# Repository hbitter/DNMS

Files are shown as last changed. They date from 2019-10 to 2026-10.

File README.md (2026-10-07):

## [English text below](#dnms-digital-noise-measurement-sensor-english)

## DNMS (Digital Noise Measurement Sensor)

Ein Sensor-Modul zur Schallpegelmessung. Es wird neben dem LAeq-Wert über einem Zeitintervall auch der min. und max. LA-Wert in diesem Zeitintervall festgehalten. Das zentrale Element des DNMS ist ein digitales MEMS-Mikrofon (InvenSense ICS-43434). Ein Mikrocontroller-Board (Teensy3.6 / Teensy4.0) übernimmt die digitalen Daten vom Mikrofon über die I²S Schnittstelle als  24-Bit, 44,1 kHz PCM Daten (ab Firmware Version 2 - zuvor nur 16-Bit).  Die Audiodaten werden über einen digitalen A-Filter bewertet, dann wird der Effektivwert bestimmt und daraus der Schalldruckpegel entsprechend der Mikrofonsensitivität berechnet. Die einzelnen Schalldruckpegelwerte werden zu einem fortlaufenden LAeq-Wert weitergerechnet. Ebenso werden der max. und min. Schalldruckpegel (LAmax, LAmin) aus dem Intervall abgespeichert.

Die Werte werden dann über eine I²C-Schnittstelle an einen abfragenden Mikrocontroller zur Weiterverarbeitung übertragen. Das Abfrage-Intervall kann 1 Sekunde betragen oder auch bis zu 3600 Sekunden.

Eine Version mit der Möglichkeit das Frequenzspektrum zu betrachten ist seit einiger Zeit verfügbar. Terzwerte von 20Hz - 20000Hz können ausgegeben werden. Terzwerte werden z.Zt. nicht von Sensor.Community unterstützt, deshalb gibt es spezielle Versionen der NodeMCU Firmware um Terzwerte auf der lokalen Webseite der NodeMCU auszugeben und an weitere APIs wie z.B. zu einer InfluxDB zu senden.

Mit der Firmware Version 5 für Teensy4.0 werden nun auch Z-Werte (LZeq, LZmin, LZmax sowie Z-Terzwerte) unterstützt.

### Bei der Firma Watterott electronic GmbH kann nun das Mikrofon IM72D128 von Infineon fertig in einem Kunststoffrohr eingegossen im Shop bestellt werden (https://shop.watterott.com/Mikrofon-IM72D128V01-im-127mm-Rundrohr). Das IM72D128 Mikrofon auf einer Platine und mit Anschlusskabel aber nicht  im Kunststoffrohr eingegossen ist ebenfalls verfügbar (https://shop.watterott.com/Mikrofon-IM72D128V01-Platine-mit-Anschlussleitung).
 
## Neuigkeiten

### Oktober 2026

- Neue Teensy4.0 Firmware DNMS_V6.0.x für IM72D128 und ICS-43434 Mikrofone.   
 	+ Komplettes Refactoring der Firmware mit Optimierung der Verwendung von Double (nur noch wenn absolut notwendig), dadurch erfordert die Berechnung der Leq Werte deutlich weniger Ressourcen.
 	+  Fehlerbeseitigung einer Race-Condition zwischen 1. und 2. Messintervall.
 	+  Die Parameterwerte zur Frequenzgangkorrektur sind nicht mehr in der Firmware fest abgespeichert. Es werden für jeden Mikrofontyp 31 Korrekturwerte vom Kommunikationsprozessor an die Teensy Firmware beim Start übertragen, daraus berechnet die Teensy Firmware die Korrekturwerte für den gewählten Mikrofontyp für die FFT Bins.
 	+  Änderung der Filterparameter für die I²C Kommunikation zwischen Teensy und Kommunikationsprozessor, dadurch stabilere I²C Übertragung. Beim Kompilieren der Firmware ist es deshalb notwendig die angepasste teensy4_i2c-master Library zu benutzen (zu finden unter Firmware/Teensy/Teensy4.0/).

 	<mark>Achtung: Um diese Firmware zu nutzen, ist die Firmware Version airrohr-DNMS-6.0.0 (oder höher) beim NodeMCU Kommunikationsprozessor oder beim Raspberry Pi  die Version dnms-0.9.27 bzw. dnms-0.9.28 (oder höher) notwendig. Nur diese Versionen haben die Parameter zur Frequenzgangkorrektur abgespeichert und übertragen diese Werte beim Start.<mark>
 	
- Neue NodeMCU Firmware AIRROHR-DNMS-6.0, AIRROHR-DNMS-6.0-en, AIRROHR-DNMS-6.0-fr
	+ Unterstützung der Teensy4.0 Firmware DNMS_V6.0.x mit der wesentlichen Änderung, dass die Frequenzgangkorrekturwerte beim Start von der NodeMCU an die Teensy4.0 Firmware übertragen werden. Ist eine ältere Firmware auf dem Tennsy4.0 Board installiert, so wird dies ebenfalls unterstützt d.h. es ist abwärtskompatibel.
	+ Neue Farbe und neues Logo für den lokalen Webserver:
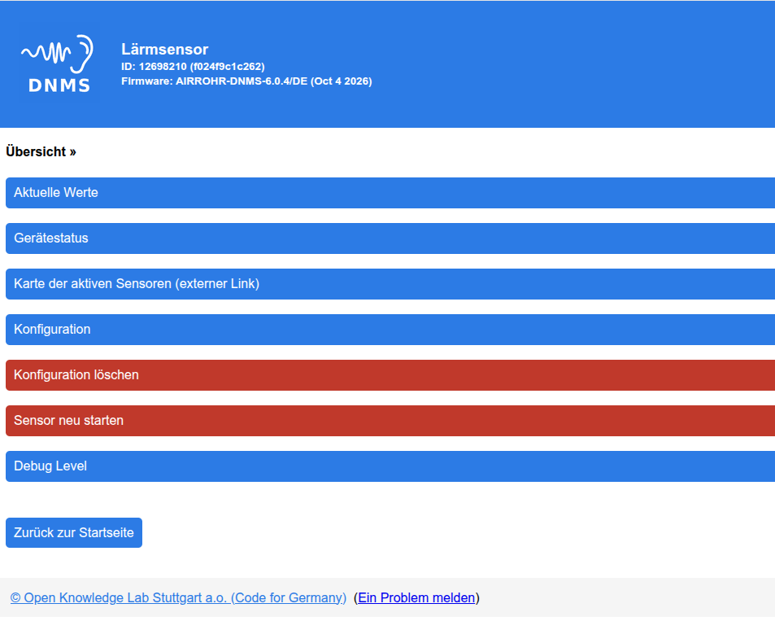
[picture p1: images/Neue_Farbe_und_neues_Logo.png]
	 
	+ Verbessertes Handling der Datenübertragung zu Sensor.Community und zu MQTT-Brokern um Datenverlust bei der Übertragung weiter zu reduzieren.
	
	+  Möglichkeit die NodeMCU Firmware direkt über den Webbrowser auf einen ESP8266  zu flashen. Dies ist möglich mit allen Webbrowsern, die das Web Serial API unterstützen (Chrome, Edge, Brave, Opera aber nicht Firefox ). Um die Funktion zu benutzen,  den entsprechenden Link aufrufen abhängig von der gewünschten Sprachversion:	
		+ Webflasher Deutsche Firmware: https://hbitter.github.io/DNMS/flash-de.html
		+ Webflasher Englische Firmware: https://hbitter.github.io/DNMS/flash-en.html
		+ Webflasher Französische Firmware: https://hbitter.github.io/DNMS/flash-fr.html

- Raspberry Pi Firmware Versionen dnms-0.9.27 und dnms-0.9.28
	+ Die Version dnms-0.9.28 enthält  im Unterschied zur Version dnms-0.9.27 einen lokalen Webserver, der Sztatus Informationen anzeigt und über den die Konfiguration des Sensors angesehen und geändert werden kann. Weiterhin bietet die Version dnms-0.9.28 ein HTTP API (POST) für die Daten des 1. Messintervalls.
	+ Unterstützung der Teensy4.0 Firmware DNMS_V6.0.x mit der wesentlichen Änderung, dass die Frequenzgangkorrekturwerte beim Start vom Raspberry Pi  an die Teensy4.0 Firmware übertragen werden. Ist eine ältere Firmware auf dem Tennsy4.0 Board installiert, so wird dies ebenfalls unterstützt d.h. es ist abwärtskompatibel.
	+ Lokaler Webserver der Version dnms-0.9.28 mit Farbe und Logo entsprechend der NodeMCU Version.
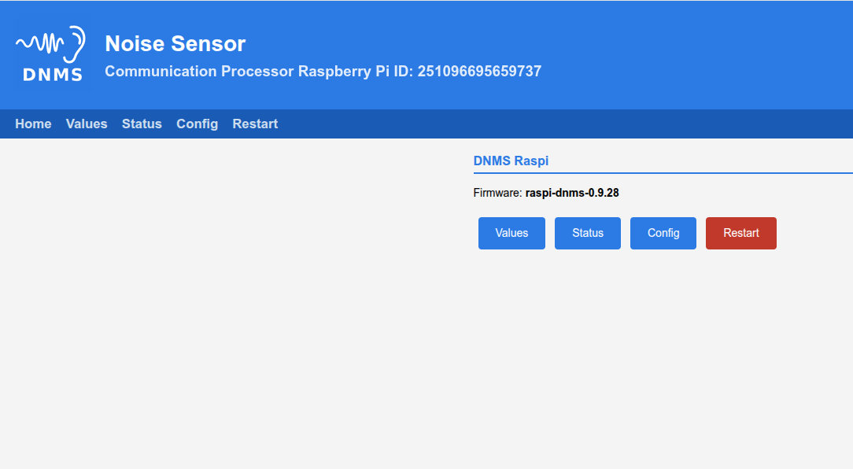
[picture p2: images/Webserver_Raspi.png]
	 

### Mai 2026

- Neues Teensy 4.0 Board DNMS-T4.0-V1.8S mit Layout für SMD Bestückung , so dass nicht nur die Herstellung der Platine beauftragt werden kann sondern direkt die Bestückung bei Firmen wie Aisler, EuroCircuits, JLCPCB oder PCBWay und weiteren. Das Einlöten des Teensy Boards sollte aus Kosten- und Logistikgründen allerdings weiterhin selbst erfolgen. Zwei Bauteilelisten sind als Beispiel für die Bestellung fertig bestückter Boards beigefügt. Dies ist jedoch immer den aktuell lieferbaren Bauelementen anzupassen. Das Layout basiert auf der EasyEDA Vorlage von Ralf Bötticher (vielen Dank!). Weiterhin gibt es zwei Änderungen im Layout:
	+ Verzicht der Brücke J1,  die Brücke war zur Stromversorgung für das standalone Flashen des Boards. Eine Auftrennung der Verbindung VIN - VUSB auf dem Teensy 4.0 Board ist nicht mehr notwendig.
	+ Einfügung einer Sicherung F1 in die 5V Versorgungsleitung der extended I²C Verbindung d.h. zwischen Kommunikationsprozessor und Teensy 4.0 Board.

 - Neue Raspberry Pi Firmware dnms-0.9.25 mit folgenden Verbesserungen:
	+ Möglichkeit C-Werte abzufragen und weiterzugeben, dazu ist die Teensy 4.0 Version DNMS_V5.9.x Voraussetzung. Abhängig von der Menge der übertragenen Daten zwischen Teensy und Raspberry Pi  wird empfohlen die I²C Übertragungsrate von 100 kHz auf 200 kHz zu erhöhen (`dtparam=i2c_arm=on,i2c_arm_baudrate=20000` in der Datei `/boot/firmware/config.txt`).
	+ In der Konfigurationsdatei dnms.conf können nun wieder die Bool Werte mit true und false angegeben werden.

- Neue Teensy 4.0 Firmware DNMS_V5.9.x  für IM72D128 und ICS-43434 Mikrofone mit dem Unterschied zur Version DNMS_V5.8.x, dass zusätzlich C-Werte berechnet und abgerufen werden können. Wenn keine C-Werte benötigt werden, ist die Version  DNMS_V5.8.x weiterhin aktuell. Eine Version mit Abfrage der C-Werte ist die Raspberry Pi Version dnms-0.9.25. Eine Abfrage der C-Werte für die NodeMCU Firmware ist z.Zt. nicht geplant.

- Neue NodeMCU Firmware AIRROHR-DNMS-5.17, AIRROHR-DNMS-5.17-en, AIRROHR-DNMS-5.17-fr
	+ Neue Konfigurationsmöglichkeit für verschiedene Mikrofone und Frequenzgangkorrekturen der Mikrofone. Eine Teensy4.0 Version ab DNMS_V5.8.x ist Voraussetzung um dies zu nutzen.
	+ Konfiguration eines digitalen Eingangs an der der NodeMCU. Der Zustand wird mit der Bezeichnung  DIN01 zur InfluxDB übertragen.
	+ Kleine Korrekturen im Source Code, so dass in der Arduino IDE Version 2.3.8 die Übersetzung ohne Warnungen erfolgt.

- Neue Teensy 4.0 Firmware DNMS_V5.8.x  für IM72D128 und ICS-43434 Mikrofone mit:
	+ zusätzlicher Auswahl der Frequenzgangkorrektur für das DLR Gehäuse mit IM72D128 Mikrofon, sowie Auswahl ohne Frequenzgangkorrektur für IM72D128 und ICS-43434 Mikrofon.
	+ Kleine Korrekturen im Source Code, so dass in der Arduino IDE Version 2.3.8 die Übersetzung ohne Warnungen erfolgt. Dies betrifft auch die Library dnms_audio_lib-master.zip, deshalb beim Übersetzen die veränderte Library einbinden.
	+ Korrekturen an der I²C Übertragung, Änderung der Werte für die Glitch Filter von SDA und SCL im Slave Modus. Diese Korrekturen befinden sich in der Library  teensy4_i2c-master.zip, deshalb beim Übersetzen die veränderte Library einbinden.

### Mai 2025

- Neues Testprogramm für Teensy4.0 Board und angeschlossenem Mikrofon ICS-43434:  DNMS_Vt.8.4 und für Mikrofon IM72D128: DNMS_Vt.8.6, mit verbesserter Frequenzgangkorrektur

- Neue Teensy 4.0 Firmware DNMS_V5.5.x  für IM72D128 und ICS-43434 Mikrofone mit:
	+ Verbesserte Korrektur des Frequenzgangs für IM72D128 Mikrofon und ICS-43434 Mikrofon. Dies verbessert auch die Terzwerte des Spektrums.

 - Neue Raspberry Pi Firmware dnms-0.9.23 ersetzt dnms-0.9.21 aufgrund von Fehlern:
	 + Bei der Umwandlung der MAC-Adresse in die ID
	 + Entfernung Testausgabe der Daten auf Konsole bei Sensor.Community Übertragung
	 + Beseitigung Pufferüberlauf für InfluxDB/MQTT Übertragung, wenn keine Übertragung konfiguriert war

### Oktober 2024

- Neue NodeMCU Firmware AIRROHR-DNMS-5.16 mit:
	+ Neue Konfigurationsmöglichkeit die WLAN Verbindung ohne Passwort auszuwählen aufgrund einer Änderung in der Wifi Lib. Dies ist notwendig  z.B. für Freifunk WLAN Verbindungen.
	+ Verbesserte Fehlerbehandlung bei der Datenübertragung und entsprechende Fehlerausgaben.
	+ Fehlerbeseitigung bei der Übertragung des Zeitstempels zur InfluxDB und zu einem MQTT Broker, wenn der DNMS Sensor nicht konfiguriert ist.

### September 2024

 - Raspberry Pi dnms-0.9.21 ersetzt Version dnms-0.9.20 aufgrund von Fehlern.
 	+ Fehler in der dnms.conf beim Eintrag 'mqtt_transmit'.
 	+ Fehlerhaft gesetzte Prioritäten für die Threads in der dnms.conf ('prio_1st_timer', ... usw).
 	+ Neben der InfluxDB HTTP Übertragung kann nun parallel eine Übertragung der Werte zu einem MQTT Broker erfolgen.
 		
 - Raspberry Pi dnms-0.9.20 Version mit folgenden neuen Funktionen:
	+ Data Logging der Messwerte auf der SD-Karte des Raspberry Pi
	+ Externer Start und Stop der Messwertübertragung, Ausgabe und Speicherung mittels einer named pipe
	+ Änderung der Eingabe von Bool-Werten in der Konfigurationsdatei dnms.conf: Für false eine '0' und für true eine '1' eingeben.

 - Möglichkeit die NodeMCU Firmware direkt über den Webbrowser auf einen ESP8266  zu flashen. Dies ist möglich mit allen Webbrowsern, die das Web Serial API unterstützen (Chrome, Edge, Brave, Opera aber nicht Firefox ). Um die Funktion zu benutzen,  den entsprechenden Link aufrufen abhängig von der gewünschten Sprachversion:
	+ Deutsche Firmware: https://hbitter.github.io/DNMS/flash-de.html
	+ Englische Firmware: https://hbitter.github.io/DNMS/flash-en.html
	+ Französische Firmware: https://hbitter.github.io/DNMS/flash-fr.html

### Juli 2024

- Neue Firmware für Teensy4.0 DNMS_V5.4.x - für ICS-43434 und IM72D128 Mikrofon
	+ Ersetzt DNMS_V5.3.x da in der Version DNMS_V5.3.x Fehler in der Berechnung der Terzwerte waren. DNMS_V5.3.x bitte ersetzen mit DNMS_V5.4.x 
	
- Neue NodeMCU Firmware AIRROHR-DNMS-5.12 mit:
	+ NTP Server können nun in der Konfiguration gesetzt werden unter "Weitere Einstellungen"
	+ Konfigurationsänderung für die Übertragung zum MQTT Broker, eigenes Feld für die Konfiguration der MQTT Messung. Dies wird im InfluxDB Line Protocol als Measurement weitergegeben

 - Raspberry Pi dnms-0.9.18 Fehlerkorrektur und neue Funktion:
	 - Korrektur eines Fehlers: Wenn nur die Ausgabe auf dem Terminal konfiguriert war, wurden die Werte nicht richtig auf dem Terminal ausgegeben.
 	- Neue Möglichkeit der Weitergabe von Messwerten mittels einer named pipe (oder auch fifo) zu anderen Anwendungen auf dem Raspberry Pi.

### Juni 2024

 - Raspberry Pi dnms-0.9.16 Korrektur der Versionsnummer:
	 - Die Versionsnummer wurde falsch (0.9.15 statt 0.9.16) angezeigt
 - Neue NodeMCU Firmware AIRROHR-DNMS-5.8 mit:
	 - MQTT Übertragung (z.Zt. kein TLS)
	 - Unterstützung der neuen Teensy4.0 Firmware DNMS_V5.3.x (Mikrofone ICS-43434 und IM72D128 in einer Teensy4 Firmware)
	 - Möglichkeit nach Restart mit den Messungen zur vollen Minute oder zur vollen Stunde zu beginnen<br>
	 
	 Weitere Details dazu im README.md unter Firmware/NodeMCU.

 - Erweiterte Raspberry Pi Anwendung dnms-0.9.16 mit:
	 - MQTT Übertragung zu einem MQTT-Broker (z.Zt. kein TLS)
	 - Unterstützung der neuen Teensy4.0 Firmware DNMS_V5.3.x (Mikrofone ICS-43434 und IM72D128 in einer Teensy4 Firmware)
	 - Einführung eines DNMS Korrekturwertes für die Lärmwerte (nicht für Frequenzspektren) entsprechend der NodeMCU Firmware  <br>
	 
	 Weitere Details dazu im README.md unter Firmware/Raspberry Pi.
	 
 - Neue Teensy4.0 Firmware DNMS_V5.3.x mit:
	 - Zusammenführung der bisher getrennten Versionen für die beiden Mikrofone ICS-43434 und IM72D128 in einer Teensy4.0 Firmware. Die Auswahl des Mikrofons erfolgt über die Konfiguration in der NodeMCU bzw. im Raspberry Pi und wird mittels Umschaltbefehl an die Teensy4.0 Firmware übertragen. Wird kein Umschaltbefehl übertragen ist als standardmäßig das ICS-43434 ausgewählt d.h. auch ältere NodeMCU Firmware unterstützt die Version DNMS_V5.3.x mit ICS-43434 Mikrofon. <br>

	 Weitere Details dazu im README.md unter Firmware/Teensy4.0/V5.	 

### April 2024
 - Neue NodeMCU Firmware NRZ-2020-134-DNMS-5.6 mit:
	 - Fehlerbeseitigung für DNMS Korrekturwert (Issue #54)
	 - LED Statusanzeige
	 - geänderte Speicheraufteilung<br>
	 
	 Weitere Details dazu im README.md unter Firmware/NodeMCU.

### Februar 2024
   - Verbesserte Teensy4.0 Firmware für die Mikrofone ICS-43434 und IM72D128 mit verbessertem internen Zeitverhalten (Upgrade empfohlen): 
     - DNMS_V5.2.4 - für ICS43434 mit Teensy4.0
     - DNMS_V5.2.6 - für IM72D128 mit Teensy4.0
 	
  - Standalone Testprogramme für Teensy4.0 und die Mikrofone ICS-43434 und IM72D128 mit verbessertem internen Zeitverhalten	und geänderter Ein- und Ausgabe beim Start, es können Messintervall ab 125ms eingestellt werden, die Ausgabe von Terzwerten ist ab 500ms möglich:
 	- DNMS_Vt.7.4 - für ICS43434 mit Teensy4.0
 	- DNMS_Vt.7.6 - für IM72D128 mit Teensy4.0
  
  - dnms-0.9.12 erste Version der Raspberry Pi Anwendung um den DNMS Sensor auszulesen und Daten an Sensor.Community und/oder zu einer InfluxDB zu senden als Alternative zu einer NodeMCU (Airrohr-Board). Die Raspberry Pi Anwenung unterstützt zur Übertragung an eine InfluxDB zwei zeitlich unterschiedliche Messintervalle mit unterschiedlich konfigurierbaren Messwerten. Die Messwerte des 2. Messintervalls werden erst ab der Überschreitung eines Schwellwertes (LAeq) übertragen.  
  - KiCad Layouts an KiCad Version 7 angepasst für die folgenden PCBs (im Layout selbst keine Änderung):
	  + DNMS-T4.0-V1.7
	  + DNMS-RPI-HAT-V1.0
	  + IM72D128-PCB-V1.0
	  + IM72D128-Tube-PCB-V1.0

### September 2023
  - Neue NodeMCU Firmware NRZ-2020-134-DNMS-5.4 auch in englischer und französischer Version mit:
    - Verbesserungen bei der Fehlerausgabe von Übertragungen zu Sensor.Community und zu einer InfluxDB
    - Vergrößerung des Übertagungspuffers, so dass neben sämtlichen DNMS Werten auch die Werte weiterer Sensoren zu einer InfluxDB übertragen werden können.
    - Link zur Meldung von Problemen geändert auf https://github.com/hbitter/DNMS/issues 

### August 2023
 - Standalone Testprogramme für Teensy4.0 und die Mikrofone ICS-43434 und IM72D128:
 	- DNMS_Vt.5.4 - für ICS43434 mit Teensy4.0
 	- DNMS_Vt.5.6 - für IM72D128 mit Teensy4.0
 
 	Diese Testprogramme basieren auf der Teensy4.0 Firmware Version 5. Neben einem einfachen Test, ob Mikrofon und Teensy4.0 funktionieren, können die Messwerte mittels einem geeigneten  Terminalprogramm auch aufgezeichnet und weiter ausgewertet werden. Das Messintervall kann eingegeben werden.
 	
 - Airrohr-ESP32-PCB-V1.1 PCB gelöscht - obsolet, da keine Firmware Unterstützung.	
 
### Juli 2023
 - Unterstützung des Mikrofons IM72D128 von Infineon. Das IM72D128 bietet zwei wesentliche Vorteile:
   - IP57 Schutz gegen Staub und Feuchtigkeit im Mikrofon integriert (trotzdem ist ein zusätzlicher Wind-/Wetterschutz sinnvoll).
   - hoher Signal to noise ratio (SNR) von 72 dB(A), dadurch wird ein unterer Messbereich von ca. 23 dB(A) erreicht.

  - PCBs für das IM72D128 Mikrofon. Ein rundes Mikrofon Board und ein längliches Board mit einer Schaltung zur Umsetzung der PDM Schnittstelle des Mikrofons auf die I²S Schnittstelle, dadurch ist die Anschlusskompatibilität zum bisherigen ICS-43434 Mikrofon gegeben.

 - Teensy4.0 Firmware V5, die zusätzlich die Berechnung und Ausgabe von Z-Werten unterstützt (LZeq, LZmin, LZmax sowie die LZeq Werte der Terzen von 20Hz - 20.000Hz). Für das bisherige Mikrofon ICS-43434 und das neue Mikrofon IM72D128 gibt es zwei unterschiedliche Versionen:
    - DNMS_V5.0.4 für das bisherige Mikrofon ICS-43434
    - DNMS_V5.0.6 für das neu unterstützte Mikrofon IM72D128
 
 - Neue NodeMCU Firmware Versionen NRZ-2020-134-DNMS-5.2 und NRZ-2020-134-DNMS-5.2-en zur Unterstützung der Z-Werte. Diese Versionen sind auch kompatibel mit allen Teensy Firmware Versionen (V2, V3, V4 und V5) und ersetzen damit die älteren NodeMCU Versionen.
 
   Weitere Details im README.md unter NodeMCU<br><br>

### März 2023

 - Neue NodeMCU Firmware Versionen NRZ-2020-134-DNMS-4.4 und NRZ-2020-134-DNMS-4.4-en (ersetzt auch die Versionen NRZ-2020-134-DNMS-3.3 und NRZ-2020-134-DNMS-3.3-en):
 
   - Instabiles Verhalten des lokalen NodeMCU Webservers beseitigt
   - SDS011 mit dieser Version wieder nutzbar
   - Erweiterte Statusausgaben bei einigen Sensoren (DNMS, SEN5X, SCD30, SCD40)
   - Unterstützung weiterer Sensoren (SEN5X, SCD30, SCD40)

   Weitere Details im README.md unter NodeMCU<br><br>

### Januar 2023
- Fehlerkorrektur Teensy3.6 Firmware, die neuen Versionen DNMS_V2.5.0 und DNMS_V2.5.1 beseitigen eine Fehler bei der Initialisierung.
- Korrektur der NodeMCU Firmware, die neuen Versionen NRZ-2020-134-DNMS-3.3, NRZ-2020-134-DNMS-3.3-en, NRZ-2020-134-DNMS-4.3 und NRZ-2020-134-DNMS-4.3-en korrigieren die I²C Takt Frequenz, jetzt näher bei 100kHz.<br><br>

- Es gibt nun drei aktuelle Versionen der Teensy Firmware, die sich im Funktionsumfang unterscheiden:
	- V2 - Funktionsumfang wie bisher d.h. LAeq, LAmin und LAmax werden berechnet und ausgegeben.
	- V3 (nur für Teensy4.0) - zusätzlich zum Funktionsumfang von V2 werden zur Auswertung des Frequenzspektrums die Terzwerte (A-bewertet) von 20Hz - 20000Hz ausgegeben. Die Terzwerte werden nicht zu Sensor.Community übertragen sondern nur auf die lokale Webseite der NodeMCU und zu weiteren APIs übertragen (z.B. zu einer InfluxDB). Zur Nutzung dieser Teensy Version V3 muss die korrespondierende Firmware Version für die NodeMCU (z.Zt. NRZ-2020-134-DNMS-3.2 bzw. die englische Version NRZ-2020-134-DNMS-3.2/EN) benutzt werden. 
	- V4 (nur für Teensy4.0) - zusätzlich zum Funktionsumfang von V3 wird ein zweites Messintervall unterstützt um z.B. in einem kürzeren Messintervall als das 150 Sekunden Intervall von Sensor.Community Werte zu einer eigenen InfluxDB zu senden. Die Übertragung der Messwerte des 2. Messintervalls kann auch erst ab Überschreitung eines konfigurierbaren Schwellwertes gestartet werden. Zur Nutzung dieser Teensy Version V4 muss die korrespondierende Firmware Version für die NodeMCU (z.Zt. NRZ-2020-134-DNMS-4.2 bzw. die englische Version NRZ-2020-134-DNMS-4.2/EN) benutzt werden.

- Änderung der Zeitbewertung in allen aktuellen Teensy Firmware Versionen von "Impuls" auf "Fast" entsprechend 125ms.  Dies führt zu etwas niedrigeren LAmax und LAeq Werten und zu etwas höheren LAmin Werten aber entspricht besser der gebräuchlichen "Fast" Zeitbewertung.

- Die Teensy Firmware Versionen V2, V3 und V4 sind abwärtskompatibel d.h. ein Teensy4.0 mit einer Firmware V4 kann zusammen mit einer NodeMCU, die nur den Funktionsumfang V2 unterstützt, betrieben werden, es ist dann nur der geringere Funktionsumfang verfügbar. Umgekehrt kann an einer NodeMCU z.B. mit der aktuellen Firmware NRZ-2020-134-DNMS-4.2 auch ein Teensy mit der Firmware Version V2 betrieben werden, es ist dann ebenfalls nur der geringere Funktionsumfang verfügbar.

- Falls Probleme mit der aktuellen Teensy Firmware beim Datentransfer mit der standard NodeMCU Firmware von Sensor.Community auftreten z.B. DNMS wird nicht erkannt, bitte die NodeMCU Firmware NRZ-2020-134-DNMS-3.2 oder NRZ-2020-134-DNMS-4.2 von hier benutzen.

- geänderte PCBs:
	- ICS-43434-PCB-V1.4 - Durchmesser des akustischen Ports von 0,6mm auf 0,7mm geändert
	- DNMS-T4.0-V1.7 - zusätzliche Steckverbinder für die Verbindung zum Mikrofon

- Software um einen Raspberry Pi als Kommunikationsprozessor für DNMS mit Übertragung der Werte zu Sensor.Community und zu einer InfluxDB zu nutzen:
	- dnms-0.9.5 erste Version für Raspi Pi Zero W, Raspi Pi Zero 2 W und andere

----------------------------------------------------------------------------------------------------------------
## DNMS (Digital Noise Measurement Sensor) English

A sensor modul for SPL measurement. Over a period of time the LAeq value is calculated, beside that the minimal and the maximal LA value is covered over the time period. The central element of DNMS is a digital MEMS-Microphone (InvenSense ICS-43434). The digital data is fed from the microphone via a I²S connection as 24-bit, 44,1 kHz PCM data (from firmware version 2 on - before it was only 16-Bit) to a microcontroller board (Teensy3.6 / Teensy4.0). The data is filtered by an A-filter, then the RMS value is calculated. Further the sound pressure level (SPL) is calculated based on microphone sensivity. The SPL values are integrated over time to give the LAeq. Also the maximum level in the measurement period LAmax and the minimum level LAmin will be kept.

All measurements will be transfered to a further microcontroller via I²C bus. The intervall time to pick up measurements can reach from 1 second up to 3600 seconds.

A version with support of frequency spectrum is available for some time. 1/3 octave values from 20Hz - 20000Hz are calculated. 1/3 octave values are not supported by Sensor.Community so far. Therefore a special version of the NodeMCU firmware is available, showing the 1/3 octave values on the local webpage of the NodeMCU as well as transmitting the 1/3 octave values to an InfluxDB.

Firmware version 5 for Teensy4.0 now supports Z-values (LZeq, LZmin, LZmax as well as 1/3 octave Z-values).

### The IM72D128 microphone from Infineon can now be ordered ready-molded in a plastic tube from Watterott electronic GmbH in the shop (https://shop.watterott.com/Mikrofon-IM72D128V01-im-127mm-Rundrohr). The IM72D128 microphone on a circuit board and with a connection cable but not cast in the plastic tube is also available (https://shop.watterott.com/Mikrofon-IM72D128V01-Platine-mit-Anschlussleitung).
 
## News

### October 2026

- New Teensy4.0 firmware DNMS_V6.0.x for IM72D128 and ICS-43434 microphones.   
 	+ Complete refactoring of the firmware, optimising the use of `double` (now only used when absolutely necessary), meaning that the calculation of Leq values requires significantly fewer resources.
 	+  Resolving a race condition between the first and second measurement intervals.
 	+  The parameter values for frequency response correction are no longer hard-coded in the firmware. For each microphone type, 31 correction values are transferred from the communication processor to the Teensy firmware at start-up; the Teensy firmware then uses these to calculate the correction values for the selected microphone type for the FFT bins.
 	+  Changes to the filter parameters for I²C communication between the Teensy and the communication processor, resulting in more stable I²C transmission. When compiling the firmware, it is therefore necessary to use the modified teensy4_i2c-master library (located in Firmware/Teensy/Teensy4.0/).	

 	<mark>Please note: To use this firmware, the NodeMCU communication processor must be running firmware version airrohr-DNMS-6.0.0 (or later), whilst the Raspberry Pi must be running version dnms-0.9.27 or dnms-0.9.28 (or later). Only these versions have the frequency response correction parameters stored and transmit these values on start-up.<mark>

- New NodeMCU firmware AIRROHR-DNMS-6.0, AIRROHR-DNMS-6.0-en, AIRROHR-DNMS-6.0-fr
	+ Support for the Teensy 4.0 firmware DNMS_V6.0.x, with the key change being that the frequency response correction values are transferred from the NodeMCU to the Teensy 4.0 firmware at start-up. If an older version of the firmware is installed on the Teensy 4.0 board, this is also supported; in other words, it is backwards compatible.
	+ A new colour scheme and a new logo for the local web server:
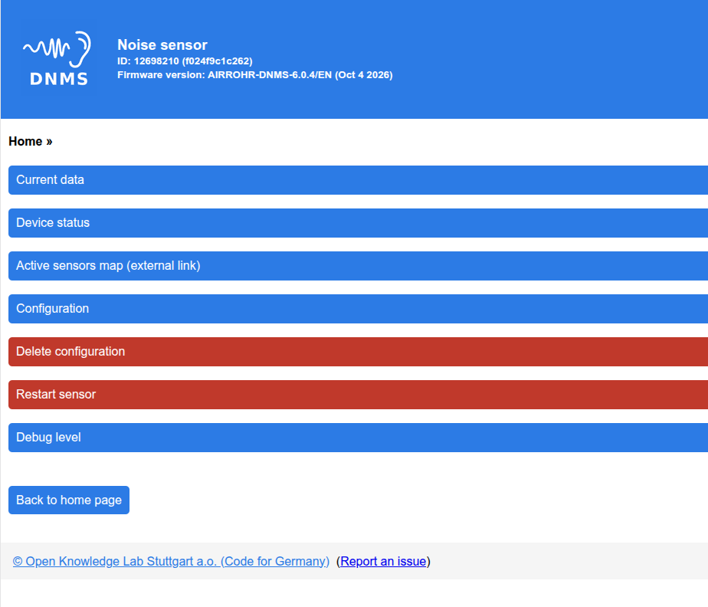
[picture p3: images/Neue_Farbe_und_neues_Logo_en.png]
	 
	+ Improved handling of data transmission to Sensor.Community and to MQTT brokers to further reduce data loss during transmission.
	+ Ability  to flash NodeMCU firmware to an ESP8266 directly from a web browser. This is possible with all web browsers that support the Web Serial API (Chrome, Edge, Brave, Opera but not Firefox). To use this feature, click on the appropriate link for your language version:
		+ German firmware: https://hbitter.github.io/DNMS/flash-de.html
		+ English firmware: https://hbitter.github.io/DNMS/flash-en.html
		+ French firmware: https://hbitter.github.io/DNMS/flash-fr.html

- Raspberry Pi Firmware versions dnms-0.9.27 and dnms-0.9.28
	+ Unlike version dnms-0.9.27, version dnms-0.9.28 includes a local web server which displays status information and allows the sensor’s configuration to be viewed and modified. Furthermore, version dnms-0.9.28 provides an HTTP API (POST) for the data from the first measurement interval.
	+ Support for the Teensy 4.0 firmware DNMS_V6.0.x, with the key change being that the frequency response correction values are transferred from the Raspberry Pi to the Teensy 4.0 firmware at start-up. If an older version of the firmware is installed on the Teensy 4.0 board, this is also supported; in other words, it is backwards compatible.
	+ Local web server, version dnms-0.9.28, with a colour scheme and logo matching the NodeMCU version.
	 

### May 2026

- New Teensy 4.0 board DNMS-T4.0-V1.8S has a layout for SMD assembly. This means that you can commission the manufacture and assembly of the board from companies such as Aisler, EuroCircuits, JLCPCB and PCBWay. However, for cost and logistical reasons, it is recommended that you solder the Teensy board yourself. Two bills of materials (BOMs) are attached as examples for ordering fully assembled boards. These must always be adapted to the currently available components, though. The layout is based on the EasyEDA template by Ralf Bötticher (many thanks!). There are also two changes to the layout:
	+ The J1 jumper has been removed; this jumper was used to supply power for flashing the board in standalone mode. It is no longer necessary to cut the VIN – VUSB connection on the Teensy 4.0 board.
	+ Integration of a fuse F1 in the 5V power supply line of the extended I²C connection, i.e. between the communication processor and the Teensy 4.0 board.

 - New Raspberry Pi firmware dnms-0.9.25 with the following improvements:
	+ Ability to query and transmit C-values; this requires Teensy 4.0 version DNMS_V5.9.x. Depending on the amount of data transferred between the Teensy and the Raspberry Pi, it is recommended to increase the I²C clock from 100 kHz to 200 kHz (set `dtparam=i2c_arm=on,i2c_arm_baudrate=20000` in the file `/boot/firmware/config.txt`).
	+ In the configuration file dnms.conf, the Boolean values can now once again be specified as true and false.

- New Teensy 4.0 firmware DNMS_V5.9.x  for IM72D128 and ICS-43434 microphones; the difference from version DNMS_V5.8.x is that C-values can now also be calculated and retrieved. If C-values are not required, version  DNMS_V5.8.x remains the current version. One version that retrieves C-values is the Raspberry Pi version dnms-0.9.25. There are currently no plans to retrieve C-values for the NodeMCU firmware.

- New NodeMCU firmware AIRROHR-DNMS-5.17, AIRROHR-DNMS-5.17-en, AIRROHR-DNMS-5.17-fr
	+ New configuration options for different microphones and microphone frequency response corrections. A Teensy 4.0 version from DNMS_V5.8.x onwards is required to use this feature.
	+ Configuring a digital input on the NodeMCU. The status is transmitted to InfluxDB under the label DIN01.
	+ Minor corrections to the source code so that the code compiles without warnings in Arduino IDE version 2.3.8.

- New Teensy 4.0 firmware DNMS_V5.8.x for IM72D128 and ICS-43434 microphones, featuring::
	+ Additional selection of frequency response correction for the DLR housing with IM72D128 microphone, as well as a selection without frequency response correction for IM72D128 and ICS-43434 microphones
	+ Minor corrections have been made to the source code so that the code compiles without warnings in Arduino IDE version 2.3.8. This also applies to the dnms_audio_lib-master.zip library, so please include the updated library when compiling.
	+ Corrections to the I²C transmission; changes to the values for the SDA and SCL glitch filters in slave mode. These corrections are contained in the library teensy4_i2c-master.zip, so be sure to include the updated library when compiling.

### May 2025

- New test program for Teensy 4.0 board and connected ICS-43434 microphone: DNMS_Vt.8.4 and
test program for IM72D128 microphone: DNMS_Vt.8.6, both with improved microphone frequency correction

- New Teensy 4.0 firmware DNMS_V5.5.x for IM72D128 and ICS-43434 microphones with:
	+ Improved frequency correction for IM72D128 microphone and ICS-43434 microphone. It also improves the 1/2 octave values of the spectrum

 - New Raspberry Pi firmware dnms-0.9.23 replaces version dnms-0.9.21 due to bugs:
	 + MAC address to ID conversion was incorrect in some circumstances
	 + Removal of test output on console for transmission to Sensor.Community
	 + Fix for buffer overflow on InfluxDB/MQTT transfers when one transfer is configured

### October 2024

- New NodeMCU firmware AIRROHR-DNMS-5.16 with:
	+ New configuration option to select the WLAN connection without a password due to a change in the Wifi Lib. This is necessary, for example, for Freifunk WLAN connections.
	+ Improved error handling during data transfer and corresponding error output.
	+ Bug fix when transferring the timestamp to InfluxDB and an MQTT broker when the DNMS sensor is not configured.

### September 2024

 - Raspberry Pi dnms-0.9.21 replaces version dnms-0.9.20 due to bugs.
 	+ Error in dnms.conf with entry 'mqtt_transmit'.
 	+ Incorrectly set priorities for the threads in dnms.conf ('prio_1st_timer', ... etc).
 	+ In addition to the InfluxDB HTTP transfer, the values can now be transferred to an MQTT broker in parallel.

 - Raspberry Pi dnms-0.9.20 release with the following new features:
	+ Data logging of measurements to Raspberry Pi SD card
	+ External start and stop of transmission of measurements, output and storage using a named pipe
	+ Changed entry of bool values in the dnms.conf configuration file: Enter '0' for false and '1' for true.

- Ability to flash NodeMCU firmware to an ESP8266 directly from a web browser. This is possible with all web browsers that support the Web Serial API (Chrome, Edge, Brave, Opera but not Firefox). To use this feature, click on the appropriate link for your language version:
	+ German firmware: https://hbitter.github.io/DNMS/flash-de.html
	+ English firmware: https://hbitter.github.io/DNMS/flash-en.html
	+ French firmware: https://hbitter.github.io/DNMS/flash-fr.html

### July 2024

- New NodeMCU firmware AIRROHR-DNMS-5.12 with:
	+ NTP servers can now be set in the configuration under "More settings".
	+ Configuration change for MQTT Broker transmission, separate field for configuring the MQTT measurement. This will be reported as measurement in the InfluxDB line protocol.

- New firmware for Teensy4.0 DNMS_V5.4.x - for ICS-43434 and IM72D128 microphone
	+ Replaces DNMS_V5.3.x because of an error in the calculation of the 1/3 octave values in DNMS_V5.3.x. Please replace DNMS_V5.3.x with DNMS_V5.4.x.
	
- Raspberry Pi dnms-0.9.18  bug fix and new feature:
	 - Bug fix: If only output to terminal was configured, the values were not output correctly to the terminal.
  	- New way to pass measurements to other applications on the Raspberry Pi using a named pipe (or fifo).

### June 2024

 - Raspberry Pi dnms-0.9.16 Fix for version number output:
	 - Version number was displayed as 0.9.15 instead of 0.9.16
 - New NodeMCU firmware AIRROHR-DNMS-5.8 with:
	 - MQTT transmission (currently no TLS)
	 - Support of new Teensy4.0 firmware DNMS_V5.3.x (microphones ICS-43434 and IM72D128 supported in one single Teensy4.0 firmware)
	 - Possibility to start at full minute or full hour after restart<br>
	 
	 See README.md under Firmware/NodeMCU for details.

 - Enhanced Raspberry Pi application dnms-0.9.16 with:
	 - MQTT transmission (currently no TLS)
	 - Support of new Teensy4.0 firmware DNMS_V5.3.x (microphones ICS-43434 and IM72D128 supported in one single Teensy4.0 firmware)
	 - Implementation of DNMS correction for noise values (not for 1/3 octave values) according to the NodeMCU firmware  <br>
	 
	See README.md under Firmware/Raspberry Pi for details.
	 
 - New Teensy4.0 firmware DNMS_V5.3.x with:
	 - Merging the previously separate versions for the two microphones ICS-43434 and IM72D128 in one Teensy4.0 firmware. The microphone is selected via the configuration in the NodeMCU or Raspberry Pi and is transferred to the Teensy4.0 firmware using a switching command. If no switching command is transmitted, the ICS-43434 is selected as default, i.e. older NodeMCU firmware also supports version DNMS_V5.3.x with ICS-43434 microphone. <br>

	 See README.md under Firmware/Teensy4.0/V5 for details.

### April 2024
 - New NodeMCU firmware NRZ-2020-134-DNMS-5.6 with:
	 - DNMS correction value bug fix (issue #54)
	 - LED status display
	 - modified memory organisation<br>
	 
	See README.md under Firmware/NodeMCU for details.

### February 2024
- Improved Teensy 4.0 firmware for ICS-43434 and IM72D128 microphones with improved internal timing (upgrade recommended):
     - DNMS_V5.2.4 - for ICS43434 with Teensy4.0
     - DNMS_V5.2.6 - for IM72D128 with Teensy4.0
 	
- Standalone testprograms for Teensy4.0 and microphones ICS-43434 and IM72D128 with improved internal timing and changed input and output at startup, measuring interval can be set from 125ms upwards, output of 1/3 octave values is possible from 500ms upwards:
 	- DNMS_Vt.7.4 - for ICS43434 with Teensy4.0
 	- DNMS_Vt.7.6 - for IM72D128 with Teensy4.0
  
- dnms-0.9.12 First version of the Raspberry Pi application to read out the DNMS sensor and send data to Sensor.Community and/or an InfluxDB as an alternative to a NodeMCU (Airrohr board). The Raspberry Pi application supports two different measurement intervals with different configurable measurement values for sending to an InfluxDB. The values of the 2nd measurement interval are only transmitted when a limit value (LAeq) is exceeded.
- KiCad layouts adapted to KiCad version 7 for the following PCBs (no change to the layout itself):

  + DNMS-T4.0-V1.7
  + DNMS-RPI-HAT-V1.0
  + IM72D128-PCB-V1.0
  + IM72D128-Tube-PCB-V1.0

### September 2023
- New NodeMCU firmware NRZ-2020-134-DNMS-5.4, also available as English and French version:
    - Improved output of transmission errors for communication with Sensor.Community and an InfluxDB.
    - Larger buffer for transmissions, so in addition to transmitting all DNMS readings, you can also transmit readings from other sensors.
    - Changed issue reporting link to https://github.com/hbitter/DNMS/issues

### August 2023
 - Standalone test programs for Teensy4.0 and microphones ICS-43434 and IM72D128:
 	- DNMS_Vt.5.4 - for ICS43434 and Teensy4.0
 	- DNMS_Vt.5.6 - for IM72D128 and Teensy4.0
 
	These test programs are based on Teensy4.0 firmware version 5. In addition to a simple test to see if the microphone and Teensy4.0 are working, a suitable terminal program can be used to store the measured values for future use. It is possible to input the measurement interval.
 	
 - Airrohr-ESP32-PCB-V1.1 PCB deleted - obsolete, because no firmware support.	

### July 2023
- Support of IM72D128 microphone from Infineon. IM72D128 microphone does have two significant advantages:
   - IP57 water and dust resistant on component level (however a good windshield is recommended).

   - Signal to noise ratio of 72 dB(A) SNR, this lowers the measurement range down to about 23 dB(A)

   - PCBs for IM72D128 microphone. A round PCB for the microphone itself and a longish PCB for the additional circuitry to convert the PDM interface of the IM72D128 to I²S. Therfore it is compatible to the I²S interface of the ICS-43434 used up to now.

 - Teensy4.0 firmware V5, which does now in addition calculation and output of Z-values (LZeq, LZmin, LZmax as well as LZeq values of 1/3 octaves from 20Hz - 20.000Hz). For the ICS-43434 microphone and the newly supported IMD128 microphone there are two different firmware versions:
    - DNMS_V5.0.4 for the ICS-43434 microphone
    - DNMS_V5.0.6 for the IM72D128 microphone
 
 - New NodeMCU firmware versions NRZ-2020-134-DNMS-5.2 and NRZ-2020-134-DNMS-5.2-en supporting Z-values. These versions are compatible with all Teensy firmware versions (V2, V3, V4 and V5) and replaces the older NodeMCU firmware versions.
 
   README.md under NodeMCU gives more details<br><br>

### March 2023

 - New NodeMCU firmware versions NRZ-2020-134-DNMS-4.4 and NRZ-2020-134-DNMS-4.4-en (replaces as well versions NRZ-2020-134-DNMS-3.3 and NRZ-2020-134-DNMS-3.3-en):
 
   - Instabilities of local NodeMCU webserver settled
   - SDS011 can be used again with this versions
   - Extended status output of some sensors (DNMS, SEN5X, SCD30, SCD40)
   - Support of further sensors (SEN5X, SCD30, SCD40)

 	README.md under NodeMCU gives more details
   <br><br>

### January 2023

- Correction of a bug in Teensy3.6 firmware, the new versions DNMS_V2.5.0 and DNMS_V2.5.1 correcting a wrong initialization at startup.
- Correction of NodeMCU firmware, the new versions NRZ-2020-134-DNMS-3.3, NRZ-2020-134-DNMS-3.3-en, NRZ-2020-134-DNMS-4.3 and NRZ-2020-134-DNMS-4.3-en correcting the I²C clock frequency, it is now closer to 100kHz.<br><br>

- There are now three different versions of the Teensy firmware, which differ in functionality:
	- V2 - with the functionality as up to now e.g. calculation of LAeq, LAmin and LAmax
	- V3 (only for Teensy4.0) - in addition to V2 supports frequency spectrum and calculates 1/3 octave values from 20Hz - 20000Hz. 1/3 octave values are not transmitted to Sensor.Community. They are available on the local webpage of the NodeMCU and can be transmitted to an InfluxDB. To use these features of Teensy V3 version a corresponding firmware version for the NodeMCU has to be used (at the moment that is NRZ-2020-134-DNMS-3.2 or the english version NRZ-2020-134-DNMS-3.2/EN).
	- V4 (only for Teensy4.0) - in addition to V3 functionality a 2nd measurement interval is realized. The 2nd measurement interval is independent from the 1st measurement interval and can be anything from one second on. The values from the 2nd measurement interval are not transmitted to Sensor.Community but to other APIs as e.g. an InfluxDB. A threshold can be configured. Exceeding the threshold will start transmission of values from the 2nd measurement for a configurable amount of time to an InfluxDB. To use these features of Teensy V4 version a corresponding firmware version for the NodeMCU has to be used (at the moment that is NRZ-2020-134-DNMS-4.2 or the english version NRZ-2020-134-DNMS-4.2/EN).

- Change of time weighting in all current Teensy firmware versions from  I (Impuls) to F (Fast - 125ms). This will result in a bit lower LAmax and LAeq values and a bit higher LAmin values. It compares better to the standard F (Fast) time weighting.

- Teensy firmware versions V2, V3 and V4 are downward compatible i.e. Tennsy4.0 with firmware V4 can operate together with a NodeMCU running a firmware supporting only functionality V2, only functionality from V2 is available then. The other way round is possible as well. NodeMCU with e.g. firmware NRZ-2020-134-DNMS-4.2 can operate together with a Teensy running firmware V2. Only functionality from V2 this supported then.

- If there are communication problems between Teensy and standard NodeMCU firmware from Sensor.Community, please use the current NodeMCU firmware (e.g. NRZ-2020-134-DNMS-3.2 or NRZ-2020-134-DNMS-4.2) from this site.

- changed PCBs:
	- ICS-43434-PCB-V1.4 - diameter of acoustic port changed from 0,6mm to 0,7mm
	
	- DNMS-T4.0-V1.7 - additional connectors for microphone connection
	
- Software for using a Raspberry Pi as communication processor to transmit DNMS data to Sensor.Community and/or to an InfluxDB:
	- 1st version dnms-0.9.5 for Raspi Pi Zero W, Raspi Pi Zero 2 W and others

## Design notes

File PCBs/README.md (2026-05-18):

## [English text below](#pcbs-english)

## PCBs

## Funktion der verschiedenen PCBs

### IM72D128 Mikrofon PCBs
Das IM72D128 Mikrofon benötigt zwei PCBs: Ein rundes Mikrofon Board, auf dem neben dem IM72D128 noch ein Widerstand und ein Kondensator montiert sind. Ein zweites längliches Board, dass in ein 1/2" Rohr zusammen mit dem Mikrofon eingebaut (eingegossen) wird, ist für die Umsetzung der PDM Schnittstelle des Mikrofons auf die I²S Schnittstelle des DNMS Teensy4.0 Boards notwendig. Dadurch wird die Anschlusskompatibilität zum ICS-43434 bewahrt.
PCB Versions Historie:
- IM72D128-PCB-V1.0 - erste veröffentlichte Version rundes Mikrofon Board
- IM72D128-Tube-PCB-V1.0 - erste veröffentlichte Version längliches Interface Board

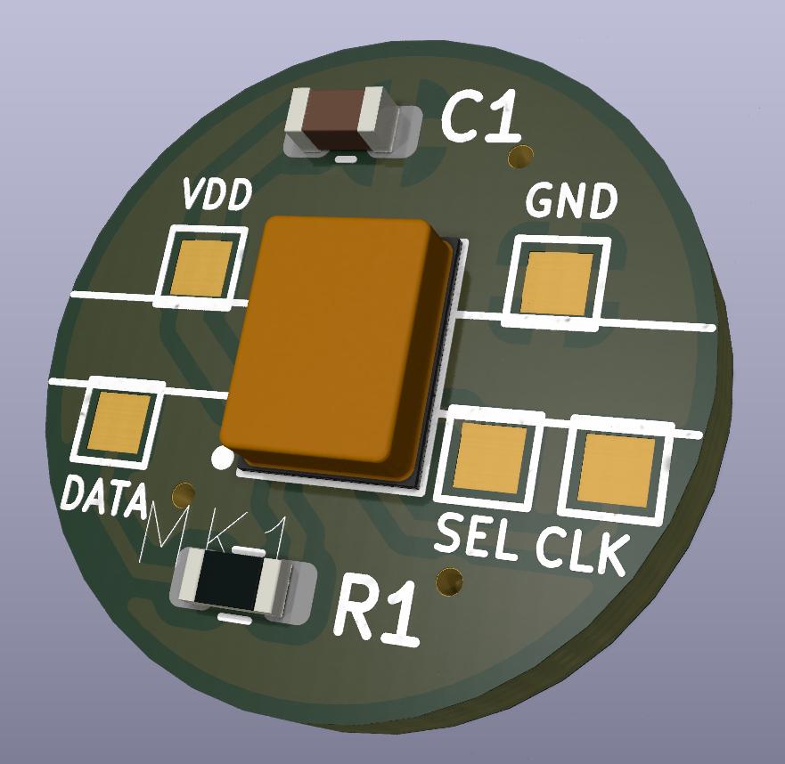
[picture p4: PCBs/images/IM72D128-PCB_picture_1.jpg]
<br>
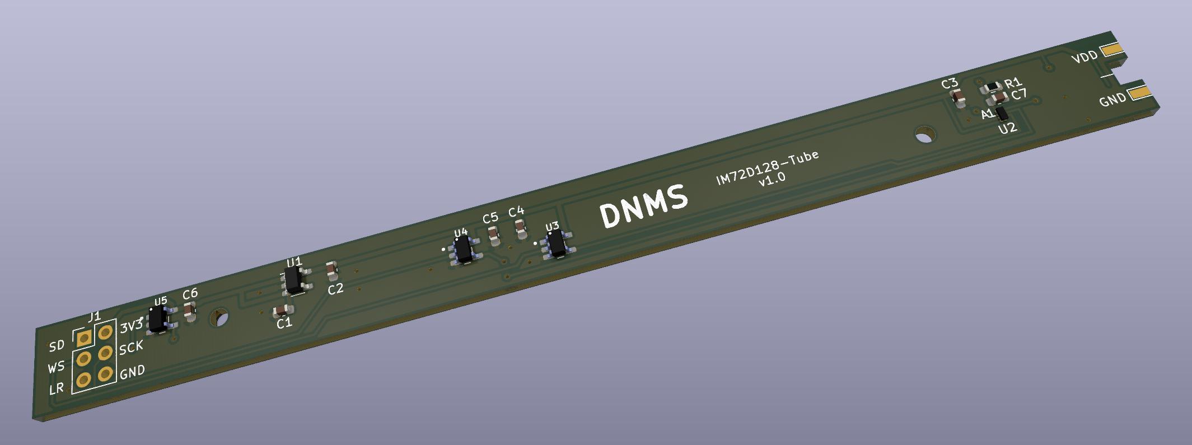
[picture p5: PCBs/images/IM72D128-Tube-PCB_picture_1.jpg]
<br>

### ICS-43434 Mikrofon PCB
Ein rundes Mikrofon Board, das in ein 1/2" Plastikrohr (oder in 13mm Edelstahlrohr mit 12mm Innendurchmesser) eingebaut werden kann. Auf dem Board ist eine JST SH Buchse, auf die ein Kabel mit JST SH Stecker aufgesteckt werden kann. Entsprechende Kabel sind z.B. bei [Aliexpress hier erhältlich](https://de.aliexpress.com/item/33013143346.html?spm=a2g0s.9042311.0.0.b4924c4dbhEWkt).

PCB Versions Historie:
- ICS-43434-PCB-V1.3 - erste veröffentlichte Version
- ICS-43434-PCB-V1.4 - Durchmesser für die akustische Öffnung geändert con 0,6mm auf 0,7mm

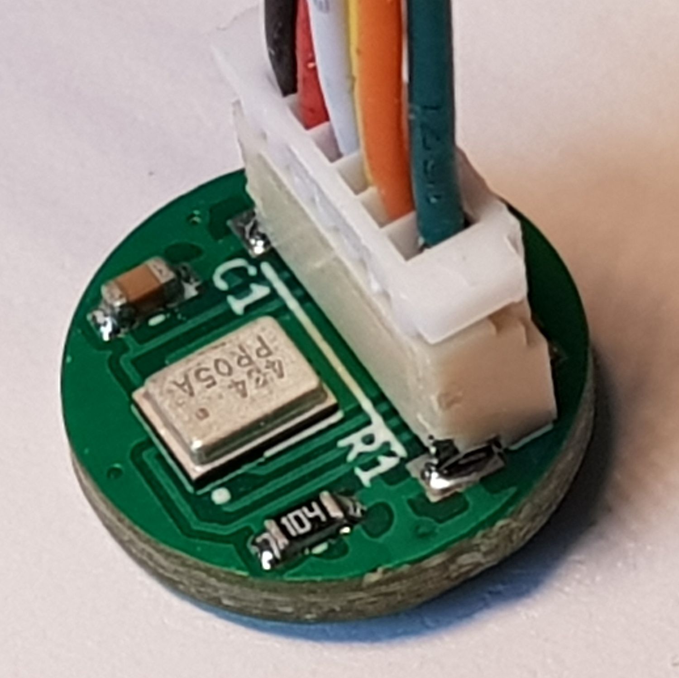
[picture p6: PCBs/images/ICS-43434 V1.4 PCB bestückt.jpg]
<br>

### Airrohr PCB
Basis Board für eine NodeMCU V2 od. V3 mit Anschlüssen für die folgenden Sensoren:
- Feinstaubsensor SDS011 über Steckverbinder
- Feinstaubsensor SPS30 (Sensirion) über Steckverbinder
- DHT22 Temperatur- Feuchtigkeitssensor über Stiftleiste
- I²C Anschlüsse mit 3,3V und 5V Versorgungsspannungs für DNMS und andere Sensoren (z.B. BMP/E280 Temperatur- Feuchtigkeitssensor) über Stiftleiste
- I²C-Bus-Verlängerung mit 5V Versorgungsspannung für entfernten DNMS Sensor (bei Verbindungen > 250mm) über RJ12 Buchse bzw. Stiftleiste

PCB Versions Historie:
- Airrohr-V1.1 - erste Version
- Airrohr-V1.2 - I²C-Bus Verlängerung mit zusätzlicher RJ-12 (Modular Jack) 6P/6C Buchse
- Airrohr-V1.4 - RJ12 Buchse nun für zwei unterschiedliche "Footprints" und in der Ausrichtung geändert 
			   - einige Bauelemente nach innen verschoben, damit der Einbau in ein Gehäuse (Rohr) einfacher ist 
			   - P82B715 (I²C-bus Extender IC) kann im DIP8 Gehäuse oder im SO8 Gehäuse bestückt werden
- Airrohr-V1.5 - Masseflächen an Ober- und Unterseite
- Airrohr-V1.6 - Layoutänderung der Stromversorgung an den Bauteilen R1, R2, R3 und J4

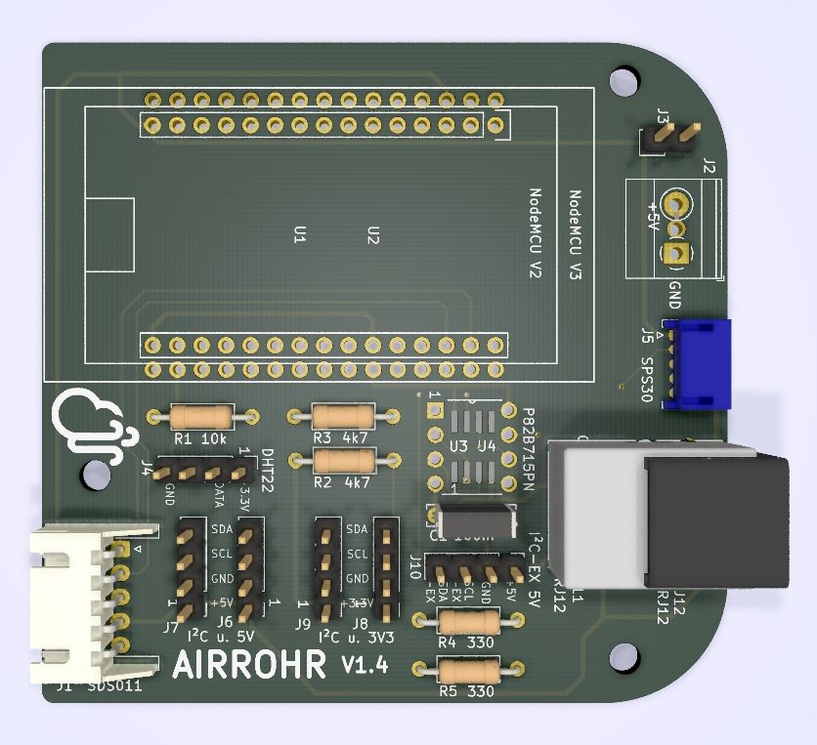
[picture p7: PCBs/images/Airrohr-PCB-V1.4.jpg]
<br>

### DNMS-RPI-HAT
Aufsatzboard für den Raspberry Pi um einen DNMS Sensor und andere I²C Sensoren mit dem Raspberry Pi zu verbinden. Das Board hat die gleich Größe wie ein RPI Zero W. Die folgenden Anschlüsse sind vorhanden:
- I²C-Bus Verlängerung mit 5V Versorgungsspannung für einen DNMS Sensor und Kabellängen > 250mm mittels RJ12 (Modular Jack) 6P/6C Buchse
- Feinstaubsensor SPS30 (Sensirion) mittels JST ZH Buchse
- 2 x I²C Anschlüsse über Stiftleiste mit 3,3V Versorgungsspannung für weitere Sensoren

PCB Versions Historie:
- DNMS-RPI-HAT-V1.0 - erste Version

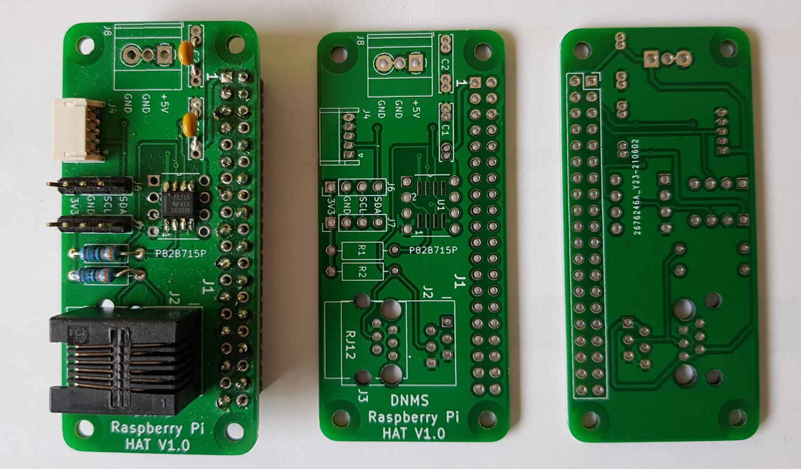
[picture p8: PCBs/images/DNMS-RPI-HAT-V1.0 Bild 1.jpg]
<br>

### DNMS-T3.6+NodeMCU
Kombiniertes Board für DNMS mit Teensy3.6 und NodeMCU V2 od. V3, neben der DNMS Funktion sind noch Anschlüsse für die die folgenden Sensoren vorhanden:
- Feinstaubsensor SPS30 (Sensirion) über Steckverbiner
- I²C Anschluss mit 3,3V Versorgungsspannung für z.B. BMP/E280 Temperatur- Feuchtigkeitssensor od. SHT3X Sensor über Stiftleiste

PCB Versions Historie:
- DNMS-T3.6+NodeMCU V1.0 - erste Version

### DNMS-T3.6
Basis Board für Teensy3.6 zum Anschluss ICS-43434 Mikrofon, die Lärmwerte werden über I²C an einen Kommunikationsprozessor (z.B. Airrohr-V1.4 mit NodeMCU) übertragen, für Entfernungen zum Kommunikationsprozessor > 250mm ist eine optionale I²C-Bus-Verlängerung vorhanden. Ein standard Telefonkabel mit RJ12 Verbindern (6P/6C) dient dann zur Verbindung des DNMS mit dem Airrohr Board.

PCB Versions Historie:
- DNMS-T3.6-V1.1 - erste Version
- DNMS-T3.6-V1.2 - I²C-Bus-Verlängerung mit zusätzlicher RJ-12 (Modular Jack) 6P/6C Buchse (passend zum Airrohr-V1.2)
- DNMS-T3.6-V1.3 - P82B715 (I²C-bus Extender IC) kann im DIP8 Gehäuse oder im SO8 Gehäuse bestückt werden
- DNMS-T3.6-V1.4 - RJ12 Buchse nun für zwei unterschiedliche "Footprints"

### DNMS-T4.0+NodeMCU
Kombiniertes Board für DNMS mit Teensy4.0 und NodeMCU V2 od. V3, neben der DNMS Funktion sind noch Anschlüsse für die die folgenden Sensoren vorhanden:
- Feinstaubsensor SPS30 (Sensirion) über Steckverbiner
- I²C Anschluss mit 3,3V Versorgungsspannung für z.B. BMP/E280 Temperatur- Feuchtigkeitssensor od. SHT3X Sensor über Stiftleiste

PCB Versions Historie:
- DNMS-T4.0+NodeMCU V1.2 - erste veröffentlichte Version
- DNMS-T4.0+NodeMCU V1.4 - einige Bauelemente wurden nach innen verschoben, damit der Einbau ins Gehäuse einfacher wird
- DNMS-T4.0+NodeMCU V1.5 - Masseflächen auf der Ober- und Unterseite um die Abschirmung zwischen Teensy4.0 und WLAN der NodeMCU zu erhöhen

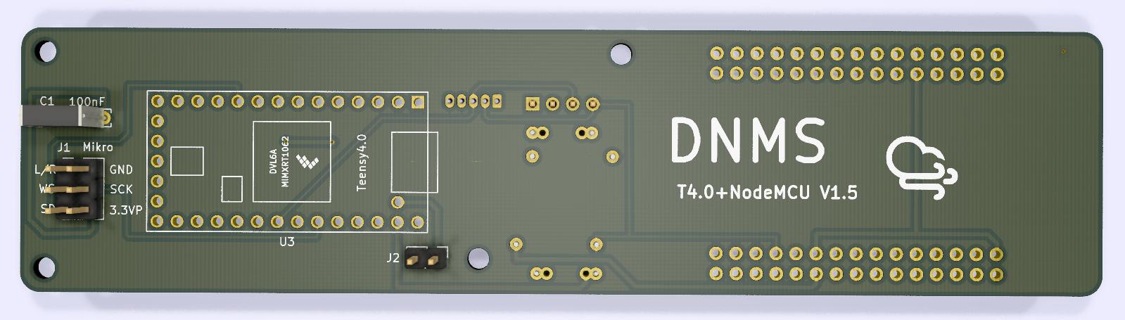
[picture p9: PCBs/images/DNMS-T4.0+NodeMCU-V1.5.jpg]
<br>

### DNMS-T4.0
Basis Board für Teensy4.0 zum Anschluss ICS-43434 Mikrofon, die Lärmwerte werden über I²C an einen Kommunikationsprozessor (z.B. Airrohr-V1.4 mit NodeMCU) übertragen, für Entfernungen zum Kommunikationsprozessor > 250mm ist eine optionale I²C-Bus-Verlängerung vorhanden. Ein standard Telefonkabel mit RJ12 Verbindern (6P/6C) dient dann zur Verbindung des DNMS mit dem Airrohr Board.

PCB Versions Historie:
- DNMS-T4.0-V1.2 - erste Version
- DNMS-T4.0-V1.4 - P82B715 (I²C-bus Extender IC) kann im DIP8 Gehäuse oder im SO8 Gehäuse bestückt werden
				 - RJ12 Buchse für I²C-Bus-Verlängerung mit zwei unterschiedlichen "Footprints"
- DNMS-T4.0-V1.5 - Masseflächen an Ober- und Unterseite
- DNMS-T4.0-V1.7 - Zusätzliche JST SR/SZ Buchsen für die Verbindung zum Mikrofon, wahlweise für 1:1 Kabel (Bezeichnung straight auf der Unterseite) oder "verdrehte" Kabel (Bezeichnung reverse auf der Unterseite). Achtung: Das Löten dieser JST Buchsen ist nicht ganz einfach.

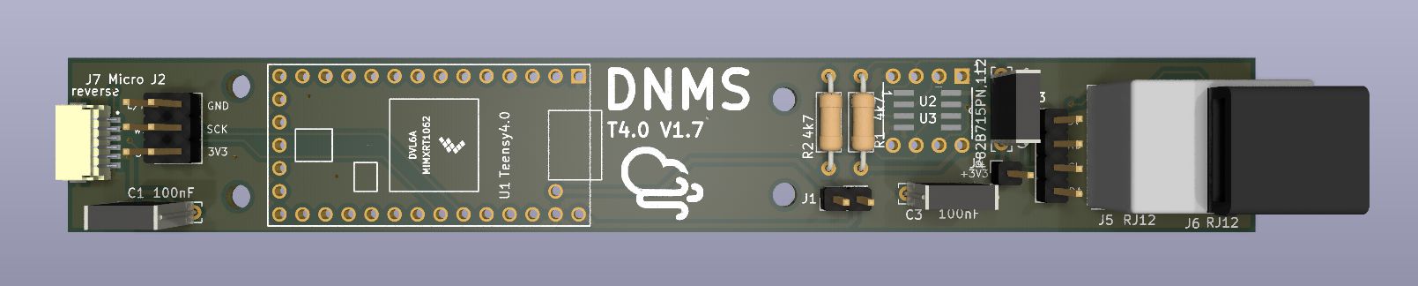
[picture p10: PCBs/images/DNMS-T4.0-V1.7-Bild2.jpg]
<br>

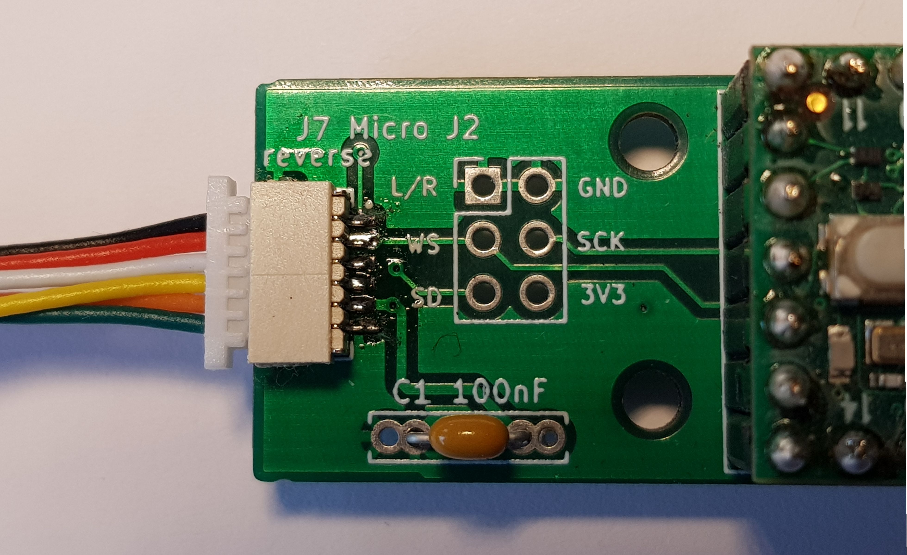
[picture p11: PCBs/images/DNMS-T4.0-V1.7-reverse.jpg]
<br>

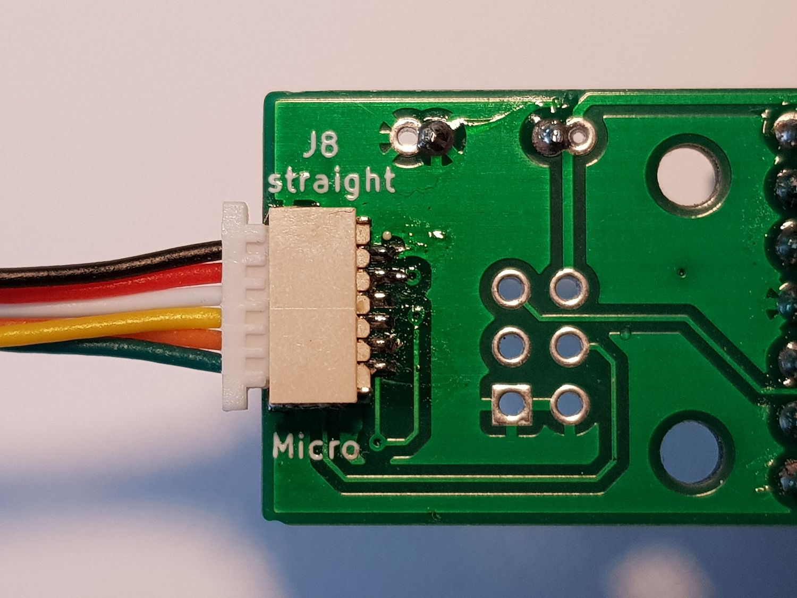
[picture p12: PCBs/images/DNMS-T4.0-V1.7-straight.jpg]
<br>

- DNMS-T4.0-V1.8S mit Layout für SMD Bestückung , so dass nicht nur die Herstellung der Platine beauftragt werden kann sondern direkt die Bestückung bei Firmen wie Aisler, EuroCircuits, JLCPCB oder PCBWay und weiteren. Das Einlöten des Teensy Boards sollte aus Kosten- und Logistikgründen allerdings weiterhin selbst erfolgen. Zwei Bauteilelisten sind als Beispiel für die Bestellung fertig bestückter Boards beigefügt. Dies ist jedoch immer den aktuell lieferbaren Bauelementen anzupassen. Das Layout basiert auf der EasyEDA Vorlage von Ralf Bötticher (vielen Dank!). Weiterhin gibt es zwei Änderungen im Layout:
	+ Verzicht der Brücke J1,  die Brücke war zur Stromversorgung für das standalone Flashen des Boards. Eine Auftrennung der Verbindung VIN - VUSB auf dem Teensy 4.0 Board ist nicht mehr notwendig.
	+ Einfügung einer Sicherung F1 in die 5V Versorgungsleitung der extended I²C Verbindung d.h. zwischen Kommunikationsprozessor und Teensy 4.0 Board.
	
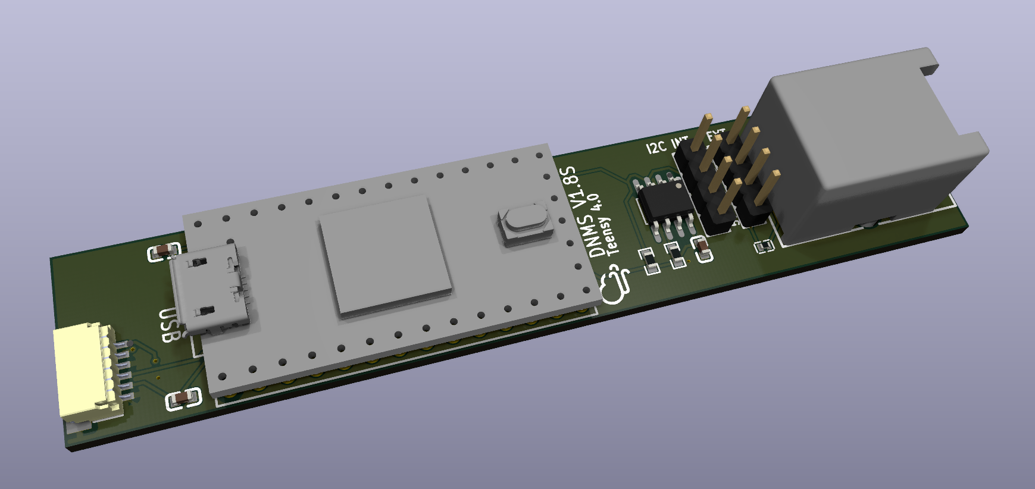
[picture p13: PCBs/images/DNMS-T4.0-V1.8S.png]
<br>

----------------------------------------------------------------------------------------------------------------
## PCBs English

## What are the different PCBs for

### IM72D128 microphone PCBs
Using the IM72D128 microphone is done by a set of two PCBs. A small round PCB holding the microphone itself and in addition one resistor and one capacitor. A second longish PCB is used holding the necessary circuitry for converting the microphones PDM interface to the Teensy4.0 I²S interface. Thus  compatibility with the former ICS-43434 microphone is preserved. Both boards can be mounted in 1/2" tube and sealed with a compound.

PCB revision history:
- IM72D128-PCB-V1.0 - first version round microphone board on GitHub
- IM72D128-Tube-PCB-V1.0 - first version longish interface board on GitHub

<br>
<br>

### ICS-43434 microphone PCB
A round microphone PCB, that fits into a 1/2" plastic tube (or into a 13mm stainless steel tube with 12mm inner diameter). A JST SH connector is on the board and a cable with JST SH connectors ca be used. Such cables are available e.g. at [Aliexpress](https://de.aliexpress.com/item/33013143346.html?spm=a2g0s.9042311.0.0.b4924c4dbhEWkt).

PCB revision history:
- ICS-43434-PCB-V1.3 - first version in GitHub
- ICS-43434-PCB-V1.4 - diameter of acoustic port changed from 0,6mm to 0,7mm

<br>

### Airrohr PCB
Basis board for NodeMCU V2 or V3 with possible connection of the following sensors:
- PM sensor SDS011 via connector
- PM sensor SPS30 (Sensirion) via connector
- DHT22 temperatur and humidity sensor via pin header
- I²C connection with 3.3V and 5V power for DNMS and other sensors (i.e. BMP/E280 or SHT3x) via pin header
- I²C-bus-extension with 5V power for DNMS sensor with connection lenght > 250mm via RJ12 connector or pin header

PCB revision history:
- Airrohr-V1.1 - first version
- Airrohr-V1.2 - I²C-bus-extension with RJ12 connector (Modular Jack 6P/6C) or pin header
- Airrohr-V1.4 - support for two different footprints for RJ12 connector, placement of RJ12 connector to different side
			   - placement of some components more to the inner side, so that everything fits better in a case (i.e. tube)
			   - P82B715 (I²C-bus Extender IC) layout allows assembly of DIP8 or SO8 package
- Airrohr-V1.5 - ground-planes on top and bottom side
- Airrohr-V1.6 - change of layout for power connection of R1, R2, R3 and J4
			   
<br>

### DNMS-RPI-HAT
Addon board for Raspberry Pi to connect the DNMS sensor to the RPI as well as other I²C sensors. Board has the same size as the RPI Zero W. The following connections are available:
- I²C-bus-extension with 5V power for DNMS sensor with connection lenght > 250mm via RJ12 (Modular Jack) 6P/6C connector
- PM sensor SPS30 (Sensirion) via JST ZH connector
- 2 x I²C connection via pin header with 3.3V power for other sensors (i.e. SCD30 and/or SHT3x) 

PCB revision history:
- DNMS-RPI-HAT-V1.0 - first version

<br>

### DNMS-T3.6+NodeMCU
This is a combination of a NodeMCU and a Teensy3.6, besides the DNMS functionality the following sensors could be connected:
- SPS30 PM sensor via connector
- I²C connection with 3.3V power for sensors like BMP/E280 or SHT3x via pin header

PCB revision history:
- DNMS-T3.6+NodeMCU V1.0 - first version

### DNMS-T3.6
DNMS board for Teensy3.6 to connect a ICS-43434 microphone, the noise measurements are transmitted via the I²C-bus to a communication processor (i.e. Airrohr-V1.4 with NodeMCU), if the distance to the communication processor exceeds 250mm then the I²C-bus-extension with RJ12 connector (Modular Jack 6P/6C) can be used. A standard telephone cable with RJ12 jacks on both sides (6P/6C) with up to 5m length or more provides the connection of the DNMS and the Airrohr board.

PCB revision history:
- DNMS-T3.6-V1.1 - first version
- DNMS-T3.6-V1.2 - I²C-bus-extension with RJ12 connector (Modular Jack 6P/6C) (fits Airrohr-V1.2)
- DNMS-T3.6-V1.3 - P82B715 (I²C-bus Extender IC) layout allows assembly of DIP8 or SO8 package
- DNMS-T3.6-V1.4 - RJ12 connector now for two different footprints

### DNMS-T4.0+NodeMCU
This is a combination of a NodeMCU and a Teensy4.0, besides the DNMS functionality the following sensors could be connected:
- SPS30 PM sensor via connector
- I²C connection with 3.3V power for sensors like BMP/E280 or SHT3x via pin header

PCB revision history:
- DNMS-T4.0+NodeMCU V1.2 - first version
- DNMS-T4.0+NodeMCU V1.4 - some components were moved towards the inner side, so that everything fits better in a case (i.e. tube)
- DNMS-T4.0+NodeMCU V1.5 - ground-planes on both sides to improve shielding between Teensy4.0 and WLAN of NodeMCU

<br>

### DNMS-T4.0
DNMS board for Teensy4.0 to connect a ICS-43434 microphone, the noise measurements are transmitted via the I²C-bus to a communication processor (i.e. Airrohr-V1.4 with NodeMCU), if the distance to the communication processor exceeds 250mm then the I²C-bus-extension with RJ12 connector (Modular Jack 6P/6C) can be used. A standard telephone cable with RJ12 jacks on both sides (6P/6C) with up to 5m length or more provides the connection of the DNMS and the Airrohr board.

PCB revision history:
- DNMS-T4.0-V1.2 - first version
- DNMS-T4.0-V1.4 - P82B715 (I²C-bus Extender IC) layout allows assembly of DIP8 or SO8 package
				 - support for two different footprints for RJ12 connector
- DNMS-T4.0-V1.5 - ground-planes on top and bottom side
- DNMS-T4.0-V1.7 - additional JST SR/SZ connectors possible for connection to microphone, can be 1:1 straight cable (on back side) or reverse cable (on top side). Attention: Soldering of these JST connectors is a bit difficult.

<br>

<br>

<br>

- DNMS-T4.0-V1.8S has a layout for SMD assembly. This means that you can commission the manufacture and assembly of the board from companies such as Aisler, EuroCircuits, JLCPCB and PCBWay. However, for cost and logistical reasons, it is recommended that you solder the Teensy board yourself. Two bills of materials (BOMs) are attached as examples for ordering fully assembled boards. These must always be adapted to the currently available components, though. The layout is based on the EasyEDA template by Ralf Bötticher (many thanks!). There are also two changes to the layout:
	+ The J1 jumper has been removed; this jumper was used to supply power for flashing the board in standalone mode. It is no longer necessary to cut the VIN – VUSB connection on the Teensy 4.0 board.
	+ Integration of a fuse F1 in the 5V power supply line of the extended I²C connection, i.e. between the communication processor and the Teensy 4.0 board.
	
<br>

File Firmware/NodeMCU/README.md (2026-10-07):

# [English text below](#nodemcu-firmware-for-dnms)

## NodeMCU Firmware für DNMS

### Versions Historie:

- AIRROHR-DNMS-6.0, AIRROHR-DNMS-6.0-en, AIRROHR-DNMS-6.0-fr
	+ Unterstützung der Teensy4.0 Firmware DNMS_V6.0.x mit der wesentlichen Änderung, dass die Frequenzgangkorrekturwerte beim Start von der NodeMCU an die Teensy4.0 Firmware übertragen werden. Ist eine ältere Firmware auf dem Tennsy4.0 Board installiert, so wird dies ebenfalls unterstützt d.h. es ist abwärtskompatibel.
	+ Neue Farbe und neues Logo für den lokalen Webserver:
	 
	+ Verbessertes Handling der Datenübertragung zu Sensor.Community und zu MQTT-Brokern um Datenverlust bei der Übertragung weiter zu reduzieren.

- AIRROHR-DNMS-5.17, AIRROHR-DNMS-5.17-en, AIRROHR-DNMS-5.17-fr
	+ Neue Konfigurationsmöglichkeit für verschiedene Mikrofone und Frequenzgangkorrekturen der Mikrofone. Eine Teensy4.0 Version ab DNMS_V5.8.x ist Voraussetzung um dies zu nutzen.
	+ Konfiguration eines digitalen Eingangs an der der NodeMCU. Der Zustand wird mit der Bezeichnung  DIN01 zur InfluxDB übertragen.
	+ Kleine Korrekturen im Source Code, so dass in der Arduino IDE Version 2.3.8 die Übersetzung ohne Warnungen erfolgt.

- AIRROHR-DNMS-5.16, AIRROHR-DNMS-5.16-en, AIRROHR-DNMS-5.16-fr
	+ Neue Konfigurationsmöglichkeit die WLAN Verbindung ohne Passwort auszuwählen aufgrund einer Änderung in der Wifi Lib. Dies ist notwendig  z.B. für Freifunk WLAN Verbindungen.
	+ Verbesserte Fehlerbehandlung bei der Datenübertragung und entsprechende Fehlerausgaben.
	+ Fehlerbeseitigung bei der Übertragung des Zeitstempels zur InfluxDB und zu einem MQTT Broker, wenn der DNMS Sensor nicht konfiguriert ist.

- AIRROHR-DNMS-5.12, AIRROHR-DNMS-5.12-en, AIRROHR-DNMS-5.12-fr
	+ NTP Server können nun in der Konfiguration gesetzt werden unter "Weitere Einstellungen"
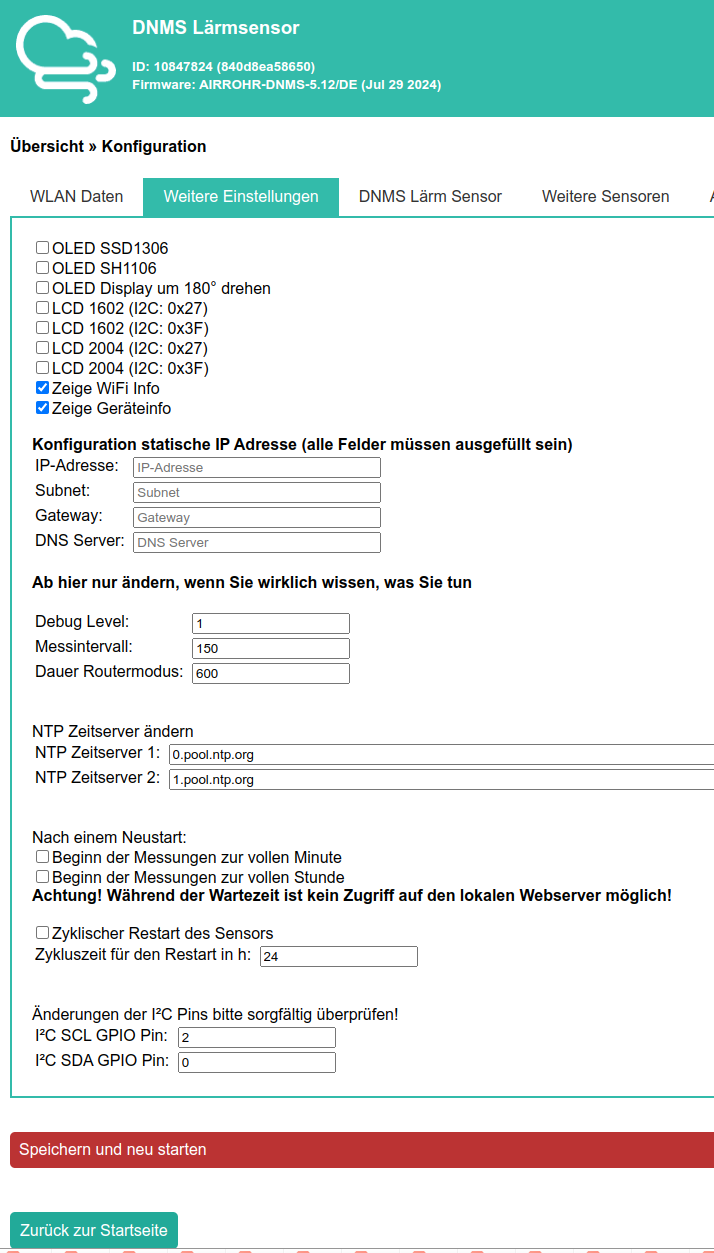
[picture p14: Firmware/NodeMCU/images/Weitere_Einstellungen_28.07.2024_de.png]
	 
	+ Konfigurationsänderung für die Übertragung zum MQTT Broker, eigenes Feld für die Konfiguration der MQTT Messung. Dies wird im InfluxDB Line Protocol als Measurement weitergegeben
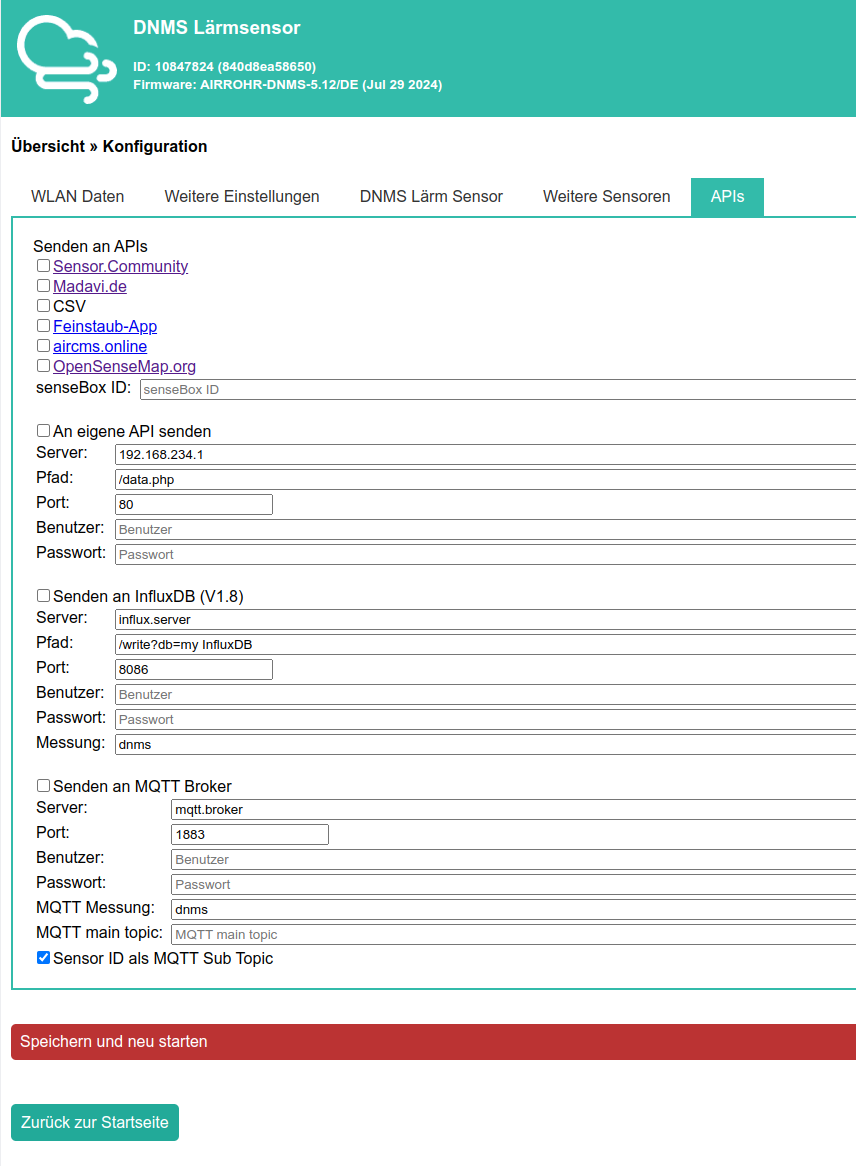
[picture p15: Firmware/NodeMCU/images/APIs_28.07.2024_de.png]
	 

 - AIRROHR-DNMS-5.8, AIRROHR-DNMS-5.8-en und AIRROHR-DNMS-5.8-fr<br>
     - MQTT Übertragung (z.Zt. kein TLS). Dies kann als weitere Möglichkeit unter APIs ausgewählt werden. Die Daten werden im InfluxDB Line Protocol Format übertragen (wie bei der direkten InfluxDB Übertragung).
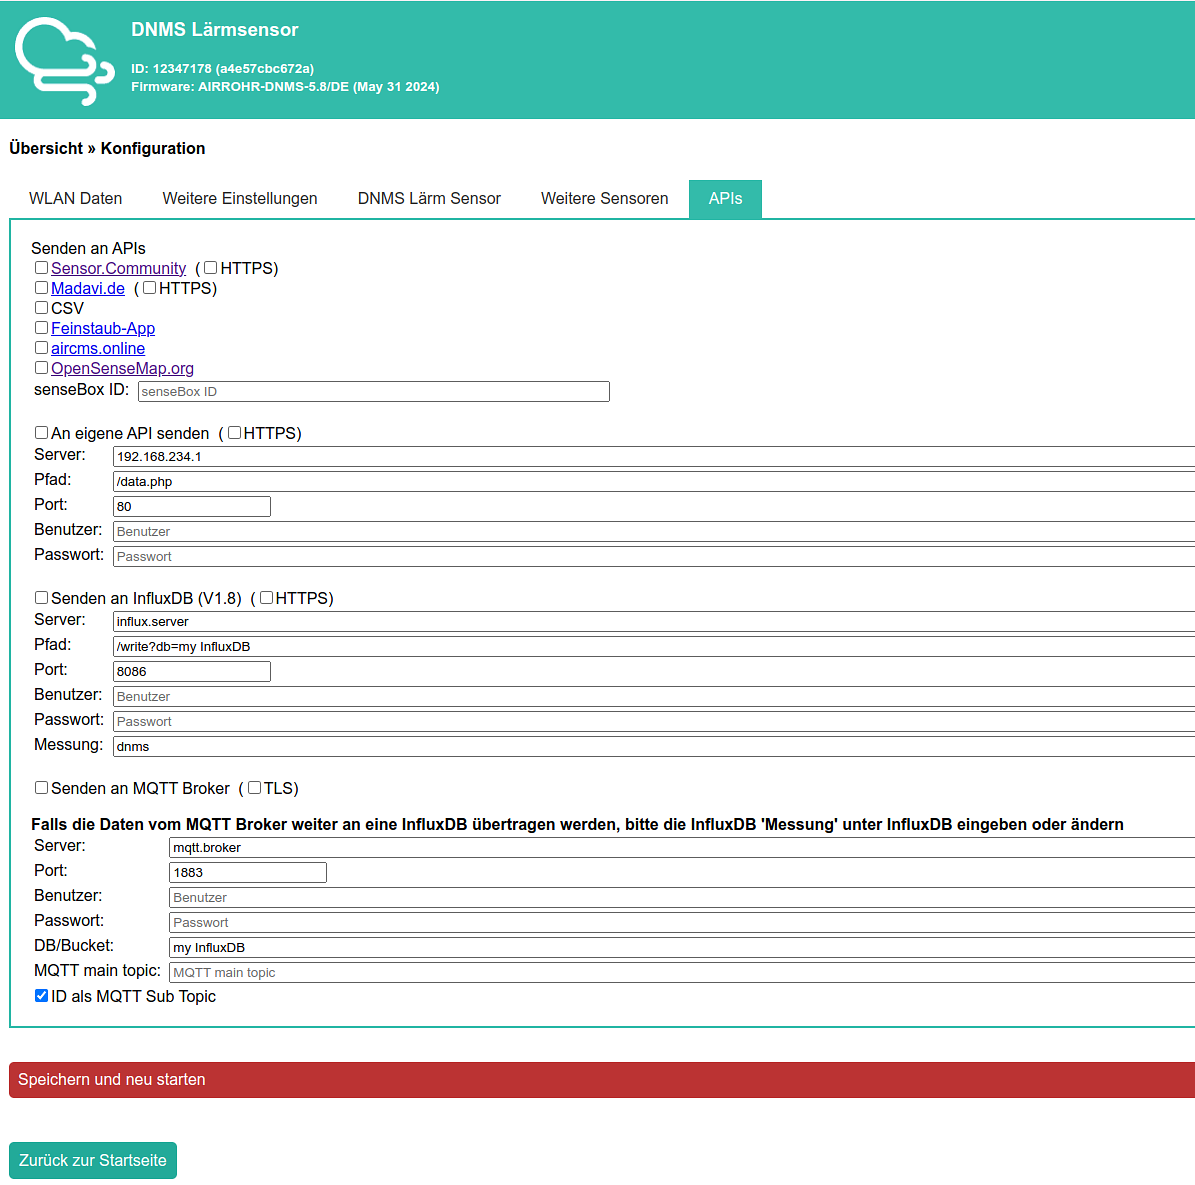
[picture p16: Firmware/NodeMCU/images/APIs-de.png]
  	 	 
   - Änderung der I²C PIns ist verschoben auf die Konfigurationsseite "Weitere Einstellungen"
   - Möglichkeit nach Restart mit den Messungen zur vollen Minute oder zur vollen Stunde zu beginnen. Konfiguration auf der Seite "Weitere Einstellungen"
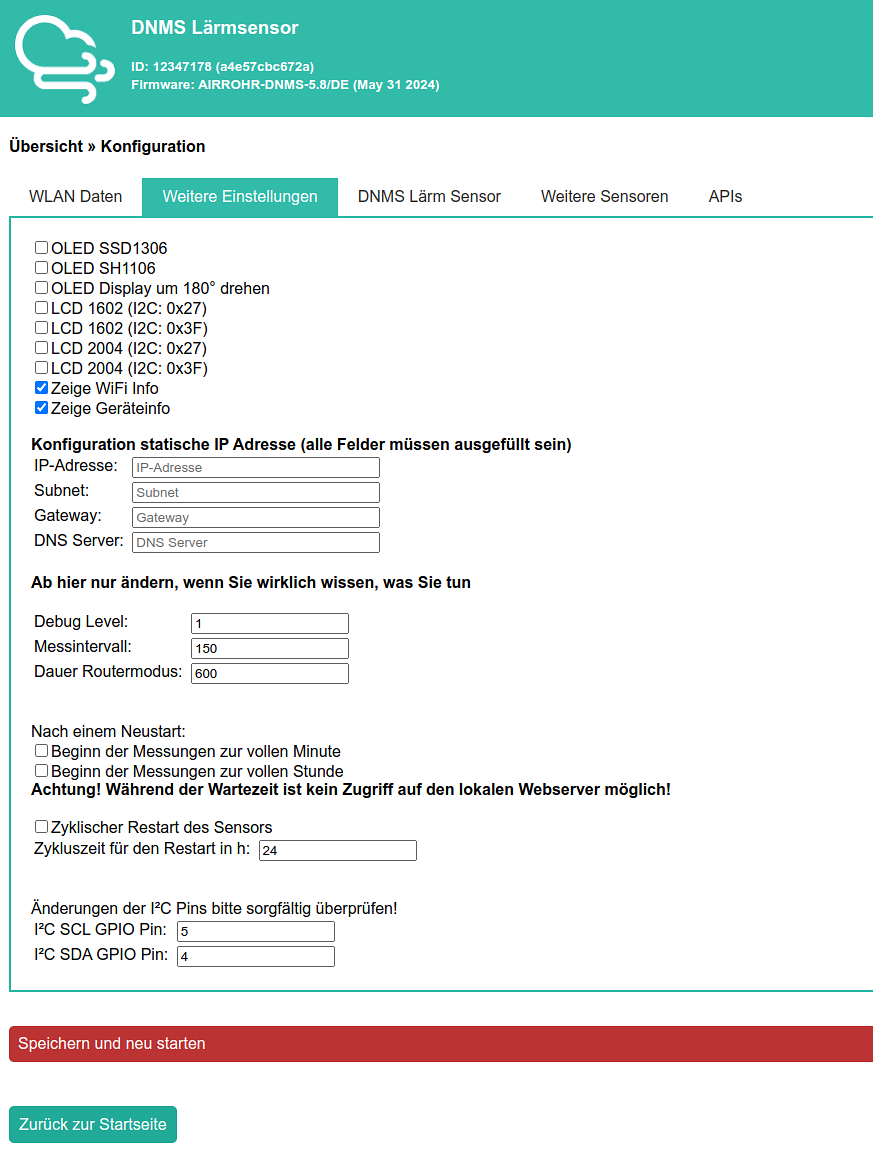
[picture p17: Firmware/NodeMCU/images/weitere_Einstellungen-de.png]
  	 	 
   - Auswahl des am Teensy4.0 angeschlossenen Mikrofons über die Konfigurationsseite "DNMS Lärm Sensor". Damit die Konfiguration durch einen entsprechenden Umschaltbefehl im Teensy4.0 umgesetzt werden kann, ist die Teensy4.0 Version DNMS_V5.3.x Vorraussetzung.
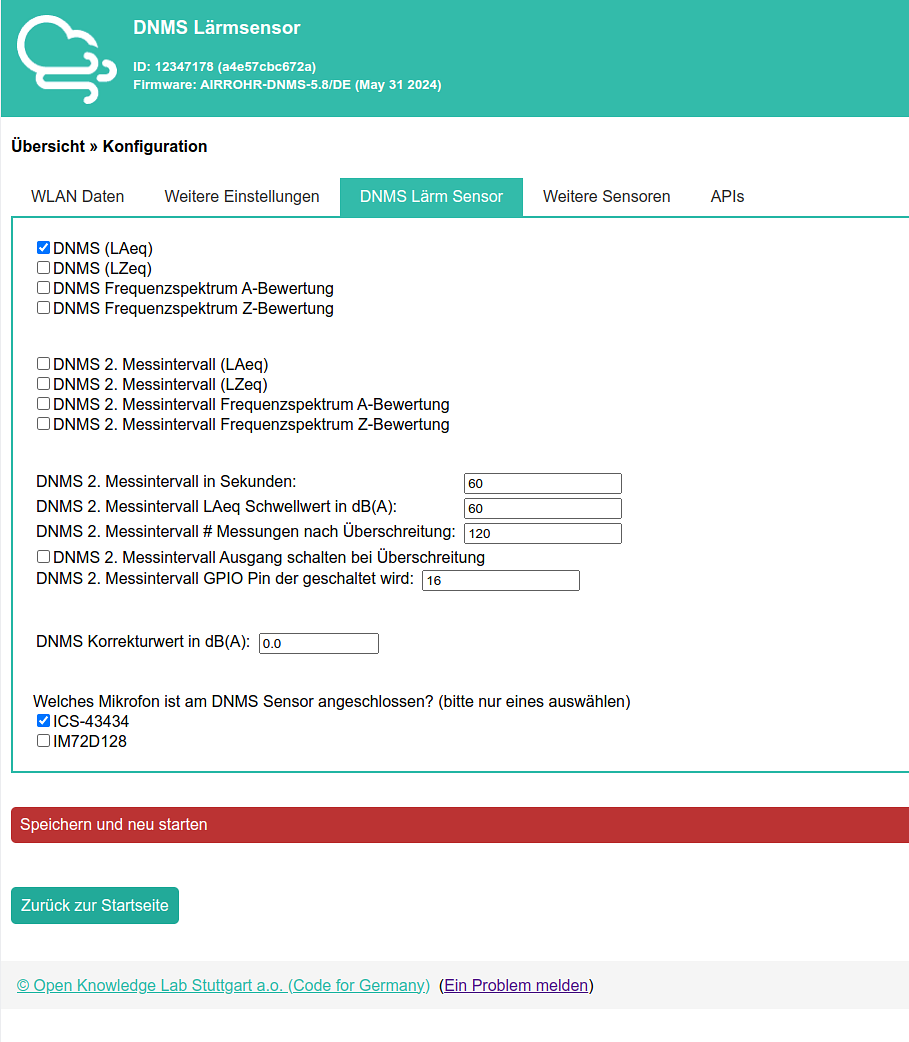
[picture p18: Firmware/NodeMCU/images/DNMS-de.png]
  	 	 
    - Erweiterte Debug Ausgabe am Start mit Ausgabe des Beginns der Messungen.
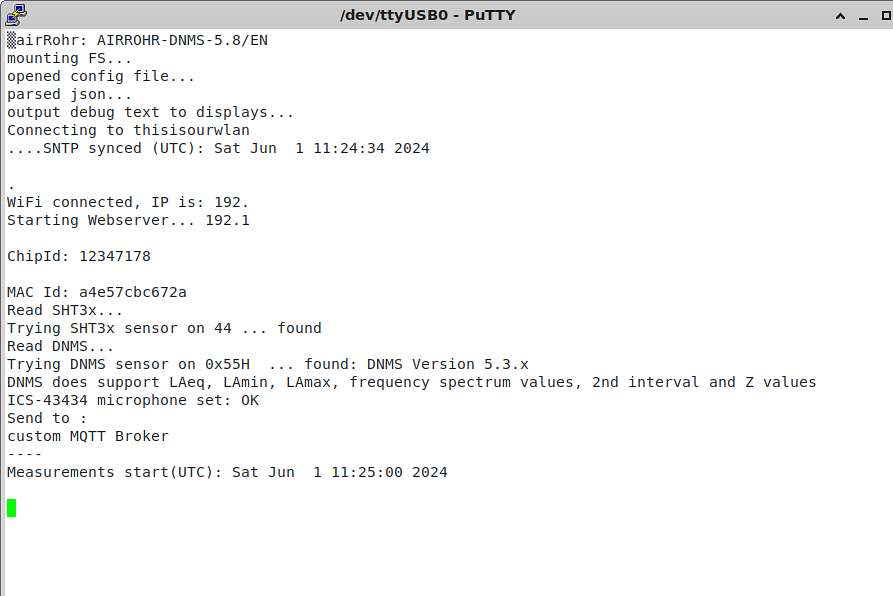
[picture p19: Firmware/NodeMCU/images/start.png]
  	 	 

 - NRZ-2020-134-DNMS-5.4, NRZ-2020-134-DNMS-5.4-en und NRZ-2020-134-DNMS-5.4-fr<br>
   - Neu NRZ-2020-134-DNMS-5.4-fr französische Version
   - Vergrößerter Puffer für die Übertragung zu eigenen APIs (z.B. InfluxDB), dadurch können neben sämtlichen DNMS Werten (1. und 2. Messintervall mit LA und LZ Terzwerten) auch Werte von mehreren weiteren Sensoren wie BME280 und/oder SEN5x übertragen werden.
   - Verbesserte Ausgabe bei Übertragungsfehlern zu Sensor.Community und zu eigenen APIs (z.B. zur InfluxDB) mit UTC Zeitangabe und Klartext.

 - NRZ-2020-134-DNMS-5.6, NRZ-2020-134-DNMS-5.6-en und NRZ-2020-134-DNMS-5.6-fr<br>
   - Fehlerbeseitigung: Der DNMS Korrekturwert wurde falsch umgewandelt, bei einer negativen Eingabe im Bereich von -0.1 - -0.9. Es wurde daraus ein positiver Wert erzeugt. Diese Fehlerbeseitigung gilt auch für den Temperatur Korrekturwert bei Temperatursensoren. Bei den Temperatursensoren wird der Korrekturwert nun addiert d.h. ein negativer Temperatur Korrekturwert verringert den Messwert.
   - Statusanzeige durch eine LED an GPIO16 / D0. Die NodeMCU V2 hat eine interne LED an GPIO16 / D0, andere Versionen nicht. Nach Power Up ist die LED zunächst an. Nachdem sich die NodeMCU mit dem WLAN verbunden hat, blinkt die LED mit der Frequenz von 2 Hz. Das folgende Bild zeigt, wie eine LED an GPIO0 angeschlossen werden kann, wenn keine interne LED vorhanden ist:
 
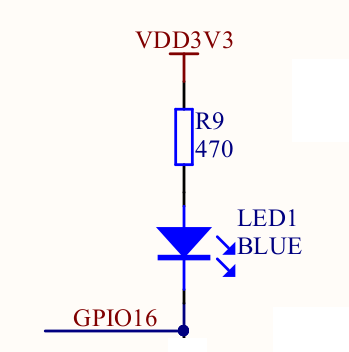
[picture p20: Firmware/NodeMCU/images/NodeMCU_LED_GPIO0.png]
   	 
   - Geänderte Speicheraufteilung. Deswegen ist es notwendig, dass der ESP8266 komplett gelöscht wird (Sketch und FS) beim Flashen dieser Version, andernfalls können Fehler beim Lesen der Konfiguration auftreten.

 - NRZ-2020-134-DNMS-5.4, NRZ-2020-134-DNMS-5.4-en und NRZ-2020-134-DNMS-5.4-fr<br>
   - Neu NRZ-2020-134-DNMS-5.4-fr französische Version
   - Vergrößerter Puffer für die Übertragung zu eigenen APIs (z.B. InfluxDB), dadurch können neben sämtlichen DNMS Werten (1. und 2. Messintervall mit LA und LZ Terzwerten) auch Werte von mehreren weiteren Sensoren wie BME280 und/oder SEN5x übertragen werden.
   - Verbesserte Ausgabe bei Übertragungsfehlern zu Sensor.Community und zu eigenen APIs (z.B. zur InfluxDB) mit UTC Zeitangabe und Klartext.
 
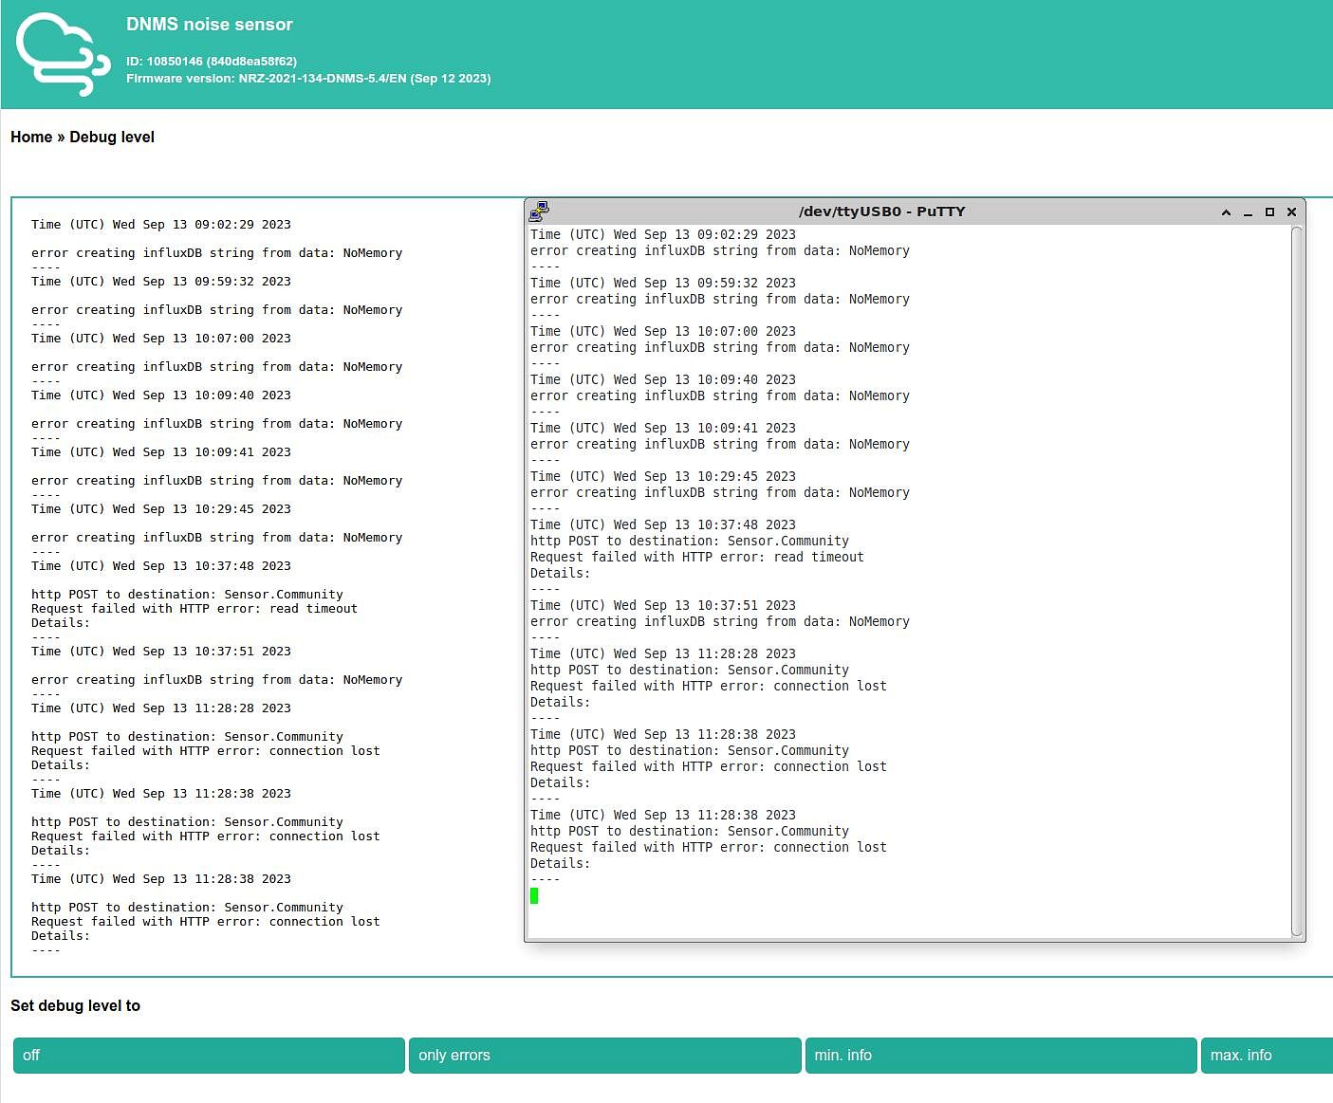
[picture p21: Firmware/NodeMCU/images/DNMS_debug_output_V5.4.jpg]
		
		
   - Geänderter Link um Probleme zu melden, geht zu zu https://github.com/hbitter/DNMS/issues
 
 - NRZ-2020-134-DNMS-5.2 und NRZ-2020-134-DNMS-5.2-en<br>
  NRZ-2020-134-DNMS-5.2-en  ist die englische Sprachversion

   - Debug Level standardmäßig auf Fehler (entspricht 1) gesetzt (zuvor war es standardmäßig auf min. Info entsprechend 3 gesetzt).
   - Debug Ausgabe über serielle USB Schnittstelle der NodeMCU auf 115200 Baud eingestellt (zuvor waren 9600 Baud eingestellt).
   - Erweitere Fehler Ausgabe der Übertragung zu Sensor.Community und zu eigenen APIs (z.B. zur InfluxDB).
         		
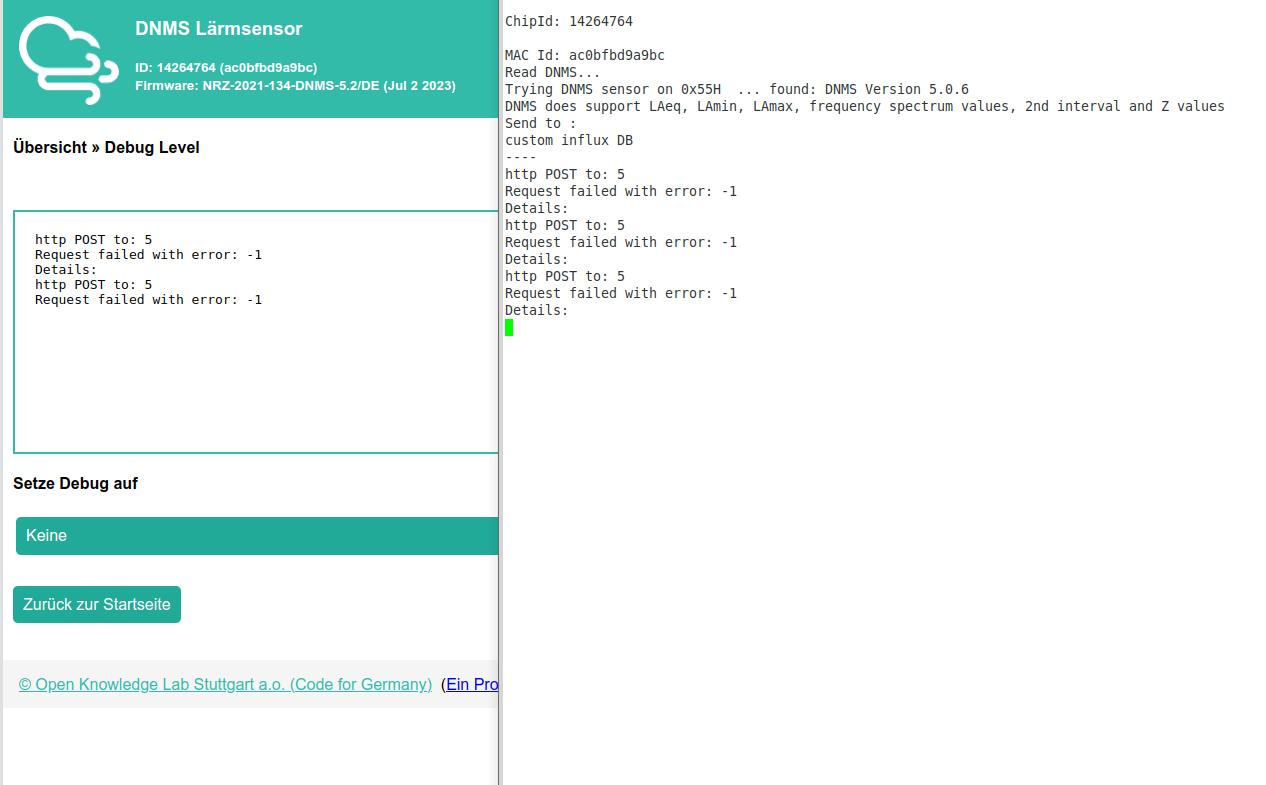
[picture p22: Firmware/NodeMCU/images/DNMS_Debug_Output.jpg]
      

   		Die Fehlerausgabe erfolgt sowohl über die serielle USB Schnittstelle der NodeMCU als auch über den lokalen WebServer der NodeMCU (Button Debug Level). Gibt es viele Übertragungsfehler, so lässt sich die lokale Web Seite Debug Level u.U. nicht aufrufen, da die Übertragung blockiert ist. In diesen Fällen hilft die Debug Ausgabe über den seriellen USB Ausgabg der NodeMCU.<br>
Das Übertragungsziel der NodeMCU wird durch die Ziffer in der Zeile http Post to: entsprechend der folgenden Tabelle angegeben:

		Ziffer | Ziel der Übertragung
---------- | ----------
0 | Sensor.Community
1 | Madavi.de
2 | OpenSenseMap
3 | FSapp
4 | aircms
5 | InfluxDB
6 | Custom
7 | Count

		Die weitere Tabelle gibt die Fehlercodes an:<br>
		
		Fehlercode | Bedeutung
---------- | ----------
-1 | Connection Failed
-2 | Send Header Failed
-3 | Send Payload Failed
-4 | Not Connected
-5 | Connection Lost
-6 | No Stream
-7 | No HTTP Server
-8 | Too Less RAM
-9 | Encoding
-10 | Stream Write
-11 | Read Timeout<br>

   - Berechnung und Ausgabe von Z-Werten - LZeq, LZmin, LZmax und ebenso die Terz LZeq Werte von 20Hz - 20.000Hz für beide Messintervalle. Die Einstellung, welche Werte berechnet und Ausgelesen werden sollen, erfolgt auf der DNMS Konfigurationsseite:
   
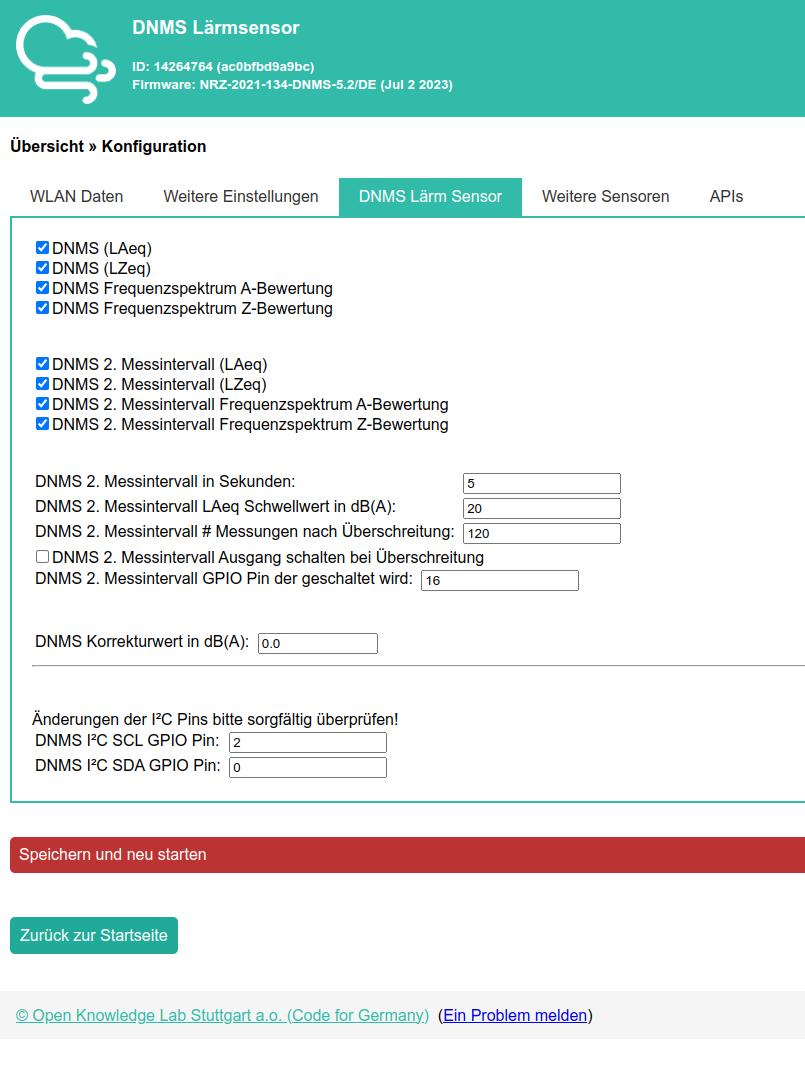
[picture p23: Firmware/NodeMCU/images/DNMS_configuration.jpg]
   		
   		
   		Zu Sensor.Community werden wie bisher nur die Werte LAeq, LAmin und LAmax übertragen. Die anderen Werte können an eine eigene API oder z.B. an eine InfluxDB übertragen werden.
		
 - NRZ-2020-134-DNMS-4.4
   - Stabileres Verhalten des lokalen Webservers auf der NodeMCU durch Übersetzung mit der Version 3.1.1 der ESP8266 Library
   - Ein zyklischer Restart der NodeMCU kann unter Konfiguration -> Weitere Einstellungen angegeben werden mit einer Zeitangabe für den Restart in Stunden. Dies kann bei Problemen mit Routern und Proxys helfen, die nach einer festen Zeit die WLAN Verbindung unterbrechen.  
   
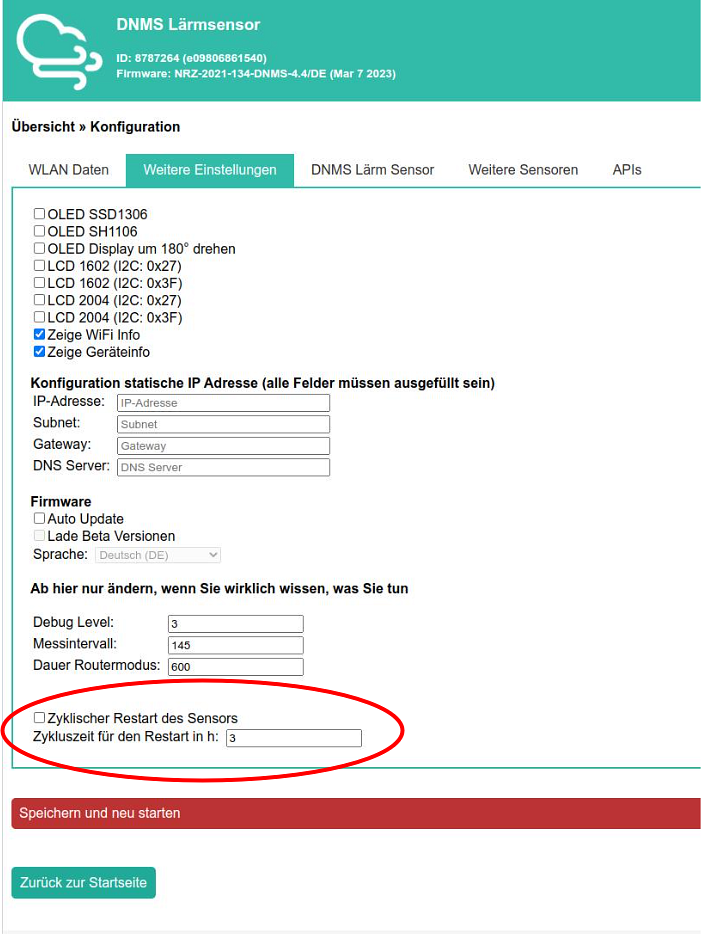
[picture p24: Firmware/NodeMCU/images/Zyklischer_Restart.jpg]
   		
   - Unterstützung weiterer Sensoren:<br>
   -- SEN5X Feinstaub, Temperatur u. Feuchtigkeitssensor sowie je nach Version Index für VOC und NOx<br>
   -- SCD30 CO2 Sensor<br>
   -- SCD40 CO2 Sensor<br>
   
   - Erweitere Status Ausgabe von Sensoren (DNMS, SEN5X, SCD30, SCD40) unter Gerätestatus, insbesondere Ausgabe der DNMS Version:
   
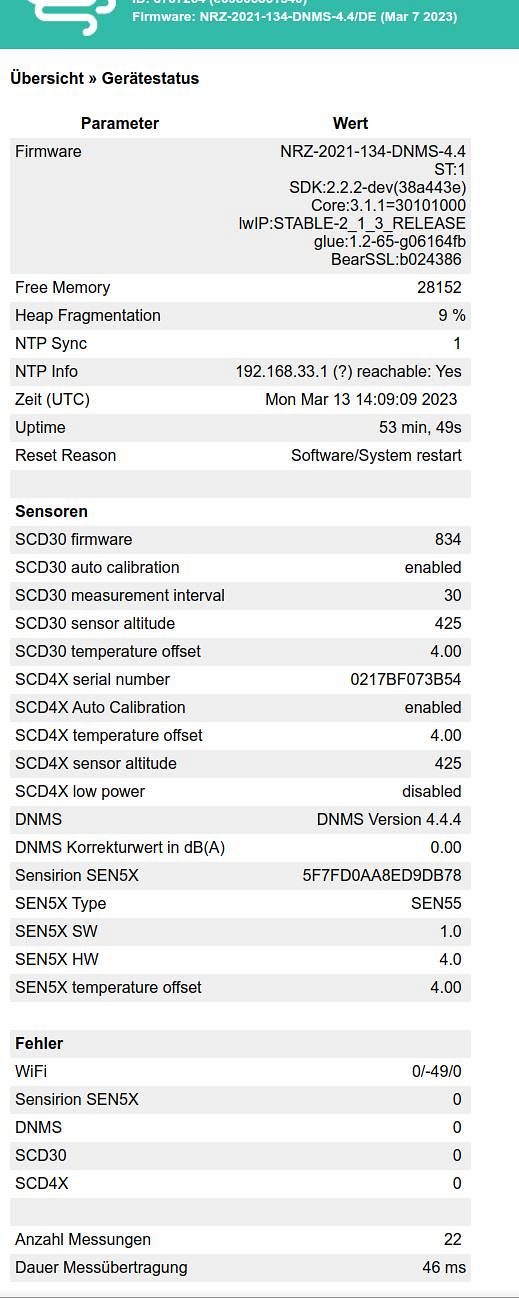
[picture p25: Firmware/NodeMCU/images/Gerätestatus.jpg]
   		

 - NRZ-2020-134-DNMS-4.4-en
 	 - Version mit englischen Texten auf der lokalen Webseite, ansonsten identisch mit NRZ-2020-134-DNMS-4.4
<br><br>
 	 
 - NRZ-2020-134-DNMS-4.2
	 - 2.Messintervall unabhängig vom 1. Messintervall (ab 1 Sekunde)
	 - Wenn die Daten des 1. Messintervalls zu Sensor.Community übertragen werden (Sensor.Community unter APIs ausgewählt), denn wird die Zeit des 1. Messintervall auf 145 Sekunden gesetzt unabhängig davon, welche Zeit dort zuvor eingetragen wurde, damit die Übertragung zu Sensor.Community zustande kommt
	 - Ist unter APIs die Übertragung zu einer InfluxDB ausgewählt, werden sohl die Daten des 1. als auch die Daten des 2. Messintervalls zu der InfluxDB übertragen
	 - Bei der Übertragung zur InfluxDB wird ein in der NodeMCU generierter Zeitstempel mit zur InfluxDB übertragen. Zu Sensor.Community wird wie bei der standard Sensor.Community NodeMCU Firmware kein Zeitstempel übertragen
	 - Konfiguration neuer Reiter 'DNMS Lärm Sensor':
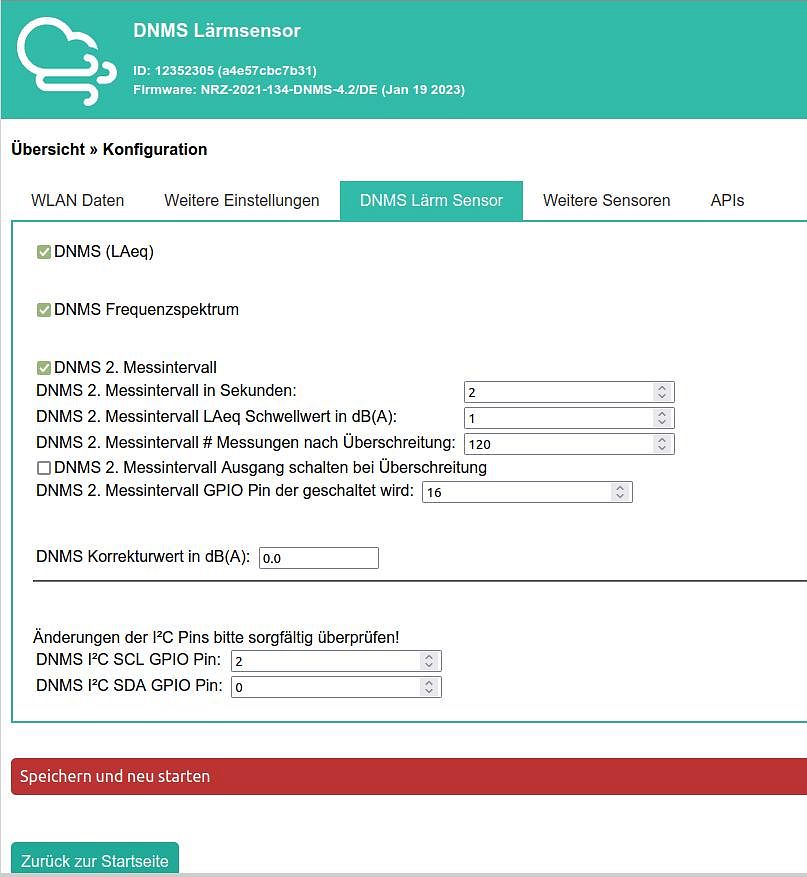
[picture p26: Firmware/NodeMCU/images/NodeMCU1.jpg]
	 
	<br>-- aktiviere/deaktivieren der DNMS Berechnung Frequenzspektrum<br>
	-- aktivieren/deaktivieren des 2. Messintervalls für DNMS<br>
	-- Eingabe der Intervallzeit des 2. Messintervalls (ab 1 Sekunde)<br>
	-- Eingabe eines Schwellwertes in dB(A) für den LAeq des 2. Messintervalls ab dem die Übertragung der Werte des 2. Messintervalls gestartet wird<br>
	-- Eingabe der Anzahl an Messungen des 2. Messintervalls, die nach Überschreitung des Schwellwerts übertragen werden. Wird der Schwellwert während dieser Zeit überschritten, startet die Zählung der Messungen wieder bei 0.<br>
	-- aktivieren/deaktivieren ob ein GPIO Ausgang nach Überschreitung des Schwellwerts geschaltet werden soll.<br>
	-- Eingabe des GPIO Ausgangs, der bei Überschreitung des Schwellwerts geschaltet werden soll. Bitte prüfen, ob der Ausgang nicht anderweitig benutzt wird!<br>
	-- Eingabe eines DNMS Korrekturwertes (wie in den Versionen zuvor)<br>
	-- Eingabe der GPIO Pins für die I²C Verbindung zum DNMS sensor (und evtl. anderen Sensoren). Die standard GPIO Pins von Sensor.Community für die NodeMCU sind: GPIO Pin 2 für SCL und GPIO Pin 0 für SDA. Für ein Wemos Board kann die Belegung beispielsweise  geändert werden auf: GPIO Pin 5 für SCL und GPIO Pin 4 für SDA. Bitte Vorsicht bei der Änderung der I²C Pins.
	 
	 - Die weiteren Sensoren sind nun unter dem Reiter Konfiguration 'Weitere Sensoren' zu finden.
 <br>

 - NRZ-2020-134-DNMS-4.2-en
 	 - Version mit englischen Texten auf der lokalen Webseite, ansonsten identisch mit NRZ-2020-134-DNMS-4.2
<br><br>

 - NRZ-2020-134-DNMS-3.3 - Korrektur der I²C Clock Frequenz
 
 - NRZ-2020-134-DNMS-3.3-en - Korrektur der I²C Clock Frequenz<br><br>

 - NRZ-2020-134-DNMS-3.2
	- Abfrage Terzwerte vom DNMS - Vorausetzung Firmware V3 oder V4 auf dem Teensy
	- Terzwerte werden **nicht** an Sensor.Community übertragen
	- Terzwerte können an andere APIs übertragen werden z.B. InfluxDB
	<br>
	
 - NRZ-2020-134-DNMS-3.2-en
	 - Version mit englischen Texten auf der lokalen Webseite, ansonsten identisch mit NRZ-2020-134-DNMS-3.2
<br><br>

## Firmware auf das NodeMCU Board schreiben (flashen)

Die übersetzten lauffähigen Programme haben immer die Bezeichnung airrohr-firmware.ino.bin. Sie müssen nur noch auf das NodeMCU Board geschrieben (geflasht) werden. 

### ohne Arduino IDE

Es ist nicht notwendig dafür die Arduino IDE zu installieren und/oder zu benutzen. Eine geeignete Anwendung dafür ist der kostenlose ESPHome-Flasher. Über den Link: https://github.com/esphome/esphome-flasher/releases kann die Anwendung für Windows, Mac und Linux (Ubuntu) geladen und dann installiert werden.<br><br>
Nach dem Starten des ESPHome-Flashers zuerst den seriellen Port auswählen (obere Zeile Serial port):

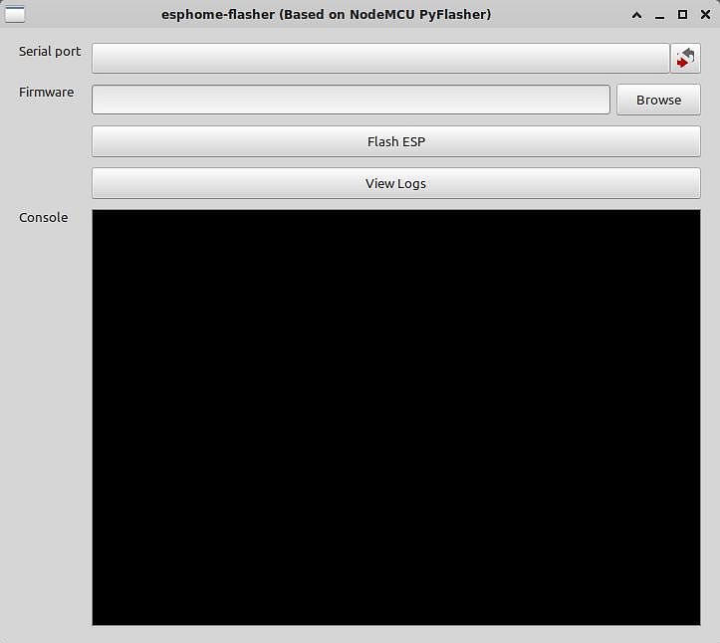
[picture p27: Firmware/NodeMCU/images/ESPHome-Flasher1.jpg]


Dann die Firmware auswählen, die auf die NodeMCU geflasht werden soll (Zeile Firmware):



Mit dem Button "Flash ESP" das Flashen starten. Im Console Fenster erscheinen Ausgaben, die über den Verlauf des Vorgangs informieren.



Achtung: Da der ESPHome-Flasher den gesamten Flash Speicher löscht, gehen auch abgespeicherte Konfigurationsdaten verloren und die NodeMCU muss nach dem Flashen wieder in das lokale WLAN integriert werden. Evtl. wird beim Zugriff auf die NodeMCU, wenn die NodeMCU als AP arbeitet, ein Passwort abgefragt. Das Passwort lautet: "airrohrcfg". Ebenso sind die Konfigurationsdaten der Sensoren und der APIs gelöscht und müssen wieder eingeben werden! 

### mit Arduino IDE

Ist die Arduino IDE installiert, erfolgt das Schreiben der Firmware auf das NodeMCU Board direkt im Anschluss an die Übersetzung der Firmware aus der Arduino IDE heraus (siehe Arduino IDE Beschreibung).

## Anmerkung zum selbst Übersetzen der NodeMCU Firmware

 - Die Übersetzung der Firmware kann unter der Arduino IDE erfolgen. Alle Libs, die auch in der Sensor.Community firmware eingebunden werden, müssen auch hier verfügbar sein. Nur die für die Arduino IDE notwendigen Files sind im Source Ordner enthalten. PlatformIO wird nicht benutzt, deshalb sind keine PlatformIO Files vorhanden. In der Arduino IDE Umgebung ist ein File mit dem Namen platform.local.txt anzulegen mit den beiden folgenden Einträgen:

	compiler.c.extra_flags=-fpermissive<br>
	compiler.cpp.extra_flags=-fpermissive<br>
	
 - Zum Übersetzen der Version 4.4 unbedingt die ESP8266 Library 3.1.1 benutzten.
 - Die Version 5.4 ist mit der Arduino IDE 2.2.1, der ESP8266 Library 3.1.2 sowie mit folgenden Einstellungen übersetzt:

 	

 - Zum Ändern der Sprachversion in der Datei intl.h
 
	
	
	den entsprechenden include File auswählen. Bei weiteren Sprachen neben Englisch, Französisch und Deutsch sind die Sprach-Files noch nicht vollständig angepasst.

------------------------------------------------------------------------

## NodeMCU firmware for DNMS

### Version history:

- AIRROHR-DNMS-6.0, AIRROHR-DNMS-6.0-en, AIRROHR-DNMS-6.0-fr
	+ Support for the Teensy 4.0 firmware DNMS_V6.0.x, with the key change being that the frequency response correction values are transferred from the NodeMCU to the Teensy 4.0 firmware at start-up. If an older version of the firmware is installed on the Teensy 4.0 board, this is also supported; in other words, it is backwards compatible.
	+ A new colour scheme and a new logo for the local web server:
	 
	+ Improved handling of data transmission to Sensor.Community and to MQTT brokers to further reduce data loss during transmission.

- AIRROHR-DNMS-5.17, AIRROHR-DNMS-5.17-en, AIRROHR-DNMS-5.17-fr
	+ New configuration options for different microphones and microphone frequency response corrections. A Teensy 4.0 version from DNMS_V5.8.x onwards is required to use this feature.
	+ Configuring a digital input on the NodeMCU. The status is transmitted to InfluxDB under the label DIN01.
	+ Minor corrections to the source code so that the code compiles without warnings in Arduino IDE version 2.3.8.

- AIRROHR-DNMS-5.16, AIRROHR-DNMS-5.16-en, AIRROHR-DNMS-5.16-fr
	+ New configuration option to select the WLAN connection without a password due to a change in the Wifi Lib. This is necessary, for example, for Freifunk WLAN connections.
	+ Improved error handling during data transfer and corresponding error output.
	+ Bug fix when transferring the timestamp to InfluxDB and an MQTT broker when the DNMS sensor is not configured.

- AIRROHR-DNMS-5.12, AIRROHR-DNMS-5.12-en, AIRROHR-DNMS-5.12-fr
	+ NTP servers can now be set in the configuration under "More settings".
		 
	+ Configuration change for MQTT Broker transmission, separate field for configuring the MQTT measurement. This will be reported as a measurement in the InfluxDB line protocol.
	 
	 
- AIRROHR-DNMS-5.8, AIRROHR-DNMS-5.8-en and AIRROHR-DNMS-5.8-fr<br>
     - MQTT ttransmission (currently no TLS). This further choice can be selected under APIs. Data is transmitted in InfluxDB Line Protocol format (same as direct InfluxDB transmission).
  	 	 

	- Changing the I²C PIns has been moved to the “More settings” configuration page
   - Possibility to start measuring on the full minute or on the hour after a restart. Configuration on the “More settings” page
  	 	 
   - Selection of the microphone connected to the Teensy4.0 via the "DNMS noise sensor" configuration page. The Teensy4.0 version DNMS_V5.3.x is required to use the switch command in Teensy4.0.
  	 	 
    - Extended debug output at start with output of measurement start.
  	 	 

 - NRZ-2020-134-DNMS-5.6, NRZ-2020-134-DNMS-5.6-en and NRZ-2020-134-DNMS-5.6-fr<br>
   - Bug fix: DNMS correction value was wrong for negative input in range -0.1 to -0.9. The resulting correction value was positive instead of negative. This bug fix also applies to the temperature correction value. For all temperature sensors the correction value is now added, i.e. a negative temperature correction value will lower the reading.
   - LED status indication on GPIO0 / D0. NodeMCU V2 has an internal LED on GPIO0 / D0, other versions do not. After power up the LED is on. After the NodeMCU is connected to the WLAN, the LED flashes with a frequency of 2 Hz. The following illustration shows how to connect an LED if there is no internal LED on the board:
 
   	 

   - Changed flash order. It is therefore necessary to erase the entire flash of the ESP8266 (sketch and FS) before flashing the new firmware, otherwise there may be problems reading the configuration.

 - NRZ-2020-134-DNMS-5.4, NRZ-2020-134-DNMS-5.4-en and NRZ-2020-134-DNMS-5.4-fr<br>
   - New NRZ-2020-134-DNMS-5.4-fr french version
   - Enlarged buffer for transfer to own APIs (e.g. InfluxDB), so not only all DNMS values can be transferred, but also values from other sensors such as BME280 and/or SEN5x.
   - Further enhanced output of transmission errors to Sensor.Community and to own APIs (e.g. InfluxDB) now with UTC time info and plaintext.

		
		
	- Changed link to report problems, it's now to  https://github.com/hbitter/DNMS/issues

 - NRZ-2020-134-DNMS-5.2 and NRZ-2020-134-DNMS-5.2-en<br>
  NRZ-2020-134-DNMS-5.2-en  is the version with english text

   - Default Debug Level is now sat to error (equates to 1). Before ist was sat to min. info (equates to 3).
   - Baud rate of Debug Output on serial USB of NodeMCU is now sat to 115200 baud (before it was sat to 9600 baud).
   - Enhanced error output for transfers to Sensor.Community and the other APIs (e.g. InfluxDB).
   
   		
   		
   		Debug Output of errors is done via the serial USB interface of the NodeMCU as well as the Debug level page of the local webserver (Button Debug level). If a lot of transmission errors occurs the access to the Debug level page may be blocked. In such a case the output via the serial USB interface is helpful.

		The destination of the transmission is shown in the line http Post to: as a single figure:

		figure | destination of transmission
---------- | ----------
0 | Sensor.Community
1 | Madavi.de
2 | OpenSenseMap
3 | FSapp
4 | aircms
5 | InfluxDB
6 | Custom
7 | Count

		Die weitere Tabelle gibt die Fehlercodes an:<br>
		
		error code | meaning
---------- | ----------
-1 | Connection Failed
-2 | Send Header Failed
-3 | Send Payload Failed
-4 | Not Connected
-5 | Connection Lost
-6 | No Stream
-7 | No HTTP Server
-8 | Too Less RAM
-9 | Encoding
-10 | Stream Write
-11 | Read Timeout<br>

   - Calculation and output of Z-values - LZeq, LZmin, LZmax as well as LZeq 1/3 octave values from 20Hz - 20.000Hz for both measurement intervals The configuration what values are calculated is done on the DNMS noise sensor configuration page:
   
   		
   		
   		To Sensor.Community only LAeq, LAmin and LAmax values are transmitted as before. All the other values can be transmitted to own APIs e.g. to an InfluxDB.

  - NRZ-2020-134-DNMS-4.4
    - More stability of thge local NodeMCU webserver based on compilation with version 3.1.1 of ESP8266 Library
    - Cyclic restart can now be configured with timing in hours. This can solve problems with routers and proxys, which cut the WLAN connection after a specific time frame. 
    
    	 
    
    - Support of further sensors:<br>
   -- SEN5X PM, temperature, humidity and depending on the version VOC index and NOx index<br>
   -- SCD30 CO2 sensor<br>
   -- SCD40 CO2 sensor<br>
   
    - More status output for some sensors (DNMS, SEN5X, SCD30, SCD40) shown under device status, especially showing DNMS version:
    
    	 

 - NRZ-2020-134-DNMS-4.4-en
 	 - Version with english text on the local webpage, otherwise identical with  NRZ-2020-134-DNMS-4.4<br><br>

 - NRZ-2020-134-DNMS-4.2
	 - 2nd measurement interval independent from 1st interval (from 1 second on)
	 - If transmission of data from the 1st interval to Sensor.Commiúnity is activated, then the measurement time for the 1st interval is set to 145 seconds independently what time was configured before to make the transmission to Sensor.Community possible
	 - Is the transmission to an InfluxDB is activated, then 1st interval data as well as 2nd interval data is transmitted to the InfluxDB
	 - A timestamp is added in the NodeMCU to the data transmitted to an InfluxDB. No timestamp is added to the data to Sensor.Community, no change compared to the standard Sensor.Community NodeMCU firmware
	 - Home  >> Configuration new tab "DNMS noise sensor":
	 
	<br>-- activate/deactive DNMS frequency spectrum<br>
	-- activate/deactivate DNMS 2nd measurement interval<br>
	-- configure the interval time for the 2nd measurement (from 1 second on)<br>
	-- configure a threshold in dB(A) for the LAeq value that transmission of 2nd measurement values is started<br>
	-- configure the number of 2nd interval measurements that are transmitted after the threshold is exceeded. If the threshold is exceeded during that time, the number starts counting again<br>
	-- activate/deactivate switching of an GPIO output port if the threshold is exceeded<br>
	-- configure the GPIO port that is switched - be careful and check that the pprt is not otherwise used<br>
	-- configure a DNMS correction (as in versions before)<br>
	-- configuration of GPIO pins for the I²C connection to the DNMS sensor (and maybe other sonsors). The standard from Sensor.Community for the NodeMCU is: GPIO pin 2 for SCL and GPIO pin 0 for SDA. For a Wemos board you can change it e.g. to GPIO pin 5 for SCL and GPIO pin 4 for SDA. Please be careful changing the I²C pins.
	
	 - Futher sensors are now under the tab "more sensors"

 - NRZ-2020-134-DNMS-4.2-en
 	 - Version with english text on the local webpage, otherwise identical with  NRZ-2020-134-DNMS-4.2<br><br>

 - NRZ-2020-134-DNMS-3.3 - correction of I²C clock frequency
 
 - NRZ-2020-134-DNMS-3.3-en - correction of I²C clock frequency<br><br>
 
 - NRZ-2020-134-DNMS-3.2
	- Reading of 1/3 octave values from DNMS - prerequisite using firmware V3 or V4 on Teensy
	- 1/3 octave values are **not** transmitted to Sensor.Community
	- 1/3 octave values can be transmistted to other APIs e.g. to an InfluxDB
	
 - NRZ-2020-134-DNMS-3.2-en
	 - Version with english text on the local webpage, otherwise identical with  NRZ-2020-134-DNMS-3.2
<br><br>

## How to flash the NodeMCU
The compiled and executable firmware for the NodeMCU is always named airrohr-firmware.ino.bin. The firmware has only to be flashed on the board.

### without Arduino IDE

There is no need to install and use the Arduino IDE to flash the NodeMCU. A standalone application for doing that job is ESPHome-Flasher. You can download the appropriate version for Windows, Mac and Linux (Ubuntu) application via the link: https://github.com/esphome/esphome-flasher/releases,and then install the application.
<br><br>
After start of the application ESPHome-Flasher first select the serial port where the NodeMCU is connected to (top line):



Then select the firmware you want to flash (line Firmware):



Start the flashing process by clicking the button "Flag ESP". in the Console window some output is schown about the progress of the flashing process.



Attention: ESPHome-Flasher erases the complete flash therefore all configuration data is lost as well. The NodeMCU has to be integrated in your local WLAN. Possibly a password will be asked by accessing the NodeMCU. The password is "airrohrcfg". As well all sensor configuration and API configuration is lost and has to be input again!

### with Arduino IDE

Is the Arduino IDE installed then flashing of the NodeMCU takes place as the next step after compiling the firmware as part of the Arduino IDE. Please have a look at the Arduino IDE documentation.

## Note how to compile the NodeMCU firmware yourself

- Compilation can be done using the Arduino IDE. All libs, which are used by the Sensor.Community firmware have to be installed as well. Only the files 
which are relevant for the Arduino IDE are within the source folder. PlatformIO is not used and there are no PlatformIO files in the source folder. For the Arduino IDE a file with the name platform.local.txt has to be generated and placed at the right position with the following content:

	compiler.c.extra_flags=-fpermissive<br>
	compiler.cpp.extra_flags=-fpermissive<br>
		
- To compile version 4.4 yourself using ESP8266 Library 3.1.1 is necessary.
- Version 5.4 is compiled with Arduino IDE 2.2.1, ESP8266 Library 3.1.2 and the following settings:
 	
 	
- Changing the language is done by editing file intl.h
 
	
	
	select the appropriate include file. For languages other than English, French and German, the language files may not be fully customised.

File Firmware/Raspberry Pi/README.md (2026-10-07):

# [English text below](#raspberry-pi-application-for-dnms)

## Raspberry Pi Anwendung für DNMS

Ab Pi Zero W möglich, Pi Zero 2 W und aufwärts empfohlen.

### Versions Historie:

- Raspberry Pi Firmware Versionen dnms-0.9.27 und dnms-0.9.28
	+ Die Version dnms-0.9.28 enthält  im Unterschied zur Version dnms-0.9.27 einen lokalen Webserver, der Sztatus Informationen anzeigt und über den die Konfiguration des Sensors angesehen und geändert werden kann. Weiterhin bietet die Version dnms-0.9.28 ein HTTP API (POST) für die Daten des 1. Messintervalls.
	+ Unterstützung der Teensy4.0 Firmware DNMS_V6.0.x mit der wesentlichen Änderung, dass die Frequenzgangkorrekturwerte beim Start vom Raspberry Pi  an die Teensy4.0 Firmware übertragen werden. Ist eine ältere Firmware auf dem Tennsy4.0 Board installiert, so wird dies ebenfalls unterstützt d.h. es ist abwärtskompatibel.
	+ Lokaler Webserver der Version dnms-0.9.28 mit Farbe und Logo entsprechend der NodeMCU Version.
	 

 - Neue Raspberry Pi Firmware dnms-0.9.25 mit folgenden Verbesserungen:
	+ Möglichkeit C-Werte abzufragen und weiterzugeben, dazu ist die Teensy 4.0 Version DNMS_V5.9.x Voraussetzung. Abhängig von der Menge der übertragenen Daten zwischen Teensy und Raspberry Pi  wird empfohlen die I²C Übertragungsrate von 100 kHz auf 200 kHz zu erhöhen (`dtparam=i2c_arm=on,i2c_arm_baudrate=20000` in der Datei `/boot/firmware/config.txt`).
	+ In der Konfigurationsdatei dnms.conf können nun wieder die Bool Werte mit true und false angegeben werden.

 - dnms-0.9.23 ersetzt dnms-0.9.21 aufgrund von Fehlern:
	 + Bei der Umwandlung der MAC-Adresse in die ID
	 + Entfernung Testausgabe der Daten auf Konsole bei Sensor.Community Übertragung
	 + Beseitigung Pufferüberlauf für InfluxDB/MQTT Übertragung, wenn keine Übertragung konfiguriert war

 - dnms-0.9.21 ersetzt Version dnms-0.9.20 aufgrund von Fehlern.
 	+ Fehler in der dnms.conf beim Eintrag 'mqtt_transmit'.
 	+ Fehlerhaft gesetzte Prioritäten für die Threads in der dnms.conf ('prio_1st_timer', ... usw).
 	+ Neben der InfluxDB HTTP Übertragung kann nun parallel eine Übertragung der Werte zu einem MQTT Broker erfolgen.

- dnms-0.9.20:

  - Start und Stopp der Messwertausgabe durch ein Steuersignal über eine named pipe. Das Beispiel-Programm, pipe_write, in C  ist beigefügt. Ebenso kann die Steuerung über die Konsole erfolgen, dazu z.B. zwei Variable definieren:

	```
	null="0"
	
	eins="1"
	```

    und zum Starten der Messwertausgabe:

	```
	echo $eins > /tmp/start_stop_dnms
	```

    und zum Stoppen:

	```
	echo $null > /tmp/start_stop_dnms
	```

    Der Name der named pipe kann in der Konfigurationsdatei frei gewählt werden, aber der Pfad ist festgelegt und muss im  Ordner /tmp liegen.

  - Data Logging der Messwertdaten auf der SD-Karte. Für jeden Tag wird eine Datei mit dem Dateinamen 'data_dd.mm.yyyy.csv' erzeugt.  Die Messwertdaten werden beim Data Logging, bei der Ausgabe auf dem Terminal und bei der Übertragung zu einer named pipe im ASCII Format jeweils mit einem Komma getrennt ausgegeben wie im folgenden Beispiel.

	

    Die Konfiguration welche Messwerte (1. Messintervall, 2. Messintervall, A-Werte, Z-Werte und die jeweiligen Terzwerte) übertragen werden, erfolgt in der Konfigurationsdatei dnms.conf für die Ausgabe auf dem Terminal, die named pipe Übertragung und das Data Logging gemeinsam.  

  - Änderung der Eingabe von Bool-Werten in der Konfigurationsdatei dnms.conf: Für false eine '0' und für true eine '1' eingeben. 

 - dnms-0.9.18:
	 - Korrektur eines Fehlers: Wenn nur die Ausgabe auf dem Terminal konfiguriert war, wurden die Werte nicht richtig auf dem Terminal ausgegeben.
	 - Neue Möglichkeit der Weitergabe von Messwerten mittels einer named pipe (oder auch fifo) zu anderen Anwendungen auf dem Raspberry Pi. Der Name der named pipe und der Ort können im Konfigurationsfile (dnms.conf) konfiguriert werden. Weiterhin, ob die Messwerte des 1. Messintervalls, des 2. Messintervalls oder beide mittel der named pipe übertragen werden. Ob die Konfiguration einer named pipe funktioniert kann einfach mit dem Befehl: cat "name der named pipe" überprüft werden. Die Ausgabe im Terminal entspricht dann der direkten Ausgabe auf einem terminal, wenn dies konfiguriert ist bzw. der Ausgabe der Messwerte im File dnms.log. Ein C-Beispielprogramm ist im Ordner "read_named_pipe" unterhalb dnms-0.9.18 beigefügt. Ein Beispiel wie von Python eine named pipe gelesen werden kann ist z.B. bei stackoverflow Frage: Python read named PIPE zu finden: https://stackoverflow.com/questions/39089776/python-read-named-pipe

 - dnms-0.9.16:
	 - MQTT Übertragung (z.Zt. kein TLS). Konfiguration im dnms.conf File. Die Daten werden im InfluxDB Line Protocol Format übertragen (wie bei der direkten InfluxDB Übertragung).
	 - Auswahl des am Teensy4.0 angeschlossenen Mikrofons durch einen Eintrag im dnms.conf File. Damit die Konfiguration durch einen entsprechenden Umschaltbefehl im Teensy4.0 umgesetzt werden kann, ist die Teensy4.0 Version DNMS_V5.3.x Vorraussetzung.
	 - Angabe eines Korrekturwertes für die DNMS Einzahlwerte im dnms.conf File.

 - dnms-0.9.12 erste veröffentliche Version der DNMS Kommunikations Anwendung für den Raspberry Pi.

###  Funktionalität:
  -	Übertragung der DNMS Daten zu Sensor.Community.
  -	Übertragung der DNMS Daten zu einer InfluxDB (V1.8) für unabhängige 2 Messintervalle.
  -	Das zweite Messintervall übertragt die Daten an die InfluxDB ab einem konfigurierbaren Schwellenwert (LAeq). Die Anzahl der Übertragungen (Messintervalle), die nach Überschreitung des Schwellenwertes übertragen werden, kann ebenfalls  konfiguriert werden.
  -	Konfiguration der Werte, die zur InfluxDB übertragen werden, wie LAeq, LZeq und/oder die jeweiligen Terzwerte.
  -	Minimales Messintervall von 125ms konfigurierbar. Sollen Terzwerte übertragen werden, ist dies ab einem Messintervall von 500ms aufwärts möglich.
  -	Konfiguration der Eigenschaften und der Übertragung der Messwerte an Sensor.Community und/oder einer InfluxDB mittels Konfigurationsdatei (dnms.conf).
  - Installation der Anwendung als Service d.h. die DNMS Anwendung läuft im Hintergrund und startet nach einem Neustart des Raspberry Pi automatisch.

### Voraussetzungen:
- Aktuelles Raspberry Pi OS installiert (Bookworm)
- ssh Zugriff auf den Raspberry Pi
- I²C Interface aktiviert (raspi-config) 
- ntp und ntpdate sollten installiert sein und Zeitabgleich durchgeführt sein z.B. mittels der folgenden Befehle:  
  
        sudo apt-get install ntp ntpdate -y
        sudo systemctl stop ntp
        sudo ntpdate de.pool.ntp.org
        sudo systemctl start ntp

### Installation:
 - ssh Verbindung zum Raspberry Pi herstellen.
 - Einen neuen Ordner für die Anwendung unterhalb des aktuellen Benutzers einrichten (z.B. dnms): 
  
        mkdir dnms
 - In den angelegten Ordner wechseln:
  
        cd dnms
 - Die .zip Datei (aktuell dnms-0.9.12.zip) vom PC auf den Raspberry Pi in den neu angelegten Ordner übertragen. Dafür eignet sich z.B. das kostenlose Programm FileZilla sehr gut (Win, Linux, Mac).
 - Überprüfen, ob die .zip Datei (aktuell dnms-0.9.12.zip) nun auf dem Raspberry Pi vorhanden ist mit ls:

	 

 - Entpacken der .zip Datei

		unzip dnms.zip

	mit folgendem Ergebnis:
	
	

- Die Datei dnms_install.sh ausführbar machen:

       chmod +x dnms_install.sh
- Das Installations-Script starten:
       
       sudo ./dnms_install.sh
	Das Installations-Script kann einige Minuten benötigen, bis es komplett durchgelaufen ist, da auch ein kompletter update/upgrade Zyklus durchlaufen wird.
	
	

  Das Installations-Script sollte folgendermaßen enden:
  
	

 - Überprüfung des Status von dnms.service:

       sudo systemctl status dnms.service

	

- Stoppen von dnms.service um zuerst die Konfiguration zu bearbeiten:

		sudo systemctl stop dnms.service

- Editieren der Datei dnms.conf, die die Konfiguration enthält z.B. mit nano:

		nano dnms.conf

	

- Sind alle Einstellungen angepasst in der Datei dnms.conf insbesondere Adresse, Passwort, Datenbankname usw. für den Zugang zu einer InfluxDB, kann dnms.service wieder gestartet werden:

		sudo systemctl restart dnms.service

- Achtung: Nach jeder Änderung der Konfiguration in der Datei dnms.conf, muss dnms.service wieder mit dem obigen Befehl gestartet werden.
- Konnte die Konfiguration erfolgreich gestartet werden, so wird ein Logfile mit dem Namen dnms.log im Installationsordner angelegt, Ausgabe z.B. mit:

	  cat dnms.log

	

- Die Messwerte können auch in die Datei dnms.log geschrieben werden. Dies muss konfiguriert werden (Output to Terminal - Umleitung der Terminalausgabe in die Datei). Es ist aber keine komplette Datenlogger Funktionalität realisiert. Diese rudimentäre Funktionalität dient zur Einrichtung und zum Test der Konfiguration und zur Aufzeichnung von Fehlern. Es lassen sich auch die Übertragungszeiten zur InfluxDB loggen. 

	

------------------------------------------------------------------------

## Raspberry Pi application for DNMS

Possible from Pi Zero W, Pi Zero 2 W and above recommended.

### Version history:

- Raspberry Pi Firmware versions dnms-0.9.27 and dnms-0.9.28
	+ Unlike version dnms-0.9.27, version dnms-0.9.28 includes a local web server which displays status information and allows the sensor’s configuration to be viewed and modified. Furthermore, version dnms-0.9.28 provides an HTTP API (POST) for the data from the first measurement interval.
	+ Support for the Teensy 4.0 firmware DNMS_V6.0.x, with the key change being that the frequency response correction values are transferred from the Raspberry Pi to the Teensy 4.0 firmware at start-up. If an older version of the firmware is installed on the Teensy 4.0 board, this is also supported; in other words, it is backwards compatible.
	+ Local web server, version dnms-0.9.28, with a colour scheme and logo matching the NodeMCU version.
	 

 - New Raspberry Pi firmware dnms-0.9.25 with the following improvements:
	+ Ability to query and transmit C-values; this requires Teensy 4.0 version DNMS_V5.9.x. Depending on the amount of data transferred between the Teensy and the Raspberry Pi, it is recommended to increase the I²C clock from 100 kHz to 200 kHz (set `dtparam=i2c_arm=on,i2c_arm_baudrate=20000` in the file `/boot/firmware/config.txt`).
	+ In the configuration file dnms.conf, the Boolean values can now once again be specified as true and false.

 - dnms-0.9.23 replaces version dnms-0.9.21 due to bugs:
	 + MAC address to ID conversion was incorrect in some circumstances
	 + Removal of test output on console for transmission to Sensor.Community
	 + Fix for buffer overflow on InfluxDB/MQTT transfers when one transfer is configured
 
  - dnms-0.9.21 replaces version dnms-0.9.20 due to bugs.
 	+ Error in dnms.conf with entry 'mqtt_transmit'.
 	+ Incorrectly set priorities for the threads in dnms.conf ('prio_1st_timer', ... etc).
 	+ In addition to the InfluxDB HTTP transfer, the values can now be transferred to an MQTT broker in parallel.

- dnms-0.9.20:

	 - Start and stop the output of measurements by a control signal via a named pipe. An example program in C, pipe_write, is included. The control can also be done from the console, e.g. by defining two variables:

		```
		null="0"
		
		eins="1"
		```

	   and to start the output of the measured values:

		```
		echo $eins > /tmp/start_stop_dnms
		```

	    and to stop the output of the measured values:

		```
		echo $null > /tmp/start_stop_dnms
		```

	   The name of the named pipe can be freely chosen in the configuration file, but the path is fixed and must be in the /tmp folder.

  - Data logging of the measurement data on the SD card. For each day a file with the name 'data_dd.mm.yyyy.csv' is created. The measurement data is output in ASCII format, separated by commas, during data logging, when output to the terminal and when transferred to a named pipe, as in the following example.

	

    The configuration of which measurement values (1st measurement interval, 2nd measurement interval, A-values, Z-values and the respective third octave values) are transmitted is made together in the configuration file 'dnms.conf' for output on the terminal, for named pipe transmission and data logging.

  - Changed the entry for bool values in the dnms.conf configuration file: Enter '0' for false and '1' for true.
	 
- dnms-0.9.18:
	 - Bug fix: If only output to terminal was configured, the values were not output correctly to the terminal.
	 - New way to pass measurements to other applications on the Raspberry Pi using a named pipe (or fifo). The name of the named pipe and the location can be configured in the configuration file (dnms.conf). You can also specify whether the named pipe should send the readings from the 1st interval, the 2nd interval or both. You can easily check if the configuration of a named pipe works with the command: cat "name of the named pipe". The output in the terminal then corresponds to the direct output on a terminal, if this is configured, or to the output of the readings in the file dnms.log. An example C program is included in the folder "read_named_pipe" below dnms-0.9.18. An example of how to read a named pipe from Python can be found in the stackoverflow question: Python read named PIPE: https://stackoverflow.com/questions/39089776/python-read-named-pipe

 - dnms-0.9.16:
	 - MQTT transmission (currently no TLS). Configuration in the dnms.conf file. The data is transmitted in InfluxDB Line Protocol format (as with direct InfluxDB transmission).
	 - Selection of the microphone connected to the Teensy4.0 through an entry in the dnms.conf file. On Teensy4.0 the version DNMS_V5.3.x is required to use the microphone switch command.
	 - Specify a correction value for the DNMS single values (does not apply to 1/3 octave values) in the dnms.conf file.
	
 - dnms-0.9.12 first released version of the DNMS communication application for the Raspberry Pi.

###  Functionality:
  -	Transfer of DNMS data to Sensor.Community.
  -	Transfer of DNMS data to an InfluxDB (V1.8) for 2 independent measurement intervals.
  -	The second measurement interval transmits data to the InfluxDB when a configurable threshold (LAeq) is exceeded. The number of transmissions (measurement intervals) to be sent when the threshold is exceeded can also be configured.
    -Configuration of the values to be transferred to InfluxDB, such as LAeq, LZeq and/or their respective 1/3-octave values.
  -	Minimum measuring interval configurable from 125ms. If 1/3-octave values are to be transmitted, this is possible from a measuring interval of 500ms upwards.
    -Configuration of properties and transmission of readings to Sensor.Community and/or an InfluxDB using a configuration file (dnms.conf).
  - Installation of the application as a service, i.e. the DNMS application runs in the background and starts automatically when the Raspberry Pi is rebooted.

### Prerequisite:
- Current Raspberry Pi OS installed (Bookworm)
- ssh access to the Raspberry Pi
- I²C interface enabled (raspi-config)
- ntp and ntpdate should be installed, which can be done using the following commands:  
  
        sudo apt-get install ntp ntpdate -y
        sudo systemctl stop ntp
        sudo ntpdate de.pool.ntp.org
        sudo systemctl start ntp
	
	Instead of using de.pool.ntp.org, use the appropriate pool for your country.
	
### Installation:
- Make an ssh connection to the Raspberry Pi.
 - Create a new folder for the application under the current user (e.g. dnms):
  
        mkdir dnms
- Switch to the created folder:
  
        cd dnms
- Copy the .zip file (currently dnms-0.9.12.zip) from your PC to the newly created folder on the Raspberry Pi. You can use the free program FileZilla (Win, Linux, Mac) to do this.
 - Use ls to check if the .zip file (currently dnms-0.9.12.zip) is now present on the Raspberry Pi:

	 

- Unzip the .zip file

		unzip dnms.zip

	with the following result:
	
	

- Make the dnms_install.sh file executable:

       chmod +x dnms_install.sh
- Launch the installation script:
       
       sudo ./dnms_install.sh

	The installation script may take a few minutes to complete as it will also perform a full update/upgrade cycle.
	
	

	The installation script should end as follows:  

	

- Check the status of dnms.service:

       sudo systemctl status dnms.service

	

- Stop the dnms.service to edit the configuration first:

		sudo systemctl stop dnms.service

- Edit the dnms.conf file that contains the configuration, e.g. with nano:

		nano dnms.conf

	

- Once all the settings in the dnms.conf file have been adjusted, in particular the address, password, database name, etc. for accessing an InfluxDB, the dnms.service can be restarted:

		sudo systemctl restart dnms.service

- Attention: After each change of the configuration in the dnms.conf file, the dnms.service must be restarted with the above command.
- If the configuration was started successfully, a log file with the name dnms.log is created in the installation folder:

		cat dnms.log

	

- The readings can also be written to the dnms.log file. This must be configured (output to terminal - redirect terminal output to the file). However, no complete data logger functionality is implemented. This rudimentary functionality is used to set up and test the configuration and to record errors. It is also possible to log the transfer times to InfluxDB.



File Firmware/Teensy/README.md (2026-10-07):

# [English text below](#dnms-firmware-for-teensy36-and-teensy40)

## DNMS Firmware für Teensy3.6 und Teensy4.0

## Teensy4.0

### Versions Historie Teensy4.0:

 - DNMS_V1.0.4 und DNMS_V1.0.5 - erste Versionen

 - DNMS_V2.0.4 und DNMS_V2.0.5 - Version 2 der Firmware basierend auf 32-Bit Floating Point Verarbeitung

- aktuelle V2 Versionen:
	- DNMS_V2.2.4 und DNMS_V2.2.5 - Änderung der Zeitgewichtung von I (Impuls) auf F (Fast 125ms)
	
- aktuelle V3 Version:
	- DNMS_V3.4.4 - Ausgabe Frequenzspektrum in Terzen von 20Hz - 20000Hz

- aktuelle V4 Version:
	- DNMS_V4.4.4 - 2. Messintervall mit Schwellenangabe für Lärmereignisse um diese Daten zu einer InfluxDB zu senden

- aktuelle V5 Versionen:
	- DNMS_V5.9.x  für IM72D128 und ICS-43434 Mikrofone mit dem Unterschied zur Version DNMS_V5.8.x, dass zusätzlich C-Werte berechnet und abgerufen werden können. Wenn keine C-Werte benötigt werden, ist die Version  DNMS_V5.8.x weiterhin aktuell. Eine Version mit Abfrage der C-Werte ist die Raspberry Pi Version dnms-0.9.25. Eine Abfrage der C-Werte für die NodeMCU Firmware ist z.Zt. nicht geplant.

	- DNMS_V5.8.x  für IM72D128 und ICS-43434 Mikrofone mit:
		+ zusätzlicher Auswahl der Frequenzgangkorrektur für das DLR Gehäuse mit IM72D128 Mikrofon, sowie Auswahl ohne Frequenzgangkorrektur für IM72D128 und ICS-43434 Mikrofon.
		+ Kleine Korrekturen im Source Code, so dass in der Arduino IDE Version 2.3.8 die Übersetzung ohne Warnungen erfolgt. Dies betrifft auch die Library dnms_audio_lib-master.zip, deshalb beim Übersetzen die veränderte Library einbinden.
		+ Korrekturen an der I²C Übertragung, Änderung der Werte für die Glitch Filter von SDA und SCL im Slave Modus. Diese Korrekturen befinden sich in der Library  teensy4_i2c-master.zip, deshalb beim Übersetzen die veränderte Library einbinden.

- Testprogramm für Teensy4.0 Board und angeschlossenem Mikrofon ICS-43434:  DNMS_Vt.8.4 und für Mikrofon IM72D128: DNMS_Vt.8.6, mit verbesserter Frequenzgangkorrektur.

- DNMS_V6.0.x für IM72D128 und ICS-43434 Mikrofone.   
 	+ Komplettes Refactoring der Firmware mit Optimierung der Verwendung von Double (nur noch wenn absolut notwendig), dadurch erfordert die Berechnung der Leq Werte deutlich weniger Ressourcen.
 	+  Fehlerbeseitigung einer Race-Condition zwischen 1. und 2. Messintervall.
 	+  Die Parameterwerte zur Frequenzgangkorrektur sind nicht mehr in der Firmware fest abgespeichert. Es werden für jeden Mikrofontyp 31 Korrekturwerte vom Kommunikationsprozessor an die Teensy Firmware beim Start übertragen, daraus berechnet die Teensy Firmware die Korrekturwerte für den gewählten Mikrofontyp für die FFT Bins.
 	+  Änderung der Filterparameter für die I²C Kommunikation zwischen Teensy und Kommunikationsprozessor, dadurch stabilere I²C Übertragung. Beim Kompilieren der Firmware ist es deshalb notwendig die angepasste teensy4_i2c-master Library zu benutzen (zu finden unter Firmware/Teensy/Teensy4.0/).

## Teensy3.6

### Versions Historie Teensy3.6:

  - DNMS_V1.0.0 und DNMS_V1.0.1 - erste Versionen

  - DNMS_V1.1.0 und DNMS_V1.1.1 - Änderung I²C Bibliothek, es wird nun die i2c_t3 Bibliothek (https://github.com/nox771/i2c_t3) eingesetzt, die in der Kommunikation stabiler ist

  - DNMS_V2.0.0 und DNMS_V2.0.1 - Version 2 der Firmware basierend auf 32-Bit Floating Point Verarbeitung

- DNMS_V2.4.0 und DNMS_2.4.1 - Änderung der Zeitgewichtung von I (Impuls) auf F (Fast 125ms)

- aktuelle Versionen:
	- DNMS_V2.5.0 und DNMS_2.5.1 - Korrektur eines Fehlers bei der Initialisierung

### Testprogramm für Teensy3.6 Board und angeschlossenem Mikrofon: DNMS_Vt.2.0

## Versionsbezeichnung:
<br>

## Firmware auf das Teensy Board schreiben (flashen)

Die übersetzten lauffähigen Programme besitzen die Endung .hex z.B. DNMS_V4.4.4.ino.hex. Sie müssen nur noch auf das Teensy Board geschrieben (geflasht) werden. 

### ohne Arduino IDE

Es ist dafür nicht notwendig die Arduino IDE zu installieren und/oder zu benutzen. Es gibt dafür vom Entwickler der Teensy Boards die Anwendung "Teensy Loader" für verschiedene Betriebssyteme mit grafischer Oberfläche. Ebenso ist eine Version für die Kommandozeile verfügbar. Der Link zu dieser Anwendung ist: https://www.pjrc.com/teensy/loader.html. Das weitere Vorgehen zum Download der Anwendung und zum Flashen der Teensy Boards ist dort beschrieben.



### mit Arduino IDE

Ist die Arduino IDE installiert, erfolgt das Schreiben der Firmware auf das Teensy Board direkt im Anschluss an die Übersetzung der Firmware aus der Arduino IDE heraus (siehe Arduino IDE Beschreibung).

------------------------------------------------------------------------

## DNMS firmware for Teensy3.6 and Teensy4.0

## Teensy4.0
 
### Version history Teensy4.0:

  - DNMS_V1.0.4 and DNMS_V1.0.5 - initial versions

  - DNMS_V2.0.4 and DNMS_V2.0.5 - firmware version 2 based on 32-Bit floating point processing

- current V2 versions:
	- DNMS_V2.2.4 and DNMS_V2.2.5 - Change of time weighting from I (Impuls) to F (Fast 125ms)
	
- current V3 version:
	- DNMS_V3.4.4 - frequency spectrum 1/3 octaves from 20Hz - 20000Hz

- current V4 version:
	- DNMS_V4.4.4 - 2nd measurement interval with configurable threshold for transmitting the additional data to an InfluxDB

- current V5 versions:
	- DNMS_V5.9.x  for IM72D128 and ICS-43434 microphones; the difference from version DNMS_V5.8.x is that C-values can now also be calculated and retrieved. If C-values are not required, version  DNMS_V5.8.x remains the current version. One version that retrieves C-values is the Raspberry Pi version dnms-0.9.25. There are currently no plans to retrieve C-values for the NodeMCU firmware.

	- DNMS_V5.8.x  for IM72D128 and ICS-43434 microphones with:
		+ additional selection of frequency response correction for the DLR housing with IM72D128 microphone, as well as a selection without frequency response correction for IM72D128 and ICS-43434 microphones
		+ minor corrections have been made to the source code so that the code compiles without warnings in Arduino IDE version 2.3.8. This also applies to the dnms_audio_lib-master.zip library, so please include the updated library when compiling.
		+ corrections to the I²C transmission; changes to the values for the SDA and SCL glitch filters in slave mode. These corrections are contained in the library teensy4_i2c-master.zip, so be sure to include the updated library when compiling.	
	- Test program for Teensy 4.0 board and connected ICS-43434 microphone: DNMS_Vt.8.4 and
test program for IM72D128 microphone: DNMS_Vt.8.6, both with improved microphone frequency correction

- Test programme for the Teensy 4.0 board and connected ICS-43434 microphone: DNMS_Vt.8.4; and for the IM72D128 microphone: DNMS_Vt.8.6, with improved frequency response correction.

- DNMS_V6.0.x for IM72D128 and ICS-43434 microphones.   
 	+ Complete refactoring of the firmware, optimising the use of `double` (now only used when absolutely necessary), meaning that the calculation of Leq values requires significantly fewer resources.
 	+  Resolving a race condition between the first and second measurement intervals.
 	+  The parameter values for frequency response correction are no longer hard-coded in the firmware. For each microphone type, 31 correction values are transferred from the communication processor to the Teensy firmware at start-up; the Teensy firmware then uses these to calculate the correction values for the selected microphone type for the FFT bins.
 	+  Changes to the filter parameters for I²C communication between the Teensy and the communication processor, resulting in more stable I²C transmission. When compiling the firmware, it is therefore necessary to use the modified teensy4_i2c-master library (located in Firmware/Teensy/Teensy4.0/).

## Teensy3.6

### Version history Teensy3.6:

  - DNMS_V1.0.0 and DNMS_V1.0.1 - initial versions

  - DNMS_V1.1.0 and DNMS_V1.1.1 - change of I²C library, now the i2c_t3 lib (https://github.com/nox771/i2c_t3) is used,  which is more stable

  - DNMS_V2.0.0 and DNMS_V2.0.1 - firmware version 2 based on 32-Bit floating point processing 
 
 - DNMS_V2.4.0 and DNMS_V2.4.1 - change of time weighting from I (Impuls) to F (Fast 125ms)

- current versions:
	- DNMS_V2.5.0 and DNMS_V2.5.1 - correction of a bug at startup

## Naming convention of the versions:

<br>

## How to flash Teensy boards with the firmware

The compiled and executable firmware are having the filename extension .hex e.g. DNMS_V4.4.4.ino.hex. The only thing to do is to flash the Teensy board with the choosen firmware.

### without Arduino IDE

To flash the Teensy board it is not necessary to install the Arduino IDE. There is a standalone application from the Teensy developer called "Teensy Loader" doing this job. It is available for different operating systems. A command line version exsits as well. The link to this application is: https://www.pjrc.com/teensy/loader.html. How to download and use the application is described there.



### with Arduino IDE

If you have the Arduino IDE installed, then flashing the Teensy board is done from within the Arduino IDE after compiling the firmware. Have a look at the Arduino IDE documentation.

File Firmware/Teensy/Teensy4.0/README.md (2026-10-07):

# [English text below](#dnms-firmware-for-teensy40)

# DNMS Firmware für Teensy4.0

## Anmerkung zum selbst Übersetzen der DNMS Firmware 

### alle Versionen

Um die Firmware selbst zu übersetzen ist neben der Installation der Arduino IDE (Version 1.8.13 oder höher) und der Teensyduino Erweiterung (Version 1.53 oder höher) (PJRC Link: https://www.pjrc.com/teensy/teensyduino.html) noch folgendes zu beachten:
- Anstelle der Wire.h Bibliothek kommt für die I²C Kommunikation die Bibliothek teensy4_i2c zum Einsatz. Diese kann von GitHub herruntergeladen werden (https://github.com/Richard-Gemmell/teensy4_i2c ). Dann die teensy4_i2c Bibliothek in der Arduino IDE installieren. <mark>Unter Firmware/Teensy/Teensy4.0/ ist die benötigte Bibliothek auch hier als File teensy4_i2c-master.zip vorhanden.</mark> In der hier vorhandenen Version sind die nachfolgend beschriebenen Ergänzungen, um die Glitch-Filter für die I²C Kommunikation zu aktivieren, schon eingefügt.
- I²C Glitch-Filter aktivieren in der teensy4_i2c Lib -- dies ist unbedingt notwendig!  <br>
Bei der hier vorhandenen Version sind diese Änderungen schon eingefügt! <br> <br>
In der teensy4_i2c-master lib unter src->imx_rt1060 im File imx_rt1060_i2c_driver.cpp die Funktion IMX_RT1060_I2CSlave::listen(uint32_t samr, uint32_t address_config) wie folgt zu ersetzen:
	
	```
	void IMX_RT1060_I2CSlave::listen(uint32_t samr, uint32_t address_config) {
	    // Make sure slave mode is disabled before configuring it.
	    stop_listening();
	
	    // Halt and reset Slave Mode if it's running
	    port->SCR = (LPI2C_SCR_RST | LPI2C_SCR_RRF | LPI2C_SCR_RTF);
	    port->SCR = 0;
	
	    initialise_common(config, pad_control_config);
	
	    // Set the Slave Address
	    port->SAMR = samr;
	
	    // Enable clock stretching
	//    port->SCFGR1 = (address_config | LPI2C_SCFGR1_TXDSTALL | LPI2C_SCFGR1_RXSTALL);
	    port->SCFGR1 = address_config;
	//    port->SCFGR2 = (LPI2C_SCFGR2_DATAVD(3) | LPI2C_SCFGR2_FILTSDA(12) | LPI2C_SCFGR2_FILTSCL(12));
	    port->SCFGR2 = (LPI2C_SCFGR2_DATAVD(3) | LPI2C_SCFGR2_FILTSDA(6) | LPI2C_SCFGR2_FILTSCL(6));    
	
	    // Set up interrupts
	    attachInterruptVector(config.irq, isr);
	    port->SIER = (LPI2C_SIER_RSIE | LPI2C_SIER_SDIE | LPI2C_SIER_TDIE | LPI2C_SIER_RDIE);
	    NVIC_ENABLE_IRQ(config.irq);
	
	    // Enable Slave Mode
	    port->SCR = (LPI2C_SCR_SEN | LPI2C_SCR_FILTEN);
	}
	
	```

- In der Teensyduino Audio Bibliothek nun alle Verweise auf die Wire.h Bibliothek durch Verweise auf i2c_driver und i2c_driver_wire ersetzen d.h alle Vorkommnisse von "#include Wire.h" durch "#include <i2c_driver.h>" und "#include <i2c_driver_wire.h>" ersetzen. Der Pfad zur Teensyduino Audio Bibliothek hängt vom Betriebssystem und der Installation ab, bei Windows z.B. unter C:\Program Files (x86)\Arduino\hardware\teensy\avr\libraries\Audio oder Linux z.B unter /home/user/Arduino-SW/arduino-1.8.3/hardware/teensy/avr/libraries/Audio/.
In der Audio Bibliothek sind einige Dateien mit dem Namen "control_xxx.cpp" vorhanden. In all diesen Dateien den Verweis "#include Wire.h" durch "#include <i2c_driver.h>" und "#include <i2c_driver_wire.h>" ersetzen.
- Beim Übersetzen der Versionen DNMS_V1.x.5 und DNMS_V2.x.5 ist es notwendig in der Arduino IDE unter Werkzeuge den USB Type von "Serial" auf "Audio" oder "Serial + MIDI + Audio" oder "Serial +MIDIx16 + Audio" zu setzen.
- 
	<br>

### ab Version 2

- Den unter Firmware vorhanden Zip-File "dnms_audio_lib-master.zip" herunterladen, entpacken und in den Arduino Library Ordner als Lib einfügen.

------------------------------------------------------------------------

# DNMS Firmware for Teensy4.0

## Note how to compile the firmware yourself

### all versions

To compile the firmware by yourself you have to install the Arduino IDE (Version 1.8.13 and above) and the Teensyduino add on (Version 1.53 and above) (PJRC Link: https://www.pjrc.com/teensy/teensyduino.html). Besides that please see below:
- Instead of Wire.h lib the I²C lib teensy4_i2c is used. Download teensy4_i2c lib from GitHub (https://github.com/Richard-Gemmell/teensy4_i2c ) and install it in the Arduino IDE. <mark>Under Firmware/Teensy/Teensy4.0/ you will find the lib as file teensy4_i2c-master.zip.</mark> In this version here the necessary changes described later have been done to activate a glitch filter for I²C communication.
- Activation of I²C glitch filter in teensy4_i2c lib -- this is absolutely necessary! <br>
These changes are done in the version here! <br><br>
You have to change in the teensy4_i2c-master lib under src->imx_rt1060 in the file imx_rt1060_i2c_driver.cpp the function IMX_RT1060_I2CSlave::listen(uint32_t samr, uint32_t address_config) as follows:

	```
	void IMX_RT1060_I2CSlave::listen(uint32_t samr, uint32_t address_config) {
	    // Make sure slave mode is disabled before configuring it.
	    stop_listening();
	
	    // Halt and reset Slave Mode if it's running
	    port->SCR = (LPI2C_SCR_RST | LPI2C_SCR_RRF | LPI2C_SCR_RTF);
	    port->SCR = 0;
	
	    initialise_common(config, pad_control_config);
	
	    // Set the Slave Address
	    port->SAMR = samr;
	
	    // Enable clock stretching
	//    port->SCFGR1 = (address_config | LPI2C_SCFGR1_TXDSTALL | LPI2C_SCFGR1_RXSTALL);
	    port->SCFGR1 = address_config;
	//    port->SCFGR2 = (LPI2C_SCFGR2_DATAVD(3) | LPI2C_SCFGR2_FILTSDA(12) | LPI2C_SCFGR2_FILTSCL(12));
	    port->SCFGR2 = (LPI2C_SCFGR2_DATAVD(3) | LPI2C_SCFGR2_FILTSDA(6) | LPI2C_SCFGR2_FILTSCL(6));    
	
	    // Set up interrupts
	    attachInterruptVector(config.irq, isr);
	    port->SIER = (LPI2C_SIER_RSIE | LPI2C_SIER_SDIE | LPI2C_SIER_TDIE | LPI2C_SIER_RDIE);
	    NVIC_ENABLE_IRQ(config.irq);
	
	    // Enable Slave Mode
	    port->SCR = (LPI2C_SCR_SEN | LPI2C_SCR_FILTEN);
	}
	
	```

- In the Teensyduino Audio lib you have to change all "#include Wire.h" to "#include <i2c_driver.h>" and "#include <i2c_driver_wire.h>". The path to the Teensyduino Audio lib depends on your Operating System and your installation. On Windows e.g. C:\Program Files (x86)\Arduino\hardware\teensy\avr\libraries\Audio oder Linux e.g. /home/user/Arduino-SW/arduino-1.8.3/hardware/teensy/avr/libraries/Audio/. In that directory you will find several files named: control_xxx.cpp. In all those files change "#include Wire.h" to "#include <i2c_driver.h>" and "#include <i2c_driver_wire.h>".
- If you compile versions DNMS_V1.x.5 or DNMS_V2.x.5 you have to change the USB Type in the Arduino IDE under Tools from "Serial" to "Audio" or "Serial + MIDI + Audio" or "Serial +MIDIx16 + Audio".
<br> 

### from version 2 on

- In addition you have to download the zip-file "dnms_audio_lib-master.zip" from Firmware, unzip it and place it your Arduino library folder.

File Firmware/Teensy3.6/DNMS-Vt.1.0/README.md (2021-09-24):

# Testprogramm für Teensy 3.6 und ICS-43434

## Flashen des Teensy 3.6 mit dem Testprogramm

Für die Teensy Boards existiert ein standalone Flash-Programm - der Teensy Loader - sowohl mit grafischer Oberfläche als auch als Version für die Kommandozeile jeweils für Windows, Linux und Mac. Der Download des Teensy Loader ist unter: https://www.pjrc.com/teensy/loader.html möglich. Weiterhin ist dort im Detail der Flash Vorgang unter den verschiedenen Betriebssystemen beschrieben.

## Funktion und Ausgabe des Testprogramms

Nach dem Flashen oder nach Power Up startet das Testprogramm und berechnet aus den Werten des angeschlossenen Mikrofons den LAeq, LAmin und LAmax. Diese drei Werte werden dann alle 10 Sekunden über die USB Schnittstelle an ein Terminalprogramm ausgegeben (Serieller Monitor der Arduino IDE od. PuTTY mit 115200 baud). Die Ausgabe sollte wie auf dem folgenden Bild aussehen:

------------------------------------------------------------------------

# Test program for Teensy 3.6 and ICS-43434

## How to flash the Teensy 3.6 with the test program

For all Teensy boards a flash tool exists - the Teensy Loader. There is a version with a graphical user interface and also a commad line version for Windows, Linux and Mac. You can download the tool from: https://www.pjrc.com/teensy/loader.html. The details how to flash the Teensy board under the various operating systems are given on that page.

## Functions and output of the test program

After flashing or after power up the test program starts caculatiing LAeq, LAmin and LAmax based on the values from the connected microphone. These three values will be written over USB to a terminal program (serial monitor of the Arduino IDE or Putty with a baud rate of 115200). The following picture shows how the output on the terminal should look like:

------------------------------------------------------------------------

<br>

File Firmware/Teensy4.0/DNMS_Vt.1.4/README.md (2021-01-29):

# Testprogramm für Teensy 4.0 und ICS-43434

## Flashen des Teensy 4.0 mit dem Testprogramm

Für die Teensy Boards existiert ein standalone Flash-Programm - der Teensy Loader - sowohl mit grafischer Oberfläche als auch als Version für die Kommandozeile jeweils für Windows, Linux und Mac. Der Download des Teensy Loader ist unter: https://www.pjrc.com/teensy/loader.html möglich. Weiterhin ist dort im Detail der Flash Vorgang unter den verschiedenen Betriebssystemen beschrieben.

## Funktion und Ausgabe des Testprogramms

Nach dem Flashen oder nach Power Up startet das Testprogramm und berechnet aus den Werten des angeschlossenen Mikrofons den LAeq, LAmin und LAmax. Diese drei Werte werden dann alle 10 Sekunden über die USB Schnittstelle an ein Terminalprogramm ausgegeben (Serieller Monitor der Arduino IDE od. PuTTY mit 115200 baud). Die interne rote LED des Teensy Boards blinkt (245ms an, 245 ms aus). Die Ausgabe sollte wie auf dem folgenden Bild aussehen:

------------------------------------------------------------------------

# Test program for Teensy 4.0 and ICS-43434

## How to flash the Teensy 4.0 with the test program

For all Teensy boards a flash tool exists - the Teensy Loader. There is a version with a graphical user interface and also a commad line version for Windows, Linux and Mac. You can download the tool from: https://www.pjrc.com/teensy/loader.html. The details how to flash the Teensy board under the various operating systems are given on that page.

## Functions and output of the test program

After flashing or after power up the test program starts caculatiing LAeq, LAmin and LAmax based on the values from the connected microphone. These three values will be written over USB to a terminal program (serial monitor of the Arduino IDE or Putty with a baud rate of 115200). The internal red LED of the Teensy board is flashing (245ms on, 245ms off). The following picture shows how the output on the terminal should look like:

------------------------------------------------------------------------

<br>

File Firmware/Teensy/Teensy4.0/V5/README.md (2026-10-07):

# [English text below](#dnms-firmware-teensy40-v5-english)

# DNMS Firmware Teensy4.0 V5

## V5 realisiert neben der Funktionalität von V4 zusätzlich die Berechnung und Ausgabe von Z-Werten

### Versions Historie:

Bitte beachten: Wird das IM72D128 Mikrofon eingesetzt, muss auf dem Teensy4.0 Board die Firmware DNMS_V5.2.6 oder DNMS_V5.5.x und höher geflasht sein. Die Firmware DNMS_V5.5.x kann mit dem IM72D128 benutzt werden, wenn auf dem Kommunikationsprozessor (NodeMCU oder Raspiberry Pi) eine Firmware vorhanden ist, die die Umschaltung zwischen den Mikrofonen ICS-43434 und IM72D128 erlaubt. Wird z.B. auf der NodeMCU eine ältere Firmware oder die Standard Firmware von Sensor.Community eingesetzt, so muss auf dem Teensy4.0 Board die DNMS_V5.2.6 Firmware geflasht sein.

- DNMS_V6.0.x für IM72D128 und ICS-43434 Mikrofone.   
 	+ Komplettes Refactoring der Firmware mit Optimierung der Verwendung von Double (nur noch wenn absolut notwendig), dadurch erfordert die Berechnung der Leq Werte deutlich weniger Ressourcen.
 	+  Fehlerbeseitigung einer Race-Condition zwischen 1. und 2. Messintervall.
 	+  Die Parameterwerte zur Frequenzgangkorrektur sind nicht mehr in der Firmware fest abgespeichert. Es werden für jeden Mikrofontyp 31 Korrekturwerte vom Kommunikationsprozessor an die Teensy Firmware beim Start übertragen, daraus berechnet die Teensy Firmware die Korrekturwerte für den gewählten Mikrofontyp für die FFT Bins.
 	+  Änderung der Filterparameter für die I²C Kommunikation zwischen Teensy und Kommunikationsprozessor, dadurch stabilere I²C Übertragung. Beim Kompilieren der Firmware ist es deshalb notwendig die angepasste teensy4_i2c-master Library zu benutzen (zu finden unter Firmware/Teensy/Teensy4.0/).
 
  	<mark>Achtung: Um diese Firmware zu nutzen, ist die Firmware Version airrohr-DNMS-6.0.0 (oder höher) beim NodeMCU Kommunikationsprozessor oder beim Raspberry Pi  die Version dnms-0.9.27 bzw. dnms-0.9.28 (oder höher) notwendig. Nur diese Versionen haben die Parameter zur Frequenzgangkorrektur abgespeichert und übertragen diese Werte beim Start.<mark>

- DNMS_V5.9.x  für IM72D128 und ICS-43434 Mikrofone mit dem Unterschied zur Version DNMS_V5.8.x, dass zusätzlich C-Werte berechnet und abgerufen werden können. Wenn keine C-Werte benötigt werden, ist die Version  DNMS_V5.8.x weiterhin aktuell. Eine Version mit Abfrage der C-Werte ist die Raspberry Pi Version dnms-0.9.25. Eine Abfrage der C-Werte für die NodeMCU Firmware ist z.Zt. nicht geplant.

- DNMS_V5.8.x  für IM72D128 und ICS-43434 Mikrofone mit:
	+ zusätzlicher Auswahl der Frequenzgangkorrektur für das DLR Gehäuse mit IM72D128 Mikrofon, sowie Auswahl ohne Frequenzgangkorrektur für IM72D128 und ICS-43434 Mikrofon.
	+ Kleine Korrekturen im Source Code, so dass in der Arduino IDE Version 2.3.8 die Übersetzung ohne Warnungen erfolgt. Dies betrifft auch die Library dnms_audio_lib-master.zip, deshalb beim Übersetzen die veränderte Library einbinden.
	+ Korrekturen an der I²C Übertragung, Änderung der Werte für die Glitch Filter von SDA und SCL im Slave Modus. Diese Korrekturen befinden sich in der Library  teensy4_i2c-master.zip, deshalb beim Übersetzen die veränderte Library einbinden.

- DNMS_V5.5.x  für IM72D128 und ICS-43434 Mikrofone mit:
	+ Verbesserter Korrektur des Frequenzgangs für IM72D128 Mikrofon und ICS-43434 Mikrofon. Dies verbessert auch die Terzwerte des Spektrums.

- DNMS_V5.4.x - für ICS-43434 und IM72D128 Mikrofon
	+ Ersetzt DNMS_V5.3.x da in der Version DNMS_V5.3.x Fehler in der Berechnung der Terzwerte waren. DNMS_V5.3.x bitte ersetzen mit DNMS_V5.4.x 

- DNMS_V5.3.x - für ICS-43434 und IM72D128 Mikrofon
	 - Zusammenführung der bisher getrennten Versionen für die beiden Mikrofone ICS-43434 und IM72D128 in einer Teensy4.0 Firmware. Die Auswahl des Mikrofons erfolgt über die Konfiguration in der NodeMCU bzw. im Raspberry Pi und wird mittels Umschaltbefehl an die Teensy4.0 Firmware übertragen. Wird kein Umschaltbefehl übertragen ist standardmäßig das ICS-43434 ausgewählt d.h. auch ältere NodeMCU Firmware unterstützt die Version DNMS_V5.3.x mit ICS-43434 Mikrofon.
	 - Abhänging vom ausgewählten Mikrofon erfolgt das Blinken der roten LED auf dem Teensy4.0 Board mit unterschiedlicher Frequenz:	
ICS-43434: im Wechsel 100ms an und 100ms aus	
IM72D128: im Wechsel 500ms an und 500ms aus

- DNMS_V5.2.4 - für das ICS-43434 Mikrofon
- DNMS_V5.2.6 - für das IM72D128 Mikrofon	
	
	Bitte beachten: Werden nicht zusammengehörige Versionen von Mikrofon und Teensy Firmware benutzt, so ergeben sich falsch Lärmwerte!

### Voraussetzungen

- Benutzung der Firmware Versionen NRZ-2020-134-DNMS-5.2 auf der NodeMCU damit die Z-Werte abgefragt werden bzw. konfiguriert werden. Für den Raspberry Pi ist eine entsprechende Version in Vorbereitung. Die Werte des 2. Messintervalls, die Terzwerte und alle Z-Werte werden nicht an Sensor.Community übertragen.
- Benutzung einer InfluxDB oder eigenen Anwendung um die Werte des 2. Messintervalls, die Terzwerte und die Z-Werte abzuspeichern.

------------------------------------------------------------------------

# DNMS Firmware Teensy4.0 V5 English

## V5 realizes besides the functionality of V4 the calculation and output of Z-values 

### Version history:

Please note: If the IM72D128 microphone is used, the firmware DNMS_V5.2.6 or DNMS_V5.5.x and higher must be flashed on the Teensy4.0 board. The firmware DNMS_V5.5.x can be used with the IM72D128 if there is firmware on the communications processor (NodeMCU or Raspiberry Pi) that allows switching between the ICS-43434 and IM72D128 microphones. For example, if older firmware or the standard firmware from Sensor.Community is used on the NodeMCU, the DNMS_V5.2.6 firmware must be flashed on the Teensy4.0 board.

- DNMS_V6.0.x for IM72D128 and ICS-43434 microphones.   
 	+ Complete refactoring of the firmware, optimising the use of `double` (now only used when absolutely necessary), meaning that the calculation of Leq values requires significantly fewer resources.
 	+  Resolving a race condition between the first and second measurement intervals.
 	+  The parameter values for frequency response correction are no longer hard-coded in the firmware. For each microphone type, 31 correction values are transferred from the communication processor to the Teensy firmware at start-up; the Teensy firmware then uses these to calculate the correction values for the selected microphone type for the FFT bins.
 	+  Changes to the filter parameters for I²C communication between the Teensy and the communication processor, resulting in more stable I²C transmission. When compiling the firmware, it is therefore necessary to use the modified teensy4_i2c-master library (located in Firmware/Teensy/Teensy4.0/).
 
 	<mark>Please note: To use this firmware, the NodeMCU communication processor must be running firmware version airrohr-DNMS-6.0.0 (or later), whilst the Raspberry Pi must be running version dnms-0.9.27 or dnms-0.9.28 (or later). Only these versions have the frequency response correction parameters stored and transmit these values on start-up.<mark>

- DNMS_V5.9.x  for IM72D128 and ICS-43434 microphones; the difference from version DNMS_V5.8.x is that C-values can now also be calculated and retrieved. If C-values are not required, version  DNMS_V5.8.x remains the current version. One version that retrieves C-values is the Raspberry Pi version dnms-0.9.25. There are currently no plans to retrieve C-values for the NodeMCU firmware.

- DNMS_V5.8.x  for IM72D128 and ICS-43434 microphones with:
	+ additional selection of frequency response correction for the DLR housing with IM72D128 microphone, as well as a selection without frequency response correction for IM72D128 and ICS-43434 microphones
	+ minor corrections have been made to the source code so that the code compiles without warnings in Arduino IDE version 2.3.8. This also applies to the dnms_audio_lib-master.zip library, so please include the updated library when compiling.
	+ corrections to the I²C transmission; changes to the values for the SDA and SCL glitch filters in slave mode. These corrections are contained in the library teensy4_i2c-master.zip, so be sure to include the updated library when compiling.

- DNMS_V5.5.x  for IM72D128 and ICS-43434 microphones with:
	+ Improved frequency correction for IM72D128 microphone and ICS-43434 microphone. It also improves the 1/2 octave values of the spectrum.

- DNMS_V5.4.x - for ICS-43434 and IM72D128 microphone
	+ Replaces DNMS_V5.3.x because of an error in the calculation of the 1/3 octave values in DNMS_V5.3.x. Please replace DNMS_V5.3.x with DNMS_V5.4.x.

- DNMS_V5.3.x - for ICS-43434 and IM72D128 microphone
	 - Merging the previously separate versions for the two microphones ICS-43434 and IM72D128 into one Teensy4.0 firmware. The microphone is selected via the configuration in the NodeMCU or Raspberry Pi and is transferred to the Teensy4.0 firmware using a switching command. If no switching command is transmitted, the ICS-43434 is selected by default, i.e. older NodeMCU firmware also supports version DNMS_V5.3.x with ICS-43434 microphone.
	 - Depending on the selected microphone, the red LED on the Teensy4.0 board flashes at different frequencies:	
ICS-43434: alternating 100ms on and 100ms off	
IM72D128: alternating 500ms on and 500ms off

- DNMS_V5.2.4 - for ICS-43434 Mikrofon
- DNMS_V5.2.6 - for IM72D128 Mikrofon	

	Note: Using inappropriate versions of microphone and Teensy firmware will result in erroneous noise values!

### Prerequisites

- Usage of firmware versions NRZ-2020-134-DNMS-5.2-en for NodeMCU to get  Z-values read out of Teensy4.0. For Raspberry Pi there is a version with these features under preparationl. Values from the 2nd interval, 1/3 octave values and Z-values are not transmitted to Sensor.Community.
- Usage of an InfluxDB or an own application for storing the 2nd interval values, 1/3 octaves values and Z-values is necessary.

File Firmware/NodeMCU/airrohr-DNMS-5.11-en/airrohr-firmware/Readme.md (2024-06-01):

# airRohr Sensor Firmware for SPS30, SDS011, DHT22, BMP180, BMP/E 280 and many more

## Features:
* many environmental and air quality sensors can be used concurrently
* Integration in Sensor.Community (formerly Luftdaten.Info)
* Configuration via HTTP in local WiFi or with a Sensor-as Access-Point
* Support for OLED- and LCD-Displays (SSD1306, SH1106 and LCD1602, LCD2004)
* Wide selection of API integrations for measurement reporting
* Ability to print measurements as CSV via USB-serial
* Used with ESP8266 (NodeMCU v2/v3 and compatible) and ESP32 (experimental)

## Contributing

Please refer to [Contributing README](./Contributing.md) for details.

## WiFi configuration
For German Version see: [Konfiguration der Sensoren](https://github.com/opendata-stuttgart/meta/wiki/Konfiguration-der-Sensoren)

If a (previously) configured WiFi is not reachable within 20 seconds after power-on,
the firmware flips itself into AP mode and creates a WiFi network in the form `airRohr-\[Sensor-ID\]`.

This WiFi network is by default unencrypted. When a client connects to this, it will get
redirected to the sensors web server `http://192.168.4.1/` which allows initial configuration.

Configurable is
* WiFi Access Point to use
* Options for measurements (Sensors to poll, intervals..)
* APIs to send the measurements

The unencrypted Access Point for initial configuration will turn itself off after about
10 minutes. In order to reactivate please power cycle the board.

## DHT22 Humidity Reporting

The DHT22 sensor is originally an Indoor sensor. For outdoor use it appears to be rather
sensitive to water condensation after 100% rel.Humidity that keep it for very long time
(sometimes forever) at 99.9% value. Also it appears to be sensitive to high UV light,
which tends to cause the sensor to crash until hard power-loss restarted.

Better experiences have been made with a BME280 or SHT3x sensor, so consider those instead.

## Debug via USB-Serial

Connecting/Powering via a computer USB will provide USB serial with the settings 9600 baud 8N1.
By default the sensor will provide human readable debug information of configurable granularity
there.

## Save as CSV

All measurements can also be read as CSV via USB-Serial when using the USB port in the
settings 9600 Baud 8N1. In order to avoid interfering of debug options (see earlier section)
set debug to None in the configuration.

## Wiring

https://raw.githubusercontent.com/opendata-stuttgart/meta/master/files/nodemcu-v3-schaltplan-sds011.jpg

Please refer to the [Pinout of NodeMCU v2 and v3](https://github.com/opendata-stuttgart/meta/wiki/Pinouts-NodeMCU-v2,-v3) for much more detailed information about the individual pin functions.

### SDS011 (serial)
**Note**: Serial connections are always crossed (RX on one side is connected with TX on other side)
* Pin 1 (TX)   -> (RX) Pin D1 (GPIO5)
* Pin 2 (RX)   -> (TX) Pin D2 (GPIO4)
* Pin 3 (GND)  -> GND
* Pin 4 (2.5m) -> unused
* Pin 5 (5V)   -> VU
* Pin 6 (1m)   -> unused

### DHT22
* Pin 1 => 3V3
* Pin 2 => Pin D7 (GPIO13)
* Pin 3 => unused
* Pin 4 => GND

### DS18B20 (OneWire interface)
Please check your version (pinout) at [https://datasheets.maximintegrated.com/en/ds/DS18B20.pdf]
Uses the same PIN D7 as DHT22, so DHT22 OR DS18B20 can be used. 
* GND  -> Pin GND
* DQ   -> Pin D7 (GPIO 13)
* VCC  -> Pin 3V3 or Pin VU

### PMS1003 to PMS6003
Pinout:
   8 7 6 5 4 3 2 1

* Pin 1 (VCC)   -> VU
* Pin 2 (GND)   -> GND
* Pin 3 (SET)   -> unused
* Pin 4 (RX)    -> Pin D2 (GPIO4)
* Pin 5 (TX)    -> Pin D1 (GPIO5)
* Pin 6 (RESET) -> unused
* Pin 7	(NC)	-> unused
* Pin 8 (NC)	-> unused

### PMS7003
Pinout PMS7003:
   9  7  5  3  1
  10  8  6  4  2

* Pin  1/2 (VCC) -> VU
* Pin  3/4 (GND) -> GND
* Pin  5 (RESET) -> unused
* Pin  6 (NC)    -> unused
* Pin  7 (RX)    -> Pin D2 (GPIO4)
* Pin  8 (NC)    -> unused
* Pin  9 (TX)    -> Pin D1 (GPIO5)
* Pin 10 (SET)   -> unused

### Honeywell PM sensor
Pinout:
   8 7 6 5 4 3 2 1
* Pin 1 (3.3V)   -> unused
* Pin 2 (5V)     -> VU
* Pin 3 (NC)     -> unused
* Pin 4 (NC)     -> unused
* Pin 5 TEST)    -> unused
* Pin 6 (TX)     -> Pin D1 (GPIO5)
* Pin 7	(RX)     -> Pin D2 (GPIO4)
* Pin 8 (GND)    -> GND

### BMP180 / BME/P280 / HTU21D / SHT3x (I2C)
* VCC  ->  Pin 3V3
* GND  ->  Pin GND
* SCL  ->  Pin D4 (GPIO2)
* SDA  ->  Pin D3 (GPIO0)

### SPS30 (I2C, 5V)
Pinout:
   1 2 3 4 5
* Pin 1 (5V)     -> Pin VU/VIN
* Pin 2 (SDA)    -> Pin D3 (GPIO0)
* Pin 3 (SCL)    -> Pin D4 (GPIO2)
* Pin 4 (SEL)    -> Pin GND
* Pin 5 (GND)    -> Pin GND

### LCD1602 (I2C, 5V - check your version)
* VCC  ->  Pin VU
* GND  ->  Pin GND
* SCL  ->  Pin D4 (GPIO2)
* SDA  ->  Pin D3 (GPIO0)

### OLED displays with SSD1306 (I2C, 128x64 pixels)
* VCC -> Pin VU
* GND -> Pin GND
* SCL  ->  Pin D4 (GPIO2)
* SDA  ->  Pin D3 (GPIO0)

### GPS NEO 6M (serial) !!! USE AT OWN RISK, in combination with PM sensor the firmware may crash !!! 
VCC and GND can be provided by board (use 3.3v!)

**Note**: Serial connections are always crossed (RX on one side is connected with TX on other side)

* TX von Neo -> Pin D5 (RX) 
* RX von Neo -> Pin D6 (TX) 

## Sensor.Community API "Pins"

For use of multiple sensors with Sensor.Community (formerly Luftdaten.info), you need to specify a
*virtual* API Pin  in the sensor registration form at devices.sensor.community. The firmware uses
the following API pins hardcoded. These match what the Sensor.Community API expect and will be used
by default when selecting the correct sensor model.

* HPM/PMS/SDS011/SPS30 => Pin 1
* BME280 => Pin 11
* BMP180/BMP280 => Pin 3
* DHT22/HTU21D/SHT3x => Pin 7
* GPS(Neo-6M) => Pin 9
* DS18B20 => Pin 13
* DNMS +> Pin 15

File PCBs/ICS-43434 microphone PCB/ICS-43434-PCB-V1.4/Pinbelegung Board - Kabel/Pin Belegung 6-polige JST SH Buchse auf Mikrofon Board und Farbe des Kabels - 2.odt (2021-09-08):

Pin Belegung 6-polige JST SH Buchse auf Mikrofon Board und Farbe des Kabels - 2

PIN | Signal | Farbe
1 | GND | schwarz
2 | +3,3V | rot
3 | SCK | weiß
4 | L/R | gelb
5 | WS | braun
6 | SD | Grün


- Achtung die Beschreibung der Zuordnung Signale zu Farben des Kabels bezieht sich auf die abgebildete Kabelausrichtung.
- Die Vergussmasse darf nicht zu dünnflüssig sein, sonst besteht die Möglichkeit, dass Vergussmasse zwischen Platine und Mikrofon läuft und in die akustische Öffnung des Mikrofons eindringt. Evtl. mit dickflüssigem Sekundenkleber (Gel) eine Raupe um das Mikrofon zur Abdichtung legen.

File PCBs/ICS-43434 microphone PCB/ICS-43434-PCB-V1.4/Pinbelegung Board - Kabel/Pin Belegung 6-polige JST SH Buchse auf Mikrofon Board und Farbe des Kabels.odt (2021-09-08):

Pin Belegung 6-polige JST SH Buchse auf Mikrofon Board und Farbe des Kabels

PIN | Signal | Farbe
1 | GND | schwarz
2 | +3,3V | rot
3 | SCK | gelb
4 | L/R | weiß
5 | WS | braun
6 | SD | Grün


- Die weißliche Ablagerung auf dem Board ist Sekundenkleber zur Abdichtung, dass die Vergussmasse nicht unter das Mikrofon läuft.
- Das Kunststoffrohr hat eine Markierung mit Kugelschreiber an der nicht planen Stirnseite. Das Mikrofonboard sollte gegenüber in die plane Seite eingesetzt werden.

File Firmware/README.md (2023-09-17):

# [English text below](#note-how-to-download-single-file)

## Anmerkung zum Download einzelner Files

Auch um einen einzelnen File (z.B. DNMS_V1.1.0.ino.hex) herrunterzuladen ist es am einfachsten das gesamte Repository als ZIP herunterladen, zu entpacken und den benötigten File zu kopieren.

<br>

Eine weitere Möglichkeit ist den File in GitHub zu öffnen und dann die Funktion Download raw file zu benutzen.

<br>

------------------------------------------------------------------------

## Note how to download single file

Even if you want to download only a single file (e.g. DNMS_V1.1.0.ini.hex), the easiest way is to download the complete repository as a ZIP, unpack it and copy the required file.

<br>

Another way is to open the file in GitHub and use the function Download raw file.

<br>

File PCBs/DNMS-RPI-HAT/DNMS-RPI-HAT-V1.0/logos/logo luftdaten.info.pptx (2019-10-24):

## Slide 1


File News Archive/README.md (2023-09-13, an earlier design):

## [English text below](#english text)
 
## Archivierte Neuigkeiten

### September 2021
- Die Beta Firmware Version 2.1.4 und 2.1.5 versucht das I²C Kommunikation bei den Kombi Boards DNMS-T4.0+NodeMCU-V1.x zu beheben. Bitte probieren, wenn ein solches Problem aufgetreten ist. Eine Rückmeldung, ob es dann funktioniert oder nicht, wäre schön.
- ICS-43434 Mikrofon PCB - ein rundes Mikrofon Board, das in ein 1/2" Plastikrohr (oder in 13mm Edelstahlrohr mit 12mm Innendurchmesser) eingebaut werden kann. Komplettes KiCAD Design im Ordner PCBs um das Board bei einem Platinenfertiger zu bestellen, enthält auch alle Informationen um bestückte Boards zu bestellen.
- Airrohr-ESP32-PCB - Basis Board wie Airrohr PCB aber für ESP32 Module Heltec WiFi LoRa 32 (V2) und das kompatible LILYGO TTGO LORA 32 V1. Diese Module besitzen ein Display und unterstützen LoRaWAN. Bitte mit Sensor.Community klären, ob und wie die standard Firmware von Sensor.Community dies unterstützt ohne die Firmware selbst übersetzen oder ergänzen zu müssen.
- DNMS-RPI-HAT-V1.0 - ein Aufsatzboard für den Raspberry Pi um DNMS und andere I²C Sensoren anzuschliessen. Für den Raspberry Pi gibt es SW Beispiele für den DNMS Sensor um die Lärmwerte auszulesen aber auch für andere Sensoren wie Feinstaubsensor SPS30, CO2 Sensor SCD30 und Temperatur- und Feuchtigkeitsensor SHT3x. Die Größe des Boards entspricht der des Raspberry Pi Zero W.
- Neue Version der DNMS standalone Testsoftware für Teensy3.6 und Teensy4.0 (DNMS_Vt.1.0 und DNMS_Vt.1.4). Die Testsoftware basiert nun ebenfalls auf der 32-Bit Floating Point Library und berechnet den LAeq bis herunter zu Mikrofongrenze von 28 - 29 dBA.

### Mai 2021
- Die Firmware Version 2 ist nun zusammen mit der HFT (Hochschule für Technik, Stuttgart) im Akustik Labor überprüft worden mit gutem Ergebnis. Der detaillierte Bericht darüber ist unter Firmware zu finden.

### März 2021
- Erstes Release der Firmware Version 2 basierend auf 32-Bit Floating Point Verarbeitung für Teensy4.0 und Teensy3.6. Der untere Grenze des LAeq Messbereichs liegt mit dieser Version bei ca. 30 dBA beim Teensy4.0 und ca. 32 dBA beim Teensy3.6. Dies ist eine Verbesserung von 5 - 6 dBA im Vergleich zur Firmware Version 1. Einfach die entsprechende Firmware auf Teensy3.6 oder Teensy4.0 flashen. Die endgültigen Messungen und Auswertungen zu dieser Version erfolgen noch im Laufe des April. Dann werden wir auch die Messwerte veröffentlichen.

### Januar 2021
- Neues Layout DNMS-T4.0+NodeMCU-V1.5 - Masseflächen an Ober- und Unterseite des Boards um die Abschirmung zwischen Teensy4.0 und dem WLAN der NodeMCU zu verbessern

### Dezember 2020
- Als Grundlage für die weitere Entwicklung erfolgt zur Zeit eine Umstellung von 16-Bit Integer Verarbeitung auf 32-Bit Floating Point. Teensy3.6 /4.0 sind dafür leistungsfähig genug, da sie über eine HW Floating Point Einheit verfügen, Teensy 4.0 sogar für 64-Bit Floating Point. Die volle 24-Bit Auflösung des Mikrofons wird dann auch ausgenutzt, was einen unteren Messbereich für den LAeq von ca. 31 dBA ermöglicht. Für Teensy3.6 ist diese Umstellung schon lauffähig. Die Filter für die A-Bewertung und Frequenzgangkorrektur des Mikrofons müssen aufgrund der Umstellung noch angepasst werden. Dies soll im Zeitraum Januar/Februar 2021 erfolgen.
- Auf der neuen Basis wird danach das Thema Frequenzanalyse mittels FFT angegangen, was einige Zeit dauern wird.

### Oktober 2020
- Kleine Korrekturen und Ergänzungen im Manual, Stand nun V2.2
- Neues Manual V2.0 verfügbar mit detaillierten Beschreibungen der V1.4 Boards
- Stücklisten/BOM für die V1.4 Boards (Airrohr-PCB-V1.4, DNMS-T4.0-V1.4, DNMS-T4.0+NodeMCU-V1.4)

### August 2020: Neue PCBs verfügbar
- Airrohr-PCB-V1.4
- DNMS-T3.6-V1.4
- DNMS-T4.0-V1.4
- DNMS-T4.0+NodeMCU-V1.4

### Juni 2020: Teensy4.0 läuft stabil und wird nun empfohlen
- Teensy4.0 ist preiswerter als Teensy3.6
- Teensy4.0 ist leistungsfähiger als Teensy3.6
- Teensy3.6 wird weiter unterstützt

----------------------------------------------------------------------------------------------------------------

## Archived News

### September 2021
- Beta firmware versions 2.1.4 and 2.1.5 tries to fix this I²C communication problem if you are using a combined board DNMS-T4.0+NodeMCU-V1.x. Please try the new beta firmware, if you had such problems. Feedback about the result would be appreciated.
- ICS-43434 microphone board - a round microphone PCB, that fits into a 1/2" plastic tube (or into a 13mm stainless steel tube with 12mm inner diameter). Complete KiCAD design in folder PCBs to order PCBs, it includes all infos to order assembled PCBs.
- Airrohr-ESP32-PCB - basis board as Airrohr PCB but for ESP32 moduls Heltec WiFi LoRa 32 (V2) or the compatible LILYGO TTGO LORA 32 V1. These moduls have a display and as well support LoRaWAN. Please check with Sensor.Community if and what functionality is supported by the standard Sensor.Community firmware out of the box or if you have to compile the firmware yourself and doing your own additions.
- DNMS-RPI-HAT-V1.0 - an addon board for the Raspberry Pi to connect to DNMS and other I²C Sensors. There are basic software examples how to read the DNMS noise values as well for some other sensors (PM SPS30, CO2 SCD30, temperature and humidity SHT3x). Size of the board is exactly as Raspberry Pi Zero W.
- New version of DNMS standalone testsoftware for Teensy3.6 and Teensy4.0 (DNMS_Vt.1.0 und DNMS_Vt.1.4). This version is based on the 32-Bit floating point library and calculates the LAwq down to microphone limitation of 28 - 29 dBA.

### May 2021
- Firmware version 2 was checked togehter with the HFT (Hochschule für Technik - University of Applied Sciences, Stuttgart) in the acoustic laboratories of the Centre for Building Physics (ZFB). You will find a detailed description about the tests under firmware.

### March 2021
- First release of firmware version 2, which is based on 32-Bit floating point processing. It's available for Teensy3.6 and Teensy4.0. The lower LAeq measurement limit for version 2 is araund 30 dBA for Teensy4.0 and around 32 dBA for Teensy3.6. This is an improvement of about 5 - 6 dBA compared to firmware version 1. To upgrade to version 2 you only need to flash the appropriate firmware on Teensy3.6 or Teensy4.0. The definite test and reporting will be done over April an the results will be published then.
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

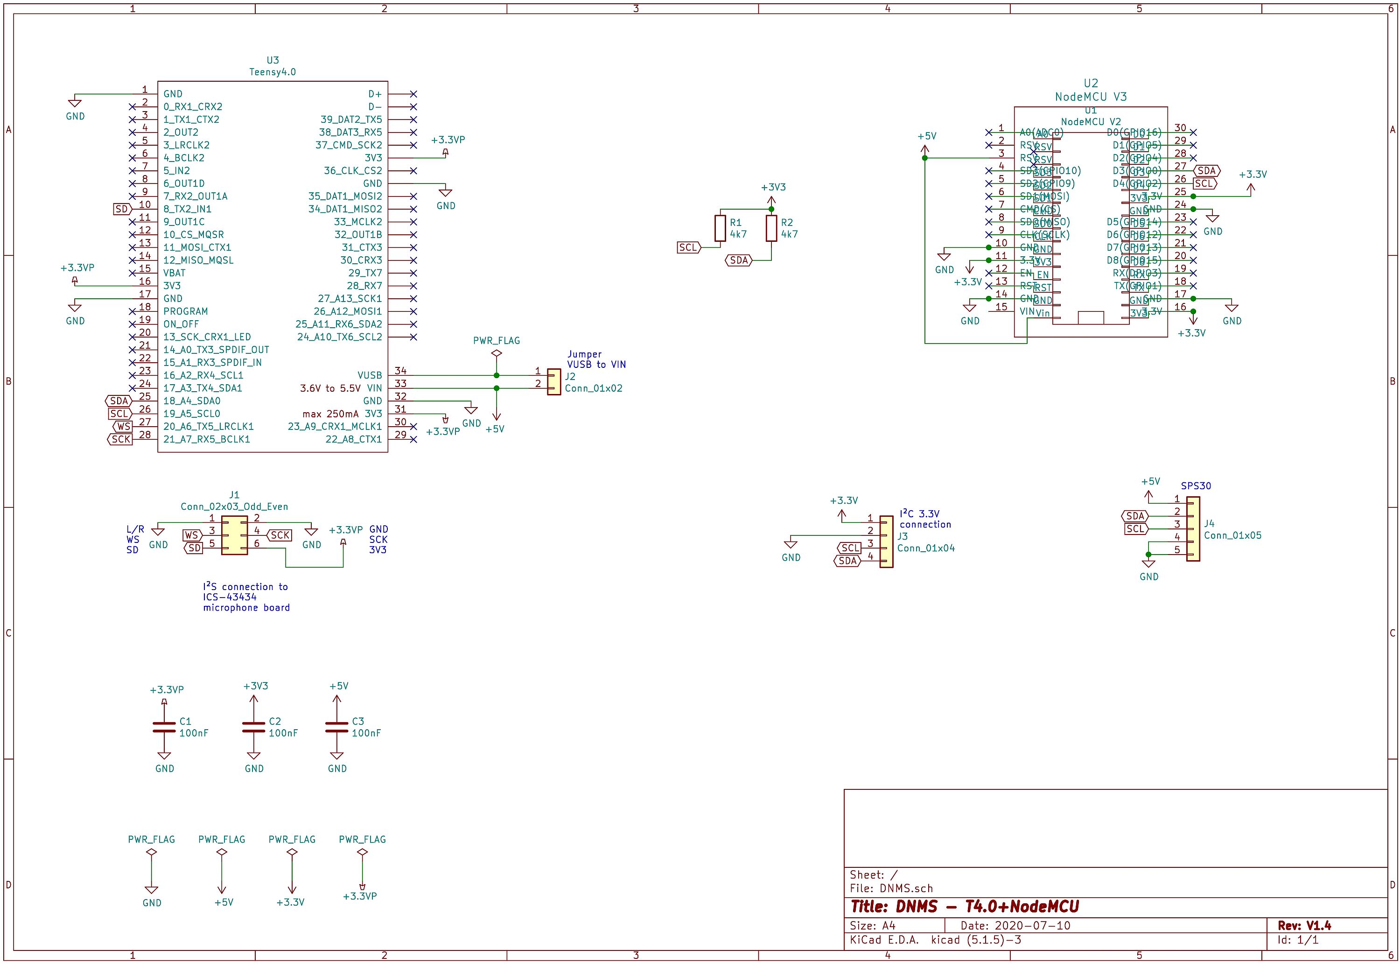
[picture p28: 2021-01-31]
PCBs/DNMS-T4.0+NodeMCU/DNMS-T4.0+NodeMCU-V1.5/schematic DNMS-T4.0+NodeMCU-V1.5.jpg

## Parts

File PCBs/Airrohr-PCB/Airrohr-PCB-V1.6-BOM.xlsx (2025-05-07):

BOM | Airrohr-PCB-V1.6 |  |  | Bastelaktion WS24/25
Item # | Reference | Qty single board | Assembly yes = 1, no = 0 | Qty for planned # of boards | Corrected Qty based on parts in stock | Manufacturer | Manufacturer Part # | Description / Value | Package/Footprint | Type | Distributor | Distributor # | Link to Distributor | Link to alternate Source | Link to alternate Source | Notes | Price (single Qty) Mouser | Price
1 | C1 | 1 | 1 | 0 | 22 | Vishay | K104K15X7RF53H5L | Multilayer Ceramic Capacitors MLCC - Leaded 0.1uF 50volts 10% X7R 5mm LS | 5mm LS | THT | Mouser | 594-K104K15X7RF53H5 | Mouser (https://www.mouser.de/ProductDetail/Vishay-BC-Components/K104K15X7RF53H5) | Reichelt (https://www.reichelt.de/vielschicht-kerko-100-nf-50-v-rm-5-125-c-hita-sf1h104z-l5-p246835.html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) | Voelkner (https://www.voelkner.de/products/1020732/TANCAP-CT4-0805Y104M500A1T-Keramik-Kondensator-THT-100-nF-50V-20-B-x-H-4.2mm-x-25mm.html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) | any other Manufacturer is ok | 0.214 | 4.71 | Reichelt 0,03€/Stk
2 | J1 | 1 | 0 | 0 | 0 | JST | S5B-XH-A | Connector SDS011 PM sensor – through-hole type shrouded header, siede entry | P2,5mm | THT | Reichelt | JST XH5P ST90 | Reichelt (https://www.reichelt.de/jst-stiftleiste-90-1x5-polig-xh-jst-xh5p-st90-p185082.html?trstct=pos_0&nbc=1) | Voelkner (https://www.voelkner.de/products/173715/JST-Stiftleiste-Standard-XH-Polzahl-Gesamt-5-Rastermass-2.50mm-800624.html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) |  | (optional) | 0.280 | 0.00
3 | J2 | 1 | 0 | 0 | 0 | PTR | 50500020134G | External 5V connection – PCB Terminal Block, Screw Terminal, 2-pole | P5,08 | THT | Voelkner | D29644 | Voelkner (https://www.voelkner.de/products/120935/PTR-AKZ500-2DS-5.08-V-Schraubklemmblock-1.50mm-Polzahl-2-Grau.html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) | Mouser (https://www.mouser.de/ProductDetail/Phoenix-Contact/1987096?qs=zUB8f6wPlfXjs6AGCzTQ1w%3D%3D) |  | any other Manufacturer is ok, (optional) | 0.190 | 0.00
4 | J3 | 1 | 0 | 0 | 0 | Amphenol FCI | 10129378-902001BLF | External 5V jumper – PIN Header 1x02 P2.54mm vertical | P2.54mm | THT | Mouser | 649-1012937890201BLF | Mouser (https://www.mouser.de/ProductDetail/Amphenol-FCI/10129378-902001BLF?qs=0lQeLiL1qybv6C1q0T3%2FPw%3D%3D) | Voelkner (https://www.voelkner.de/products/187977/MPE-Garry-Stiftleiste-Standard-Anzahl-Reihen-1-Polzahl-je-Reihe-2-087-1-002-0-S-XS0-1260.html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) |  | any other Manufacturer is ok, (optional) | 0.093 | 0.00
5 | J4, J6, J7, J8, J9, J10 | 6 | 1 | 0 | 0 | A+D10:P10mphenol Commercial Products | G800W304018EU | Pin Header 2.54mm Pitch STR DIP,1x4Pin,FULL G/F,NY6T,6.1mm*2.5mm*3.0mm,Color-Black,BAG | P2,54mm | THT | Mouser | 523-G800W304018EU | Mouser (https://www.mouser.de/ProductDetail/Amphenol-Commercial-Products/G800W304018EU?qs=f9yNj16SXrKi9QS16pMdvA%3D%3D) | Voelkner (https://www.voelkner.de/products/375061/W-P-Products-Stiftleiste-Standard-Anzahl-Reihen-1-Polzahl-je-Reihe-4-943PFS-12-004-00.html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) |  | any other Manufacturer is ok, (optional) | 0.102 | 0.00
6 | J5 | 1 | 1 | 0 | 0 | JST | S5B-ZR(LF)(SN) | Connector SPS30 PM sensor - through-hole type shrouded header, siede entry | P1,5mm | THT | Voelkner | D19571 | Voelkner (https://www.voelkner.de/products/173795/JST-Einbau-Stiftleiste-Praezision-ZH-Polzahl-Gesamt-5-Rastermass-1.50mm-S5B-ZR-LF-SN.html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) | smdv (https://www.smdv.de/products/73498/JST-Einbau-Stiftleiste-Praezision-ZH-Polzahl-Gesamt-5-Rastermass-1.50mm-S5B-ZR-LF-SN.html) |  | (optional) | 0.400 | 0.00
7 | J11 | 1 | 1 | 0 | 22 | Stewart Connector / Bel | SS-90000-003 | MOD JACK RJ12 6P6C CAT 3 HORIZ. 1 PORT |  | THT | Mouser | 530-SS-90000-003 | Mouser (https://www.mouser.de/ProductDetail/Stewart-Connector-Bel/SS-90000-003?qs=QNEnbhJQKvZaQ5Cj8yFkoQ%3D%3D) |  |  | either J11 or J12 as alternate assembly, this is the preferred assembly because of the height, any other Manufacturer with same height is ok, (optional) | 0.493 | 10.85
8 | J12 | 1 | 0 | 0 | 0 | Pulse Electronics | E5566-Q0LK22-L | Modular Jack RJ12/RJ25 6P6C SIDE ENTRY |  | THT | Mouser | 673-E5566-Q0LK22-L | Mouser (https://www.mouser.de/ProductDetail/Pulse-Electronics/E5566-Q0LK22-L) | Reichelt (https://www.reichelt.de/modular-einbaubuchse-6-6-schwarz-mebp-6-6s-p11370.html?&trstct=pos_6&nbc=1) | Voelkner (https://www.voelkner.de/products/706460/MH-Connectors-RJ12-Einbaubuchse-Buchse-Einbau-horizontal-Pole-6P6C-MHRJJ66NFRA-Schwarz-2101-0100-12.html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) | either J11 or J12 as alternate assembly, any other Manufacturer is ok, (optional) | 0.530 | 0.00
9 | R1 | 1 | 0 | 0 | 0 | Vishay | CCF0710K0JKE36 | Metal Film Resistor 1/4watt 10Kohms 5% Rated to 1/2watt | 6,62x2.29mm axial | THT | Mouser | 71-CCF0710K0JKE36 | Mouser (https://www.mouser.de/ProductDetail/Vishay-Dale/CCF0710K0JKE36) | Reichelt (https://www.reichelt.de/widerstand-metallschicht-10-kohm-axial-0-4-w-1--vis-c1002fc100-p237126.html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) | Voelkner (https://www.voelkner.de/search/search.html?query=10K%20WIDERSTAND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) | any other Manufacturer is ok, Kohleschicht oder Metallschicht, 0,25Watt oder 0,5Watt, (optional) | 0.130 | 0.00
10 | R2, R3 | 2 | 1 | 0 | 44 | Vishay | CCF074K70JKE36 | Metal Film Resistor 1/4watt 4.7Kohms 5% Rated to 1/2watt | 6,62x2.29mm axial | THT | Mouser | 71-CCF07-J-4.7K-E3 | Mouser (https://www.mouser.de/ProductDetail/Vishay-Dale/CCF074K70JKE36?qs=DCZmdplX4vf8gjDtCyqZpA%3D%3D) | Reichelt (https://www.reichelt.de/widerstand-metallschicht-4-7-kohm-axial-0-4-w-1--vis-c4701fc100-p237116.html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) | Voelkner (https://www.voelkner.de/search/search.html?query=4%207K%20WIDERSTAND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) | any other Manufacturer is ok, Kohleschicht oder Metallschicht, 0,25Watt oder 0,5Watt, (optional) | 0.130 | 5.72
11 | R4, R5 | 2 | 1 | 0 | 44 | Vishay | CCF07330RJKE36 | Metal Film Resistor 1/4watt 330 Ohms 5% Rated to 1/2watt | 6,62x2.29mm axial | THT | Mouser | 71-CCF07330RJKE36 | Mouser (https://www.mouser.de/ProductDetail/Vishay-Dale/CCF07330RJKE36) | Reichelt (https://www.reichelt.de/widerstand-metallschicht-330-ohm-0207-0-6-w-1--metall-330-p11733.html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) | Voelkner (https://www.voelkner.de/search/search.html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) | any other Manufacturer is ok, Kohleschicht oder Metallschicht, 0,25Watt oder 0,5Watt, (optional) | 0.130 | 5.72
12 | U1 | 1 | 0 | 0 | 0 | diverse | NodeMCU V3 | NodeMCU ESP8266 Entwicklungs Board V3 | 58 x 31mm | THT | KOMPUTER DE | KP06014 | KOMPUTER DE (https://www.komputer.de/zen/index.php?main_page=product_info&products_id=418) | AZ-Delivery (https://www.az-delivery.de/products/copy-of-nodemcu-lua-amica-v2-modul-mit-esp8266-12e) |  | either U1 or U2 as alternate assembly | 3.100 | 0.00 | AZ-Delivery hat nicht genügend
13 | U2 | 1 | 1 | 0 | 22 | diverse | NodeMCU V2 | ESP8266 NodeMCU V2 Delopment Board | 48 x 26mm | THT | AZ-Delivery | NodeMCU Lua Amica Modul V2 ESP8266 ESP-12F | AZ-Delivery (https://www.az-delivery.de/products/nodemcu-lua-amica-v2-modul-mit-esp8266-12e-unverloetet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) | BerryBase (https://www.berrybase.de/raspberry-pi-co/esp8266-esp32/nodemcu-v2-esp8266-development-board-cp2102) |  | either U1 or U2 as alternate assembly | 4.200 | 92.40 | vorzugsweise V2 statt V3, da V2 eine interne LED hat
14 | U3 | 1 | 0 | 0 | 0 | Texas Instruments | P82B715P | Signal Buffer, Verstärker I2C Bus Extender | DIP8 | THT | Mouser | 595-P82B715P | Mouser (https://www.mouser.de/ProductDetail/Texas-Instruments/P82B715P?qs=ToK3%2FczOkx%252BJPKFYGKM%2FoA%3D%3D) |  |  | either U3 or U4 as alternate assembly, any other Manufacturer is ok, (optional) | 2.680 | 0.00
15 | U4 | 1 | 1 | 0 | 0 | Texas Instruments | P82B715DR | Signal Buffer, Verstärker I2C Bus Extender | SOIC8 | SMD | Mouser | 595-P82B715DR | Mouser (https://www.mouser.de/ProductDetail/595-P82B715DR) | Reichelt (https://www.reichelt.de/bus-controller-bidirektional-so-8-p-82b715-td-p70074.html?search=P82B715) |  | either U3 or U4 as alternate assembly, any other Manufacturer is ok, (optional) | 1.730 | 0.00
16 | PCB – Platine | 1 | 1 | 0 | 22 | PCBWay, JLCPCB, Aisler |  | PCB – Platine |  | PCB |  |  | JLCPCB (https://jlcpcb.com/) | PCBWay (https://www.pcbway.com/) |  |  |  | 23.00
 |  |  |  |  |  |  |  |  |  |  |  |  |  |  |  |  | Summe: | 142.39

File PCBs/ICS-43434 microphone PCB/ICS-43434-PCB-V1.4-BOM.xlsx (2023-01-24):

BOM | ICS-43434-PCB-V1.4 |  | PCB Order: |  | Product No.:
Item # | *Designator | *Qty | Manufacturer | *Mfg Part # | Description / Value | *Package/Footprint | Type | Your Instructions / Notes
1 | R1 | 1 | Yageo | RC0603JR-07100KL | RES SMD 100K OHM 5% 1/10W 0603 | 0603 | SMT | any other Manufacturer is ok
2 | MK1 | 1 | TDK InvenSense | ICS-43434 | MEMS Microphone | 6-Terminal LGA_CAV | SMT | Link to Datasheet: https://invensense.tdk.com/products/ics-43434/
3 | C1 | 1 | KEMET | C0603C104M4RAC7411 | CAP CER 0.1UF 16V X7R 0603 | 0603 | SMT | any other Manufacturer is ok
4 | J1 | 1 | JST | BM06B-SRSS-TB(LF)(SN) | JST SH Series 6-pin connector |  | SMT | any other Manufacturer is ok

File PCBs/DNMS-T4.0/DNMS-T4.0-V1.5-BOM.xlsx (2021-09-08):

BOM | DNMS-T4.0-V1.5
Item # | Reference | Qty | Manufacturer | Manufacturer Part # | Description / Value | Package/Footprint | Type | Distributor | Distributor # | Link to Distributor | Link to alternate Source | Link to alternate Source | Notes | Price (single Qty) Mouser | Price
1 | C1, C2, C3 | 3 | Vishay | K104K15X7RF53H5L | Multilayer Ceramic Capacitors MLCC - Leaded 0.1uF 50volts 10% X7R 5mm LS | 5mm LS | THT | Mouser | 594-K104K15X7RF53H5 | Mouser (https://www.mouser.de/ProductDetail/Vishay-BC-Components/K104K15X7RF53H5) | Reichelt (https://www.reichelt.de/vielschicht-kerko-100-nf-50-v-rm-5-125-c-hita-sf1h104z-l5-p246835.html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) | Voelkner (https://www.voelkner.de/products/1020732/TANCAP-CT4-0805Y104M500A1T-Keramik-Kondensator-THT-100-nF-50V-20-B-x-H-4.2mm-x-25mm.html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) | any other Manufacturer is ok | 0.085 | 0.26
2 | J1 | 1 | Amphenol FCI | 10129378-902001BLF | PIN Header 1x02 P2.54mm vertical | P2.54mm | THT | Mouser | 649-1012937890201BLF | Mouser (https://www.mouser.de/ProductDetail/Amphenol-FCI/10129378-902001BLF?qs=0lQeLiL1qybv6C1q0T3%2FPw%3D%3D) | Reichelt (https://www.reichelt.de/rnd-stiftleiste-2-pol-rm-2-54-mm-rnd-205-00623-p208849.html?trstct=pol_0&nbc=1) | Voelkner (https://www.voelkner.de/products/187977/MPE-Garry-Stiftleiste-Standard-Anzahl-Reihen-1-Polzahl-je-Reihe-2-087-1-002-0-S-XS0-1260.html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) | any other Manufacturer is ok | 0.085 | 0.09
3 | J2 | 1 | Würth | 61200621721 | Sockel & Kabelgehäuse WR-BHD 2.54mm Male 6P Angl Gold BoX Hdr | P2.54mm 2x3 | THT | Mouser | 710-61200621721 | Mouser (https://www.mouser.de/ProductDetail/Wurth-Elektronik/61200621721?qs=PhR8RmCirEbh0%2F%252BOR%252BGA%252BA%3D%3D) | Reichelt (https://www.reichelt.de/wannenstecker-6-polig-gewinkelt-wsl-6w-p105978.html?&trstct=pol_1&nbc=1) | Voelkner (https://www.voelkner.de/products/214760/W-P-Products-Stiftleiste-Rastermass-2.54mm-Polzahl-Gesamt-6-Anzahl-Reihen-2.html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) | any other Manufacturer is ok | 0.923 | 0.92
4 | J3 | 1 | Amphenol Commercial Products | G800W304018EU | Pin Header 2.54mm Pitch STR DIP,1x4Pin,FULL G/F,NY6T,6.1mm*2.5mm*3.0mm,Color-Black,BAG | P2,54mm | THT | Mouser | 523-G800W304018EU | Mouser (https://www.mouser.de/ProductDetail/Amphenol-Commercial-Products/G800W304018EU?qs=f9yNj16SXrKi9QS16pMdvA%3D%3D) | Reichelt (https://www.reichelt.de/rnd-stiftleiste-4-pol-rm-2-54-mm-rnd-205-00625-p208851.html?trstct=pol_1&nbc=1) | Voelkner (https://www.voelkner.de/products/375061/W-P-Products-Stiftleiste-Standard-Anzahl-Reihen-1-Polzahl-je-Reihe-4-943PFS-12-004-00.html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) | any other Manufacturer is ok, (optional) | 0.085 | 0.09
5 | J4 | 1 | Samtec | TSW-101-07-T-S | PIN Header 1x01 P2.54mm vertical | P2,54mm | THT | Mouser | 200-TSW10107TS | Mouser (https://www.mouser.de/ProductDetail/Samtec/TSW-101-07-T-S?qs=FESYatJ8odJDlFELO7FH2w%3D%3D) | Reichelt (https://www.reichelt.de/rnd-stiftleiste-1-pol-rm-2-54-mm-rnd-205-00622-p208848.html?trstct=vrt_pdn&nbc=1) |  | any other Manufacturer is ok, (optional) | 0.085 | 0.09
6 | J5 | 1 | Amphenol FCI | 54601-906WPLF | MOD JACK RJ12 6P6C CAT 3 HORIZ. 1 PORT |  | THT | Mouser | 649-54601-906WPLF | Mouser (https://www.mouser.de/ProductDetail/649-54601-906WPLF) |  |  | either J5 or J6 as alternate assembly, this is the preferred assembly because of the height, any other Manufacturer with same height is ok | 0.347 | 0.35
7 | J6 | 1 | Pulse Electronics | E5566-Q0LK22-L | Modular Jack RJ12/RJ25 6P6C SIDE ENTRY |  | THT | Mouser | 673-E5566-Q0LK22-L | Mouser (https://www.mouser.de/ProductDetail/Pulse-Electronics/E5566-Q0LK22-L) | Reichelt (https://www.reichelt.de/modular-einbaubuchse-6-6-schwarz-mebp-6-6s-p11370.html?&trstct=pos_6&nbc=1) | Voelkner (https://www.voelkner.de/products/706460/MH-Connectors-RJ12-Einbaubuchse-Buchse-Einbau-horizontal-Pole-6P6C-MHRJJ66NFRA-Schwarz-2101-0100-12.html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) | either J5 or J6 as alternate assembly, any other Manufacturer is ok | 0.44 | 0.44
8 | R1, R2 | 2 | Vishay | CCF074K70JKE36 | Metal Film Resistor 1/4watt 4.7Kohms 5% Rated to 1/2watt | 6,62mm axial | THT | Mouser | 71-CCF07-J-4.7K-E3 | Mouser (https://www.mouser.de/ProductDetail/Vishay-Dale/CCF074K70JKE36?qs=DCZmdplX4vf8gjDtCyqZpA%3D%3D) | Reichelt (https://www.reichelt.de/widerstand-metallschicht-4-7-kohm-axial-0-4-w-1--vis-c4701fc100-p237116.html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) | Voelkner (https://www.voelkner.de/search/search.html?query=4%207K%20WIDERSTAND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) | any other Manufacturer is ok, Kohleschicht oder Metallschicht, 0,25Watt oder 0,5Watt | 0.152 | 0.30
9 | U1 | 1 | PJRC | TEENSY40 | Teensy 4.0 Development Board | 1.4 by 0.7 inch | THT | Antratek Electronics Deutschland | TEENSY40 | Antratek Electronics Deutschland (https://www.antratek.de/teensy-4-0) | EXP GmbH (https://www.exp-tech.de/plattformen/teensy/9596/teensy-4.0-development-board?c=1168) |  |  | 19.6 | 19.60
10 | U2 | 1 | Texas Instruments | P82B715P | Signal Buffer, Verstärker I2C Bus Extender | DIP8 | THT | Mouser | 595-P82B715P | Mouser (https://www.mouser.de/ProductDetail/Texas-Instruments/P82B715P?qs=ToK3%2FczOkx%252BJPKFYGKM%2FoA%3D%3D) |  |  | either U2 or U3 as alternate assembly, any other Manufacturer is ok |  | 0.00
11 | U3 | 1 | Texas Instruments | P82B715DR | Signal Buffer, Verstärker I2C Bus Extender | SOIC8 | SMD | Mouser | 595-P82B715DR | Mouser (https://www.mouser.de/ProductDetail/595-P82B715DR) | Reichelt |  | either U2 or U3 as alternate assembly, any other Manufacturer is ok | 1.58 | 1.58

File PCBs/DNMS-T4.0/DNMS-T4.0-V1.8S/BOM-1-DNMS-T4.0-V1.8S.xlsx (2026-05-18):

Reference | Qty | Value | DNP | Exclude from BOM | Exclude from Board | Footprint | Datasheet
ET1,HB1,RB1 | 3 | 100nF |  |  |  | Capacitor_SMD:C_0201_0603Metric
F1 | 1 | BSMD0402L-035 |  |  |  | Fuse:Fuse_0402_1005Metric
HFT1 | 1 | P82B715DR |  |  |  | Package_SO:SOIC-8_3.9x4.9mm_P1.27mm
J2,J3 | 2 | HX PZ2.54-1X4P ZZ |  |  |  | Connector_PinHeader_2.54mm:PinHeader_1x04_P2.54mm_Vertical
MIC1 | 1 | SM06B-SRSS-TB(LF)(SN) |  |  |  | ProPrj_DNMS_TEENSY_2025-10-10:CONN-SMD_SM06B-SRSS-TB-LF-SN
R1,R2 | 2 | 4.7k |  |  |  | Resistor_SMD:R_0201_0603Metric
RJ1 | 1 | R-RJ11R06P-A000 |  |  |  | ProPrj_DNMS_TEENSY_2025-10-10:RJ11-TH_R-RJ11R06P-A000
U1 | 1 | teensy4.0 |  |  |  | ProPrj_DNMS_TEENSY_2025-10-10:TEENSY4.0

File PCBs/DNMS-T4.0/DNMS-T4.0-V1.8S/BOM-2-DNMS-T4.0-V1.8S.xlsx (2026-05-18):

Designator | Quantitiy | Value | Footprint | MPN | Description
ET1,HB1,RB1 | 3 | 100nF | 0603 | CC0603ZRY5V9BB104 | Capacitor, 100nF, 0603 SMD, Yageo o.ä.
F1 | 1 | 350mA | 0402 | 0402L035SL6SR | SMD PPTC Fuse 350mA
HFT1 | 1 | IC P82B715 | SOIC 8 | P82B715DR | P82B715 I²C Bus Extender
J2, J3 | 2 | 1x4 RM2.54mm | 1x4 RM2.54mm | TSW-104-15-T-S | Pin Header 1x4 Pins, RM2.54mm
MIC1 | 1 | Connector 6 Positions | 1mm Pitch SMT | SM06B-SRSS-TB(LF)(SN) | JST SR/SZ Series Connector 6 Positions SMT
R1, R2 | 2 | 4.7k | 0603 | AC0603JR-104K7L | Resistor, 4.7k, 0603 SMD, Yageo o.ä.
RJ1 | 1 | RJ11 | RJ11 TH | 43202-6101 | RJ11 6-polige Buchse Molex o.ä.

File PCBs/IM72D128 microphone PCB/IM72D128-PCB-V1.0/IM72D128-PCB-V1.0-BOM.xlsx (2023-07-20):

BOM | IM72D128-PCB |  | PCB Order: | T-M13W181770A | Product No.:
Item # | *Designator | *Qty | Manufacturer | *Mfg Part # | Description / Value | *Package/Footprint | Type | Your Instructions / Notes
1 | R1 | 1 | Yageo | RC0603JR-07100RL | RES SMD 100 OHM 5% 1/10W 0603 | 0603 | SMD | any other Manufacturer is ok
2 | MK1 | 1 | Infineon | IM72D128V01XTMA1 | MEMS Microphone | PG-LLGA-5-3 | SMD | Link to Datasheet: https://www.infineon.com/cms/en/product/sensor/mems-microphones/mems-microphones-for-consumer/im72d128/
3 | C1 | 1 | KEMET | C0603C104M4RAC7411 | CAP CER 0.1UF 16V X7R 0603 | 0603 | SMD | any other Manufacturer is ok

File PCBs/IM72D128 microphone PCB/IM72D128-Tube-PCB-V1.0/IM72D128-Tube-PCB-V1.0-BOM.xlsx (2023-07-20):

BOM | IM72D128-Tube-PCB |  | PCB Order: |  | Product No.:
Item # | *Designator | *Qty | Manufacturer | *Mfg Part # | Description / Value | *Package/Footprint | Type | Your Instructions / Notes
1 | C1, C2 | 2 | Samsung Electro-Mechanics | CL10A105KO8NNNC | 16V 1uF X5R ±10% 0603 Multilayer Ceramic Capacitors MLCC - SMD/SMT ROHS | 0603 | SMD | any other Manufacturer is ok
 | C3, C4, C5, C6 | 4 | Samsung Electro-Mechanics | CL10B104KO8NNNC | 16V 100nF X7R ±10% 0603 Multilayer Ceramic Capacitors MLCC - SMD/SMT ROHS | 0603 | SMD | any other Manufacturer is ok
 | C7 | 1 | Yageo | CC0603JRNPO8BN470 (https://www.lcsc.com/product-detail/Multilayer-Ceramic-Capacitors-MLCC-SMD-SMT_YAGEO-CC0603JRNPO8BN470_C519392.html) | 25V 47pF NP0 ±5% 0603 Multilayer Ceramic Capacitors MLCC - SMD/SMT ROHS | 0603 | SMD | any other Manufacturer is ok
 | R1 | 1 | Yageo | RC0603FR-07100KL | 100mW Thick Film Resistors 75V ±100ppm/℃ ±1% -55℃~+155℃ 100kΩ 0603 Chip Resistor - Surface Mount ROHS | 0603 | SMD | any other Manufacturer is ok
 | U1 | 1 | Texas Instruments (https://www.lcsc.com/brand-detail/100.html) | LP5907MFX-3.3/NOPB (https://www.lcsc.com/product-detail/Linear-Voltage-Regulators-LDO_Texas-Instruments-LP5907MFX-3-3-NOPB_C80670.html) | Fixed 1 250mA Positive 250mV@(250mA) 5.5V 90dB@(100Hz),60dB@(100kHz) 3.3V~3.3V SOT-23-5 Linear Voltage | SOT-23-5 | SMD
 | U2 | 1 | Analog Devices (https://www.lcsc.com/brand-detail/178.html) | ADAU7002ACBZ-R7 (https://www.lcsc.com/product-detail/Audio-Interface-ICs_Analog-Devices-ADAU7002ACBZ-R7_C481886.html) | 1.62V~3.6V WLCSP-8 Audio Interface ICs ROHS | WLCSP-8 | SMD
 | U3, U4, U5 | 3 | Texas Instruments (https://www.lcsc.com/brand-detail/100.html) | SN74LV1T34DBVR (https://www.lcsc.com/product-detail/Buffer-Driver-Transceiver_Texas-Instruments-SN74LV1T34DBVR_C100024.html) | Push Pull 8mA 1.6V~5.5V 8mA -40℃~+125℃ SOT-23-5 Buffer/Driver/Transceiver ROHS | SOT-23-5 | SMD

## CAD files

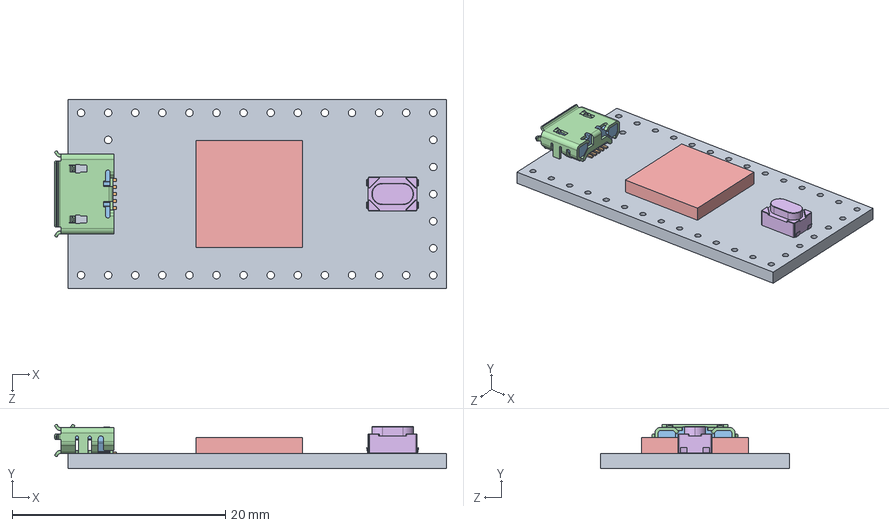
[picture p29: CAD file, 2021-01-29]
PCBs/DNMS-T4.0/DNMS-T4.0-V1.8S/Teensy KiCad/Teensy_4.0_Assembly.STEP
36.8 x 4.12 x 17.7 mm
Teensy_4.0_PCB
Micro USB-B Female 5Pin SMD
NXP iMXRT1062
SKRPACE010 v4

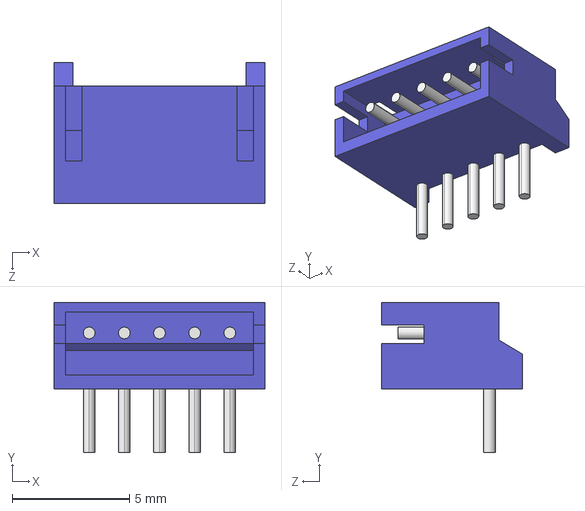
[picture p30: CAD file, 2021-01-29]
PCBs/DNMS-RPI-HAT/DNMS-RPI-HAT-V1.0/Connector_JST_ZH_3d/JST_ZH_S5B-EH_1x05_P1.50mm_Horizontal.STEP
9.00 x 6.40 x 6.00 mm

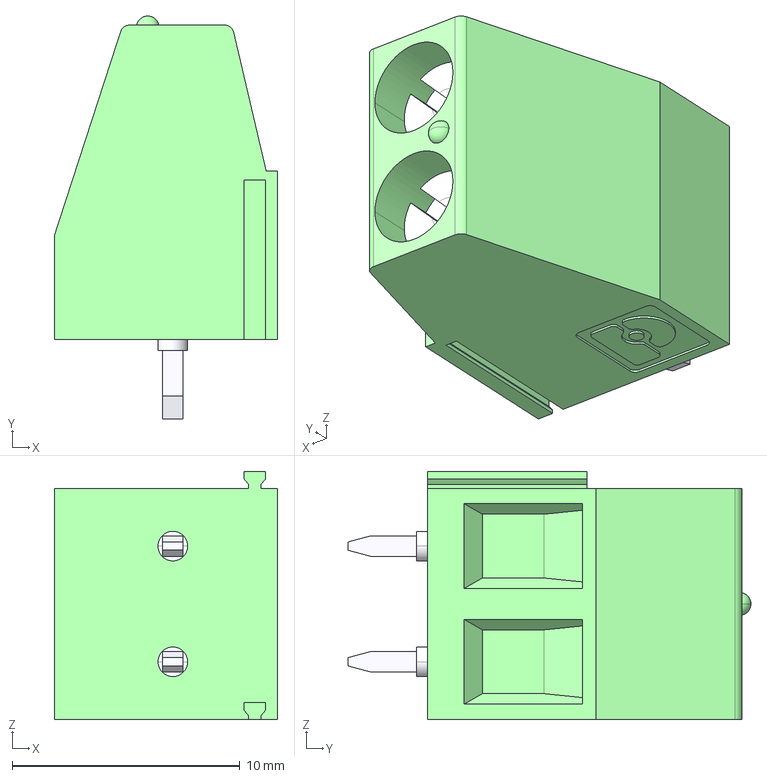
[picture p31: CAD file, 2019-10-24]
PCBs/DNMS-RPI-HAT/DNMS-RPI-HAT-V1.0/Phoenix_MKDS/MKDS-1-5-2-5-08_3D.step
9.80 x 17.7 x 10.9 mm

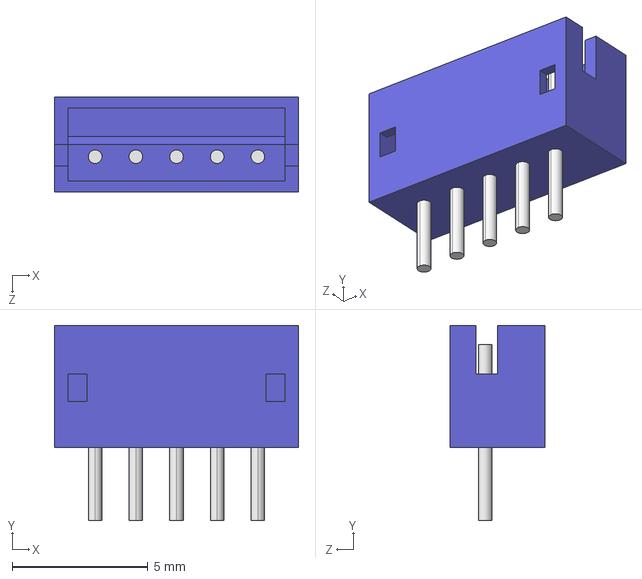
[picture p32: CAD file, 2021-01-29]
PCBs/DNMS-T4.0+NodeMCU/DNMS-T4.0+NodeMCU-V1.5/Connector_JST_ZH_3d/B5B-ZR.STEP
9.00 x 7.20 x 3.50 mm

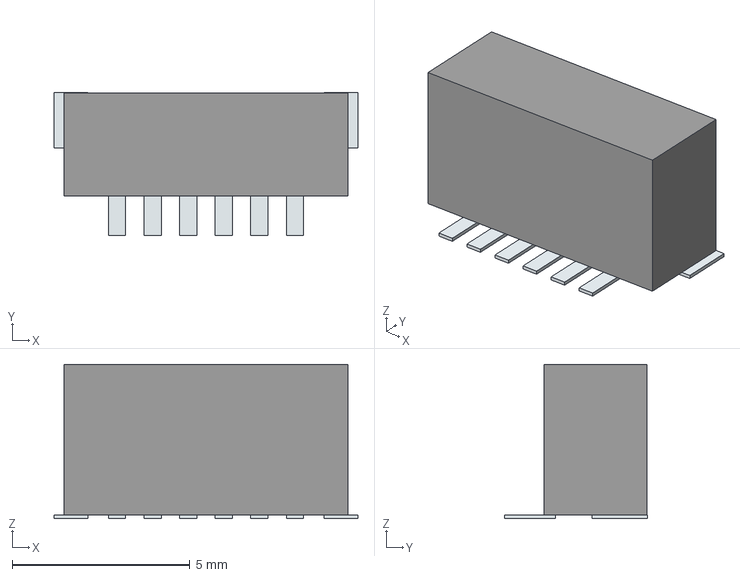
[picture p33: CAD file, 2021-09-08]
PCBs/DNMS-T4.0/DNMS-T4.0-V1.7/BM06B-SRSS-TB_LF__SN/3D/BM06B-SRSS-TB_LF__SN_.stp
8.56 x 4.02 x 4.35 mm
Pins

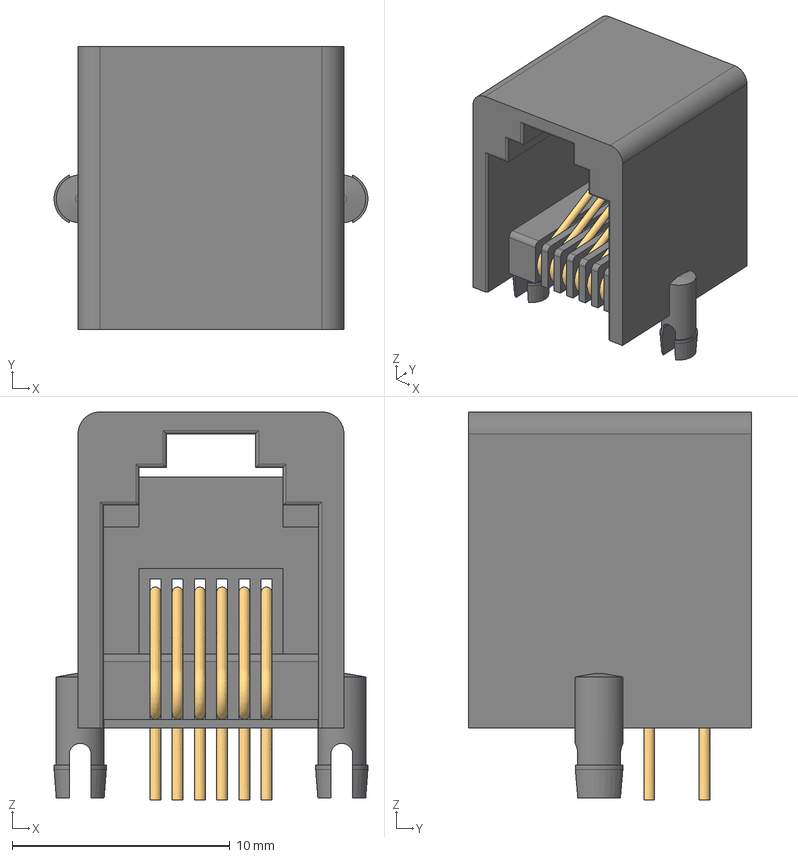
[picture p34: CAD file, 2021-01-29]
PCBs/DNMS-T4.0/DNMS-T4.0-V1.7/RJ-12 6P-6C Pulse/RJ12_Pulse_615006138421 (rev1).step
14.4 x 13.0 x 17.8 mm
615006138421_PIN x 3
615006138421_PIN_LONGUE x 3
6150xx138421

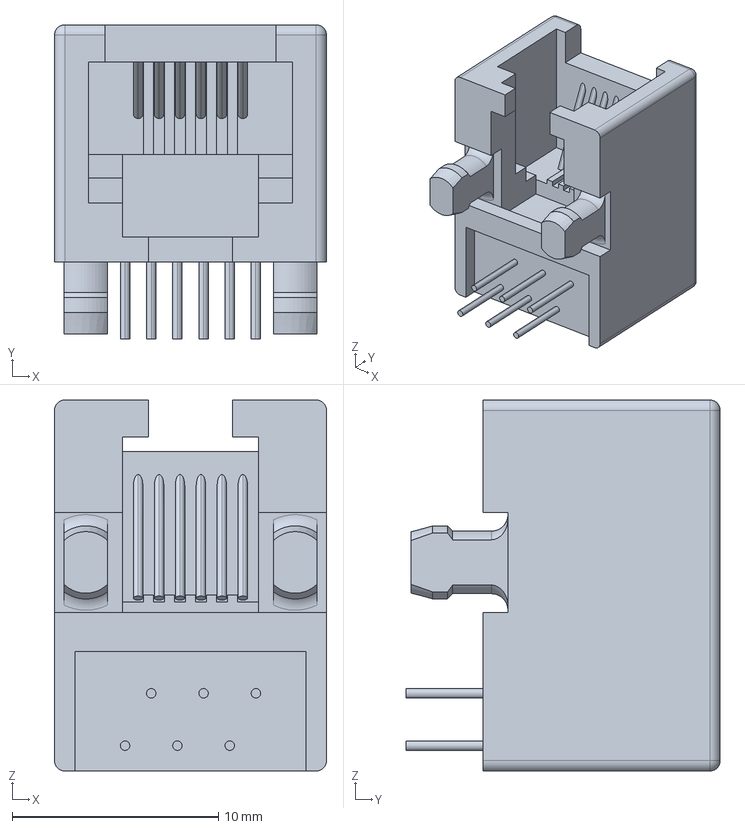
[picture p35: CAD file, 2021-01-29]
PCBs/DNMS-T4.0/DNMS-T4.0-V1.8S/RJ-12 6P-6C Amphenol u.a/RJ12_Amphenol_54601.stp
13.2 x 15.2 x 18.0 mm

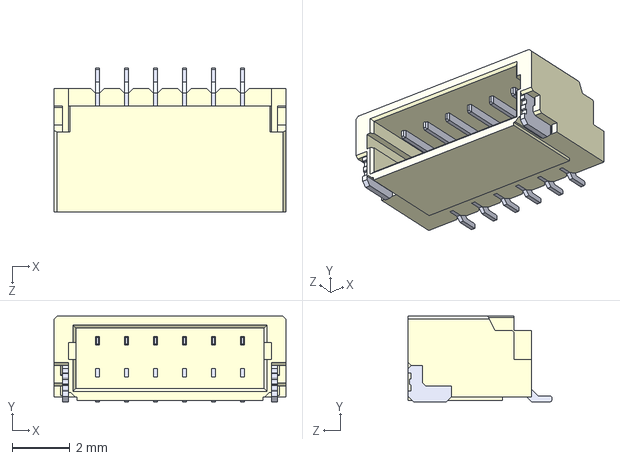
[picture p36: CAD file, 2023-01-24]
PCBs/DNMS-T4.0/DNMS-T4.0-V1.8S/SM06B-SRSS-TB_LF_SN/3D/SM06B-SRSS-TB_LF__SN_.step
8.00 x 2.95 x 4.95 mm

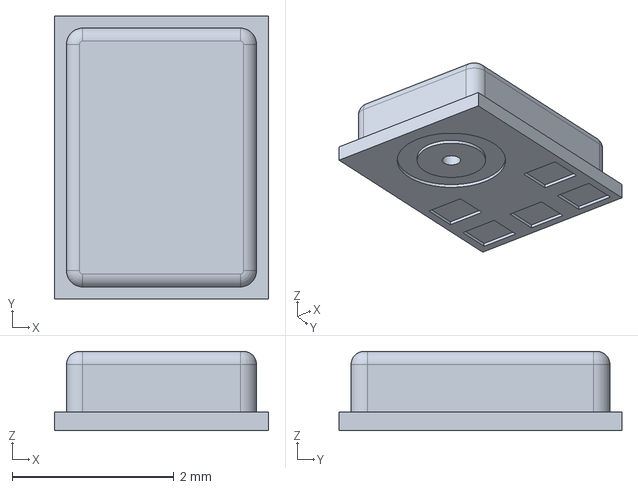
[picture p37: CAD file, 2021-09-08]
PCBs/ICS-43434 microphone PCB/ICS-43434-PCB-V1.4/ICS-43434/ICS-43434.models/InvenSense_-_ICS-43434.step
2.65 x 3.50 x 0.98 mm

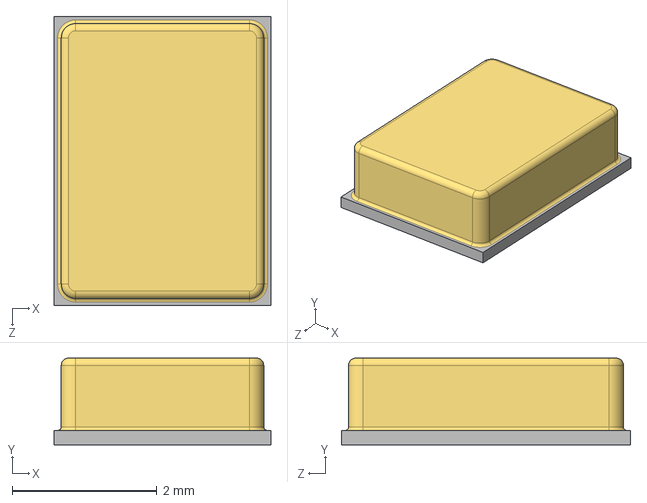
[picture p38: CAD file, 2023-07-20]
PCBs/IM72D128 microphone PCB/IM72D128-PCB-V1.0/IM72D128/IM72D128V01XTMA1.stp
3.00 x 1.20 x 4.00 mm

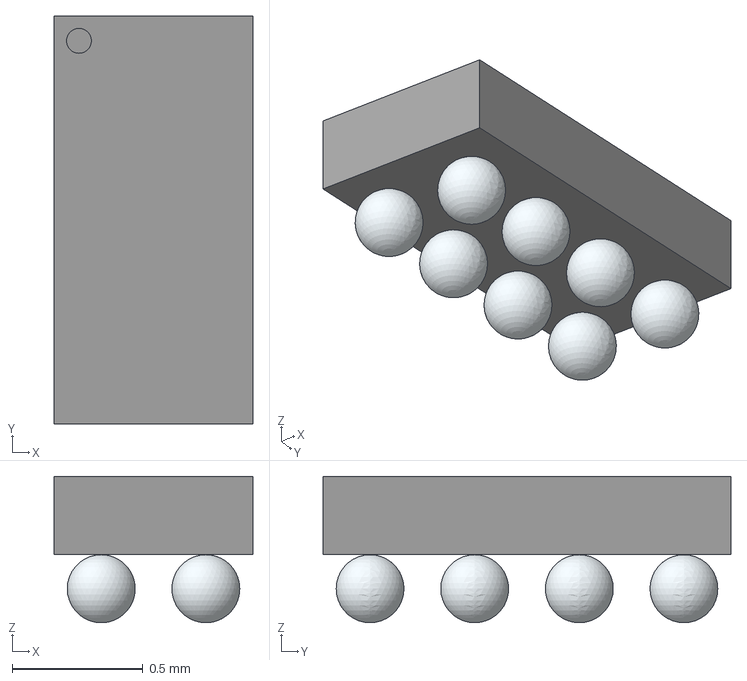
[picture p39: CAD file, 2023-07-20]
PCBs/IM72D128 microphone PCB/IM72D128-Tube-PCB-V1.0/ADAU7002/ADAU7002ACBZ-R7.stp
0.76 x 1.56 x 0.56 mm

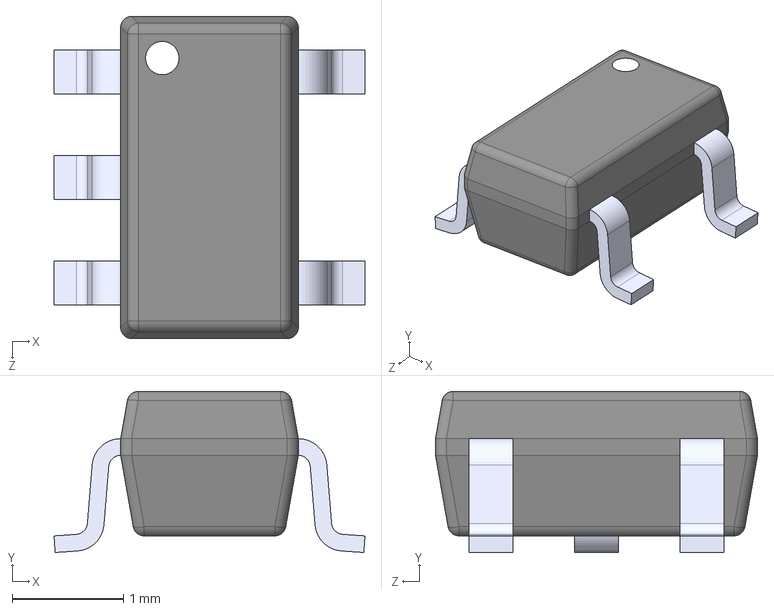
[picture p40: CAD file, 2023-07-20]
PCBs/IM72D128 microphone PCB/IM72D128-Tube-PCB-V1.0/SN74LV1T34DBVR/SN74LV1T34DBVR.step
2.80 x 1.45 x 2.90 mm

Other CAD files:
PCBs/DNMS-RPI-HAT/DNMS-RPI-HAT-V1.0/Phoenix_MKDS/MKDS-1-5-2-5-08_3D.igs
PCBs/DNMS-T4.0/DNMS-T4.0-V1.7/BM06B-SRSS-TB_LF__SN/3D/BM06B-SRSS-TB_LF__SN_.stl
PCBs/ICS-43434 microphone PCB/ICS-43434-PCB-V1.4/BM06B-SRSS-TB_LF__SN/3D/BM06B-SRSS-TB_LF__SN_.stl
PCBs/ICS-43434 microphone PCB/old versions/ICS-43434-PCB-V1.3/BM06B-SRSS-TB_LF__SN/3D/BM06B-SRSS-TB_LF__SN_.stl

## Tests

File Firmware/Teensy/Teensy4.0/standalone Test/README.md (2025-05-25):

# [English text below](#standalone-test-program-for-microphone-and-teensy40)

# DNMS standalone Test Firmware Teensy 4.0

## Testprogramm für den autonomen Test von Mikrofon und Teensy4.0

Mit dieser Firmware kann ein einfacher Test von Mikrofon und Teensy4.0 ohne Anschluss an eine NodeMCU (oder einen anderen Kommunikationsprozessor) direkt mit einem PC/Laptop durchgeführt werden. Da die Firmware auf der gleichen Softwarebasis aufsetzt wie die Firmware Version 5 lassen sich damit auch Messungen mit Ausgabe der LA und LZ Werte an den PC mit einem festen Intervall (von 125ms bis 3600s) durchführen. Abhängig vom Mikrofon existieren zwei Versionen der Firmware:
- ICS-43434 Mikrofon - DNMS_Vt.8.4
- IM72D128 Mikrofon - DNMS_Vt.8.6

### Einsatz der Testprogramme

Die folgenden Schritte sind notwendig:

1. Aufspielen der Firmware DNMS_Vt.8.4 oder DNMS_Vt.8.6 auf dem Teensy4.0 Board

	Die entsprechende Firmware ist auf das Teensy4.0 Board in gleicher Weise aufzuspielen (flashen) wie die normalen Firmware Versionen:
 	- Brücke J1 mit einem Jumper oder einem Dupont-Kabel schließen, damit über das USB-Kabel vom PC her die Stromversorgung übernommen wird.

 	- PC mit dem Teens4.0 USB Anschluss verbinden und mit dem Teensy Loader die Firmware aufspielen (flashen) - siehe dazu den Punkt **Firmware auf das Teensy Board schreiben (flashen)** im README.md unter Firmware/Teensy
 	
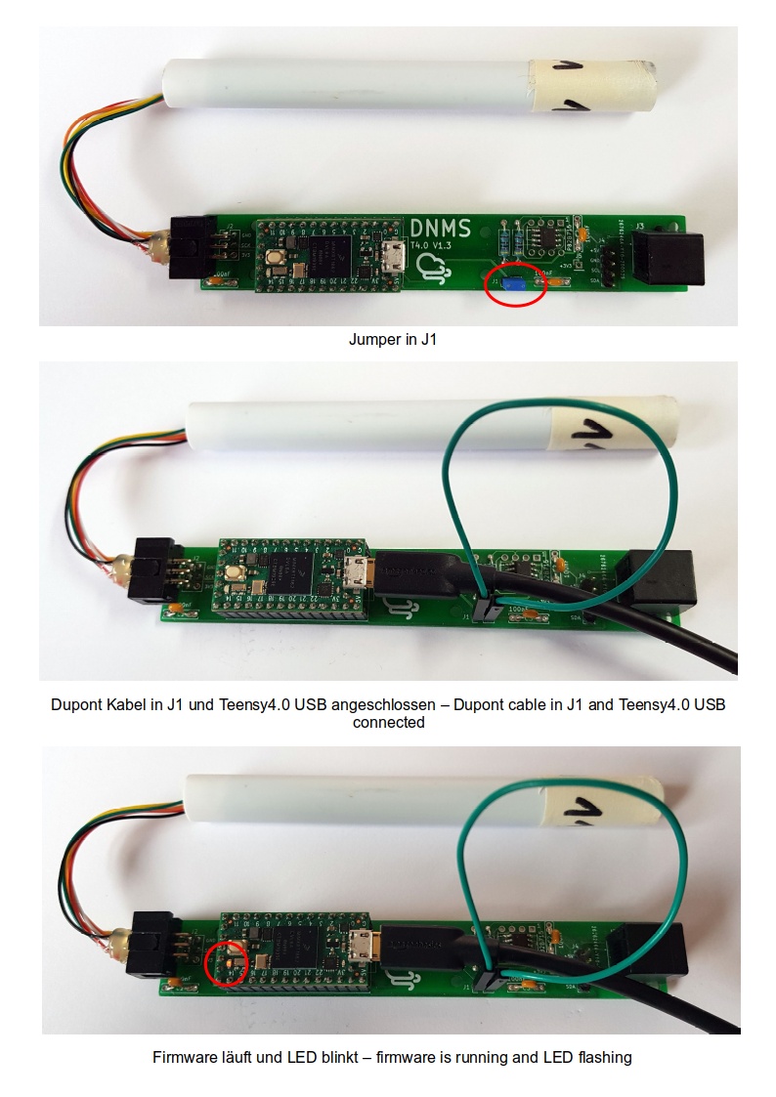
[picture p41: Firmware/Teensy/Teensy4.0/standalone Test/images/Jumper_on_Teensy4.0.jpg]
	<br>

2. Terminalprogramm auf dem PC/Laptop installieren, wenn nicht vorhanden
	
	Um die Test-Ausgaben bzw. die Messwerte vom Teensy4.0 Board zu betrachten ist ein Terminalprogramm auf dem PC/Laptop notwendig wie z.B. Beispiel PuTTY, CoolTerm oder CuteCom (Linux und Mac OS X).
	Die Einstellungen für das Terminalprogramm sind (hier am Beispiel von CoolTerm unter Linux gezeigt): 
	
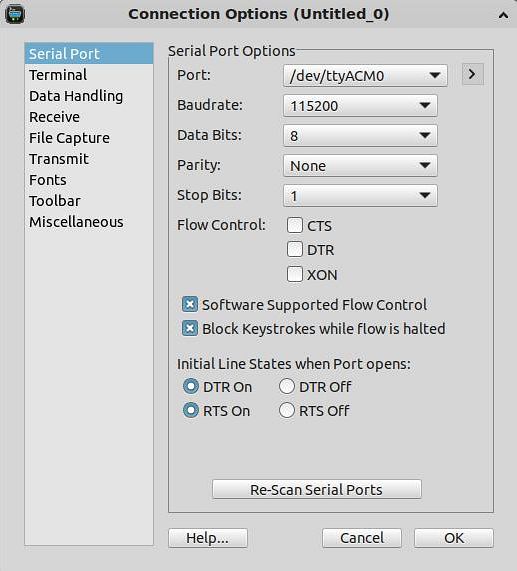
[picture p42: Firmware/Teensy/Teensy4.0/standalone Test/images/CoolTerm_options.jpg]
	<br>	

	Der Portname ist abhängig vom Betriebssystem. Bei Windows ist er über den Gerätemanager zu finden. Unter Linux ist der Name für dasTeensy4.0 Board normalerweise "/dev/tty/ACM0".<br><br> Sollen die Messwerte nicht nur angesehen sondern **auch aufgezeichnet **werden, so ist das bei einigen Terminalprogrammen möglich wie z.B. PuTTY, CoolTerm und CuteCom.

3. Test-Ausgaben bzw. Ausgabe der Messwerte

	Nach dem Start des Testprogramms werden zunächst die folgenden Informationszeilen ausgegeben:
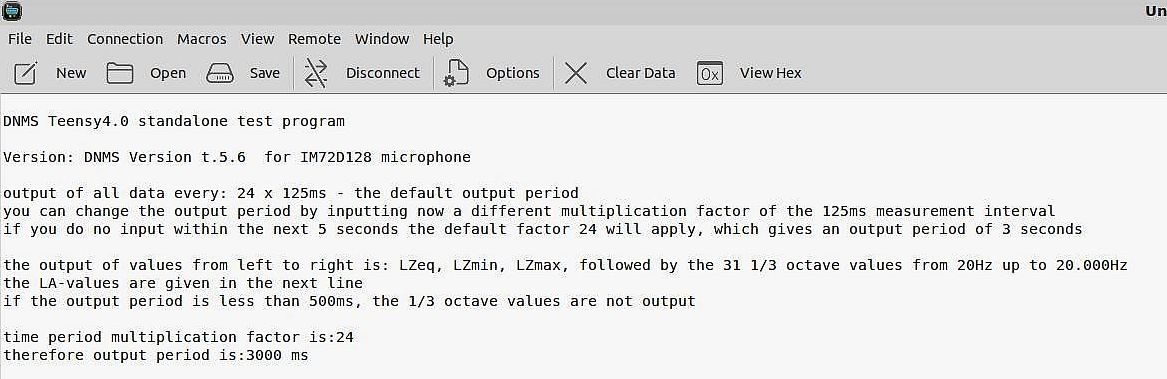
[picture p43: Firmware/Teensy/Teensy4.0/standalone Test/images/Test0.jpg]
	<br>	
	
	Das Messintervall kann innerhalb der ersten 5 Sekunden in Vielfachen von 125ms eingegeben werden. Erfolgt keine Eingabe innerhalb von 5 Sekunden wird als Messintervall der Default Wert von 3 Sekunden (= 24 * 125ms) genommen und die Ausgabe gestartet.
	Das niedrigste Messintervall von 125ms erhält man durch Eingabe einer 1 (= 1 * 125ms). Andere beliebige Messintervalle ergeben sich durch Eingabe einer positiven ganzen Zahl > 0 und der Multiplikation der eingegebenen Zahl mit 125ms.<br><br>
	Die Ausgabe der Messwerte eines Messintervalls erfolgt in zwei Zeilen als CSV Werte. In der ersten Zeile werden die LZ-Werte ausgegeben. Die Zeile beginnt mit der Markierung LZ,. Die zweite Zeile enthält die LA-Werte beginnend mit der Markierung LA,. Von links nach rechts werden ausgegeben LZeq, LZmin, LZmax, dann folgen die LZ-Terzwerte von 20Hz bis 20.000Hz (also 31 Werte). In der zweiten Zeile werden entsprechend die LA-Werte ausgegeben. Eine Leerzeile trennt die Werte der einzelnen Messintervalle.
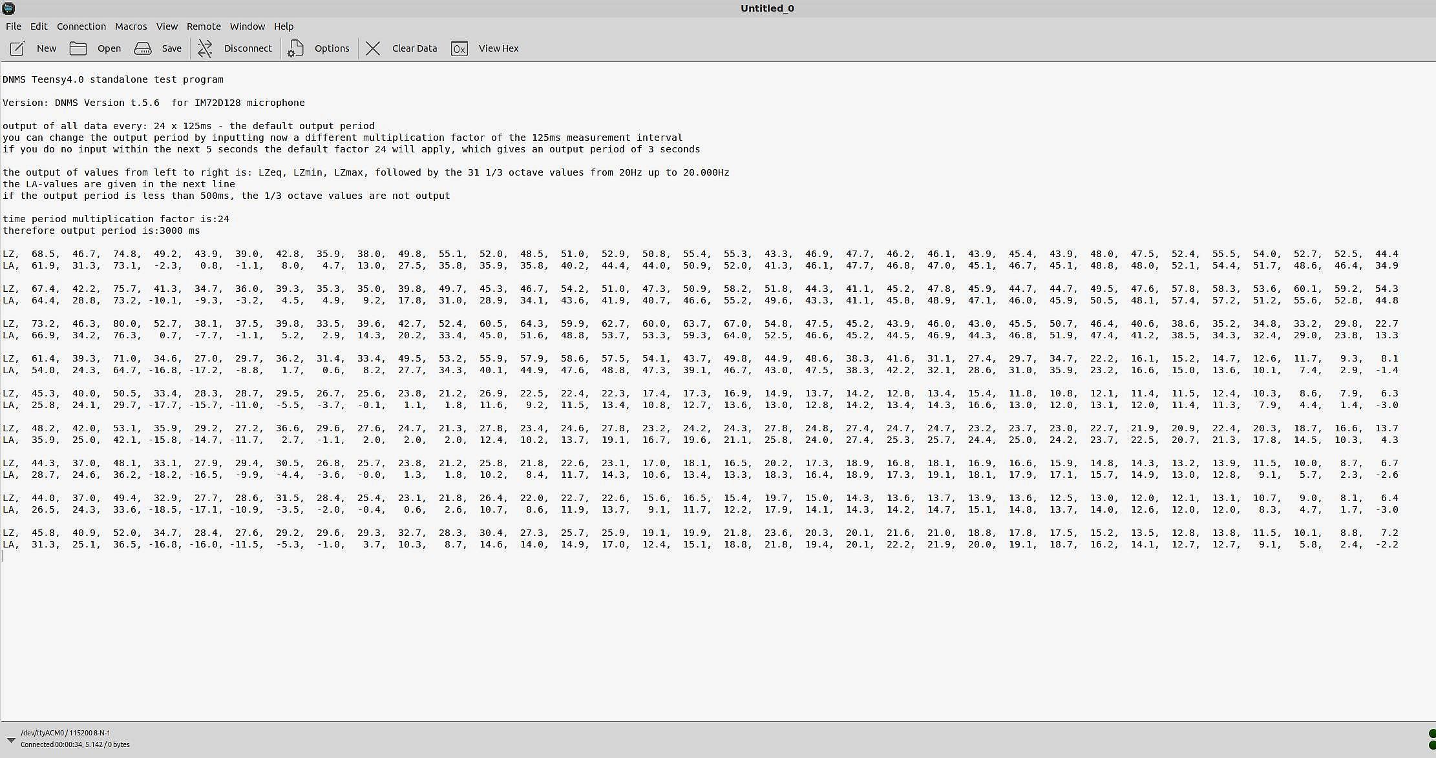
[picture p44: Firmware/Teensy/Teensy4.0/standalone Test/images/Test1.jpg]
	<br>	
	Bei Messintervallen < 500ms (= 4 * 125ms) werden **keine** Terzwerte ausgegeben, sondern nur die drei Werte LZeq, LZmin, LZmax und enstrechend in der zweiten Zeile LAeq, LAmin und LAmax wie das folgende Beispiel zeigt:
	
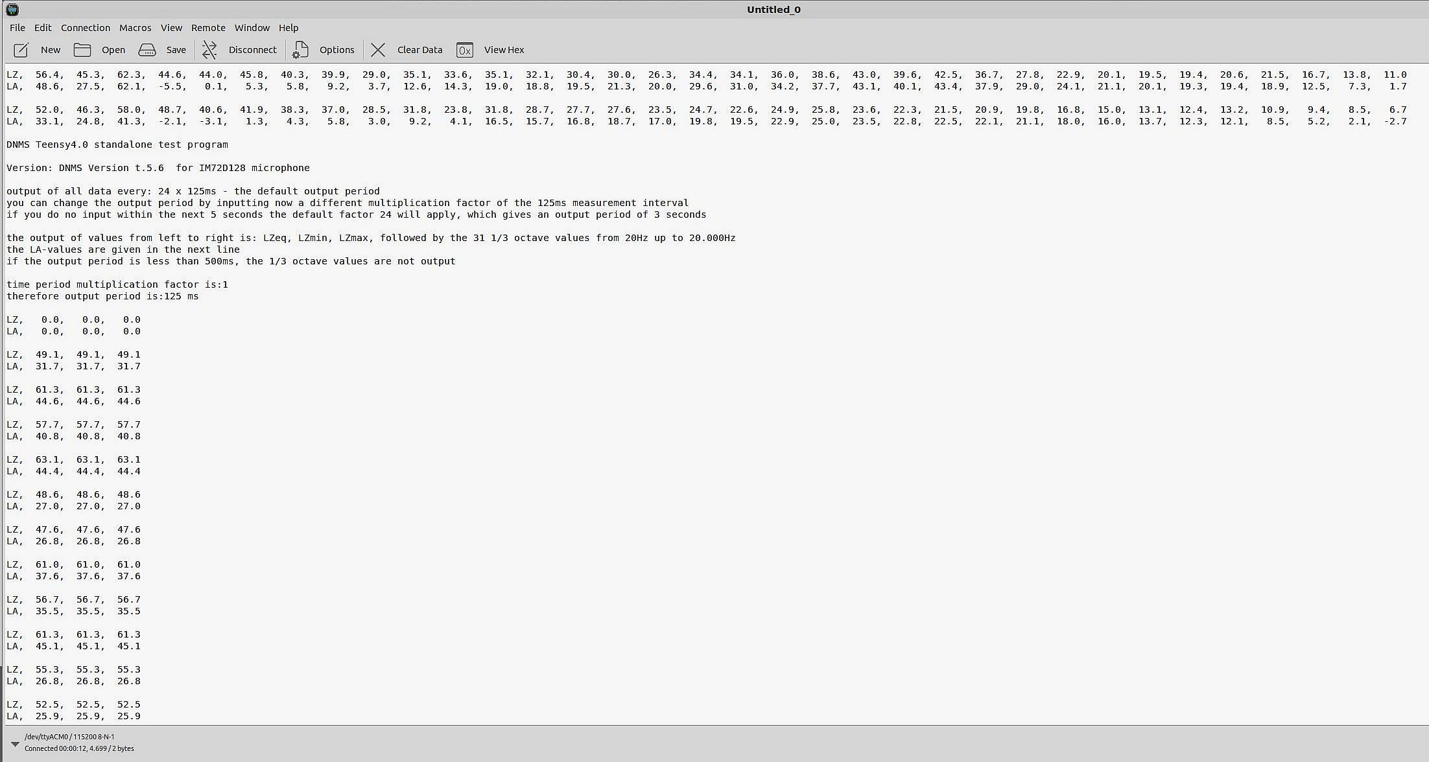
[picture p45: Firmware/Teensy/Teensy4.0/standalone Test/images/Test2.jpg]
	<br>	

4. Änderung des Messintervalls

	Das Messintervalls kann bei laufender Ausgabe geändert werden durch Eingabe des '#' Zeichens. Es erfolgt ein Reset des Teensy4.0 Boards und das Testprogramm startet neu und ein anderer Wert für das Messintervall kann eingegeben werden. Achtung: Da ein Reset des Teensy4.0 erfolgt, wird die USB Verbindung unterbrochen. Einige Terminalprogramme brechen dann ab. Bei einigen Terminalprogrammen lässt sich ein 'Auto Reconnect" einstellen damit das Terminalprogramm nicht abbricht (z.B. CuteCom und CoolTerm, wie das obige Beispiel zeigt).

------------------------------------------------------------------------

## Standalone test program for microphone and Teensy4.0

This firmware allows easy testing of the microphone and Teensy4.0 board without connecting to a NodeMCU (or other communication processor) directly from a PC/laptop. This firmware uses the same software base as the version 5 Teensy firmware and therefore provides the same measurements of LZ and LA values directly to the connected PC/Laptop with fixed measurement intervals (from 125ms to 3600s).
Dependent on the used microphone two versions of the firmware exists:
- ICS-43434 Mikrofon - DNMS_Vt.8.4
- IM72D128 Mikrofon - DNMS_Vt.8.6

### How to use the test programs

Follow the steps below:

1. Flash firmware DNMS_Vt.8.4 or DNMS_Vt.8.6 on the Teensy4.0 board

	Flash the appropriate firmware version in the same way as the normal DNMS firmware for Teensy4.0:
 	- Close J1 with a jumper or a dupont cable to power the Teensy4.0 board via the USB connection from the PC/Laptop

 	- Connect the PC/laptop to the Teensy4.0 USB port and use the Teensy Loader to flash the firmware. 
 	Teensy Loader to flash the firmware - see **How to flash Teensy boards with the firmware** README.md under Firmware/Teensy
 	
	<br>

2. Install a terminal program on your PC/Laptop if none is installed
	
	To get the test outputs respectively the measurement values from the Teensy4.0 board, you need a terminal program on your PC/Laptop. Examples are PuTTY, CoolTerm or CuteCom (Linux and Mac OS X). The serial port options for the terminal program are shown below (example is CoolTerm on Linux):
	
	<br>	

	The port name depends on the operating system of your PC. If it's Windows, check the device manager. On Linux, the name is usually "/dev/tty/ACM0".<br><br>

	If you want to view **and save** the measurements, you can use a terminal program such as PuTTY, CoolTerm or CuteCom.

3. Test output respectively output of measurements 

	When the test program starts, the following lines are output:
	<br>	
	
	Within the first 5 seconds you can set the measurement interval to a multiple of 125ms. If no input is made within the first 5 seconds, the measurement interval will be set to the default value of 3 seconds (= 24 * 125ms) and the output will start.

	The lowest possible measurement interval of 125ms is obtained by entering a 1 (= 1 * 125ms). Other different measurements intervals are obtained by entering a positive integer > 0. This integer is multiplied by 125ms to give the measurement interval.<br><br>
	The readings are output in two lines as CSV values. The first line contains the LZ values. The line starts with the marker LZ,. The second line contains the LA values and starts with the marker LA,. From left to right the output is LZeq, LZmin, LZmax followed by 31 values for the 1/3 octaves from 20Hz to 20,000Hz. The second line shows the LA values. A blank line separates successive measurements.
	
	<br>	
	
	For measurement intervals < 500ms (= 4 * 125ms) **no **1/3 octave values are output. Only the three values LZeq, LZmin, LZmax and in the second line LAeq, LAmin and LAmax are output. This is shown in the following example:
	
	<br>	

4. Change of measurement interval

	It is possible to change the measurement interval while the test program is running by entering the character '#'. This will reset the Teensy4.0 board and restart the program. You can then enter another measurement interval. Attention: because of the reset of the Teensy4.0 board, the USB connection is closed and restarted, but some terminal programs may be shut down. There are terminal programs where you can configure an 'Auto Reconnect', e.g. CuteCom and CoolTerm, as the example above shows.

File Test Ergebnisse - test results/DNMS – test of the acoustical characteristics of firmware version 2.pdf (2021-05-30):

DNMS – test of the acoustical characteristics of firmware version 2

The test was used to validate the measurement range and the measurement accuracy in terms of the DNMS on the basis of firmware version 2. The test was carried out at the HFT Stuttgart (Hochschule für Technik - University of Applied Sciences Stuttgart) in the acoustic laboratories of the Centre for Building Physics (ZFB).

Date: | 03/18/2021 and 04/22/2021
Location: | Anechoic chamber of the ZFB, Stuttgart-Vaihingen
Participants: Andreas Drechsler (HFT Stuttgart) and Helmut Bitter (developer DNMS)

On 03/18/2021, three DNMS systems based on Teensy4.0 were set up. Using two runs, the overall number of six microphones were investigated.

On 04/22/2021, five DNMS systems based on Teensy4.0 were set up and five microphones were tested in one run.

The measurements of the DNMS system were compared against a class 1 certified XL2 Audio and Acoustic Analyzer from NTi Audio (MA220 preamplifier and M2230 capsule). The XL2 was calibrated on both dates before the tests started with a class 1 calibrator.

On 03/18/2021 the following DNMS microphones were measured:

- M2 – round microphoneboard with orthogonally attached board for the signal transport, year of manufacture 6/2020

Figure M2:

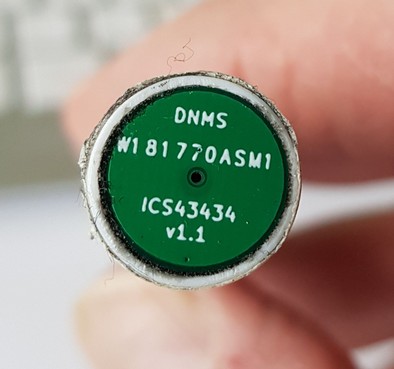
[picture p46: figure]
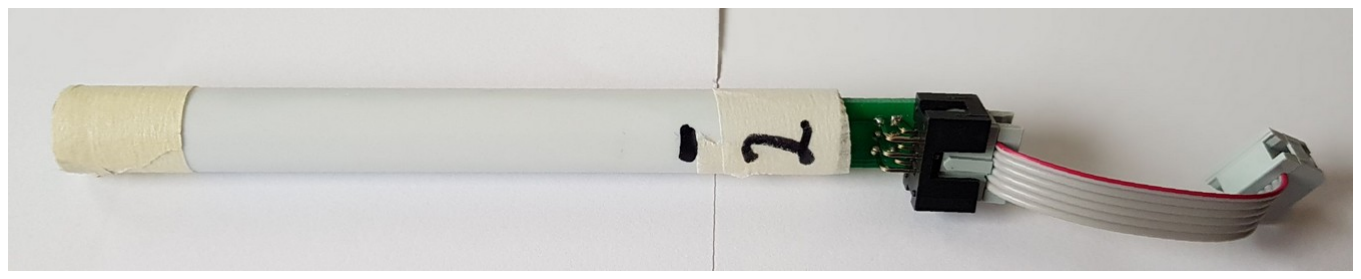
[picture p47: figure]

- N1 – round microphoneboard with molded cable and 2x3 connector, year of manufacture 3/2021

Figure N1:

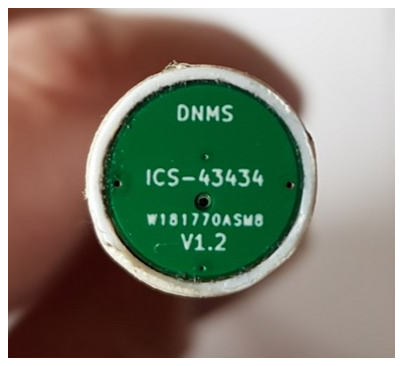
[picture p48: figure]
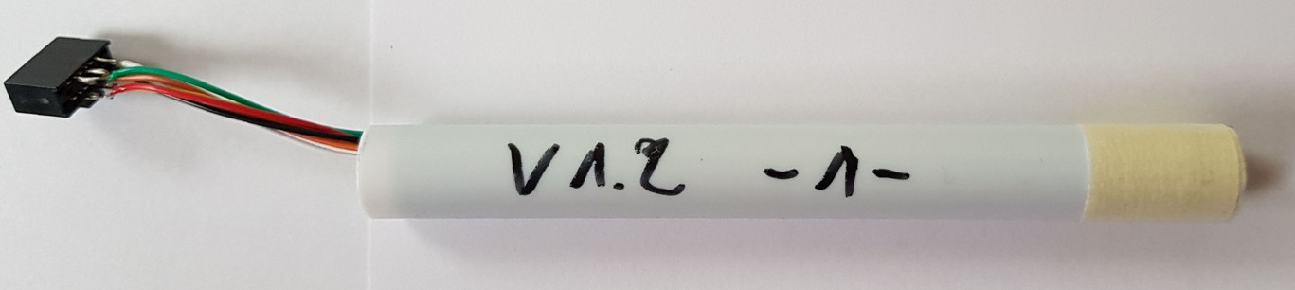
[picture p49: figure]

- N2 - round microphoneboard with molded cable and 2x3 connector, year of manufacture 3/2021 – figure same as N1
- N5 - round microphoneboard with molded cable and 2x3 connector, year of manufacture 3/2021 – figure same as N1
- N6 - round microphoneboard with molded cable and 2x3 connector, year of manufacture 3/2021 – figure same as N1
- N7 - round microphoneboard with molded cable and 2x3 connector, year of manufacture 3/2021 – figure same as N1

On 04/22/2021 the following DNMS microphones were measured:

- N4 - round microphoneboard with molded cable and 2x3 connector, year of manufacture 3/2021 – figure same as N1
- N5 - round microphoneboard with molded cable and 2x3 connector, year of manufacture 3/2021 – figure same as N1
- N6 - round microphoneboard with molded cable and 2x3 connector, year of manufacture 3/2021 – figure same as N11
- M3 – round microphoneboard with orthogonally attached board for the signal transport, year of manufacture 6/2020 – figure same as M2
- E1 – Pesky Breakout Board in 13mm stainless steel tube with molded cable and connector, year of manufacture 4/2021

Figure E1:

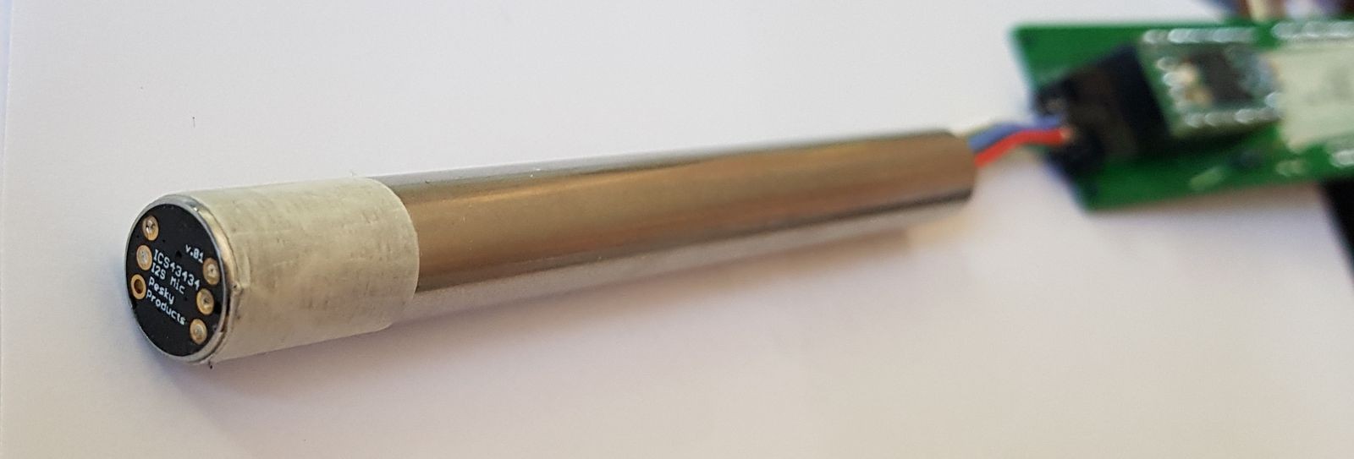
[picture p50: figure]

The following tests were done:

1. On 03/18/2021, test with class 1 calibrator with 94 dB at 1000 Hz, on 04/22/2021, test with class 1 calibrator with 94 dB and 114 dB at 1000 Hz.
2. Estimation of the lower measurement range bound of LAeq (residual noise).
3. Test with PN (Pink Noise) and WN (White Noise) using different levels for microphones M2, N1 and N2 on 03/18/2021 and microphones N4, N5, N6 and S1 on 04/22/2021.

4. Test with PN on 03/18/2021 using different levels for microphones N5, N6 and N7 to measure linearity at low levels and on 04/22/2021 for microphones N4, N5, N6, M3 and S1.
5. Recording wav-fiels of sweeps and chirps with three different levels for evaluation with the ArtemiS SUITE. The recordings from the 18.03.2021 could not be evaluated, because there was an error in these recordings.

Results:

1.1 Test with 94 dB at 1000 Hz class 1 calibrator on 03/18/2021 (values in dB(A)).

XL2 | M2 | N1 | N2 | N5 | N6 | N7
94,0 | 94,44 | 94,29 | 94,15 | 94,09 | 94,18 | 94,48

1.2 Test with 94 dB and 114 dB at 1000 Hz class 1 calibrator on 04/22/2021 (values in dB(A)).

XL2 | N4 | N5 | N6 | M3 | S1
94,0 | 93,93 | 94,39 | 94,08 | 94,16 | 93,83
114,0 | 114,27 | 114,35 | 113,99 | 114,10 | 113,79

2.1 Determination of the lower measurement range bound of the LAeq (residual noise) on 03/18/2021.

XL2 | M2 | N1 | N2 | N5 | N6 | N7
<20 | 27,83 | 28,33 | 26,86 | 28,93 | 27,51 | 28,63

2.2 Determination of the lower measurement range bound of the LAeq (residual noise) on 04/22//2021.

XL2 | N4 | N5 | N6 | M3 | S1
<20 | 28,86 | 29,47 | 27,98 | 29,29 | 27,14

3.1 Test with PN (Pink Noise) and WN (White Noise) at different levels of microphones M2, N1 and N2 on 03/18/2021 (LAeq values in dB(A)).

| XL2 | M2 | N1 | N2
PN | 38,0 | 38,55 | 38,56 | 38,35
WN | 38,2 | 38,82 | 39,01 | 38,85
PN | 50,0 | 50,21 | 50,16 | 50,12
WN | 50,0 | 50,51 | 50,66 | 50,61
PN | 70,0 | 70,13 | 70,10 | 70,02
WN | 70,0 | 70,30 | 70,52 | 70,48

3.2 Test with PN (Pink Noise) and WN (White Noise) at different levels of microphones N4, N5, N6 and S1 on 04/22/2021 (LAeq values in dB(A)).

| XL2 | N4 | N5 | N6 | M3 | S1
PN | 49,8 | 50,03 | 50,24 | 50,04 | 49,97 | 49,45
WN | 50,1 | 50,56 | 50,72 | 50,57 | 50,28 | 49,57
PN | 70,0 | 69,97 | 70,16 | 69,98 | 69,87 | 69,41
WN | 70,0 | 70,52 | 70,66 | 70,52 | 70,22 | 69,53

4.1 Test with PN at different levels of microphones N5, N6 and N7 to determine linearity at low levels on 03/18/2021 (LAeq values in dB(A)).

| XL2 | N5 | N6 | N7
PN | 30,0 | 32,71 | 31,84 | 32,36
PN | 35,0 | 36,71 | 35,62 | 35,85
PN | 40,0 | 40,68 | 40,15 | 40,35
PN | 50,0 | 50,39 | 49,91 | 50,06
PN | 70,0 | 70,28 | 69,81 | 69,96
PN | 85,0 | 85,23 | 84,74 | 84,86

4.2 Test with PN at different levels of microphones N4, N5, N6, M3 and S1 to determine linearity at low levels on 04/22/2021 (LAeq values in dB(A)).

| XL2 | N4 | N5 | N6 | M3 | S1
PN | 30,3 | 32,39 | 32,78 | 32,05 | 32,59 | 31,44
PN | 35,1 | 35,92 | 36,23 | 35,74 | 35,96 | 35,13
PN | 38,0 | 38,48 | 38,72 | 38,37 | 38,49 | 37,81
WN | 38,1 | 38,97 | 39,20 | 38,91 | 38,74 | 37,91

5.1 Recording wav-files of sweeps and chirps at three different levels for evaluation with the ArtemiS SUITE on 03/18/2021.
Evaluation could not be conducted due to incorrect recordings.

5.2 On 04/22/2021, recording wav-files of sweeps and chirps at three different levels (38, 50 and 70 dB(A)) as well as PN and WN for evaluation with the ArtemiS SUITE.
Results are shown in the appendix.

Conclusion of tests by Andreas Drechsler, HFT Stuttgart:
The measurement results of the DNMS microphones compared with the calibrated class 1 XL2 Acoustic Analyzer of NTi Audio are usually below ± 1 dB(A) for single number values. Exceptions are low SPL below 40 dB(A). In this case, differences of up to +3 dB(A) are found. The residual noise of the DNMS microphones is slightly below 30 dB(A).
There is a good agreement in terms of frequency spectra and time signals, also with exceptions for SPL below 40 dB(A). An overestimation at approximately 100 Hz was found that vanishes with increasing levels. It is assumed that there was an injected mains hum during the measurements (see appendix).
The DNMS system and microphones are well suited for the purpose of a do-it-yourself noise sensor. The measurement accuracy is very good for usual environmental noise over a wide frequency and dynamic range.
However, currently no long-term studies are available that show the measurement accuracy over long time as well as the resistance to atmospheric attack and stronger weather conditions.

A constant optimization of the microphones and DNMS system is going on as well as development for simplified do-it-yourself building.

70 L(A) dB(SPL); Ch1 L(A)=37,86 dB(SPL) Ch1 L(A)=37,88 dB(SPL); Ch1 L(A)=49,77 dB(SPL) Ch1 L(A)=49,78 dB(SPL); Ch1 L(A)=69,80 dB(SPL) Ch1 L(A)=69,80 dB(SPL); 70 L dB(SPL); Ch1 L=36,36 dB(SPL) Ch1 L=36,33 dB(SPL); Ch1 L=49,40 dB(SPL) Ch1 L=49,40 dB(SPL); Ch1 L=69,91 dB(SPL) Ch1 L=69,91 dB(SPL)

Appendix: Frequency and time domain evaluation with the ArtemiS Suite, measurements of XL 2 are shown with a red frame

PN_38,0dBA.Pegel über Zeit

PN_49,8dBA.Pegel über Zeit

PN_70,0dBA.Pegel über Zeit

2021-04-22_PN_37,9.Frequenzbewertung.Pegel über Zeit

2021-04-22_PN_49,8.Frequenzbewertung.Pegel über Zeit

2021-04-22_PN_69,8.Frequenzbewertung.Pegel über Zeit

70 L dB(SPL); Ch1 L=36,91 dB(SPL) Ch1 L=36,91 dB(SPL); Ch1 L=50,05 dB(SPL) Ch1 L=50,05 dB(SPL); Ch1 L=70,47 dB(SPL) Ch1 L=70,47 dB(SPL); 70 L(A) dB(SPL); Ch1 L(A)=38,11 dB(SPL) Ch1 L(A)=38,10 dB(SPL); Ch1 L(A)=50,07 dB(SPL) Ch1 L(A)=50,07 dB(SPL); Ch1 L(A)=70,04 dB(SPL) Ch1 L(A)=70,03 dB(SPL)

WN_38,1dBA.Pegel über Zeit

WN_50,1dBA.Pegel über Zeit

WN_70,0dBA.Pegel über Zeit

2021-04-22_WN_38,1.Frequenzbewertung.Pegel über Zeit

2021-04-22_WN_50,1.Frequenzbewertung.Pegel über Zeit

2021-04-22_WN_70.Frequenzbewertung.Pegel über Zeit

70 L dB(SPL); Ch1 L=38,72 dB(SPL) Ch1 L=38,72 dB(SPL); Ch1 L=51,70 dB(SPL) Ch1 L=51,70 dB(SPL); Ch1 L=72,06 dB(SPL) Ch1 L=72,06 dB(SPL); 2021-04-22_CHIRP_38.Frequenzbewertung.Pegel über ...; 70 L(A) dB(SPL); Ch1 L(A)=40,04 dB(SPL) Ch1 L(A)=40,04 dB(SPL); 2021-04-22_CHIRP_50.Frequenzbewertung.Pegel über ...; Ch1 L(A)=52,03 dB(SPL) Ch1 L(A)=52,03 dB(SPL); 2021-04-22_CHIRP_70.Frequenzbewertung.Pegel über ...; Ch1 L(A)=72,00 dB(SPL) Ch1 L(A)=72,01 dB(SPL)

chirp_38dBA.Pegel über Zeit

chirp_50dBA.Pegel über Zeit

chirp_70dBA.Pegel über Zeit

70 L dB(SPL); Ch1 L=37,75 dB(SPL) Ch1 L=37,76 dB(SPL); Ch1 L=50,85 dB(SPL) Ch1 L=50,87 dB(SPL); Ch1 L=71,18 dB(SPL) Ch1 L=71,20 dB(SPL); 70 L(A) dB(SPL); Ch1 L(A)=38,96 dB(SPL) Ch1 L(A)=38,99 dB(SPL); Ch1 L(A)=50,91 dB(SPL) Ch1 L(A)=50,89 dB(SPL); Ch1 L(A)=70,99 dB(SPL) Ch1 L(A)=71,01 dB(SPL)

sweep_38dBA.Pegel über Zeit

sweep_50BA.Pegel über Zeit

sweep_70dBA.Pegel über Zeit

2021-04-22_SWEEP_38.Frequenzbewertung.Pegel über...

2021-04-22_SWEEP_50.Frequenzbewertung.Pegel über...

2021-04-22_SWEEP_70.Frequenzbewertung.Pegel über...

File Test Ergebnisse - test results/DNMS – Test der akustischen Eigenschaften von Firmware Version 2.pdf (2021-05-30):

DNMS – Test der akustischen Eigenschaften von Firmware Version 2

Der Test diente zur Überprüfung des Messbereichs und der Messgenauigkeit des DNMS auf der Basis der Firmware Version 2. Er erfolgte zusammen mit der HFT (Hochschule für Technik, Stuttgart) im Akustik Labor des Zentrums für Akustische und Thermische Bauphysik (ZFB).

Datum: | 18.03.2021 und 22.04.2021
Ort: | Reflexionsarmer Raum im ZFB, Stuttgart-Vaihingen
Teilnehmer: Andreas Drechsler (HFT Stuttgart) und Helmut Bitter (Entwickler DNMS)

Am 18.03.2021 waren 3 DNMS Systeme basierend auf Teensy4.0 aufgebaut. In zwei Durchgängen wurden mit diesen Systemen 6 Mikrofone getestet.

Am 22.04.2021 waren 5 DNMS Systeme basierend auf Teensy4.0 aufgebaut. In einem Durchgang wurden 5 Mikrofone getestet.

Als Vergleichsreferenz kam ein Klasse 1 Audio- und Akustik-Analysator XL2 der Firma NTi Audio mit MA220 Vorverstärker und M2230 Mikrofonkapsel zum Einsatz. Das XL2 wurde zu Beginn der Messreihe am 18.03.2021 und am 22.04.2021 mit einem Klasse 1 Schallkalibrator kalibriert.

Am 18.03.2021 wurden die folgenden DNMS Mikrofone gemessen:

- M2 – rundes Mikrofonboard mit orthogonal aufgesetztem Board für den Signaltransport, Baujahr 6/2020

Abbildung M2:


- N1 - rundes Mikrofonboard mit Anschlussbuchse für Kabel und eingegossenem Kabel, Baujahr 3/2021

Abbildung N1:


- N2 - rundes Mikrofonboard mit Anschlussbuchse für Kabel und eingegossenem Kabel, Baujahr 3/2021 – Abbildung wie N1
- N5 - rundes Mikrofonboard mit Anschlussbuchse für Kabel und eingegossenem Kabel, Baujahr 3/2021 – Abbildung wie N1
- N6 - rundes Mikrofonboard mit Anschlussbuchse für Kabel und eingegossenem Kabel, Baujahr 3/2021- Abbildung wie N1
- N7 - rundes Mikrofonboard mit Anschlussbuchse für Kabel und eingegossenem Kabel, Baujahr 3/2021 – Abbildung wie N1

Am 22.04.2021 wurden die folgenden DNMS Mikrofone gemessen:

- N4 - rundes Mikrofonboard mit Anschlussbuchse für Kabel und eingegossenem Kabel, Baujahr 3/2021 – Abbildung wie N1
- N5 - rundes Mikrofonboard mit Anschlussbuchse für Kabel und eingegossenem Kabel, Baujahr 3/2021- Abbildung wie N1
- N6 - rundes Mikrofonboard mit Anschlussbuchse für Kabel und eingegossenem Kabel, Baujahr 3/2021 – Abbildung wie N1
- M3 – rundes Mikrofonboard mit orthogonal aufgesetztem Board für den Signaltransport, Baujahr 6/2020 – Abbildung wie M2
- E1 – Pesky Breakout Board in 13mm Edelstahlrohr mit angelötetetn Kabeln und eingegossen, Baujahr 4/2021

Abbildung E1:


Folgende Test wurden durchgeführt:

1. Am 18.03.2021 Test mit Kalibrator mit 94 dB bei 1000 Hz, am 22.04.2021 mit 94 dB und 114 dB.
2. Ermittlung des unteren LAeq Messbereichs (Grundgeräusch/Eigengeräusch)
3. Test PN (Pink Noise) und WN (White Noise) mit unterschiedlichen Leveln bei den Mikrofonen M2, N1 und N2 am 18.03.2021 und am 22.04.2021 mit den Mikrofonen N4, N5, N6, M3 und S1.

4. Am 18.03.2021 Test PN mit unterschiedlichen Leveln bei den Mikrofonen N5, N6 und N7 um auch bei niedrigen Leveln die Linearität zu testen und am 22.04.2021 mit den Mikrophonen N4, N5, N6, M3 und S1.
5. Aufnahme Wav-Dateien von Sweep und Chirp Folgen bei jeweils drei unterschiedlichen Leveln und Auswertung im Zeit- und Frequenzbereich mit dem Softwarepaket Artemis. Die Aufnahmen vom 18.03.2021 konnten nicht ausgewertet werden, da die Aufnahmen nicht in Ordnung waren.

Ergebnisse:

1.1 Test mit 94 dB mit 1000 Hz Kalibrator (Werte in dB(A)) am18.03.2021

XL2 | M2 | N1 | N2 | N5 | N6 | N7
94,0 | 94,44 | 94,29 | 94,15 | 94,09 | 94,18 | 94,48

1.2 Test mit 94 dB und 114 dB mit 1000 Hz Kalibrator (Werte in dB(A)) am 22.04.2021

XL2 | N4 | N5 | N6 | M3 | S1
94,0 | 93,93 | 94,39 | 94,08 | 94,16 | 93,83
114,0 | 114,27 | 114,35 | 113,99 | 114,10 | 113,79

2.1 Ermittlung des unteren LAeq Messbereichs (Grundgeräusch/Eigengeräusch, Werte in dB(A)) am 18.03.2021

XL2 | M2 | N1 | N2 | N5 | N6 | N7
<20 | 27,83 | 28,33 | 26,86 | 28,93 | 27,51 | 28,63

2.2 Ermittlung des unteren LAeq Messbereichs (Grundgeräusch/Eigengeräusch, Werte in dB(A)) am 22.04.2021

XL2 | N4 | N5 | N6 | M3 | S1
<20 | 28,86 | 29,47 | 27,98 | 29,29 | 27,14

3.1 Test PN (Pink Noise) und WN (White Noise) mit unterschiedlichen Leveln bei den Mikrofonen M2, N1 und N2 (LAeq Werte in dB(A)) am 18.03.2021

| XL2 | M2 | N1 | N2
PN | 38,0 | 38,55 | 38,56 | 38,35
WN | 38,2 | 38,82 | 39,01 | 38,85
PN | 50,0 | 50,21 | 50,16 | 50,12
WN | 50,0 | 50,51 | 50,66 | 50,61
PN | 70,0 | 70,13 | 70,10 | 70,02
WN | 70,0 | 70,30 | 70,52 | 70,48

3.2 Test PN (Pink Noise) und WN (White Noise) mit unterschiedlichen Leveln bei den Mikrofonen N4, N5, N6, M3 und S1 (LAeq Werte in dB(A)) am 22.04.2021

| XL2 | N4 | N5 | N6 | M3 | S1
PN | 49,8 | 50,03 | 50,24 | 50,04 | 49,97 | 49,45
WN | 50,1 | 50,56 | 50,72 | 50,57 | 50,28 | 49,57
PN | 70,0 | 69,97 | 70,16 | 69,98 | 69,87 | 69,41
WN | 70,0 | 70,52 | 70,66 | 70,52 | 70,22 | 69,53

4.1 Test PN (Pink Noise) mit unterschiedlichen Leveln bei den Mikrofonen N5, N6 und N7 (LAeq Werte in dB(A)) am 18.03.2021

| XL2 | N5 | N6 | N7
PN | 30,0 | 32,71 | 31,84 | 32,36
PN | 35,0 | 36,71 | 35,62 | 35,85
PN | 40,0 | 40,68 | 40,15 | 40,35
PN | 50,0 | 50,39 | 49,91 | 50,06
PN | 70,0 | 70,28 | 69,81 | 69,96
PN | 85,0 | 85,23 | 84,74 | 84,86

4.2 Test PN (Pink Noise) mit unterschiedlichen Leveln und WN mit 38,1 dB(A) bei den Mikrofonen N4, N5, N6, M3 und S1 (LAeq Werte in dB(A)) am 22.04.2021

| XL2 | N4 | N5 | N6 | M3 | S1
PN | 30,3 | 32,39 | 32,78 | 32,05 | 32,59 | 31,44
PN | 35,1 | 35,92 | 36,23 | 35,74 | 35,96 | 35,13
PN | 38,0 | 38,48 | 38,72 | 38,37 | 38,49 | 37,81
WN | 38,1 | 38,97 | 39,20 | 38,91 | 38,74 | 37,91

5.1 Aufnahme Wav-Dateien von Sweep und Chirp Folgen bei jeweils drei unterschiedlichen Leveln am 18.03.2021 und Auswertung im Zeit- und Frequenzbereich mittels Artemis.
Auswertung konnte nicht erfolgen aufgrund fehlerhafter Aufnahmen.

5.2 Aufnahme Wav-Dateien von Sweep und Chirp Folgen bei jeweils drei unterschiedlichen Leveln (38, 50 und 70 dB(A)) am 22.04.2021 und Auswertung im Zeit- und Frequenzbereich mittels ArtemiS Suite.
Dokumentation der Ergebnisse im Anhang, neben Pink Noise und White Noise wurden auch ein Sweep-Signal und ein Chirp-Signal aufgezeichnet und ausgewertet.

Fazit der Messungen von Andreas Drechsler, HFT Stuttgart:
Die Abweichungen der Messergebnisse der DNMS Mikrofone zu den Ergebnissen mit dem kalibrierten Klasse 1 Analysator NTi Audio XL 2 liegen bei den Einzahlwerten fast immer unter ± 1 dB(A). Ausnahme sind sehr geringe Schalldruckpegel unter 40 dB(A). Hier sind größere Abweichungen bis zu + 3 dB(A) feststellbar. Das Eigengeräusch der verwendeten DNMS Mikrofone liegt knapp unter 30 dB(A).
Auch bei den Spektren und Zeitsignalen zeigt sich eine gute bis sehr gute Übereinstimmung, ebenfalls mit Ausnahmen bei geringen Schalldruckpegeln unter 40 dB(A). Hier ist bei den unten dargestellten Auswertungen (siehe Anlage) eine Überhöhung im Bereich von etwa 100 Hz erkennbar, die bei höheren Pegeln verschwindet. Vermutet wird ein bei dieser Messung eingetragenes Netzbrummen, das bei späteren Messungen nicht mehr auftauchte.
Für den Einsatz in den selbstgebauten Lärmsensoren sind die Mikrofone gut geeignet, die Messgenauigkeit ist für übliche Umweltgeräusche sehr gut und das über einen großen Frequenz- und Dynamikbereich.

Noch ausstehend sind Langzeituntersuchungen, die zeigen ob die Messgenauigkeit Bestand hat, auch bei unterschiedlichen Witterungsbedingungen und stärkeren Wettereinflüssen.
An der beständigen Optimierung der Mikrofoneinheiten wird gearbeitet, ebenso an einem vereinfachten Selbstbau.

70 L(A) dB(SPL); Ch1 L(A)=37,86 dB(SPL) Ch1 L(A)=37,88 dB(SPL); Ch1 L(A)=49,77 dB(SPL) Ch1 L(A)=49,78 dB(SPL); Ch1 L(A)=69,80 dB(SPL) Ch1 L(A)=69,80 dB(SPL); 70 L dB(SPL); Ch1 L=36,36 dB(SPL) Ch1 L=36,33 dB(SPL); Ch1 L=49,40 dB(SPL) Ch1 L=49,40 dB(SPL); Ch1 L=69,91 dB(SPL) Ch1 L=69,91 dB(SPL)

Anlage: Spektren und Zeitsignale, Auswertung mit ArtemiS Suite, rot gerahmt die Messungen der XL 2

PN_38,0dBA.Pegel über Zeit

PN_49,8dBA.Pegel über Zeit

PN_70,0dBA.Pegel über Zeit

2021-04-22_PN_37,9.Frequenzbewertung.Pegel über Zeit

2021-04-22_PN_49,8.Frequenzbewertung.Pegel über Zeit

2021-04-22_PN_69,8.Frequenzbewertung.Pegel über Zeit

70 L dB(SPL); Ch1 L=36,91 dB(SPL) Ch1 L=36,91 dB(SPL); Ch1 L=50,05 dB(SPL) Ch1 L=50,05 dB(SPL); Ch1 L=70,47 dB(SPL) Ch1 L=70,47 dB(SPL); 70 L(A) dB(SPL); Ch1 L(A)=38,11 dB(SPL) Ch1 L(A)=38,10 dB(SPL); Ch1 L(A)=50,07 dB(SPL) Ch1 L(A)=50,07 dB(SPL); Ch1 L(A)=70,04 dB(SPL) Ch1 L(A)=70,03 dB(SPL)

WN_38,1dBA.Pegel über Zeit

WN_50,1dBA.Pegel über Zeit

WN_70,0dBA.Pegel über Zeit

2021-04-22_WN_38,1.Frequenzbewertung.Pegel über Zeit

2021-04-22_WN_50,1.Frequenzbewertung.Pegel über Zeit

2021-04-22_WN_70.Frequenzbewertung.Pegel über Zeit

70 L dB(SPL); Ch1 L=38,72 dB(SPL) Ch1 L=38,72 dB(SPL); Ch1 L=51,70 dB(SPL) Ch1 L=51,70 dB(SPL); Ch1 L=72,06 dB(SPL) Ch1 L=72,06 dB(SPL); 2021-04-22_CHIRP_38.Frequenzbewertung.Pegel über ...; 70 L(A) dB(SPL); Ch1 L(A)=40,04 dB(SPL) Ch1 L(A)=40,04 dB(SPL); 2021-04-22_CHIRP_50.Frequenzbewertung.Pegel über ...; Ch1 L(A)=52,03 dB(SPL) Ch1 L(A)=52,03 dB(SPL); 2021-04-22_CHIRP_70.Frequenzbewertung.Pegel über ...; Ch1 L(A)=72,00 dB(SPL) Ch1 L(A)=72,01 dB(SPL)

chirp_38dBA.Pegel über Zeit

chirp_50dBA.Pegel über Zeit

chirp_70dBA.Pegel über Zeit

70 L dB(SPL); Ch1 L=37,75 dB(SPL) Ch1 L=37,76 dB(SPL); Ch1 L=50,85 dB(SPL) Ch1 L=50,87 dB(SPL); Ch1 L=71,18 dB(SPL) Ch1 L=71,20 dB(SPL); 70 L(A) dB(SPL); Ch1 L(A)=38,96 dB(SPL) Ch1 L(A)=38,99 dB(SPL); Ch1 L(A)=50,91 dB(SPL) Ch1 L(A)=50,89 dB(SPL); Ch1 L(A)=70,99 dB(SPL) Ch1 L(A)=71,01 dB(SPL)

sweep_38dBA.Pegel über Zeit

sweep_50BA.Pegel über Zeit

sweep_70dBA.Pegel über Zeit

2021-04-22_SWEEP_38.Frequenzbewertung.Pegel über...

2021-04-22_SWEEP_50.Frequenzbewertung.Pegel über...

2021-04-22_SWEEP_70.Frequenzbewertung.Pegel über...

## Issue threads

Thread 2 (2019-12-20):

Teensy 4.0 und MEMS Alternativen

domcross, 2019-12-20:
Hallo,

Die Firmware für Teensy 4.0 in ja noch in der Entwicklung. Ist schon ein grober Zeithorizont absehbar, wann die Produktionsreife erreicht sein wird?

Das verwendete Mikrofon InvenSense ICS-43434, insbesondere die Variante mit Breakoutboard von Pesky ist in Deutschland schwer zu beschaffen. Gibt es besondere Gründe für genau dieses Modell?
Wie sieht es mit Alternativen aus, z.b. dem Knowles SPH0645 - das gibt es mit Breakoutboard z.B. von Adafruit (Produkt Nr. 3421)? Auf dem Datenblatt sind sich die beiden Mikrofone sehr ähnlich.

Viele Grüße
Dominik

Nordrunner01, 2019-12-20:
@domcross

Jupp, sehe ich auch so. Ich schätze zwar die Arbeit von Pesky, aber.......... Allein der Versand. :-/

Ich werde mein Glück mit einem Günstigprodukt vom freundlichen Ali versuchen (so um die 3€ronen, inkl. P&V). Soviel ist da ja nicht drann. Eigentlich ein Breakoutboard.

Gruß

glosair, 2020-02-26:
I have designed a board to hold a ICS-43434, I2C line driver and the Teensy 4.0 (Same foot print as the Teensy 4.0)

I bought 10 ICS-43434 for just over £20 delivered from Farnell here in the UK.

Tim

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

glosair, 2020-03-22:
I've also an ESP12F board designed ready to go....

I'll make the desgignes open source when fully tested.

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

hbitter, 2020-05-04:
Firmware for Teensy 4.0 is now available.

domcross, 2020-06-02:
@hbitter Bitte noch einen Kommentar zu den Alternativen für das MEMS-Mikro ICS-43434, z.B. dem Knowles SPH0645 - das gibt es mit Breakoutboard z.B. von Adafruit (Produkt Nr. 3421)? Auf dem Datenblatt sind sich die beiden Mikrofone sehr ähnlich - könnte man das verwenden?

Closed 2020-07-16.

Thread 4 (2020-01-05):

problem compilation with DNMS 1.1.0

papybricol, 2020-01-05:
Hello,
I tried to test the DNMS with a Teensy 3.6 using the arduino IDE (vers. 1.8.9).
With the firmware "DNMS_1.1.0.ino" and the library "wire" (from Teensy) it was modified (buffer 64).
The "i2c_t3" library is present in the Teensy folder.

Compilation fails: see attached error messages.

[messages d'erreur.docx](https://github.com/hbitter/DNMS/files/4023541/messages.d.erreur.docx)
There would be: "multiple definition of: i2c0_isr, i2c1_isr" ... in WireKinetis.h ??

Thanks

atze09, 2020-02-27:
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

Did you already solve the Problem? I would be interested in the solution.

papybricol, 2020-02-28:
No, I gave up. It was to test the Teensy with the IDE.
The sensor is now in operation as in the luftdaten assembly

hbitter, 2020-02-29:
@papybricol

I send you a mail with the following content  and don' t know id you didn't get it or if it did not work for you:

If you like to compile the sketch yourself, you have to exchange the includes of "Wire.h" to "i2c_t3.h"  in the Teensy 3.6 Audio Library.

First you have to find the Teensy Audio Library on your system.
The next pictures shows it on my system and the highlighted modules have to be changed but the the .cpp files and not the .h files:
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

Next picture shows the change in one of the files:
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

I hope, it will compile than.
Please let me know if it works:  helmut.bitter@t-online.de

Regards,
Helmut

papybricol, 2020-03-06:
@hbitter

Good evening,
I installed the teensy with ESP and everything works fine. The sensor is on the map (1st in France!)
My question was just for a little test, I was waiting for the delivery of the ESP, now I'm not going to disassemble the sensor.
Thank you for your interest
Papybricol

Closed 2020-05-06.

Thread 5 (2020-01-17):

MEMS günstig beziehen

jensens, 2020-01-17:
Tindie:
> 10,74 € EUR
> Shipping to Austria starts at $14.95 (13,44 € EUR)

Uhh, Ich mein: 13,44 Versand!? Echt?

Was gibt es sonst noch für sinnvolle Bezugsmöglichkeiten?

Den nackten ICS43434 gibts bei Ali, für 2,63 und 3,63 Versand (bleibt gleich bei mehreren).
Aber das wird fummeliges Löten. Würde ich gerne vermeiden.
https://de.aliexpress.com/item/4000540560022.html

Nordrunner01, 2020-01-18:
@jensens Moin Namensvetter.

Jupp, es scheint so, als wenn das Produkt von Pesky im Moment die einzige Wahl ist. Ich finde die hohen Versandkosten auch....... :-1:

Alternative Bezugsmöglichkeiten müssten wir selbst schaffen.

Gruß

Franz4596, 2020-03-21:
Ich habe 02/2020 10x ICS43434 Pesky breakouts gekauft, die lagen fast 4 Wochen bei Zoll Frankfurt und da der Betrag über 22,-€ lag, musste ich 19% USt (ab150€ Zoll) zahlen.
Der Link Aliexpress für " ICS-43434 MIC" ist nun [https://de.aliexpress.com/item/32918814955.html](url),  24€/10St. Mouser.de liefert das schneller (2,14+USt+Vesand). Dazu kommt noch das beakout, R,C-SMD und smd-löten, rentiert sich nur in größeren Stückzahlen. Da finde ich 15€ akzeptabel.

glosair, 2021-01-02:
I'm currently working on a board that will piggyback under the teensy, first version is too thick and has problems with attaching the ICS43434 so might have to go to a flex pcb

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

hbitter, 2021-01-03:
Hi glosair,
I don' t know what your motivation is to place the microphone on a piggypack underneath the Teensy. One thing you should consider is, that the overall frequency response depends heavily on the casing of the microphone. I think the piggyback board will result in some additional refections that may influence the frequency response and thderefor the measurement results. Such a configuration may need additional adjustment of the filters.
Regards,
Helmut

glosair, 2021-01-03:
Hi Helmut

I'm currently working on a new version that will have the same electronics but build on a flex pcb with the ICS43434 extended away from the teensy on a "ribbon".   The prototype had the port pointing away from the teensy.

https://invensense.tdk.com/download-pdf/an-1124-recommendations-for-sealing-invensense-bottom-port-mems-microphones-from-dust-and-liquid-ingress/

hbitter, 2021-01-03:
glosair,

that sound interesting. I know that application note from InvenSense. We tried to get hold of the membrame (McMaster-Carr Part Number 86435K31) they suggested in the AN but had no luck so far to get it deliverd to germany. Perhaps you have better connections and could get some piece of it. Definitely I' m interested to get a piece to test it. You can send me a PM helmut.bitter(at)t-online.de
Regards,
Helmut

pe0ter, 2021-01-03:
Good evening Helmut, glosair,

Instead of trying to source a silicone membrane, isn’t it more practical to glue a 3D printed 1mm thick 12.5mm wide ring with a hole of say 10 mm on top of the DNMS microphone unit, then pull the thinnest condome on the market over it, hold it in place with some tape and cover it with the foam cap?

Met vriendelijke groet,
Peter

On 3 Jan 2021, at 17:39, Helmut Bitter <notifications@github.com> wrote:

glosair,

that sound interesting. I know that application note from InvenSense. We tried to get hold of the membrame (McMaster-Carr Part Number 86435K31) they suggested in the AN but had no luck so far to get it deliverd to germany. Perhaps you have better connections and could get some piece of it. Definitely I' m interested to get a piece to test it. You can send me a PM helmut.bitter(at)t-online.de
Regards,
Helmut

—
You are receiving this because you are subscribed to this thread.
Reply to this email directly, view it on GitHub, or unsubscribe.

glosair, 2021-01-03:
Evening Peter

Think the problem with a condom is the uniformity, they generally are formed by dipping so even the thickness of the material changes from one to the next and so would the acoustic properties.  They are also not rated for outdoor use.

The McMaster-Carr part number appear to be wrong and should be 86435K121 the digits following the K are just the thickness and panel size. 121 is 0.01" thick and 6"x6"

    Color: 10A sheets: Gray; 20A sheets: Black; 35A sheets: Cream
    Temperature Range: -80° to 425° F
    Tensile Strength: 10A sheets: 250 psi; all other sheets: 800 psi
    For Use Outdoors: Yes

Tim

Franz4596, 2021-01-04:
Helmut B. and me, and some friends of me tried to order the **MCMaster-Carr silicone sheet**, with anwer: „Thank you for considering McMaster-Carr for your purchase.  However, we will not accept orders from your location due to the cost of complying with US export regulations.“ and "We have no locations outside of the United States, and cannot suggest another source for these items.  We apologize for not helping you further."

I use for protection a kitchen clingfilm (**Frischhaltefolie**) which is very thin and better than a condome. I put it directly over the top of the micro and measured ~1dB damping.

And the German Wacker-Siliconfolie (Elastosil / SILPURAN® FILM 2030) shall not good for outdoor applications, due to strong pollute themselve.

Franz

pe0ter, 2021-01-04:
Danke Franz,

Frischhaltefolie, I have plenty of that.
I have 5 sets DNMS + microphone available, I wil use my iphone as a signal generator and see if I can compare and log the differences between 2 microphones, first without then one with Folie.

Met vriendelijke groet, mit freundlichem Gruß, best regards,
Peter

On 4 Jan 2021, at 03:00, franz <notifications@github.com> wrote:

Helmut B. and me, and some friends of me tried to order the MCMaster-Carr silicone sheet, with anwer: „Thank you for considering McMaster-Carr for your purchase. However, we will not accept orders from your location due to the cost of complying with US export regulations.“ and "We have no locations outside of the United States, and cannot suggest another source for these items. We apologize for not helping you further."

I use for protection a kitchen clingfilm (Frischhaltefolie) which is very thin and better than a condome. I put it directly over the top of the micro and measured ~1dB damping.

And the German Wacker-Siliconfolie (Elastosil / SILPURAN® FILM 2030) shall not good for outdoor applications, due to strong pollute themselve.

Franz

—
You are receiving this because you commented.
Reply to this email directly, view it on GitHub, or unsubscribe.

buv, 2021-01-21:
Hei,

Frischhaltefolie sounds great and is simple. I like that. The foil will act like a drum. I suspect, that depending on the strength one uses to apply the foil to the mic, there will be a resonance at a certain frequency induced in the system. Did anyone try to measure the frequency dependance of the damping induced by the foil?

Greetings,
Burkhard

buv, 2021-01-21:
Hei Helmut,

thank you. Very interesting. So I was roughly wrong by a factor of two with my estimation of the resonance frequency. Talking about response functions: How did you obtain the coefficients of the biquad filter? Does it contain the uncovered mic response?

Greetings,
Burkhard

hbitter, 2021-01-22:
Hi Burkhard,

coefficients of biquad filter:
that was a mixture of using software for calculating the coefficients than doing a lot of measurements and repetitions of that.

We did overall measurements including the microphone frequency response in the proposed casing (1/2" tube and molded).

Regards,
Helmut

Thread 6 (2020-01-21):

Firmware Teensy 4.0

alexvr6, 2020-01-21:
Hallo,

kann man mittlerweile abschätzen wie lange es mit der Firmware noch dauert? Da auf Luftdaten.info leider nicht erwähnt wird, das die Firmware noch nicht erhältlich ist habe ich mir den Teensy 4.0 bestellt. Habe dann bei Zusammenbau erst mitbekommen, das dir Firmware noch nicht erhältlich ist.
Ansonsten gute Arbeit, macht weiter so....

julianw10, 2020-02-16:
Genau dasselbe Problem habe ich auch. Da ich dachte, dass der Teensy 4.0 unterstützt wird, wie auf der Website größtenteils, habe ich den auch bestellt. Jetzt muss ich feststellen, dass es keine Firmware gibt. Gibt es ein voraussichtliches Veröffentlichungsdatum oder einen Vorabzugriff auf die Firmware?

mdietinger, 2020-02-20:
Schließe mich den vor Postern an.
Habe mir auch einen Teensy 4.0 zugelegt.
Bin auch gerne bereit Beta Test zu unterstützen.

atze09, 2020-02-21:
Ich mich auch, habe auch bereits den Teensy 4.0 bestellt und würde auch die Beta Phase zu unterstützen!

alexvr6, 2020-02-22:
Da bin ich ja nicht der einzigste...

Wenn jemand interesse hat, ich habe noch 4 Platinen T3.6+NodeMCU V1.0 und eine komplette Bestückte T4+NodeMCU V1.2...

atze09, 2020-02-23:
Eine ungefähre Aussage wäre super. Ob 1 Woche, 1 Monat oder eher 1 Jahr? Dann würde ich auf das Angebot oben zurück kommen;)

atze09, 2020-02-23:
> Da bin ich ja nicht der einzigste...
>
> Wenn jemand interesse hat, ich habe noch 4 Platinen T3.6+NodeMCU V1.0 und eine komplett Bestückte T4+NodeMCU V1.2...

Ich hätte Interesse an der T3.6 er Platine.

alexvr6, 2020-02-23:
Schreib mir mal zimmerplatz@alexvr6.de

Nordrunner01, 2020-02-25:
Moinsen.

Vielleicht ist ein gangbarer Weg mal bei den Leuten von [luftdaten.info](https://luftdaten.info/) nachzufragen. Immerhin wird dort auf das DNMS verwiesen und die dortige Infrastruktur genutzt. Siehe: https://luftdaten.info/einfuehrung-zum-laermsensor/#top . Fragen zum Projekt werden im Allgemeinen im Git diskutiert: https://github.com/opendata-stuttgart/sensors-software/issues

Gruß

glosair, 2020-02-26:
Didn't realize that the firmware isn't ready yet so designed a board to hold the mic and a teensy 4.0 (the same size as a teensy 4.0) and a new board that holds a high efficiency switching power supply, ESP12F, I2c line driver and RFM96 Lora radio.

domcross, 2020-04-22:
As I understand from #9 the major roadblock is the unstable I2C communication. I just ran over https://github.com/Richard-Gemmell/teensy4_i2c which is a drop in replacement for the Teensy-wire library - did you try that already?

hbitter, 2020-04-23:
Hi Dominik,
the lib from Richard Gemmell is at thge moment the only I²C Arduino lib that supports slave mode. So yes, I tried that lib, with the result, that the I²C communication is very unstable. I tried to conntact Richard Gemmell but so far I got no response. So I hope that the Teensy developer, Paul Stoffregen, will add slave mode to his lib.
Regards,
Helmut Bitter

Closed 2020-05-06.

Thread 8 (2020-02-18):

Sensirion SPS30

alexvr6, 2020-02-18:
Da ja das Teensy 4.0 noch nicht funktioniert, habe ich mir DNMS - T3.6+NodeMCU zusammengebastelt. Hier wird jedoch nicht der Sensirion SPS30 ausgelesen. Der Feinstaubsensor funktioniert an sich, nur passiert nichts wenn er an das DNMS - T3.6+NodeMCU angeschlossen ist.
Hat jemand eine Ahnung warum der nicht funktioniert?

mdietinger, 2020-02-18:
Der SPS30 hängt am I2C Bus des NodeMCUs?(D3/D4)
Funktioniert der Sensor wenn T3.6 nicht am Bus hängt?

hbitter, 2020-02-18:
Die NodeMCU Firmware "NRZ-2020-129" hat ein fehlerhaftes I²C Timing. Einige Sensoren funktionieren damit trotzdem (z.B. DNMS oder auch BME280) aber der Sensirion SPS30 Feinstaubsensor nicht!
Bitte die Beta Firmware (z.Zt. "NRZ-2020-130-B5") benutzen, damit funtioniert es zumindest bei mir.

atze09, 2020-03-01:
Hello guys,
First of all this is an awesome project.

I build 3x DNMS - T4+NodeMCU and 1x DNMS - T3.6+NodeMCU and have two new Sensiron SPS30.
Everything work fine, except the Feinstaub sensor Sensiron SPS30.
I tried all the 4 boards and two Sensors on each board and always get the followed error :
`13:23:04.564 -> Read SPS30...
13:23:04.564 -> Trying SPS30 sensor on 0x69H  ... not found
13:23:04.700 -> Check SPS30 wiring`

I measured the voltages of the sensor cable and they where at Pin 1=5V and Pin 2 and 3=3,3V.
Can anybody help me with this issue?
Maybe my sensors are defective..

Thank you
Danke.

Franz4596, 2020-03-21:
SPS30 läuft dank Tipp Beta  "NRZ-2020-130-B5" auch bei mir (mit NRZ-2020-129 nicht).

Closed 2020-05-06.

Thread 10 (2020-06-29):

Wrong Gerber-Files

imaluschi, 2020-06-29:
Hi, i ordered PCB's according to the downloaded DNMS-master.zip from 11.03.2020.
The Gerber Files from DNMS-T3.6-V1.2 where used. Now i've got all parts her and saw, there are only 5 connections for I2C-extension, not 6 for the RJ12-Jack as it was proposed to be.
I saw, on 8th of May there where the gerber files changed, so the actual V1.2 seems different. AAAArgh!!!!

15 PCB's - so how can i "repair" them to use them?
The ordered PCB's, "old" V1.2:
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
The "new" V1.2:
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

Franz4596, 2020-06-30:
Hi, that is not a problem.
Cut off one RJ12-Connector from RJ12-6p6s-cable and solder the 6 wires to J2 dirctly, or use a 4 pin female pin header, see photo.
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
You can drill RJ12 holes in PCB and solder Cu wires between RJ12 and J2.
greetings franz

imaluschi, 2020-07-02:
Thanks for your comment.
Have to try which solution suits best for me.
I wanted to use the cables as they are (connection is safest), so maybe I'll try to mount the connectors first.

hbitter, 2020-07-05:
Hi,
I just came back from a trip a saw what I messed up. I'm really sorry for that.
Please, give me a PM to my mail address helmut.bitter@t-online.de. I will think about how I can compensate it.
Sorry for that.
Regards,
Helmut

hbitter, 2020-07-06:
Hi,
you can try to mount the RJ11/12 connectors as I described in the attached PDF. Please, give me a personal mail to my address above.
Regards,
Helmut
[A possible fix.pdf](https://github.com/hbitter/DNMS/files/4881359/A.possible.fix.pdf)

Closed 2020-07-14.

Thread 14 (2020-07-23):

Teensy mit Arduino flashen, Bibliotheken überschneiden sich

Melnilie, 2020-07-23:
Hallo,

ich hab versucht meinen Teensy4.0 mit dem TeensyLoader zu flashen, aber aus irgendeinem Grund ging das nicht.
Also habe ich es mit der Arduino IDE probiert. Das Testprogramm ging auch, aber wenn ich versuche DNMS_V1.0.4 draufzuladen, bekomme ich diesen Fehler

> /tmp/arduino_build_726161/libraries/Wire/WireIMXRT.cpp.o:(.data.Wire2+0x0): multiple definition of `Wire2'
/tmp/arduino_build_726161/libraries/teensy4_i2c-master/i2c_driver_wire.cpp.o:(.bss.Wire2+0x0): first defined here
/home/user/Downloads/arduino-1.8.13/hardware/tools/arm/bin/../lib/gcc/arm-none-eabi/5.4.1/../../../../arm-none-eabi/bin/ld: Disabling relaxation: it will not work with multiple definitions
/home/user/Downloads/arduino-1.8.13/hardware/tools/arm/bin/../lib/gcc/arm-none-eabi/5.4.1/../../../../arm-none-eabi/bin/ld: Warning: size of symbol `Wire2' changed from 116 in /tmp/arduino_build_726161/libraries/teensy4_i2c-master/i2c_driver_wire.cpp.o to 112 in /tmp/arduino_build_726161/libraries/Wire/WireIMXRT.cpp.o
/tmp/arduino_build_726161/libraries/Wire/WireIMXRT.cpp.o: In function `Print::availableForWrite()':
/home/user/Downloads/arduino-1.8.13/hardware/teensy/avr/libraries/Wire/WireIMXRT.cpp:235: multiple definition of `Wire1'
/tmp/arduino_build_726161/libraries/teensy4_i2c-master/i2c_driver_wire.cpp.o:/home/user/Arduino/libraries/teensy4_i2c-master/src/i2c_driver_wire.cpp:123: first defined here
/home/user/Downloads/arduino-1.8.13/hardware/tools/arm/bin/../lib/gcc/arm-none-eabi/5.4.1/../../../../arm-none-eabi/bin/ld: Warning: size of symbol `Wire1' changed from 116 in /tmp/arduino_build_726161/libraries/teensy4_i2c-master/i2c_driver_wire.cpp.o to 112 in /tmp/arduino_build_726161/libraries/Wire/WireIMXRT.cpp.o
/tmp/arduino_build_726161/libraries/Wire/WireIMXRT.cpp.o: In function `Print::availableForWrite()':
/home/user/Downloads/arduino-1.8.13/hardware/teensy/avr/libraries/Wire/WireIMXRT.cpp:235: multiple definition of `Wire'
/tmp/arduino_build_726161/libraries/teensy4_i2c-master/i2c_driver_wire.cpp.o:/home/user/Arduino/libraries/teensy4_i2c-master/src/i2c_driver_wire.cpp:123: first defined here
/home/user/Downloads/arduino-1.8.13/hardware/tools/arm/bin/../lib/gcc/arm-none-eabi/5.4.1/../../../../arm-none-eabi/bin/ld: Warning: size of symbol `Wire' changed from 116 in /tmp/arduino_build_726161/libraries/teensy4_i2c-master/i2c_driver_wire.cpp.o to 112 in /tmp/arduino_build_726161/libraries/Wire/WireIMXRT.cpp.o
collect2: error: ld returned 1 exit status
Fehler beim Kompilieren für das Board Teensy 4.0.

Ich wollte jetzt auch nichts an den Librarys ändern, deshalb habe ich da noch nichts versucht.
Wäre cool, wenn mir jemand helfen könnte.

hbitter, 2020-07-23:
Hallo Melnilie,
1. Problem Teensy4.0 mit TeensyLoader flashen
Sind die herunter geladenen Files O.K.? Am besten geht das, wenn man das gesamte Repository als Zip herunterlädt.
Schau Dir mit einem Hex-Editor z.B. mal DNMS V1.0.5.ino.hex oder DNMS V1.0.4.ino.hex an, sieht das so aus, wie im angehangenen Bild?
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

Wenn nicht, der Tipp das gesamte Repository als Zip File herunterladen und es dann das Flashen mit TeensyLoader probieren.

2. Problem Firmware in der Arduino IDE komplieren
Da sind einige kleine Anpasungen notwendig:

1. You have to install Arduino IDE (Version 1.8.13) an Teensyduino (1.53)

For Teensy3.6:

2. As you can see in the code the lib i2c_t3.h is included, this lib is used instead of of the Wire.h lib. You can download that lib from github as a zip and install it in Arduino.

3. In the Teensyduino Audio lib you have to change all "#include Wire.h" to "#include <i2c_t3.h>". Where the Teensyduino Audio lib is located depends on your used Operating Sytem and your installation. On my Linux it located under: /home/helmut/Arduino-SW/arduino-1.8.13/hardware/teensy/avr/libraries/Audio/. In that directory you will find several files named: control_xxxxx.cpp. In all those files change "#include Wire.h" to "#include <i2c_t3.h>"

It should now compile.

For Teensy4.0:

2. As you can see in the code instead of the Wire.h lib another I²Cl ib is used for Teensy4.0. It is the lib teensy4_i2c. You can download that lib from github as a zip and install it in Arduino.

3. Now you have to change in the Teensyduino Audio lib all "#include Wire.h" to #include <i2c_driver.h> and #include <i2c_driver_wire.h> as described under 3. fpr Teensy3.0

It should now compile.

Ich hoffe, damit geht es. Bitte Rückmeldung an mich auch gerne direkt an helmut.bitter (at) t-online.de

Viele Grüße
Helmut

Melnilie, 2020-07-23:
Hallo Helmut,

Danke für die Übersicht.
Ich hatte mir nachdem ich hier gepostet habe, den TeensyLoader nochmal neu installiert und auch die Dateien neu runtergeladen und jetzt ging das Flashen auch.
Ich bekomme jetzt über die serielle Schnittelle die Mikrofondaten, aber wenn ich das ganze an den NodeMCU anschließe und DNMS auf der Konfigurationsseite anklicke, bekomme ich über die Webseite keine Daten.
Ich hab auch schon an SCL und dem SDA Anschluss einen 5k Widerstand an 3,3V angeschlossen und das hat auch nicht geholfen . Hast du da vielleicht noch eine Idee?

Viele Grüße
Mel

hbitter, 2020-07-23:
Hallo Mel,

was heißt "Ich bekomme jetzt über die serielle Schnittelle die Mikrofondaten"? Welche Firmware ist da auf dem Teensy4.0? Und welche serielle Schnittstelle ist gemeint, die vom Teensy4.0 oder von der NodeMCU?
Wenn Du die DNMS_V1.0.4 oder .5 Firmware auf dem Teensy hast, werden über die serielle Schnittstelle keine Werte ausgegeben. Das Testprogramm DNMS_Vt.0.4 gibt die Werte über die serielle Schnittstelle aus aber hat keine Kommunikation zur NodeMCU (dient zum Test ohne NodeMCU). Wenn es so ist, bitte die DNMS_V1.0.4 oder .5 Firmware auf dem Teensy flashen.
Wenn NodeMCU und Teensy geflasht sind, serielle Schnittstelle der NodeMCU anschließen und mit Terminalprogramm den Debug Output ansehen. Evtl. einmal Reset Taste auf der NodeMCU drücken um den kompletten Vorgang beim Start zu betrachten.
Output sollte dann ungefähr so aussehen:
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

Wichtig sind die Zeilen, dass sich die NodeMCU mit dem WLAN verbindet und dann, wenn DNMS konfiguriert ist (Read DNMS ...) die nächste Zeile, die zeigt, ob der DNMS gefunden wurde.

Kommst Du soweit?
Viele Grüße
Helmut

Melnilie, 2020-07-27:
Hallo Helmut,

Entschuldige die späte Antwort, ich komm wegen Cornoa nicht so oft in unser Lab.
Ich habe die Hex Dateien angesehen und die sehen richtig aus, warum das nicht über den Teensyloader geht, kann ich mir nicht erklären.
Allerdings habe ich jetzt die Audio Bibliotheken geändert und dann die Firmware auf den Teensy geladen.
Im Output steht leider immer noch, dass er den DMNS nicht findet, aber der Feinstaubsensor und der Temperatursensor gehen.

Viele Grüße
Mel

hbitter, 2020-07-27:
Hallo Mel,

ich bin z.Zt. unterwegs und melde mich Anfang nächster Woche wieder.

Viele Grüße
Helmut

-----Original-Nachricht-----
Betreff: Re: [hbitter/DNMS] Teensy mit Arduino flashen, Bibliotheken
überschneiden sich (#14)
Datum: 2020-07-27T09:11:14+0200
Von: "Melnilie" <notifications@github.com>
An: "hbitter/DNMS" <DNMS@noreply.github.com>
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
Melnilie, 2020-07-30:
Hallo,

Ich benutze den Teensy 4.0 hab das jetzt in der WireKinetis Bibliothek trotzdem mal auskommentiert, leider keine Veränderung.

imaluschi, 2020-07-30:
Hallo,

bei mir funktioniert es auch mit Teensy 4.0 nach folgenden Schritten:
Wie von Helumt erklärt, die Schritte für Teensy 4.0:
https://github.com/hbitter/DNMS/issues/14#issuecomment-662954198
Die von mir beschriebene Änderung für Teensy 3.6 in der WireKinetis.h wurde so belassen, für Teensy 4.0 scheint dies irrellevant zu sein, da ja
```
// Teensy 3.6
#elif defined(__MK66FX1M0__)
```
Da gibts kein `if defined` für Teensy 4.0.

Ich hab die Audio Lib (in Arduino-Installation.../arduino-1.8.13/hardware/teensy/avr/libraries/Audio), allle control*.cpp nun gleich die Zeile `#include <Wire.h>` so abgeändert:
```
//#include <Wire.h>
//#include <i2c_t3.h> //Teensy 3.6
#include <i2c_driver.h> //Teensy 4.0
#include <i2c_driver_wire.h>
```
Theoretisch müsste es möglich sein, auch dort überall eine if-Abfrage machen (Teensy 3.6 oder Teensy 4.0).

hbitter, 2020-07-30:
Also ich empfehle fogendes Vorgehen beim Teensy4.0
1. Testprogramm DNMS_Vt.0.4 auf Teensy flashen und Output über USB/Terminalprogramm ansehen
2. Flashen des Teensy mit DNMS_V1.0.4.ino.hex. Es gibt eigentlich keinen Grund, dass das Flashen nicht geht, wenn es mit dem Testprogramm ging. Wenn man das DNMS_V1.0.5.ino.hex nimmt, wird über USB dasAudio Signal ausgegeben, das man z.B. mit Audacity ansehen/aufzeichnen. Damit ist dann sichergestellt, dass Das Programm auf dem Teensy läuft. (das geht natürlich auch mit dem Teensy3.6 - DNMS_V1.1.1.ino.hex).
3. Zum Test der I²C-Kommunikation gibt es für die NodeMCU einen I²C Scanner:

`/*
* i2c_port_address_scanner
* Scans ports D0 to D7 on an ESP8266 and searches for I2C device. based on the original code
* available on Arduino.cc and later improved by user Krodal and Nick Gammon (www.gammon.com.au/forum/?id=10896)
* D8 throws exceptions thus it has been left out
*
*/

#include <Wire.h>

void setup() {
  Serial.begin(9600);
  while (!Serial);             // Leonardo: wait for serial monitor
}

uint8_t portArray[] = {16, 5, 4, 0, 2, 14, 12, 13};
//String portMap[] = {"D0", "D1", "D2", "D3", "D4", "D5", "D6", "D7"}; //for Wemos
String portMap[] = {"GPIO16", "GPIO5", "GPIO4", "GPIO0", "GPIO2", "GPIO14", "GPIO12", "GPIO13"};

void scanPorts() {
  for (uint8_t i = 0; i < sizeof(portArray); i++) {
    for (uint8_t j = 0; j < sizeof(portArray); j++) {
      if (i != j){
        Serial.print("Scanning (SDA : SCL) - " + portMap[i] + " : " + portMap[j] + " - ");
        Wire.begin(portArray[i], portArray[j]);
        check_if_exist_I2C();
        wdt_reset(); // nodemcu is alive
      }
    }
  }
}

void check_if_exist_I2C() {
  byte error, address;
  int nDevices;
  nDevices = 0;
  for (address = 1; address < 127; address++ )  {
    // The i2c_scanner uses the return value of
    // the Write.endTransmisstion to see if
    // a device did acknowledge to the address.
    Wire.beginTransmission(address);
    error = Wire.endTransmission();

    if (error == 0){
      Serial.print("I2C device found at address 0x");
      if (address < 16)
        Serial.print("0");
      Serial.print(address, HEX);
      Serial.println("  !");

      nDevices++;
    } else if (error == 4) {
      Serial.print("Unknow error at address 0x");
      if (address < 16)
        Serial.print("0");
      Serial.println(address, HEX);
    }
  } //for loop
  if (nDevices == 0)
    Serial.println("No I2C devices found");
  else
    Serial.println("**********************************\n");
    delay(5000);           // wait 1 seconds for next scan, did not find it necessary
}

void loop() {
  Serial.println("\n\nI2C Scanner to scan for devices on each port pair D0 to D7");
  scanPorts();

  delay(5000);

}
`
Den I²C Scanner auf die NodeMCU laden und laufen lassen. DNMS hat die I²C Adtresse 0x55 und sollte dann gefunden werden. Wenn nicht, gibt es ein Problem mit der I²C Verbindung (GND, SCL, SDA).
Stromversorgung Teensy? Das ist am Blinken des Teensy Boards zu sehen.

Ich hoffe, Ihr kommt damit weiter.
Viele Grüße
Helmut

Melnilie, 2020-08-06:
Hallo Helmut,

Ich habe das mit einem I2C Scanner ausprobiert und er findet die Verbindung wohl nur manchmal. Es liegt also wohl an meinem Board . Ich hab mir jetzt mal ein neues bestellt und schau, ob es damit besser funktioniert.
Danke für deine Hilfe.

Viele Grüße

Closed 2020-09-07.

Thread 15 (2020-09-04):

Idee: Fahrzeugzählung mit DNMS?

linuxlurak, 2020-09-04:
Hallo

Ich werde nächstens die ersten DNMS bauen können. Mir ist folgende Idee gekommen: Könnte man mit dieser Technologie auch Fahrzeugzählungen vornehmen? Wäre es sodann denkbar, dass man einzelne Fahrzeuge einer Kategorie zuordnen kann? Ich denke da typischerweise an Töffs, die durch ihr Knattern eventuell identifizierbar wären.

Danke für Eure Gedanken zu dieser Idee.
Gruss

Franz4596, 2020-09-06:
hi Linuxlurak,
aktuell berechnet der teensy-Controller "nur" den A-bewerteten Schallpegel LAeq, LAmin, LAmax. Eine Pegelüberschreitung kann man natürlich feststellen und zählen, vgl. https://openmaps.online/noise/ .
Eine Kategoriezuordnung könnte über Spektrenvergleiche oder Korrelationsverfahren erfolgen. Eine Frequenzanalyse (FFT) soll vielleicht implementiert werden.
mfg franz

etho50, 2020-09-07:
Das Potential für solche Zusatzfunktionalitäten ist vorhanden. Wir haben nicht ohne Grund den Teensy-Prozessor als speziellen sehr leistungsstarken 'Lärmprozessor' (u.a. mit Gleitpunktarithmetik in Hardware) ausgewählt und die Funktionen Lärmauswertung von der Kommunikation über den ESP getrennt. Das Potential müsste nur gehoben werden. Im Klartext: Wir bräuchten dafür Software-Entwickler am besten mit Erfahrung im Bereich der Mustererkennung mit Methoden der KI. Das Thema Spektren als Basis dafür wollen wir aber ohnehin angehen. Ob man alleine mit Korellationsrechnungen der Spektren  schon befriedigende Ergebnisse beim Straßenverkehr bekommen kann, müsste man testen. Ich bin da etwas skeptisch. Bei Bahnlärm ist die Erkennung von Zügen v.a. nachts und wenn der Sensor nahe am Gleis angebracht ist, näherungsweise durchaus schon jetzt möglich. Sie sind meist als LAeq-Peaks gut erkennbar. Wenn dann noch  LAmax hoch geht und möglicherweise z.B. bei langen Güterzügen auch LAmin reagiert, kann man das Ergebnis zusätzlich absichern.  Es gibt auch Sensoren im Netz, bei denen man dies gut sehen kann. Z.B. der Sensor 44836. Da kann man sogar S-Bahnen und Güterzüge voneinender unterscheiden. Der S-Bahn-Fahrplan ist gut erkennbar (kleinere Peaks), die größeren Peaks sind Güterzüge.  Man könnte sogar die Fahrtrichtung der Züge ermitteln, wenn man mehrere Sensoren auswertet, die in größerem Abstand an der jeweiligen Strecke angebracht sind. Leider ist der Sensor gerade Offline, weil er repariert bzw. ausgetauscht werden muss. Aber an der Nachbarstation 36217 ist dies auch erkennbar. Bei Flugzeugen könnte ich mir das auch vorstellen, aber auch nur, wenn das Geräusch an dem Standort sehr signifikant ist.
Leider ist es schwer, Leute zu gewinnen, die bei unserem Projekt bei der Weiterentwicklung gerade solcher Apps mitmachen wollen und dann auch eine längere Zeit dabei bleiben. Das ist Schade. Wir sind für jeden dankbar, der uns hilft. Tatsächlich ist es auf Dauer kaum möglich, das bisherige Niveau zu halten, wenn wir unser Team nicht erweitern können.
Grüße
Ewald

linuxlurak, 2020-09-13:
Vielen Dank für Eure eingehenden Rückmeldungen. Ich merke, dass ich da an meine Grenzen stosse. Ich bin kein Ingenieur, aber wenigstens passionierter Device-Hacker und kann zur Not auch SMD Löten und ein PCB designen. Ich könnte für Firmwaretest oder das Bearbeiten von Anleitungen (zB DE/EN) etwas Zeit aufbringen, _guten_ Code schreiben oder mich mit den theoretischen Grundlagen der Anwendungen auseinandersetzen übersteigt meine Kenntnisse aber vermutlich.

atze09, 2020-09-21:
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

Hallo Franz,
Lässt sich diese Datenbank (https://openmaps.online/noise/) auch über einen längeren Zeitraum visualisieren (meine InfluxDB ist leider gerade offline).
Das wäre super.
Freundliche Grüße,
Dominik

atze09, 2020-09-21:
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

Hallo Ewald,

Vielen Dank für die zahlreichen Informationen.
Ich bin leider Laie wenn es um Programmierung geht. Bezüglich FFT hätte ich zumindest die theoretischen Voraussetzungen falls das etwas hilft, könnte ich hier ab nächsten Jahr unterstützen.

Freundliche Grüße,
Dominik

Franz4596, 2020-09-22:
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

Hi Dominik,
Die map wurde von CodeforCologne erstellt, Infos dazu siehe "?" auf http://openmaps.online/noise/,
bzw. code https://github.com/codeforcologne/OpenNoiseMap.
Du kannst aber auf alle Lärmdaten von Sensor.Community zugreifen (madavi.de speichert akt. kein Lärm).
oder Grafik in https://laerm.citysensor.de/
franz

atze09, 2020-09-23:
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

Thank you!

Closed 2020-10-30.

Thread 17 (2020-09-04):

SDS011 anstatt SPS30 möglich?

linuxlurak, 2020-09-04:
Kann ich den SDS011 anstelle eines SPS30 verwenden? Auch mit DNMS-Board?
Gruss

hbitter, 2020-09-04:
Ja, natürlich. Der SDS011 (ebenso der SPS30) werden von der NodeMCU abgefragt und nicht vom Teensy Prozessor des DNMS.
Auf den Airrohr Boards sind beide Buchsen einmal für den SPS30 und einmal für den SDS011. An den Kombi Boards (Teensy3.6+NodeMCU bzw. Teensy4.0+NodeMCU) ist nur eine Buchse für den SPS30. Ein SDS011 kann aber mit etwas Lötaufwand an der NodeMCU angeschlossen werden (Anschluss wie auf der Sensor.community Seite gezeigt). Bei einer solchen Konfiguration mit dem SDS011 ist es aber unbedingt wichtig für die notwendige akustische Entkopplung zwischen dem Mikro vom DNMS und dem SDS011 zu sorgen. Der Ventilator dea SDS011 ist ja so schon deutlich zu höhren und das bekommt das Mikro ja auch mit. Aus diesem Grund haben wir eigentlich auf die Trennug zwischen Airrohr und DNMS Board mit einer auch längeren Kabelverbindung um das DNMS entkoppelt und akustisch gut zu positionieren.

linuxlurak, 2020-09-04:
Danke für Deine Antwort.

Zu Deinem Input betr- Lüftergeräusche: Ich denke im Moment ein Setup an, das mit 75er HT-Rohr und Boden arbeitet. Hört das Mikro also den SDS011 im HT Bogen hinte? Hätte für die Ansaugung direkt im HT-Bogen ein zusätzliches Loch gemacht. Bringt allenfalls zusätzliche Isolation um den SDS011 etwas? Oder ist das Problem, dass der SDS011 den Plastik berührt und so seine Lüftergeräusche aufs Mikro überträgt?

Zum DNMS-Board T.4+NodeMCU (habe bei dirtypcb einen Batch davon geordert): Ist es möglich, den Anschluss für den SP30 zu benutzen und in der Firmware die Pins einzustellen? Die Firmware, die ich vom Feinstabsensor her kenne, ist einfach gehalten (was natürlich grosse Vorteile hat für eine breite Community). Dort hätte ich keine Einstellungsmöglichkeiten gesehen. Sonst also wie von Dir erwähnt an die entsprechenden Pins löten. Wär auch kein Problem; Steckplätze benutzen wär natürlich sehr praktisch.
Schönen Abend!
Gruss

hbitter, 2020-09-04:
Also ich sehe zwei mögliche Problempunkte mit dem DN75 Rohr - ohne dass ich die Anordnung genau verstehe.

- Schall/Vibrationsübertragungen des SDS011 an das Mikro - ja diese Möglichkeit besteht wenn beide (SDS011 und Mikro fest am gleichen Kunststoffkörper angekoppelt sind

- wenn das DNMS Mikro mit dem 1/2" Rohr direkt in den Abschluss des DN75 Rohrs mündet, entstehen starke Reflexionen von der Abschlussplatte des DN75 Rohrs zum Mikro hin, die dei Messwerte verfälschen. Dies ist auch stark Frequenzabhängig. Bei Messungen haben wir Abweichungen vonbis zu 5 dBA gemessem. Empfehlung: Das Abschlussrohr zum 1/2" Mikro Rohr möglichst klein halten (nicht mehr wie DN50).

Die beste akustische Entkopplung ergibt sich mit einem abgesetzten DNMS.

Beim Kombi Board kann der Anschluss des SPS30 nicht (in keinem Fall) für den Anschluss eines SDS011 benutzt werden. Das SPS30 wird am I²C Bus angeschlossen, wie auch das DNMS. Das SDS011 benutzt eine separate serielle Schnittstelle UART mit TX und RX Leitung), auf der keine anderen Geräte angeschlossen werden können. SDS011 geht nur, wenn er an die entsprechenden Pins an der NodeMCU angeschlossen (angelötet) wird.

Wenn Du weitere Fragen hast, auch gerne per PM an helmt.bitte (at) t-online.de

Viele Grüße
Helmut

Closed 2020-09-23.

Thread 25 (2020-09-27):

Alte LAN-Kabel zur Mikrofonverdrahtung: Spricht etwas dagegen?

linuxlurak, 2020-09-27:
Spricht etwas dagegen, alte LAN-Kabel zur Verdrahtung des Mikros zu nehmen? Sie dürften einiges unter den empfohlenen AWG26 liegen (obwohl ich gerade auf [Wikipedia](https://en.wikipedia.org/wiki/Category_5_cable) sehe, dass LAN-Kabel AWG24 sein sollen...). Praktisch daran ist aber, dass so ein Kabel genug Adern hat und enorm verfügbar ist.

hbitter, 2020-09-27:
Na ja, das ganze LAN-Kabel ist schon recht unflexibel oder willst Du die einzelnen Adern aus dem LAN-Kabel nehmen?
Meine Empfehlung für Silikon Kabel kommt vom Verhalten beim Löten, da schrumpft die normale Plastik Ummantelung oft stark zusammen und die Ummantelung in der Nähe der Lötstelle wird recht brüchig. Der Unterschied zwischen AWG26 und AWG24 beträgt ungefähr 0,1mm im Durchmesser (ohne Isolierung), ist also nicht groß.

linuxlurak, 2020-09-27:
Ja, habe ein Kabel mal aufgedröselt und dann von den 8 adern 6 verlötet. Die Isolierung schmilzt recht schnell weg, also rasch arbeiten ist angesagt. Das LAN-Kabel ist nicht sehr flexibel, da hast Du recht. Zum eingiessen sollte das kaum ein Problem sein. Kommt dann danach drauf an, was mit dem Kabel geschieht. Dank dem Hinweis in https://github.com/hbitter/DNMS/issues/21 bin ich nun an einem Setup, bei dem das Mikro weg vom SDS011 ist und per Kabel in eine Verteilerdose geführt wird. In der Bauanleitung werden 200mm Kabellänge genannt. Ab welcher Länge treten Probleme auf? LAN-Kabel wäre nun praktisch, weil schon genug adern in einem Kabel drin sind und ich nicht verschiedene Kabel zusammenschneiden und bündeln muss etc. An sich aber jammern auf hohem Niveau;)

hbitter, 2020-09-27:
Ab welcher Länge treten Probleme auf?
Gedacht ist I²S als eine Verbindung zwischen ICs auf einer Platine. Es wird sicher einiges mehr drin sein. Hängt aber stark vom Einzelfall und was man dann unternimmt z.B. abgeschirmte Kabel aber die ICs auf beiden Seiten müssen natürlich auch  entsprechend höhere Kapazitäten treiben zu können. Also??

Closed 2020-10-30.

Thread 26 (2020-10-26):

Unterschied DNMS Versionen 1.0.4 zu 1.0.5?

erduino, 2020-10-26:
Hallo
Was ist eigentlich der Unterschied zwischen diesen 2 Versionen?

pe0ter, 2020-10-26:
Version 1.05 routes audio to the usb port for external recording/evaluation

erduino, 2020-10-26:
Okay, danke für die Info.
Ich habe das Probleme das kaum 3 korrekte DNMS readings hintereinander funktionieren bis ich die Meldung "DNMS read failed" bekomme. Mit 1.04 ist es etwas besser aber auch nicht gut. Gibt es da vielleicht immer noch Probleme mit dem I2C Library?

---
End reading DNMS
Start reading DNMS
LAeq: 44.76
LA_MIN: 41.75
LA_MAX: 48.49
----
End reading DNMS
Start reading DNMS
DNMS read failed          <<<-----------------
----
End reading DNMS
Start reading DNMS
LAeq: 48.25
LA_MIN: 42.29
LA_MAX: 62.72

pe0ter, 2020-10-27:
Both my installed units work fine and the other eight other circuit board sets I have build and tested so far work flawless. I am using AirRohr 1.4 (NodeMCU V3) and DNMS 1.4 (1.04 firmware) circuit boards and a 3m RJ12 cable between them.

DNMS read failed could be a noisy I2C bus between NodeMCU and Teensy.
What hardware setup are you using?

hbitter, 2020-10-27:
Hallo erduino,

1. Unterschied Firmware V1.0.4 und V1.0.5
Wie pe0ter schon sagte, wird bei der Firmware zusätzlich das Audio Signal (nach dem A-Filter) auf der USB Schnittstelle ausgegeben. Das Teensy Board ist am USB Port dann ein Audio Gerät (PCM 16-Bit, 44,1 kHz). Du kannst also das Signal weiterverwenden z.B. mittels Audacity aufzeichen und auswerten. Diese Funktion ändert an der restlichen Funktionalität nichts und hat (zu mindest theoretisch) keinen Einfluss auf die I²C Übertragung zwischen Teensy und NodeMCU.

2. I²C Verbindung zwischen Teensy und NodeMCU
Probleme mit der I²C Lib gibt es nicht mehr (bis jetzt sind mir jedenfalls keine bekannt). Um bei Deinem Problem weiter zu kommen, brauche ich die genaue Konfiguration HW, Firmware auf der NodeMCU, usw. Wenn Du eigene Boards einsetzt bitte auch ein Bild davon. Du kannst Das gerne auch per mail an mich schicken helmut.bitter (at) t-online.de.
Viele Grüße
Helmut

erduino, 2020-10-27:
Vielen Dank Helmut und Peter
Die detaillierte Konfiguration werde ich gerne schicken.
Bei der Gelegenheit wollte ich fragen ob es ein Quelle gibt wo man die fertigen aber unbestückten PCP's (circuit board ) beziehen kann oder hat hier jemand einen Restbestand zum Verkauf?

hbitter, 2020-10-27:
Hallo erduino,

der Kollege Franz Hoefle hat gerade einige Boards in China bestellt - sind gerade unterwegs. Hier seine Mail Adresse:
franz.hoefle (at) buergerforum-gladbeck.de
Viele Grüße
Helmut

pe0ter, 2020-10-27:
I ordered mine at PCBWay.com, 10 sets $38,00 including shipping, but they sent me 11 sets so I have 1 unused set available.

erduino, 2020-10-27:
>
>
> I ordered mine at PCBWay.com, 10 sets $38,00 including shipping, but they sent me 11 sets so I have 1 unused set available.

Ok, pe0ter, würdest du mir das übrig gebliebene Set verkaufen? In welchem Land wohnst du? Kannst mir sonst auch auf itas (at) gmx.ch schreiben.

erduino, 2020-10-27:
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

Danke Helmut. Das dauerd ja wahrscheinlich noch einen Moment und es sieht so aus als hätte pe0ter noch eins übring.

pe0ter, 2020-10-27:
@erduino
Ich Hab dir ein mail geschickt. Ich wohne in Holland, Eindhoven.

Closed 2020-10-30.

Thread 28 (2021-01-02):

Question: why Teensy and not ESP32?

DeeKey, 2021-01-02:
Why to use expensive Teensy board and not ESP32 which also has LoRa support?
Is it theoretically possible to use ESP32 for combining both DNMS and AirRohr sensors? If yes then what is needed to implement this?

glosair, 2021-01-02:
The Teensy is used for it's raw processing power as the Mic is being monitored 24/7 to give the average sound level not point measurements that would be meaningless.

hbitter, 2021-01-02:
Hi DeeKey,

the selection of the Teensy Boards (3.6 and than 4.0) had mostly two reasons:

- availability of a good audio library for the Teensys, where all the necessary functions were available and fitting together. Now the firmware will be changed from 16-bit integer calculation to 32-bit floating point calculation. There is a special 32-bit floating point  version of the audio librar available, a great thing not to reinvent the wheel.
- the processing power of the Teensys compared to ESP32 is higher. Here is a comparison (from the Teensy developer Paul Stoffregen - PJRC:
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
This is especially important now going over to 32-bit floating point (which the ESP32 has as well in HW but with lower performance).

I don't think it is really a good idea to combine all the functions especially for DNMS and all the communication tasks on one microcontroller. Yes, theoretically it would be possible but it would loose simplicity and openness. We plan to do some frequency domain analysis in the future as well and therefore a lot of processing powers has to be available and as glosair said, noise measurement is a continous task not a spot measurement.
Hope this explains the motivation behind the decisions.
Regards,
Helmut

DeeKey, 2021-01-02:
Thank you for the comprehensive answer. It should definitely be added to FAQ section.
Let the issue be opened for now. So that others will read it as well.

DeeKey, 2021-01-02:
I was given a link which might pose an interest for this issue. Here is both code and prototype description of the sound meter based on ESP32 with the same type of microphone  ICS-43434. Maybe it be of interest...
https://github.com/ikostoski/esp32-i2s-slm

hbitter, 2021-01-02:
Hi DeeKey,

there more information abaout the ESP32 project of Ivan Kostoski on this [Hackaday page](https://hackaday.io/project/166867-esp32-i2s-slm). Also the limitations of the ESP32 are described when it comes to 64-bit floating point.
Regards,
Helmut

DeeKey, 2021-01-03:
Just for information: some details about performance of ESP32
https://www.esp32.com/viewtopic.php?f=14&t=800&sid=fb9d650ee6806b018767f48359b33d9d&start=20

Closed 2023-02-11.

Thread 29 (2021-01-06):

Support of stereo microphone

DeeKey, 2021-01-06:
Is it make sense to support stereo microphone?
If yes then how to do it the best way? On the single PCB or using 2 microphone paired cases?

hbitter, 2021-01-06:
Hi DeeKey,

for ambient noise measurement I would say no. But if you have other purposes in mind why not. It will give you directional information.
The configuration of two microphones - where they are placed -  would also depend on the purpose.
A different story would be a microphone array, that could be used for localizing the source of noise.
Regards,
Helmut

DeeKey, 2021-01-06:
Does it make sense to install 2 microphone chips on a single PCB to make a redundant solution?
If one will fail (degrade) then the other one can still be used.
The same approached is used in PurpleAir PM sensors. They install 2 PM sensors side by side. Thus if readings from both sensors differs too much then something is wrong.
Can the same approach be used for DNMS?

pe0ter, 2021-01-06:
Deekey,

Extending this redundancy line of thought, it might be easier to install 2 completely separate standard airRohr PM + DNMS meters as one can use the now readily available proven hardware and software and no recoding is required. Using 2 meters also ensures measurements continue to be registered with controller and power supply failure.

But as an environmentally interested experienced developer, you are free to build your own meter, using your own hardware, connect it to as many sensors you like and write your own code to publish measured data into the sensor.community IPA to make it available for the world. You can use the published github code for the standard airRohr controller and Teensy as a starter.

Met vriendelijke groet,
Peter

On 6 Jan 2021, at 14:20, DeeKey <notifications@github.com> wrote:

Does it make sense to install 2 microphone chips on a single PCB to make a redundant solution?
If one will fail (degrade) then the other one can still be used.
The same approached is used in PurpleAir PM sensors. They install 2 PM sensors side by side. Thus if readings from both sensors differs too much then something is wrong.
Can the same approach be used for DNMS?

—
You are receiving this because you are subscribed to this thread.
Reply to this email directly, view it on GitHub, or unsubscribe.

hbitter, 2021-01-06:
Hi DeeKey,

from the firmware point of view sure this can be done. It would nearly double the processing  load because all calculations would have to be done twice. I think with Teensy4 it should be possible. It has a lot of processing power.
If it would really help to detect degradation I would have doubts. Both microphones are sitting more or less close together. It means they are exposed to the same environmental conditions (weather ... temperature, humidity). Maybe the same will happen to both? Who knows?
Besides that there is always the question of casing of two microphones on a single PCB because the casing has a big impact of accuracy of the measurements.
As Peter suggested, using two systems would be a way as well.
Regards,
Helmut

Closed 2021-05-30.

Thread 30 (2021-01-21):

Calculation of Leq

buv, 2021-01-21:
Hei Helmut,

while looking for a good framework for noise measurement I found your project, which impresses me deeply!

On Tuesday my Teensy 4.0 and the Tindie ICS-43434 board arrived and the fun part started. I had a closer look at the loop function of the DNMS software and I perceive its function as follows:

- if rms data is available, read and accumulate rms value and number of read audio buffers
- if 35ms have passed, calculate average rms and add it to overall leq value

The number of reads of the audio buffer (128 samples resulting in approximately 2.9ms @ 44.1kHz) during the 35ms varies between 12 and 13. A measurement loop with 12 audio buffer reads should be weighted differently compared to one with 13 reads. However, the calculation of the overal leq value does not distinguish between the two cases.

The overall effect of this is surely not terribly significant, but what about controlling the measurement loop by the number of audio buffers read rather than by milliseconds? If one asked for 12 buffers reads, that would result in 34.8ms for the measurement loop. Is this deviation from the initial 35ms problematic?

Greetings,
Burkhard

hbitter, 2021-01-21:
Hi Burkhard,

could you explain a bit more what you me mean with "A measurement loop with 12 audio buffer reads should be weighted differently compared to one with 13 reads"?

Is this deviation from the initial 35ms problematic? I don't thing that it would be problematic in any way.

you are right the measurement loop could have been over the number of blocks of 128 samples. I started with the time and didn't changed it so far. I don't think it makes a difference though.
Regards,
Helmut

buv, 2021-01-21:
Hei Helmut,

there is a jitter in the measurement loop. When entering the measurement loop, the rms sum is divided by mean_count_A. This variable is either 12 or 13, depending on how the interval of the measurement loop is positioned to the audio buffer readout. So the 35ms-average consists either of 12x128 samples or 13x128 samples. A 13-buffer average should have a higher weight compared to a 12-buffer average. This distinction gets lost, since all averages are unweightedly summed up.

My suggestion would be to exchange line 209

`if (leq_loop > leq_single_loop_time) {`

by

`if (mean_count_A >= 12) {`

to ensure that virtually all subaccumulation in the measurement loop are equal and thus can simply be added to obtain the global l_eq.

(Unfortunately the AudioAnalyzeRMS object does not return the number of buffers summed up. If both values, sum and number of buffers processed, were returned, no tight polling of the RMS object would be needed.)

I have to admit, that I did not fully understand the need for creating the 35ms sums. Can you give me a hint?

Greetings,
Burkhard

hbitter, 2021-01-21:
Hi Burkhard,

yes, you are right. The time interval should be equal for the overall LAeq calculation. And thank you for the simple solution you provided. I will include it in the next version of the firmware.

You are right with the reason to have 35ms sums. It's for the min/max calculation. At the time we started, we were not sure what time to choose for the min/max values (fast 125ms, slow 1s, impulse 35ms) but yes, even for 125ms or 1s the loop would better depend on a fixed number.
It's always good if someone looks a bit behind and asks.
Thanks a lot,
Helmut

buv, 2021-01-22:
My pleasure!

Closed 2021-05-30.

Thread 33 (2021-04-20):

what happened to type=Laerm

derkod, 2021-04-20:
Dear Helmuth,
Do you maybe understand why the SensorCommunity API to get the DNMS-data is not working for me?
See https://github.com/opendata-stuttgart/meta/issues/158
Thanks!
Derko

hbitter, 2021-04-20:
Hi Derko,
I don't know anything at the moment about the change that happend. I will ask around what happend and how to solve it. Hopefully I can come back in a short period and give more information.
Regards,
Helmut

ricki-z, 2021-04-21:
This should work again.
The correct URL for the request would be:
https://data.sensor.community/airrohr/v1/filter/country=NL&type=DNMS%20(Laerm)
The quotation marks were only written to show start and end of the query string.

Closed 2021-05-30.

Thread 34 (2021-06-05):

Pesky ICS43434: SKU der Komponenten neben dem ICS43434 auf dem Pesky-PCB?

linuxlurak, 2021-06-05:
Leider finde ich keine BOM zum Pesky-Board auf tindie... Könnte mir jemand weiterhelfen?

Hier lese ich von power supply decoupling mittels 0.1uf capacitor und 100kΩ pull‐downresistor :
https://datasheet.octopart.com/ICS-43434-InvenSense-datasheet-62330883.pdf
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

Linker Baustein: Das dürfte der capacitor in der Nähe des 3V3 Pins sein.

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
(Quelle: https://oshpark.com/shared_projects/GiObJBkm)

Rechts davon dürfte der 100kΩ pull‐downresistor sein.

Ich komm nicht recht weiter beim Suchen der passenden Komponente...

Für eine SKU zB bei Digi-Key oder Farnell wäre ich Euch sehr dankbar!

glosair, 2021-06-05:
Both are just 0805 parts,

Part numbers from farnell
    MCWR08X1003FTL
    MC0805B104K500CT

Or get a sample kit from china like this, you won't regret it.

https://www.ebay.co.uk/itm/164643706126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

linuxlurak, 2021-06-05:
Thanks a lot @glosair !

I want to place an order on pcbway.com by uploading the boards gerber files and now i am in need of a bom. The partnumbers you provided help a lot :) Now I have to map the gerber with the bom, perhaps I have to rebuild the pcb design by my own.

Do you think this is a feasible way to get  microphone boards?

 An Order for 50 boards costs $90 dollars for the pcb and the assembling service. the microphone chip, resistor and cap not included. I guess a board will cost about 5 to 6 dollars in the end delivery included.

glosair, 2021-06-05:
Just realized they aren't 8805 sized they are 1608 so should be
https://uk.farnell.com/yageo/ac0603fr-07100kl/res-100k-1-0-1w-0603-thick-film/dp/3495222?st=1608%20100k%20cut
and
https://uk.farnell.com/avx/06031c104k4z2a/cap-0-1uf-100v-mlcc-0603/dp/3521950?st=1608%200.1uf%20cut

I had been looking at this and designed a board that would hold the mic directly onto a board attached to the teensy 4.0. the I2C driver was placed between the Teensey and a custom esp board.

Had problems with the production and the ground contact around the hole in the board and then found that the thickness of the board was effecting the levels massively.

Spent some time talking to my brother inlaw (a sound engineer) and he suggested either the thinnest possible board or even better a flex pcb.  I had to put the project on hold as I've been building a lab and workshop at the end of the garden and it's taken up way too much time.

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

glosair, 2021-06-05:
The pricing for the boards is a bit steep, you would be looking at panalising them allowing for wastage you should get 16-20 out of a 100mmx100mm PCB yes there is "engineering costs" but the PCBs come out as almost free

hbitter, 2021-06-06:
I made a layout for a round ICS-4343 Board that fits into 12,7mm plastic tube as well as in 13,0mm stainless steal tube.

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

I have orderd assembled boards based on this layout twice in China (PCBWay). Did no panalising because I have no knowledge about that. Ordering 20 pieces including everything gave a price of about 10€ per piece at the end (incl. components, freight, Einfuhrumsatzsteuer). Going for 50 pieces or even more (200 would be a good number) would lower the cost.
If somebody is interested give me a personal mail (helmut.bitter (at) t-online.de.
Regards,
Helmut

glosair, 2021-06-06:
Afternoon Helmut

What thickness PCB are you using 0.4mm?

Thanks
Tim

hbitter, 2021-06-06:
Hi Tim,

PCB is 1.6mm thick.
Regards,
Helmut

linuxlurak, 2021-06-06:
@hbitter wonderful pcb!

Would it be ok for you to share the PCB and the BOM?

I could try my hand at panelizing. I have never ordered assembled PCB, but panelizing has worked. Could then make some calculations and if it makes sense, report about it and provide a few such pcbs also.

hbitter, 2021-06-06:
Hi linuxlurak,

there is absolutly no problem with sharing the PCB layout. Please give me your E-Mail adress, that I can send you all the information.
Reagrds,
Helmut

Fux2, 2021-09-06:
Hi Helmut,
what type of connector did you use in your ICS-43434 board?
I am looking for such a connector for another project.
How strong is it connected? Is it made for one time connection or can it be unplugged at least a few times without any damage at the pcb?
Thanks
Markus

hbitter, 2021-09-08:
Hi Markus,

connector is from JST, it's JST SH series.
[Link to JST SH page](https://jst.de/product-family/show/65/sh)

I think, it can be unplugged a couple of times but the crucial point is the cable.
A similar connector is used on the Sensirion SPS30 PM sensor JST ZH series (1.5mm pitch compared to 1.0mm pitch of SH series).  The following happened with the cable after plugging and unplugging it a couple of times:
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
It's more a problem of the cable. Was a cheap one bought via Aliexpress.

Regards,
Helmut

Closed 2023-02-11.

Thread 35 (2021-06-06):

What do you think of this sensor setup? (Please refer to pictures attached)

linuxlurak, 2021-06-06:
For quite some time I have been working on a compact an easy to assemble design of an environment sensor. It uses an SDS011, BME280 and a DNMS. I'm dreaming of integrating a MultiGeiger (see https://github.com/ecocurious2/MultiGeiger). (Lack of time and know how at the moment to complete this idea...)

Please refer to the following pictures:
Internal arrangement:
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
View of BME280
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
Microphone arm using a goose neck to direct the microphone towards the noise source:
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
View A of soldered DNMS, here you can see pins soldered in addition to connect SDS011 (V5+GND directly under the ESP32):
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
View B of soldered DNMS, here you can see pins soldered in addition to connect SDS011 ((TX/RX oppsite side of DNMS-PCB):
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
Positioning of the sensor (it's about 5-7m away of a street allowed 50km/h):
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

What do you think of this setup (especially I'm interested in your opinion about the housing, microphone arm, positioning)? Criticism is very welcome!

hbitter, 2021-06-06:
Hi,

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

It looks a bit to close to the wall and the ceiling. Would a test be possible: place a second DNMS (or another SPL meter) for a comparision farther away from the wall and the ceiling and compare the measurements over 2 - 3 days. Reflections can easily make a difference of 3 - 5 dB(A) or even more but it has to be measured.
Regards,
Helmut

glosair, 2021-06-07:
Good Morning Helmut

Looks good

I would question the orientation of the SDS011.
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

You might want to drill a small drain hole in the back of the enclosure so any condensation will drain out that way instead of into either the BME280 or Mic.

Regards

Tim

linuxlurak, 2021-06-09:
I measured the distances and setup another sensor. Just this moment I had to pack things up for the moment as a heavy storm is coming up. But tomorrow I'll set up everything again.
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

I measured the last couple of days. I'll post the links soon. Then we can compare the data.

linuxlurak, 2021-06-09:
The storm passed without hitting us... Weather prognosis was completely off; so sensor is set up again.

Link to Data of Sensor next to the wall (the one 18cm away from the wall and 38cm away from the ceiling with Spaghettiplatten):
https://maps.sensor.community/grafana/d/000000004/single-sensor-view-for-map?viewPanel=12&var-node=54519

Link to the other Sensor 80cm away from the wall and the ceiling:
https://maps.sensor.community/grafana/d/000000004/single-sensor-view-for-map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

I guess my setup is not very scientific... but i try my best.

linuxlurak, 2021-06-09:
> 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
@glosair Thanks for this hint! I have to reflect on this fact some more. At the moment I did not think of any moisture accumulating in the case by the SDS011. And I used a small 3D-Printed cover with some small volume to prevent accumulating dust in the housing.

The BME280 is in the middle mounted on a small round pcb that maches the whole. I think no condensation will drop on the bme280. most likely the condensation will be gathered in the 3d printed cover. Or do you have other experiences? In one of my sensors I mounted a moisture absorber silica gel in a simple casing/holder.

I inted to use the sensors on balconies. Perhaps I should measure the humidity in the housing too to check if there is a problem with condensation.

hbitter, 2021-06-09:
Hi linuxlurak,

do both DNMS running with the same firmware?

linuxlurak, 2021-06-10:
Actually I upgraded the firmware on all sensors with V2.0.5. But I did not check after the flashing procedure. Errors by me could be possible. I moved one of the sensor today to its former place and set up another one. Will share the links soon.

Do you have some indication there are two different firmwares used?

hbitter, 2021-06-10:
No, the question was only to be sure eleminating this point.
Using firmware 2 will give LAeq values down to 30 dB(A) whereas firmware 1 will go down only up to 36/37 dBA. So you will see the difference only below 40 dB(A).
The differences between the two positions are really big even higher than expected, 1. picture at night at around 2:00:
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
Sensor 2 LAeq comes down to 35/36 dB(A), that is O.K.with firmware 1. So, will be interesting with firmware 2, if it's going down to around 30 dB(A).

2. picture at 14:00 Uhr
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
Nearly 15 dB(A) difference.

A cross check would be good, position sensor 1 micro close to micro of sensor 2 or the opposite (micro of sensor 2 close to micro of sensor 1)

Regards,
Helmut

linuxlurak, 2021-06-14:
DNMS next to the wall as before:
https://maps.sensor.community/grafana/d/000000004/single-sensor-view-for-map?viewPanel=12&var-node=54519

New measurements with new sensor:
https://maps.sensor.community/grafana/d/000000004/single-sensor-view-for-map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

I'm setting up a third DNMS to measure attached directly to the mic of the sensor next to the wall. Mmaybe i will only manage this next weekend.

linuxlurak, 2021-06-14:
An additional note on the installation of the SDS: The manual specifies to protect the SDS011 from light incidence. I have in the picture above in comment https://github.com/hbitter/DNMS/issues/35#issue-912905447 where the sensor is unscrewed, turned the by 90°. Better still is an opaque tube or a hose to take. In any case, the sensor opening must not be aligned against the opening in the housing. The result can be seen here, the impact is dramatic:
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

linuxlurak, 2021-07-28:
Now, during two or three weeks, the following set was measured:
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

The result seems to me far from the expected:
https://maps.sensor.community/grafana/d/000000004/single-sensor-view-for-map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
https://maps.sensor.community/grafana/d/000000004/single-sensor-view-for-map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

I'm lost...

Closed 2023-02-11.

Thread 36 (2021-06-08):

Wrong DNMS-values since some days

imaluschi, 2021-06-08:
Strange behaviour of a DNMS (only DNMS). Worked quite a long time (since 09/2020) flawless, but since some days...
Any idea? Is something special with values around 46/47/48 (min, avs, max)?
Nothing was changed, the Sensor was not moved. Traffic on the street nearby is nearly always the same (~12k cars/day)
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
https://maps.sensor.community/grafana/d/000000004/single-sensor-view-for-map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

Two other sensors (DNMS with SDS011 and BME280) still work more or less flawless (sometimes problems with BME, but see https://github.com/opendata-stuttgart/sensors-software/issues/739).

I have to pick up the sensor for investigation. Will give an update when investigated, but will take some days.

imaluschi, 2021-06-08:
Teensy 4.0, Firmware V1.0.5

hbitter, 2021-06-09:
Hi imaluschi,

it looks that it started on the 06/05.
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
Was there heavy rain at that date?
I think the microphone is broken and you have to change it.
Regards,
Helmut

imaluschi, 2021-06-09:
Hi Helmut,

yes, last weeks it's raining from time to time, sometimes with thunderstorms.
Nevertheless the microphone should be dry. If wind is pressing water to the microphone, the water should drop down - microphone is mounted downwards in direction to the street (source of sound).
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
I'll give an update when I got the sensor and had a quick look.

Jürgen

linuxlurak, 2021-06-09:
(Sorry, a little offtopic)
Hi @imaluschi

> https://maps.sensor.community/grafana/d/000000004/single-sensor-view-for-map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

Could you tell me how I get such a link for my dnms sensor? One of my sensors with dnms has ID esp8266-586719 (airrohr).

imaluschi, 2021-06-09:
Did you register the DNMS on https://devices.sensor.community/sensors/ ?
You can only register the PM-Sensor and the DNMS - so drop BME280 (it will work, but you will get warnings).
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

var-node="Sensor ID from the registered DNMS - see picture", in the shown case  "var-node=48506"
https://maps.sensor.community/grafana/d/000000004/single-sensor-view-for-map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

From and to are the times, changeable. Zooming in helps to find the values. "to=now" for graph until now.

hbitter, 2021-06-09:
Hi,
I think, it's now possible to register more than 2 sensors for one NodeMCU ID. Rajko Zschiegner from Sensor.Community has done that change. Anyway if it's not activated in the self registering process, Rajko can register a third sensor manually in the database, you have to send him a mail (rajko@sensor.community).
Regards,
Helmut

linuxlurak, 2021-06-09:
@imaluschi Wow, superb! Thank you very much! Is this documented somewhere or is it common knowledge? If the latter, i think i will provide a commit to include this nice trick of yours in the according readme. This works like a charm: https://maps.sensor.community/grafana/d/000000004/single-sensor-view-for-map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

@hbitter Thanks for this hint! One of my newer sensors showed up with DNMS without special treatment by Rajko, it should work. Without the trick by imaluschi i get something like this:
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. No clue why or what the background there is. Seems something wrong with the scale.

imaluschi, 2021-06-10:
Helmut, I know about the discussion but it seems not that self-registering a third Sensor is possible at the moment. But anyway, it's working. PN-Sensor and DNMS sensor are the important ones to register, BMP/E or DHT will work without registering.
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

But as already mentioned, off topic ;-)

imaluschi, 2021-06-10:
It's a corrosion-Problem. Seems the Sensor is broken. Tried to lean it mechanically, no change.
In this case, I will change the noise-sensor unit.
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

hbitter, 2021-06-10:
I would say, it's looking ugly and broken.
Do you know what the black material is? Is it from the potting compound?
Regards,
Helmut

imaluschi, 2021-06-22:
I'm not really sure. It could be from the foam from the microphone windshield or biological.
Potting compound? Hmm, can't imagine.

Closed 2023-02-11.

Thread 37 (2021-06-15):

build manual: silicone cable example part and distributor

Basseuph, 2021-06-15:
I was looking a bit around for getting the cables connecting the microphone PCB, so it might be a good idea to provide some more info about them. I now ordered `SiliVolt-E` cables of the manufacturer `Stäubli Electrical Connectors`, see [Bürklin Webshop](https://www.buerklin.com/de/Silikon-Schaltlitze-h%C3%B6chstflexibel-015-mm%C2%B2-Au%C3%9Fen-%C3%98-11-mm-rot/p/94F1079) as an example distributor. Maybe you can add this to the [build manual](https://sensor.community/de/sensors/dnms/). Thank you!

hbitter, 2021-06-15:
Hi Basseuph,
good idea. I will inform ghe people mantainingthe Sensor.Community page.
In my [build manual version 2.2 ](https://github.com/hbitter/DNMS/tree/master/Manual) there is on page 58 a link to Amazon for such cables.
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

[Amazon link](https://www.amazon.de/Flexibler-Silikondraht-Elektrische-Temperaturbest%C3%A4ndigkeit-verschiedene/dp/B07PVDWC5R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)

Reagrds,
Helmut

Basseuph, 2021-06-15:
Hi Helmut,

ah I obviously missed that one. Maybe include the Amazon link in the description as well?

Anyway, thank you for your effort, especially the measurements, which show quite impressing results!

Regards,
Basseuph

Franz4596, 2021-06-20:
You get many suppliers für "silicon cabels AWG26" in ebay.de, amazon.de, aliexpress.com and electronic distributors (bürklin, conrad,...).
But Silicon is not really neccessary, you can use an usual wire (finely stranded conductor, feindrähtige Litze), more important is a short length (<25cm).
franz

Closed 2023-02-11.

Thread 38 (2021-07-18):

Airroht does not recognize DNMS

aircutter, 2021-07-18:
Hi,

not sure if this is the right place. I try anway.

I build a setup with Airrohr and Teensy 4.o according to the manaula on this page.

The Airrohr works great. The DNMS also with the USB testing software.

When I go now and combine the two the Webpage for the Sensor (Airrohr) says "Check wiring DMNS not found" (Similar to this).

I used different wires and even harwirde the connection. Seems not to be the problem. Falshing of the versions for Teensy, etc.

The only "abnormal" thing is that the Teensy LED (necx to the button) flashes with all versions. Maybe normal, maybe not ...

Now my question: HAs anybody a further idea how to debugg the situation and finding out what casues the comm issue (if it is a comm isssue)?

Thanks for your help!

Marc

hbitter, 2021-07-18:
Hi Marc,

- flashing of Teensy LED - yes, that is normal, flashing time is around 250 ms on and 250 ms off - that means firmware on Teensy is running
- following your description there must be a communication problem between NodeMCU and Teensy. Problem can be the cable or one of the I²C transceivers (P82B715)
- Cable - please recheck the connection - it may be that the cable is wrong and does not give a 1 : 1 connection for all 6 pins (an example - once the connector on one side of a bought cable was turned by 180°)
- P82B715 may be one is not soldered completely or may be one is dead after soldering?
- If you are not using the extended I²C connection between Airrohr and Teensy at all that is problem as well, because even if the connection is not too long, there is a problem running DNMS without the P82B715 transceivers on the I²C bus - it is not reliable (Look at my note about the combined version: With PCB versions DNMS-T4.0+NodeMCU-V1.x there is  ....) This would apply in the case you are not using the transceiver P82B715 on both sides.
I hope, it will help searching for the cause.
Regards,
Helmut

aircutter, 2021-07-18:
Hi Helmut,

many thanks for your insides!

I resoldered the P8s and that solved the problem. This time using a magnifying glass …

Measures values now! Nad they are showing in the community page.

Thanks!!

Marc

Hi Marc,
flashing of Teensy LED - yes, that is normal, flashing time is around 250 ms on and 250 ms off - that means firmware on Teensy is running
following your description there must be a communication problem between NodeMCU and Teensy. Problem can be the cable or one of the I²C transceivers (P82B715)
Cable - please recheck the connection - it may be that the cable is wrong and does not give a 1 : 1 connection for all 6 pins (an example - once the connector on one side of a bought cable was turned by 180°)
P82B715 may be one is not soldered completely or may be one is dead after soldering?
If you are not using the extended I²C connection between Airrohr and Teensy at all that is problem as well, because even if the connection is not too long, there is a problem running DNMS without the P82B715 transceivers on the I²C bus - it is not reliable (Look at my note about the combined version: With PCB versions DNMS-T4.0+NodeMCU-V1.x there is ....) This would apply in the case you are not using the transceiver P82B715 on both sides.
I hope, it will help searching for the cause.
Regards,
Helmut
—
You are receiving this because you authored the thread.
Reply to this email directly, view it on GitHub, or unsubscribe.

Closed 2023-02-11.

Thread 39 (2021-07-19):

Impossible DNMS Values on https://api-rrd.madavi.de/

terraformer, 2021-07-19:
Values on https://api-rrd.madavi.de/grafana/d/BYsfp-xGz/dnms?var-chipID=esp8266-9757414&orgId=1 are way off. On the Sensors Web interface everything looks good:

```
GET r: 200
output debug text to displays...
No newer version available.
.
WiFi connected, IP is: <confidential>
Starting Webserver... <confidential>

ChipId: 9757414

MAC Id: <confidential>
Read DNMS...
Trying DNMS sensor on 0x55ws: debug level ...
R/ DNMS
LAeq: 49.47
LA_MIN: 47.26
LA_MAX: 59.18
----
/R DNMS
## Sending to madavi.de:
Succeeded - api-rrd.madavi.de
Time for Sending (ms): 241
R/ DNMS
LAeq: 49.14
LA_MIN: 46.96
LA_MAX: 60.33
----
```

Current Firmware: NRZ-2020-134-B3/DE (Apr 8 2021)
Board: DNMS-T4.0+NodeMCU-V1.5
Teensy4.0 Firmware: DNMS_V2.0.5

Any ideas how to fix this? Sensor seems ok but the values in grafana are impossible and do not match with the sensor log.

terraformer, 2021-07-21:
seems as if i put this issue on the wrong repo, so i reposted it here: https://github.com/opendata-stuttgart/sensors-software/issues/907 this one here can be closed i suppose.

hbitter, 2021-07-27:
Hi terraformer,

I was out of town for some days and found your question today.
I think Pierre-Jean answered your qustion at Sensor.Community GitHub pages.
[Impossible DNMS Values on https://api-rrd.madavi.de/ #907](https://github.com/opendata-stuttgart/sensors-software/issues/907)

Getting some more reports on noise values have  [a look at this page](https://laerm.citysensor.de/l) from Reinhard Fürst (only in German).

Regards,
Helmut

Closed 2023-02-11.

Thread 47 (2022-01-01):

Ideen für einen Wetterschutz (insbesondere Regen)

linuxlurak, 2022-01-01:
Gibt es erfahrungen mit "Wetterschutz" namentlich für Regen? Ich benutze für die Mikrofonplatinen im Moment einen Plastikprimer-Spray. Je nach Installation wird das Mikro bei Regen dann trotzdem Nass.

Ein entsprechender Schaumstoffüberzug (auch gegen Wind) könnte da etwas den direkten REgen abfangen und das Wasser abtropfen lassen. Immerhin. Nach einem Halben jahr sind mir die Pesky-Mikroplatinen aber dann gestorben. Keine Messwerte mehr (nur eine 5.0 zB bei Laeq). Das Platinchen ist dann korrodiert, dort wo die Löstellen der Pins rausschauen (Bild folgt).

Bald werde ich die neuen Platinen auf der Basis von hbitter's Design ausprobieren, die keine through hole Pinlöststellen mehr aufweisen. Mal schauen wie wetterfest die sind;)

Franz4596, 2022-01-01:
Ich verwende ein d~30mm l~45mm Muff Schaumstoff-Windschutz, der etwas 5...10mm nach vorne gezogen ist, so dass ein Hohlraum entsteht. Hatte auch ein Ausfall (esp8266-1492670, #38366) würde aber nicht auf Korrosion der Lötstellen vermuten.
01/2021...01/2022 lief ein Persky/Tindy-breakout, dann deutlich niedriege SchallWerte.
01/2022... läuft ein sensormaestros -breakout.
15um Silikonschutzfolie (USA) konnte nicht besorgt werden.
Runde Breakouts ohne throuhhole pins habe ich auch eingesetzt und verfügbar (8,50€)

BasvanDrunen, 2022-01-01:
What I did is:I used the foam from a paint roller, picture attached. I mounted the mic downwards.Around the big plastic tube is a disc (not on the picture) preventing the rain to drip down from the tube into the foam.The foam has the function of wind cover as well as protection for the rain.The foam has minimal impact on the sound measurements.Best regards from the Netherlands, that is why I write in English, my German is not that good ;-)Op 1 jan. 2022 18:23 schreef franz ***@***.***>:

Ich verwende ein d30mm l45mm Muff Schaumstoff-Windschutz, der etwas 5...10mm nach vorne gezogen ist, so dass ein Hohlraum entsteht. Hatte auch ein Ausfall (esp8266-1492670, #38366) würde aber nicht auf Korrosion der Lötstellen vermuten.

01/2021...01/2022 lief ein Persky/Tindy-breakout, dann deutlich niedriege SchallWerte.

01/2022... läuft ein sensormaestros -breakout.

15um Silikonschutzfolie (USA) konnte nicht besorgt werden.

Runde Breakouts ohne throuhhole pins habe ich auch eingesetzt und verfügbar (8,50€)

—Reply to this email directly, view it on GitHub, or unsubscribe.Triage notifications on the go with GitHub Mobile for iOS or Android.

You are receiving this because you are subscribed to this thread.Message ID: ***@***.***>

BasvanDrunen, 2022-01-01:
My previous comment did not contain the images, that is why i add them now.

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

rin67630, 2022-05-16:
Sie können auf Seite 29 ff von mein Projekt lesen, wie ich das Problem gelöst habe:

Ein Garnelenfilter aus der Aquaristik und ein Edelstahltopfreiniger aus dem Supermarkt, das ist alles.

https://github.com/rin67630/Sound-pressure-level-meter-Booster/blob/master/EierlegendeWMS-Schallpegel.pdf

Kaum zu glauben, aber dadurch bleibt das Mikrofon bei Regen trocken, und Windgeräusche werden genauso gut transparent gedämpft, wie von prof. Winschutzhauben.
Dazu ist alles 100% Edelstahl und verrottet nicht.

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

rin67630, 2022-05-16:
Ich habe noch eine Beschreibung meiner Lösung gefunden.

[DFLD-Outdoor-Mikrofon.pdf](https://github.com/hbitter/DNMS/files/8702005/DFLD-Outdoor-Mikrofon.pdf)

mullercomms, 2023-02-16:
Ein komplettes Kit aus ICS-43434 breakout board, Silikonkabeln, Cavity und Silikonfolie 0,1 mm zum Wetterschutz gemäss Invense Application note AN-1124 gibt es hier:
https://www.ebay.de/itm/363608386639

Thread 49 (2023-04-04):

Arduino IDE compiling error

tk5ep, 2023-04-04:
Hi,

I try to compile your sketch with the Arduino IDE and get several errors like this :

_C:\Users\Admin\Documents\Arduino\Datas ARDUINO\NRZ-2020-134-DNMS-4.4\airrohr-firmware\airrohr-firmware.ino:3993:24: error: 'void fetchSensorPMS(String&)' was declared 'extern' and later 'static' [-fpermissive]
 3993 | static __noinline void fetchSensorPMS(String &s)_

What should I do ?

Thanks,

hbitter, 2023-04-04:
Hi,
For the Arduino IDE a file with the name platform.local.txt has to be generated and placed at the right position with the following content:

compiler.c.extra_flags=-fpermissive
compiler.cpp.extra_flags=-fpermissive

The location of the file platform.local.txt depends on the OS you are using as well on the version of the Arduino IDE you are using.

Hope this helps, please let me know.
Regards,
Helmut

tk5ep, 2023-04-04:
Hi, and thanks for fast anwers.
To find he right location, I've made the compiler verbose and on top of the compiler output, I have :

_Using board 'nodemcuv2' from platform in folder: C:\Users\Admin\AppData\Local\Arduino15\packages\esp8266\hardware\esp8266\3.1.2
Using core 'esp8266' from platform in folder: C:\Users\Admin\AppData\Local\Arduino15\packages\esp8266\hardware\esp8266\3.1.2_

Si, I guess, it's the right place where I found a platform.txt file.
I've added the suggested platform.local.txt, with the following lines :

compiler.c.extra_flags=-fpermissive
compiler.cpp.extra_flags=-fpermissive

But unfortunately, I have the same errors.
I'm using IDE 2.0.4 and Windows 10.

Thanks,
Patrick

tk5ep, 2023-04-04:
Helmut,
I had to restart the IDE to get better results !
It seems that the errors are now warnings, but I still have an error at the end.

Most make reference to :

undefined reference to `_ZN17LiquidCrystal_I2C9setCursorEhh
undefined reference to `_ZN11TinyGPSPlusC1Ev'

Perhaps a library version problem ?
What libraries must be used for tinygps and liquidcrystal ?

Here what I get at compiler end :

Using library LittleFS at version 0.1.0 in folder: C:\Users\Admin\AppData\Local\Arduino15\packages\esp8266\hardware\esp8266\3.1.2\libraries\LittleFS
Using library ESP8266HTTPClient at version 1.2 in folder: C:\Users\Admin\AppData\Local\Arduino15\packages\esp8266\hardware\esp8266\3.1.2\libraries\ESP8266HTTPClient
Using library ESP8266WiFi at version 1.0 in folder: C:\Users\Admin\AppData\Local\Arduino15\packages\esp8266\hardware\esp8266\3.1.2\libraries\ESP8266WiFi
Using library ESP8266WebServer at version 1.0 in folder: C:\Users\Admin\AppData\Local\Arduino15\packages\esp8266\hardware\esp8266\3.1.2\libraries\ESP8266WebServer
Using library ESP8266mDNS at version 1.2 in folder: C:\Users\Admin\AppData\Local\Arduino15\packages\esp8266\hardware\esp8266\3.1.2\libraries\ESP8266mDNS
Using library EspSoftwareSerial at version 8.0.1 in folder: C:\Users\Admin\AppData\Local\Arduino15\packages\esp8266\hardware\esp8266\3.1.2\libraries\SoftwareSerial
Using library Hash at version 1.0 in folder: C:\Users\Admin\AppData\Local\Arduino15\packages\esp8266\hardware\esp8266\3.1.2\libraries\Hash
Using library ESP8266 and ESP32 OLED driver for SSD1306 displays at version 4.3.0 in folder: C:\Users\Admin\Documents\Arduino\libraries\ESP8266_and_ESP32_OLED_driver_for_SSD1306_displays
Using library Wire at version 1.0 in folder: C:\Users\Admin\AppData\Local\Arduino15\packages\esp8266\hardware\esp8266\3.1.2\libraries\Wire
Using library ArduinoJson at version 6.21.1 in folder: C:\Users\Admin\Documents\Arduino\libraries\ArduinoJson
Using library DNSServer at version 1.1.1 in folder: C:\Users\Admin\AppData\Local\Arduino15\packages\esp8266\hardware\esp8266\3.1.2\libraries\DNSServer
Using library Adafruit HTU21DF Library at version 1.1.0 in folder: C:\Users\Admin\Documents\Arduino\libraries\Adafruit_HTU21DF_Library
Using library Adafruit BusIO at version 1.14.1 in folder: C:\Users\Admin\Documents\Arduino\libraries\Adafruit_BusIO
Using library SPI at version 1.0 in folder: C:\Users\Admin\AppData\Local\Arduino15\packages\esp8266\hardware\esp8266\3.1.2\libraries\SPI
Using library Adafruit BMP085 Library at version 1.2.2 in folder: C:\Users\Admin\Documents\Arduino\libraries\Adafruit_BMP085_Library
Using library Adafruit SHT31 Library at version 2.2.0 in folder: C:\Users\Admin\Documents\Arduino\libraries\Adafruit_SHT31_Library
Using library DallasTemperature at version 3.9.0 in folder: C:\Users\Admin\Documents\Arduino\libraries\DallasTemperature
Using library OneWire at version 2.3.7 in folder: C:\Users\Admin\Documents\Arduino\libraries\OneWire
Using library SparkFun SCD30 Arduino Library at version 1.0.20 in folder: C:\Users\Admin\Documents\Arduino\libraries\SparkFun_SCD30_Arduino_Library
Using library SparkFun SCD4x Arduino Library at version 1.0.4 in folder: C:\Users\Admin\Documents\Arduino\libraries\SparkFun_SCD4x_Arduino_Library
Using library Sensirion I2C SEN5X at version 0.3.0 in folder: C:\Users\Admin\Documents\Arduino\libraries\Sensirion_I2C_SEN5X
Using library Sensirion Core at version 0.6.0 in folder: C:\Users\Admin\Documents\Arduino\libraries\Sensirion_Core
exit status 1

Compilation error: exit status 1

regards,,
Patrick

hbitter, 2023-04-04:
Hi Patrick,

TinyGPSPlus is: Version 1.0.3 TinyGPSPLus by Mikal Hart
LiquidCrystal is: Version 1.1.2 LiquidCrystal I2C by Frank de Brabander

Regards,
Helmut

tk5ep, 2023-04-04:
Helmut,

There are sooooo many different libraries for the Tinygps and liquidcrystal !

I installed the right TinyGPSplus library  and already had to good one for liquidcrystal. I had to force the use of the good one, as I have 2 different installed.

Now the tinygps errors are gone, but I still have the liquidcrystal errors showing up !
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
hbitter, 2024-05-31:
Hi Ursu-Alex,

you wrote: "I have a similar issue with with your current board which runs on esp32 architecture(s)."

Does it mean you try to compile for ESP32???

If yes, that is not supported from my side. The Airrohr-Board is an Board for NodeMCU ESP8266. The NodeMCU firmware can run on other ESP866 systems as well (Wemos e.g.). In the firmware there are a couple of Ifdefs for ESP32, because the whole firmware is a fork of the Sensor,community firmware with specific additions for DNMS.

The Sensor.Community firmware does support basic DNMS features but not the full functionality. I don't know if there is a ESP32 version available from Sensor.Community.

If you try to compile for ESP8266 let me know, so that we can try to identify the problem.

Regards,
Helmut

Ursu-Alex, 2024-05-31:
Hi , so i run the code on a ESP32 but the same code works 2 days ago and now just don't ....

hbitter, 2024-05-31:
Hi Ursu-Alex,
I don't fully understand your answer. Do you mean, you could compile the code 2 days ago for an ESP32 and now compilation gives the errors. I didn't update GitHub within the last 2 days.

Question is, how can I help you?

Regards,
Helmut

Ursu-Alex, 2024-05-31:
Hi , yes , 2 days ago the same code was working , i didn't change anything and now it doesn't work . Even the examples from library don't work .

hbitter, 2024-05-31:
Hi Ursu-Alex,

would you mind to give some more details:
- what HW are you using?
- Arduino IDE version, which Board is selected, what is selected under Tools (screenshots e.g)?
- which examples from which library?

Regards,
Helmut

Ursu-Alex, 2024-05-31:
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

hbitter, 2024-05-31:
Hi Ursu-Alex,

you are trying to compile for ESP32 an example (probably BasicWrite.ino from https://github.com/tobiasschuerg/InfluxDB-Client-for-Arduino) as far as I can see.
Sorry, but I cannot help. I have experience with that libraray and it is in no way linked to DNMS.

Regards,
Helmut

Closed 2024-06-06.

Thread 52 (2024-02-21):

Final version IM72D128 pcb's and components?

pe0ter, 2024-02-21:
Good morning Helmut,
Both pcb's regarding IM72D128 are now 7 months in this repository.
I wish to order a bunch of sets with pre-soldered components in China
What are your experiences up-to now? Will there be changes to these pcb's in the near future?
Best regards,
Peter

hbitter, 2024-02-21:
Hi Peter,

the experiences with IM72D128 are quite good. There will be no changes except, that I will update the files to KiCad Version 7. We just recently did measurements with the first IM72D128 microphones produced by the company Watterott electronic GmbH. I will publish the results here in the repository in a couple of days. The company Watterott electronic GmbH will start with a small batch series. If you are interested, please contact them directly: https://shop.watterott.com/Contact

Regards,
Helmut

Closed 2024-04-28.

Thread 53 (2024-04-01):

WLAN integration not possible

erduino, 2024-04-01:
I can select the WLAN and enter and save the WLAN password, but the NODE MCU does not connect to the selected WLAN. The original WLAN remains. However, the new WLAN SSID is in the input mask.
I'm using a developer board with an ESP07 with an external antenna connection due to range issues.
I use ESPHOME 64bit with Windows 10 and Edge Browser. I've already tried all *.ino.bin versions including the old versions.
Also no API configuration possible like with #50.

erduino, 2024-04-01:
Hallo Helmut

Danke für die schnelle Reaktion.

Interessanterweise werden die Eingabemasken nun mit Edge auf Windows 10 richtig angezeigt. Das einzige was ich gemacht habe ist den PC neu gestartet. Habs dann noch via Windows 7 und Firefox getestet, hier wird im Gegensatz zu Windows 10, das PW airrohrcfg verlangt sonst gehts nicht weiter. Dort stimmen die Maken nun auch wie gewohnt.

Trotzdem gelingt es nicht mit dem neuen WLAN zu connecten. Putty bringt nun ff. Meldung:

ws: not found ...
ws: not found ...
ws: config page ...
output debug text to displays...
Saving config...
failed to open config file for writing
ws: not found ...
ws: not found ...
ws: not found ...
ws: not found ...
ws: config page ...
begin webserver_config_body_get ...
wifi networks found: 3
ws: wifi ...
ws: not found ...
ws: not found ...
 

nach mehreren Minuten habe ich das WLAN meines PC's (Seymchan) wieder mit dem Internet verbunden. NODEMCU aber immer angestöpselt gelassen.

Nach weiteren mehreren Minuten zeigt Putty plötzlich folgendes:

ws: not found ...
ws: not found ...
Connecting to Seymchan
---- Result Webconfig ----
WLANSSID: Seymchan
----
PPD: 0
SDS: 0
PMS: 0
HPM: 0
SPS30: 0
NPM: 0
DHT: 0
DS18B20: 0
HTU21D: 0
BMP: 0
DNMS: 1
DNMS READ SPECTRUM: 0
----
SensorCommunity: 0
Madavi: 0
CSV: 0
----
Autoupdate: 0
 

Das von der NODEMCU aufgespannte Netwerk ist nun nicht mehr sichtbar, er hat eine IP bekommen 

Display: 0
LCD 1602: 0
Debug: 3
...SNTP synced: Mon Apr  1 17:59:10 2024

.
WiFi connected, IP is: 192.168.8.104
Starting Webserver... 192.168.8.104

ChipId: 8568660

MAC Id: 84cca882bf54
Read DNMS...
Trying DNMS sensor on 0x55H  ... not found
Check DNMS wiring
Send to :
----
ws: root ...
ws: status ...
ws: root ...
ws: status ...
ws: root ...
ws: config page ...
begin webserver_config_body_get ...
ws: config page ...
output debug text to displays...
Saving config...
failed to open config file for writing
ws: root ...
ws: config page ...
begin webserver_config_body_get ...

Immer wenn ich eine Konfig Änderung mache meldet Putty

Saving config...
failed to open config file for writing

aber die Änderungen wurden übernommen. Hm, alles in allem merkwürdiges Verhalten. 

Nun mache ich an der NodeMCU einen Reset

und es beginnt von vorne, er spannt wieder sein WLAN auf und man kann ihn unter 192.168.4.1 erreichen, alle Einstellungen sind wieder weg!?

ws: not found ...
ws: config page ...
begin webserver_config_body_get ...
ws: not found ...
ws: config page ...
begin webserver_config_body_get ...
ws: not found ...
ws: not found ...
 

Beste Grüsse

erduino

Gesendet: Montag, 01. April 2024 um 18:25 Uhr
Von: "Helmut Bitter" ***@***.***>
An: "hbitter/DNMS" ***@***.***>
Cc: "erduino" ***@***.***>, "Author" ***@***.***>
Betreff: Re: [hbitter/DNMS] WLAN integration not possible (Issue #53)

Hi erduino,

	can you tray to access the NodeMCU with a diffenrent Web Browser instead of Edge Browser (Mozilla, Chrome, Brave). It is possible that your problem is linked to #50. It may be the case that the WLAN password is not taken over due to incorrect behaviour between the browser and the firmware on the NodeMCU.
	could you run a terminal program on your PC (PuTTY, Cool Term or similar) to get the output of the NodeMCU at startup after input of the new WLAN SSID, password and restart of NodeMCU. That could give information that the NodeMCU tries to connect to the new SSID but with now success, maybe because of not updated password.

Regards,

Helmut

—
Reply to this email directly, view it on GitHub, or unsubscribe.
You are receiving this because you authored the thread.Message ID: ***@***.***>

hbitter, 2024-04-01:
Hallo erduino,

- wieviel Flash Speicher hat das Board, das Du benutzt? Der ESPHome-Flasher zeigt das u.a. an. Wenn das Board nur 1MB hat, funktioniert es nicht mit dem Board. NodeMCU Boards u.a. haben 4MB.
- ein anderes Problem kann noch die Zuordnung der I²C Pins zu den GPIO-Pins sein. Sensor.Community hatte da für SCL GPIO2 und für SDA GPIO0 ursprünglich gewählt. Das führt bei einigen Boards (z.B. Wemos D1 mini) zu Problemen. Deshalb habe ich auf der DNMS Konfigurations Seite die Möglichkeit eingeführt andere GPIOs für die I²C Schnittstelle zu wählen (z.B. SCL = GPIO5 und SDA = GPIO4)

Viele Grüße

Helmut

erduino, 2024-04-01:
das Board hat leider nur 1 MB Flash Speicher. Das ist mit grosser Wahrscheinlichkeit das Problem.

Schade, das Board mit einem ESP07 Modul und Keramikantenne sowie ext. Antennenanschluss wäre eine gute Alternative zur Verbesserung der Reichweite gewesen (+6dB). 

Bemerkenswert ist aber noch, dass das Board die Integration ins WLAN nach einer gewissen (langen) Zeit dann trotzdem schaft aber eben dann nach einem Stromunterbruch oder Reset die Konfiguration wieder verliert.

Aber trotzdem vielen Dank für deine schnelle und hilfreiche Reaktion. Wie immer Super Service.

Beste Grüsse

Erwin

Gesendet: Montag, 01. April 2024 um 23:03 Uhr
Von: "Helmut Bitter" ***@***.***>
An: "hbitter/DNMS" ***@***.***>
Cc: "erduino" ***@***.***>, "Author" ***@***.***>
Betreff: Re: [hbitter/DNMS] WLAN integration not possible (Issue #53)

Hallo erduino,

	wieviel Flash Speicher hat das Board, das Du benutzt? Der ESPHome-Flasher zeigt das u.a. an. Wenn das Board nur 1MB hat, funktioniert es nicht mit dem Board. NodeMCU Boards u.a. haben 4MB.
	ein anderes Problem kann noch die Zuordnung der I²C Pins zu den GPIO-Pins sein. Sensor.Community hatte da für SCL GPIO2 und für SDA GPIO0 ursprünglich gewählt. Das führt bei einigen Boards (z.B. Wemos D1 mini) zu Problemen. Deshalb habe ich auf der DNMS Konfigurations Seite die Möglichkeit eingeführt andere GPIOs für die I²C Schnittstelle zu wählen (z.B. SCL = GPIO5 und SDA = GPIO4)

Viele Grüße

Helmut

—
Reply to this email directly, view it on GitHub, or unsubscribe.
You are receiving this because you authored the thread.Message ID: ***@***.***>

hbitter, 2024-04-02:
Hallo Erwin,

eine gute Alternative zum NodeMCU Board ist Wemos D1 mini (pro, lite), da gibt es welche mit Keramikantenne und externem Antennanschluss. Die Boards haben 4MB Flash. Die I²C Schnittstelle muss allerdings auf andere Pins gelegt werden (z.B. SCL = GPIO5/D1 und SDA =GPIO4/D2).

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

Viele Grüße

Helmut

pe0ter, 2024-04-02:
There is also a version of the NodeMCU with the ESP-07S chip that contains 4MB of memory.

erduino, 2024-04-02:
That's right but I didn't find a version with an external antenna, they all only have a PCB antenna

Gesendet: Dienstag, 02. April 2024 um 09:08 Uhr
Von: "pe0ter" ***@***.***>
An: "hbitter/DNMS" ***@***.***>
Cc: "erduino" ***@***.***>, "Author" ***@***.***>
Betreff: Re: [hbitter/DNMS] WLAN integration not possible (Issue #53)

There is also a version of the NodeMCU with the ESP-07S chip that contains 4MB of memory.

—
Reply to this email directly, view it on GitHub, or unsubscribe.
You are receiving this because you authored the thread.Message ID: ***@***.***>

erduino, 2024-04-02:
 

Hallo Helmut,

ja das Board kenne ich und habe es auch für andere Zwecke im Einsatz.

Den Einsatz im DNMS habe ich weniger in Erwägung gezogen wegen der Steckerkompatiblität. Da müsste ich ein Adapterboard machen, deshalb wäre die NodeMCU mit dem ESP07 praktisch gewesen.

Mal schauen, es gibt noch Boards mit ESP32 und externer Antenne. Vielleicht sind die Steckerkompatibel.

Schöne Grüsse

Erwin

Gesendet: Dienstag, 02. April 2024 um 08:53 Uhr
Von: "Helmut Bitter" ***@***.***>
An: "hbitter/DNMS" ***@***.***>
Cc: "erduino" ***@***.***>, "Author" ***@***.***>
Betreff: Re: [hbitter/DNMS] WLAN integration not possible (Issue #53)

Hallo Erwin,

eine gute Alternative zum NodeMCU Board ist Wemos D1 mini (pro, lite), da gibt es welche mit Keramikantenne und externem Antennanschluss. Die Boards haben 4MB Flash. Die I²C Schnittstelle muss allerdings auf andere Pins gelegt werden (z.B. SCL = GPIO5/D1 und SDA =GPIO4/D2).

image.png (view on web)

Viele Grüße

Helmut

—
Reply to this email directly, view it on GitHub, or unsubscribe.
You are receiving this because you authored the thread.Message ID: ***@***.***>

hbitter, 2024-04-02:
Hallo Erwin,

ich habe versuchsweise mal eine Firmware für ESP8266 mit 1MB Flash erzeugt. Ich habe kein ESP8266 Board mit 1MB und kann das nicht testen. Wenn Du Interesse hast das zu testen, kann ich Dir die Version gerne zusenden. Einfach eine PM an mich (helmut.bitter (at) t-online.de mit deiner Mail Adresse.

Viele Grüße

Helmut

Closed 2024-04-28.

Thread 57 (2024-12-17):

Not an issue, just a question

mark-joe, 2024-12-17:
Hello all,

I see a Raspberry software section that interfaces with a MEMS microphone, but I do not see a connection diagram. Do you connect Raspberry direct to the DNMS board (with the Teensy) or is it done differently? Thanks!

hbitter, 2024-12-17:
Hi mark-joe,

the connection between the Raspberry and the DNMS Teensy board is the same as the connection between the NodeMCU and the DNMS Teensy board. Basically it is an I²C connection. I²C is limited in cable length, so we use an extended version that allows a cable length of 10m between the two systems. You can either make a direct short I²C connection between the Raspberry and the DNMS Teensy board or use the extended I²C connection. We have provided a small Raspberry DNMS-Hat [https://github.com/hbitter/DNMS/tree/master/PCBs/DNMS-RPI-HAT](https://github.com/hbitter/DNMS/tree/master/PCBs/DNMS-RPI-HAT) that implements the extended I²C connection for the Raspberry.

Regards,
Helmut

mark-joe, 2024-12-17:
Hi Helmut

Thank you for your prompt reply, *much appreciated*. I now have a sound measuring system with a ICS-43434, but the  IM72D128V01 seems attractive as it is waterproof.  Also replacing a microcontroller with a raspberry is attractive as I just can login and update the code (otherwise I have to climb on the roof and get the microcontroller, flash it, and return it to the roof). Well, I'll see what it will be. Thanks again! Mark

Closed 2024-12-17.

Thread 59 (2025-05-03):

Frage zu I2C Decibel Sound Level Meter

klacol, 2025-05-03:
Hallo, ihr kennt euch hier anscheinend sehr gut aus mit Lärmmessung. Ich wohne an einer lauten Straße und interessiere mich daher auch dafür.

Ich habe mir diesen Sensor aus Indien bestellt: https://pcbartists.com/product/i2c-decibel-sound-level-meter-module/

War mit ca. 60 Euro gar nicht mal so preiswert, finde ich. Ich habe die Version ``Spectrum-Analyser`` an einen ESP32 angeschlossen und publiziere die Messwerte via MQTT in mein Home Assistant. Die Varianten ``PRO`` habe ich auch gekauft, aber noch nicht ausprobiert.

Ich kenne mich mit Lärmmessung überhaupt nicht aus. Was sagt ihr als Fachleute zu den Sensoren? Ihr habe ja dieses Rohr, das ist anscheinend wichtig, oder?

hbitter, 2025-05-07:
Hallo klacol,

den von Dir erwähnten Sensor kenne ich nicht und kann deshalb zu der Qualität nichts sagen. Wenn ich mir die Webseite ansehe und die verschiedenen Versionen vergleiche, kann ich folgendes sagen:
- Frequenzbereich ist bei allen Versionen eingeschränkt (PRO 20 - 8000 Hz) - sicher geht der Bereich oberhalb 10000 - 12500 Hz bei Umweltlärm nicht besonders ein aber 8000 Hz ist vielleicht etwas knapp.
- Nur die PRO Version bietet, so wie ich das sehe,  LAeq Werte d.h. den A-bewerteten äquivalenten Dauerschallpegel (oder die über den Zeitbereich gemittelte Energie).  Darauf beruhen alle Regelungen zum Lärm.

Mir ist nicht klar, was Du mit dem Rohr meinst? Meinst Du das Mikrofon im 1/2" Rohr? Könntest Du Deine Frage noch präzisieren.

Viele Grüße

Helmut

klacol, 2025-05-07:
Hallo Helmut,

danke für die Einschätzung. Ich habe mir schon gedacht, dass man am besten die PRO Version nutzen sollte.

Ja, ich meine das Mikrofon in dem Rohr. Ich hatte gar nicht verstanden, dass das Mikrofon in dem Rohr ist. Das wird vermutlich einen Grund in der Akustik oder Messtechnik haben, oder warum packt man das Mikrofon in ein Rohr?
Gruß Klaus

hbitter, 2025-05-07:
Hallo klacol,

bei Messmikrofonen ist es sehr gebräuchlich, dass das Mikrofon in einem Rohr mit dem Durchmesser von 1/2" sitzt.
- dieser Standard erlaubt die Verwendung von sogenannten Kalibratoren, die auf das 1/2" Rohr aufgesteckt werden, um das Mikrofon meist mit einem Sinus von 1000 Hz und einem Schalldruck von 94 dB (oder auch 114 dB) zu überprüfen.
- Aufgrund der runden Form und des relativ kleinen Durchmessers ergeben sich auch akustische Vorteile. Es gibt weniger Reflexionen, die das Messergebnis verfälschen. Es sollten insgesamt vom Gehäuse möglichst wenig Reflexionen erzeugt werden, deshalb Rohr und konische Formen bei den Messmikrofonen.
Aus diesen Gründen haben wir ein Rohr mit 1/2" Durchmesser gewählt. Die Korrektur des Frequenzgangs bezieht sich nicht nur auf das Mikrofon selbst sondern auch auf den Einbau und das Gehäuse.

Viele Grüße
Helmut

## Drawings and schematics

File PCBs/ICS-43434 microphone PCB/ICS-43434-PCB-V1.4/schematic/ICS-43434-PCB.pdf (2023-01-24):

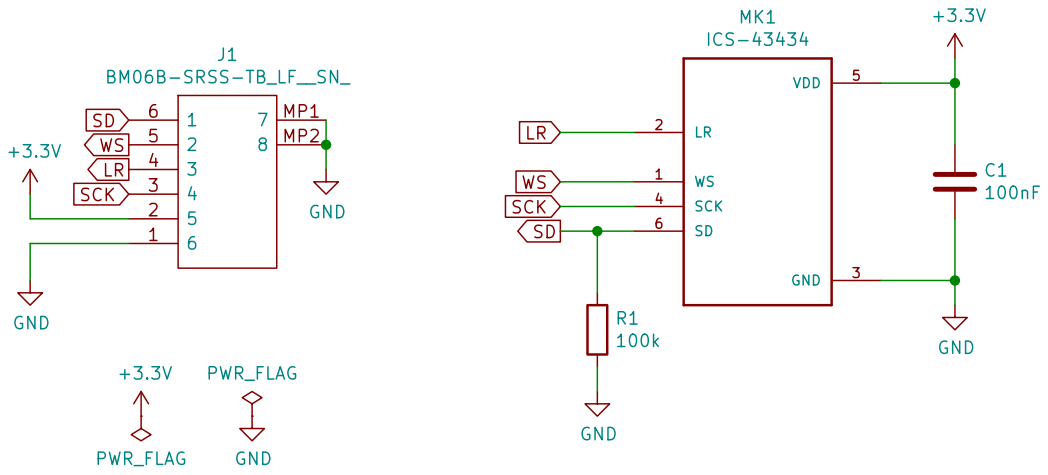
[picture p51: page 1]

File: ICS-43434-PCB.kicad_sch Sheet: / PWR_FLAG

Id: 1/1 Title: ICS-43434-PCB

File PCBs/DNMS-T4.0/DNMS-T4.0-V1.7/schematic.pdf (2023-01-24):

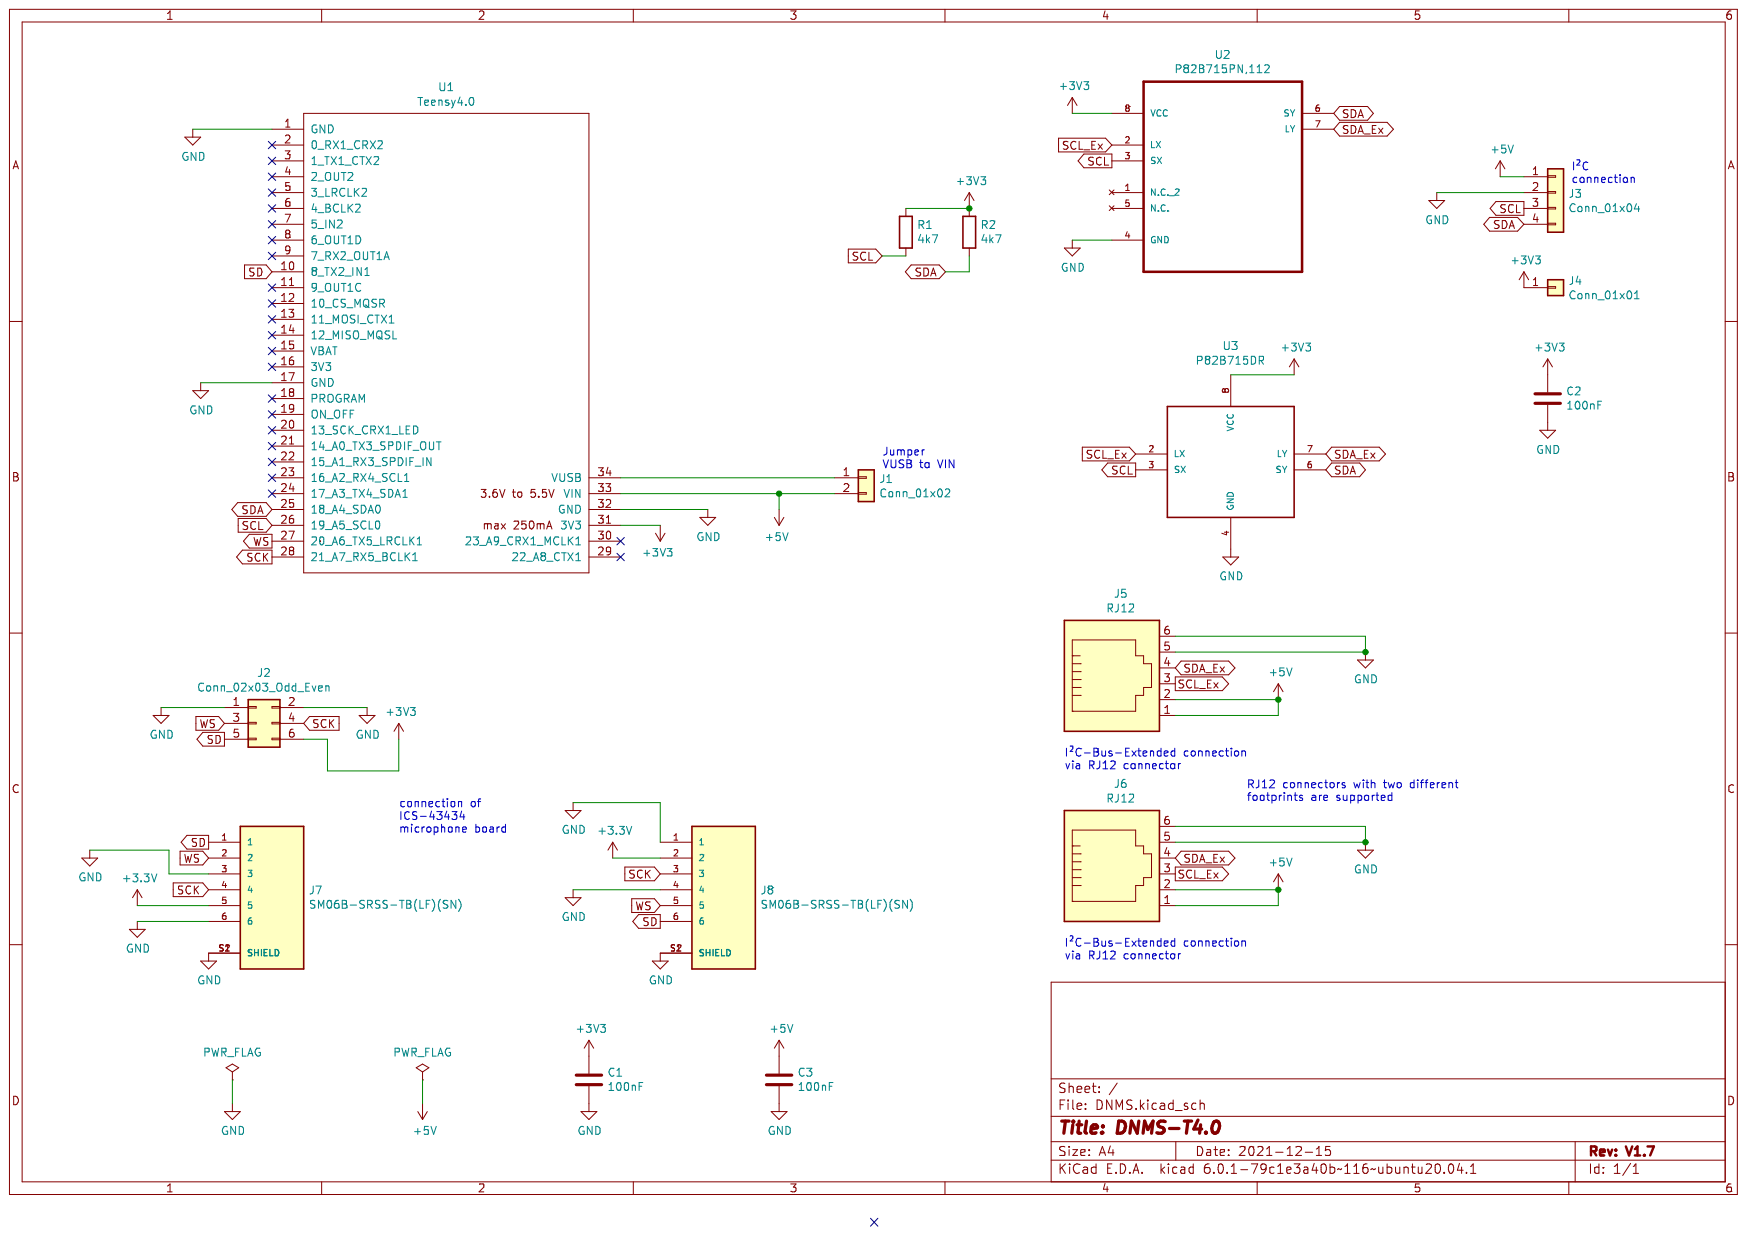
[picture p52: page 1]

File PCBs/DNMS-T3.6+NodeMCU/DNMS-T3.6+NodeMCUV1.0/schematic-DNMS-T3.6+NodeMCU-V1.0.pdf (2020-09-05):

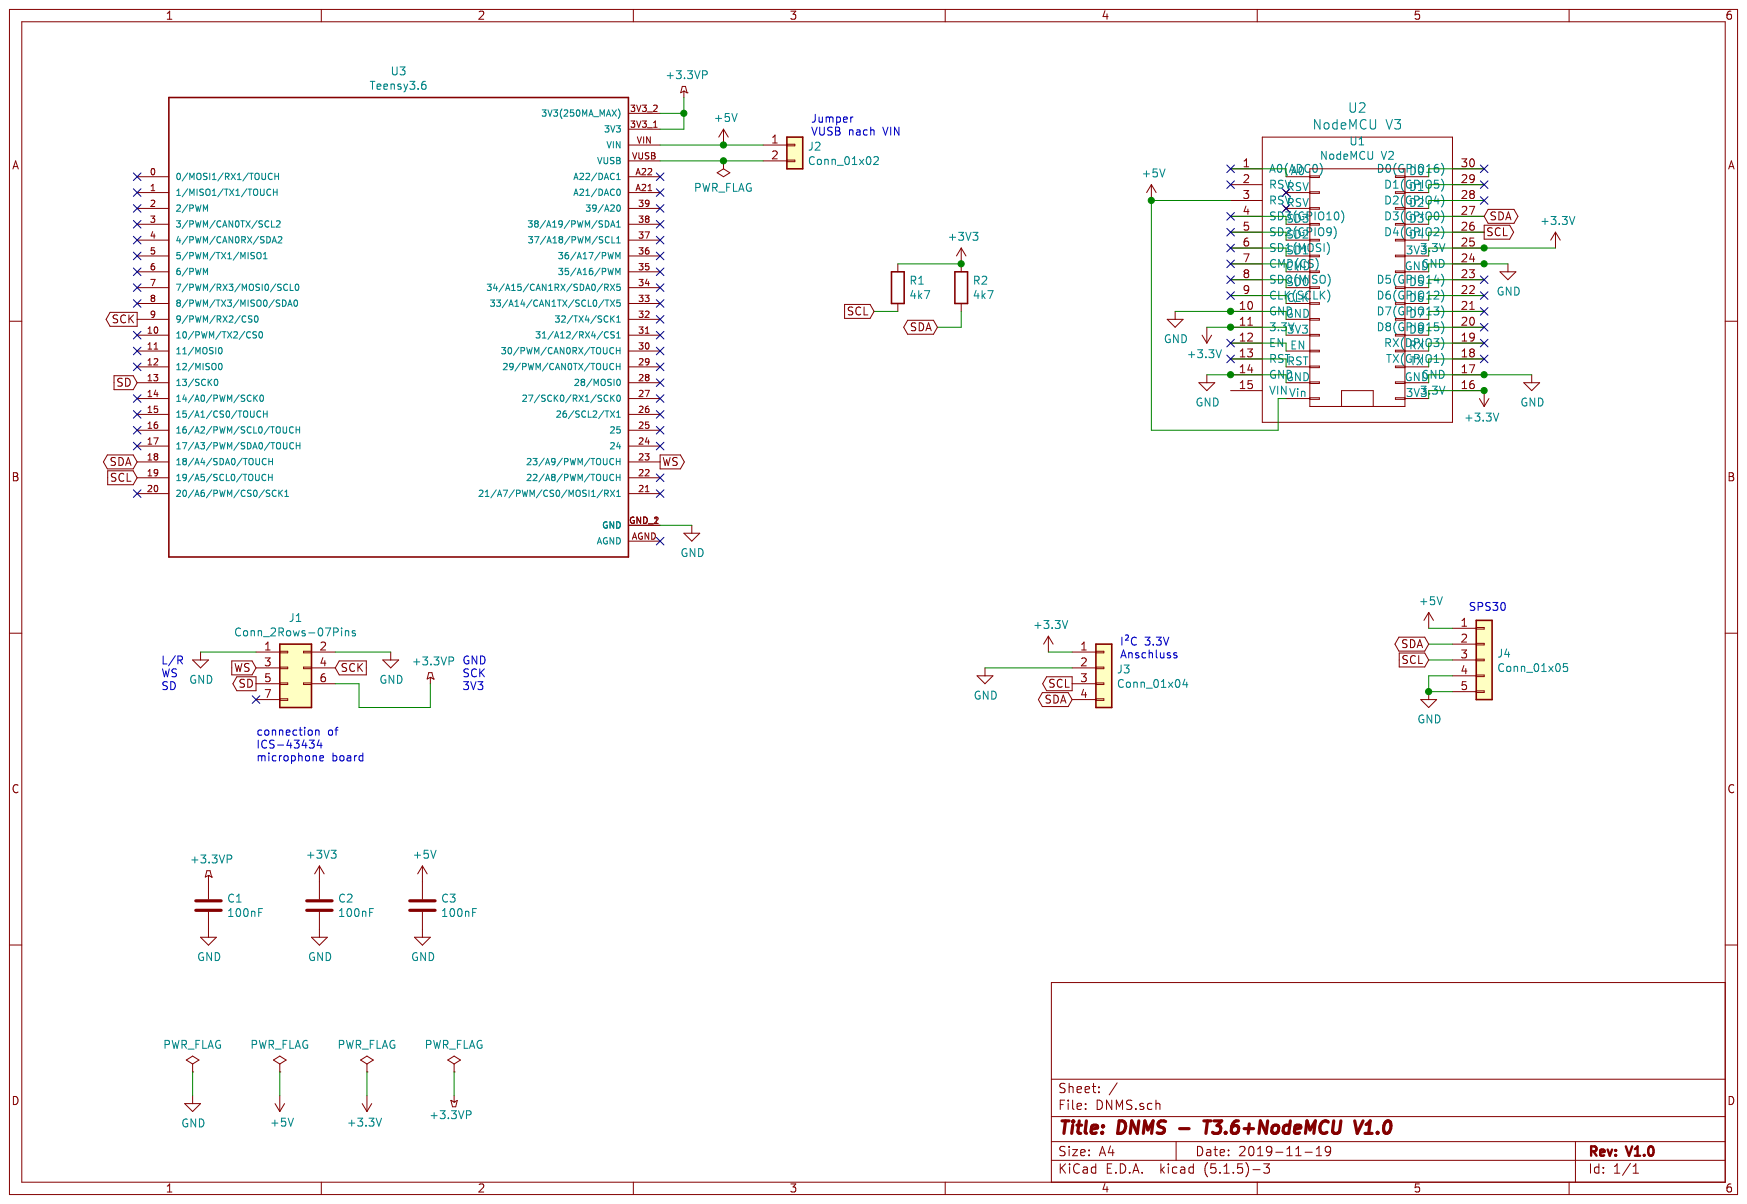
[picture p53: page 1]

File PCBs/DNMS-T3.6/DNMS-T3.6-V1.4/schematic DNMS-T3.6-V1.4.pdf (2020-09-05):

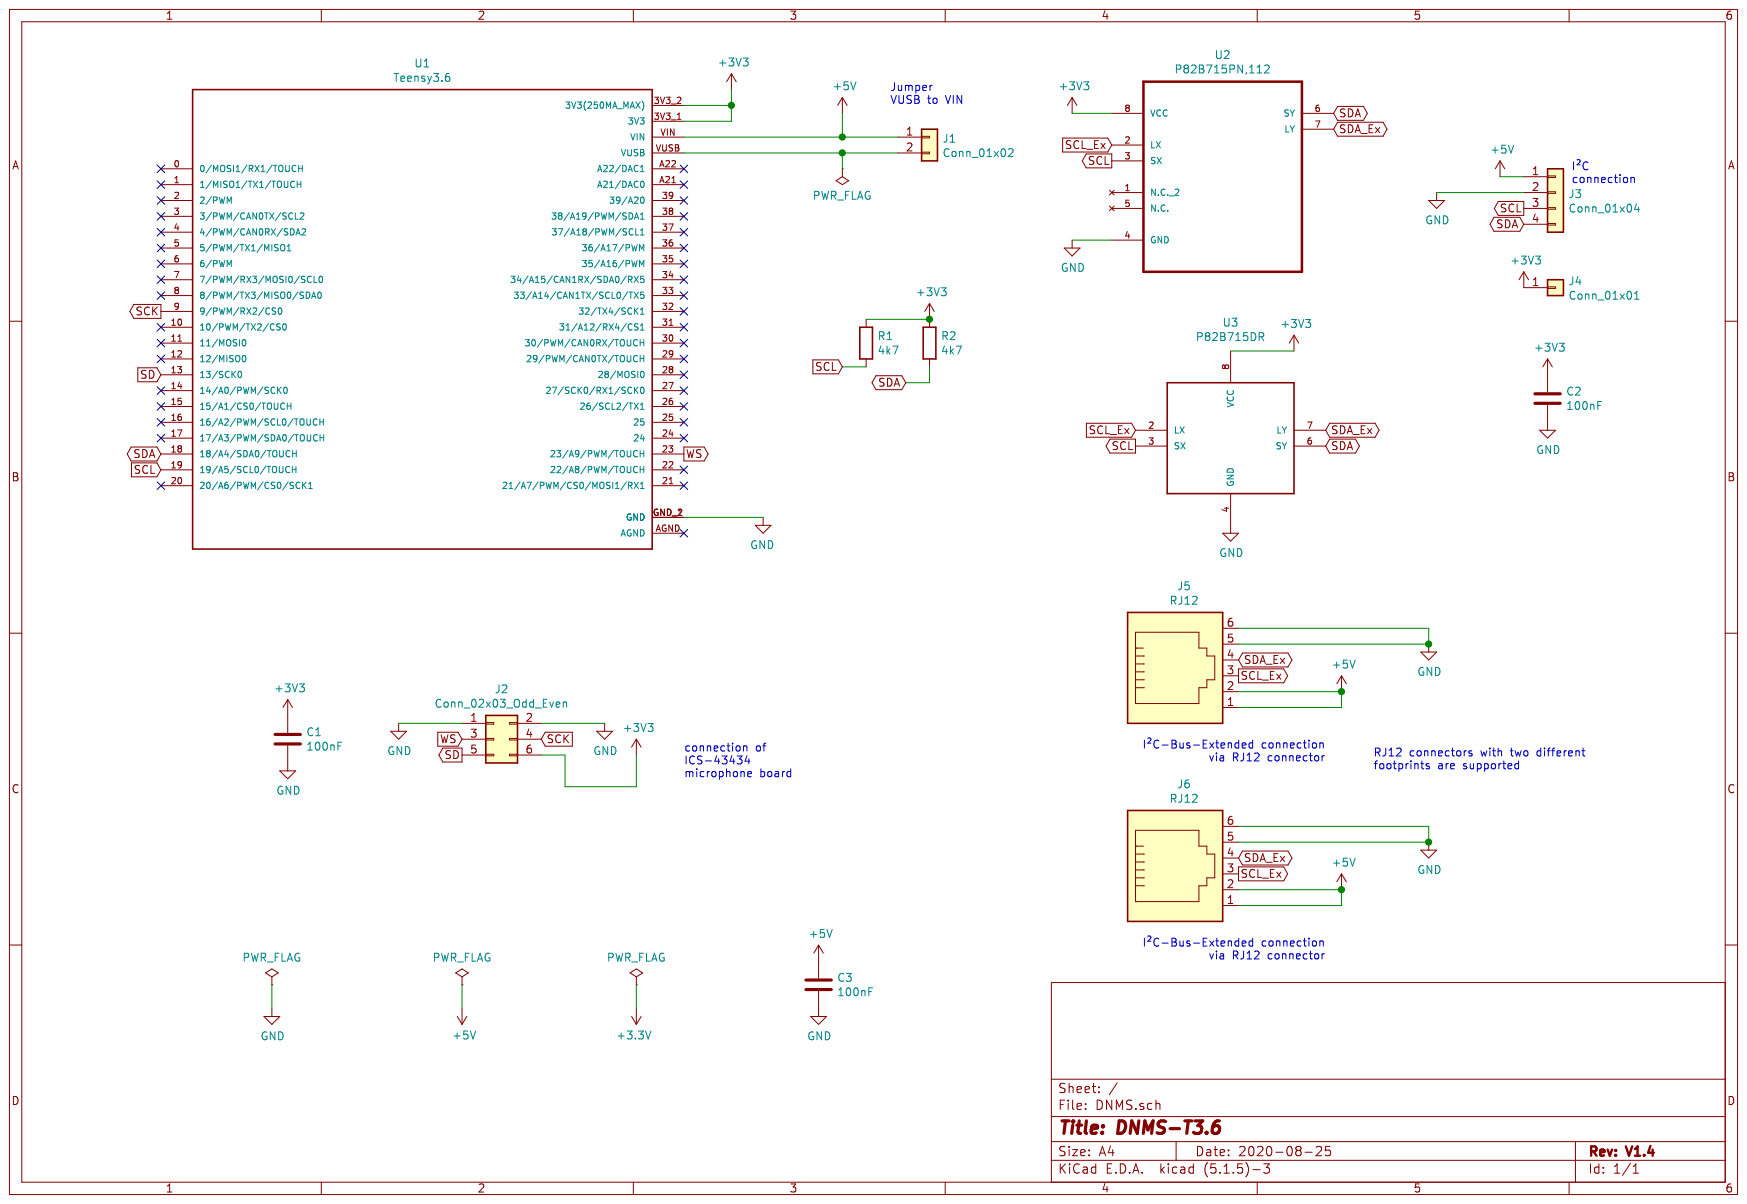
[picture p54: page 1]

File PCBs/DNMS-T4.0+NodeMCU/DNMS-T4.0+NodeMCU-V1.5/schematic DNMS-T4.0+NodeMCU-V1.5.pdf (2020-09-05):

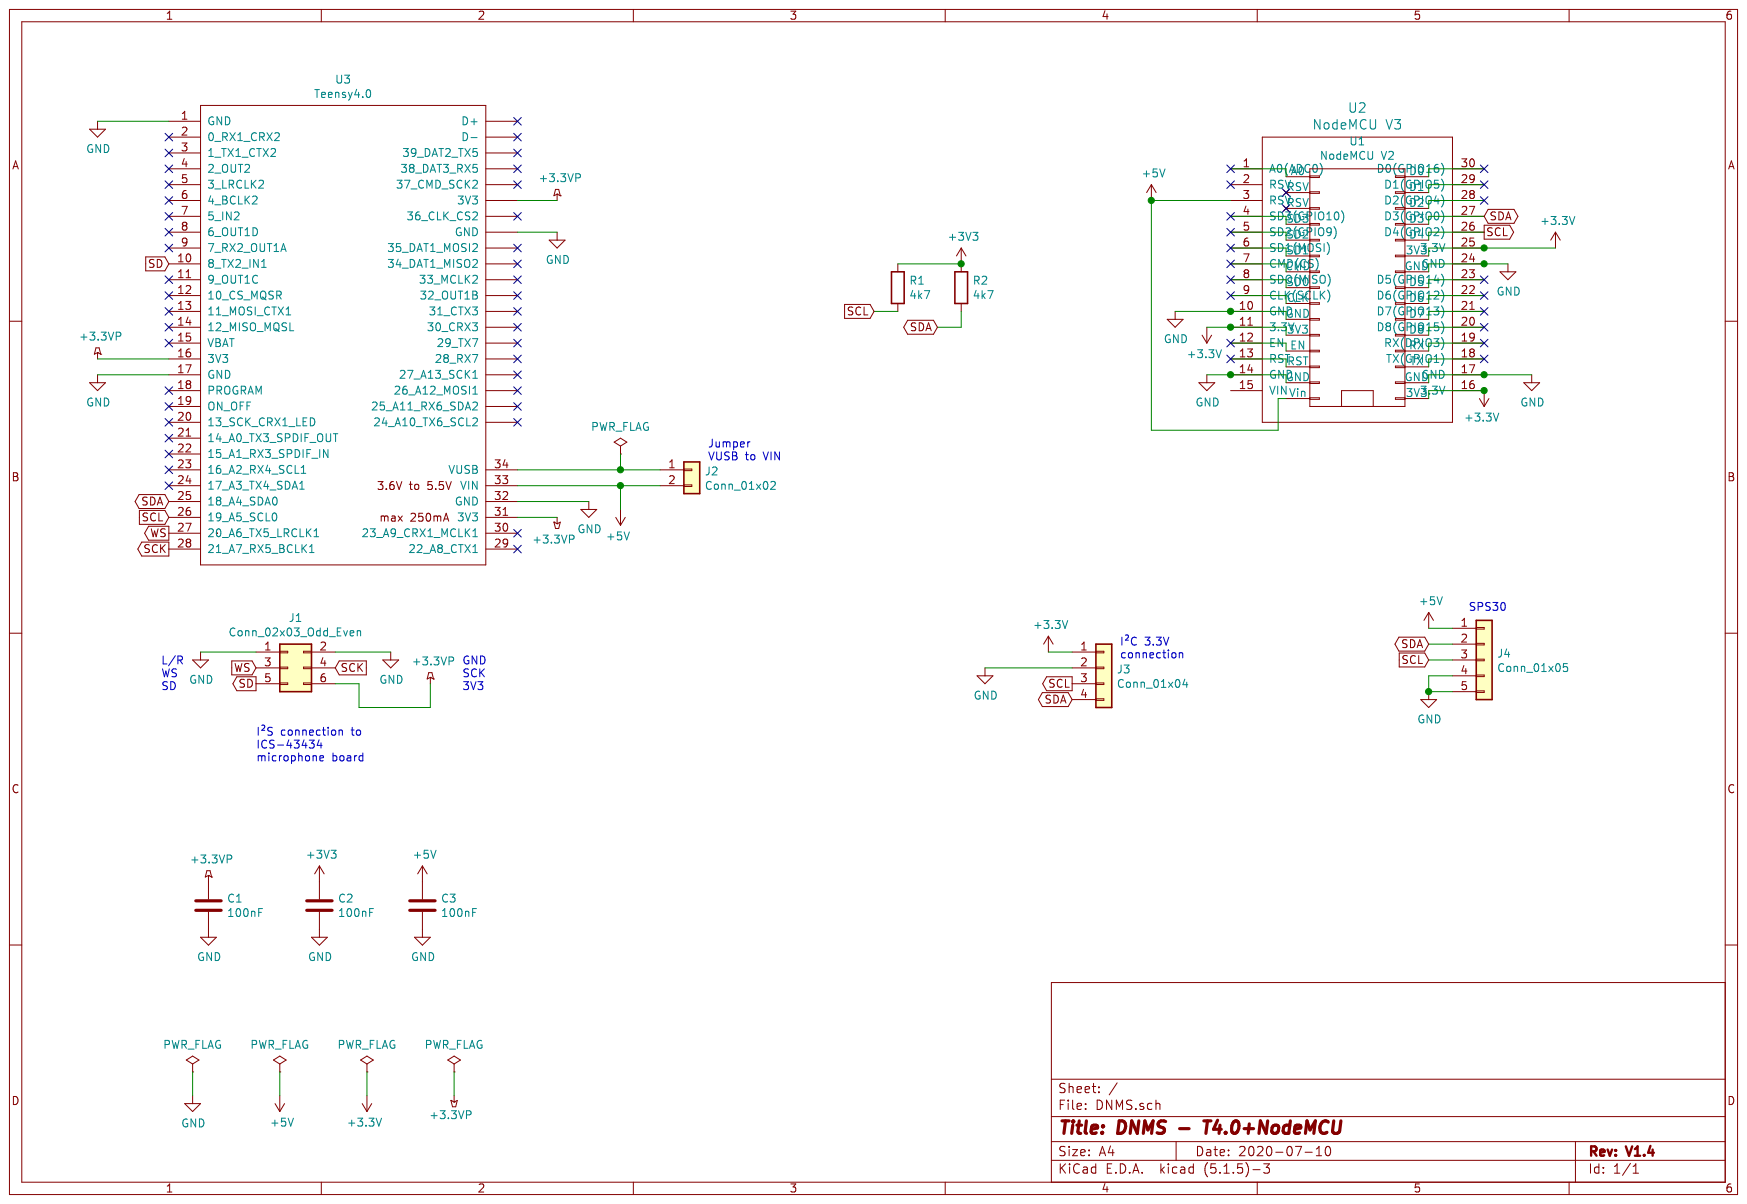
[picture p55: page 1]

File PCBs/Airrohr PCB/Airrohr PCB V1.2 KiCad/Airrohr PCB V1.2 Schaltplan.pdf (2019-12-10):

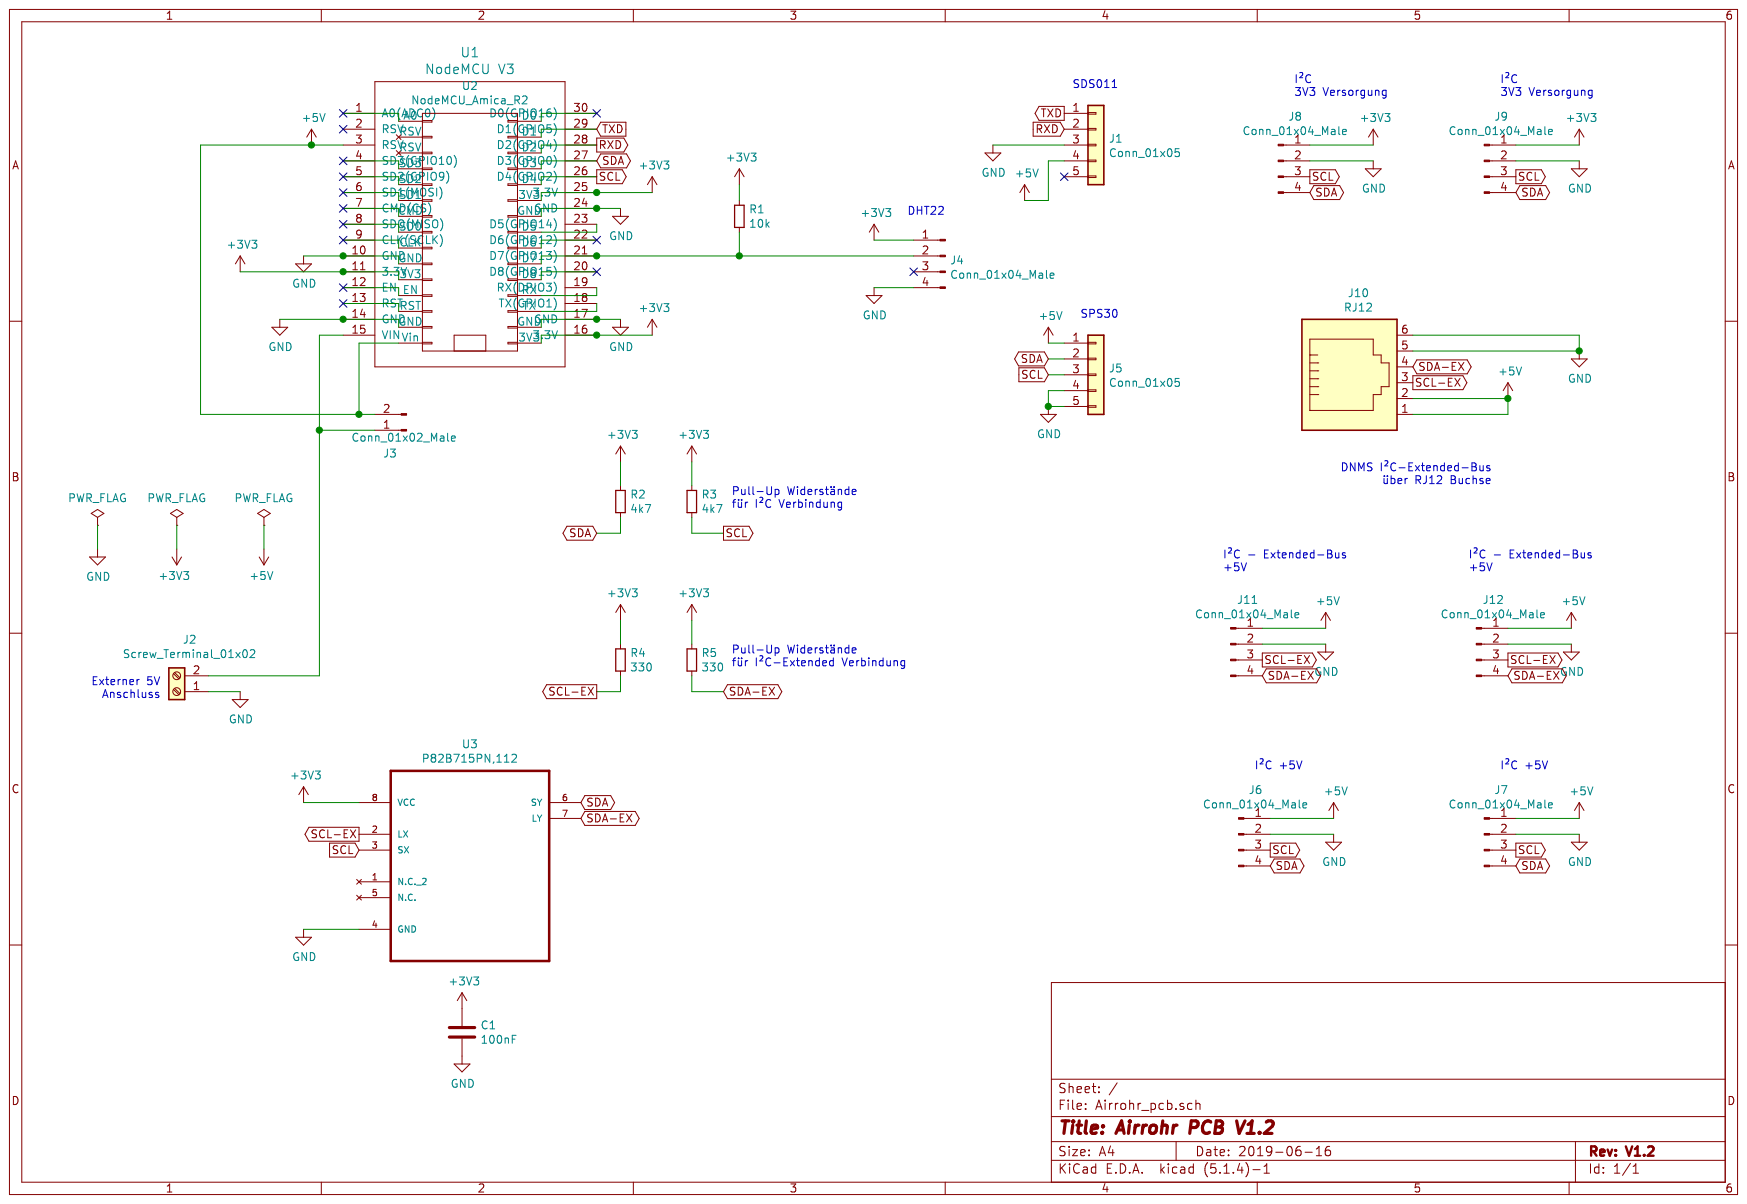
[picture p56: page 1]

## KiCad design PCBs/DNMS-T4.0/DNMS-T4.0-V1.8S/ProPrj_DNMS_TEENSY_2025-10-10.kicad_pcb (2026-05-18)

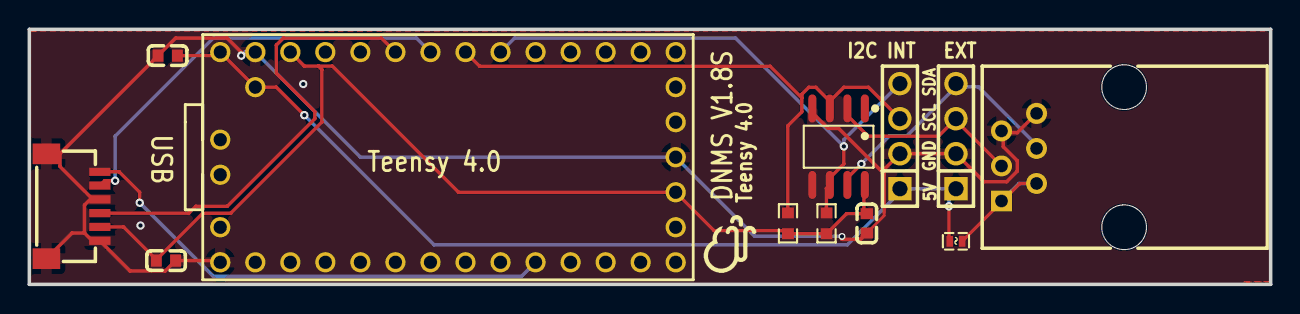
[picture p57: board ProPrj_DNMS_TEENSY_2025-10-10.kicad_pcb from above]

Board: 2 copper layers, 90.0 x 18.5 mm, 12 parts (0 on the bottom side), 11 nets.

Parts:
ET1: C0603
F1: F0402
HB1: C0603
HFT1: SOIC-8_L4.9-W3.9-P1.27-LS6.0-BL
J2, J3: HDR-TH_4P-P2.54-V-M
MIC1: CONN-SMD_SM06B-SRSS-TB-LF-SN
R1, R2: R0603
RB1: C0603
RJ1: RJ11-TH_R-RJ11R06P-A000
U1: TEENSY4.0

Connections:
$1N32: F1.2, RJ1.1, RJ1.2
+3.3V: ET1.2, HFT1.8, MIC1.5, R1.2, R2.2, RB1.2, U1.16, U1.31
+5V: F1.1, HB1.2, J2.1, J3.1, U1.33, U1.34
GND: ET1.1, HB1.1, HFT1.4, J2.2, J3.2, MIC1.3, MIC1.6, MIC1.7, MIC1.8, RB1.1, RJ1.5, RJ1.6, U1.1, U1.17, U1.32
SCK: MIC1.4, U1.28
SCL: HFT1.3, J2.3, R2.1, U1.26
SCL_EX: HFT1.2, J3.3, RJ1.3
SD: MIC1.1, U1.10
SDA: HFT1.6, J2.4, R1.1, U1.25
SDA_EX: HFT1.7, J3.4, RJ1.4
WS: MIC1.2, U1.27

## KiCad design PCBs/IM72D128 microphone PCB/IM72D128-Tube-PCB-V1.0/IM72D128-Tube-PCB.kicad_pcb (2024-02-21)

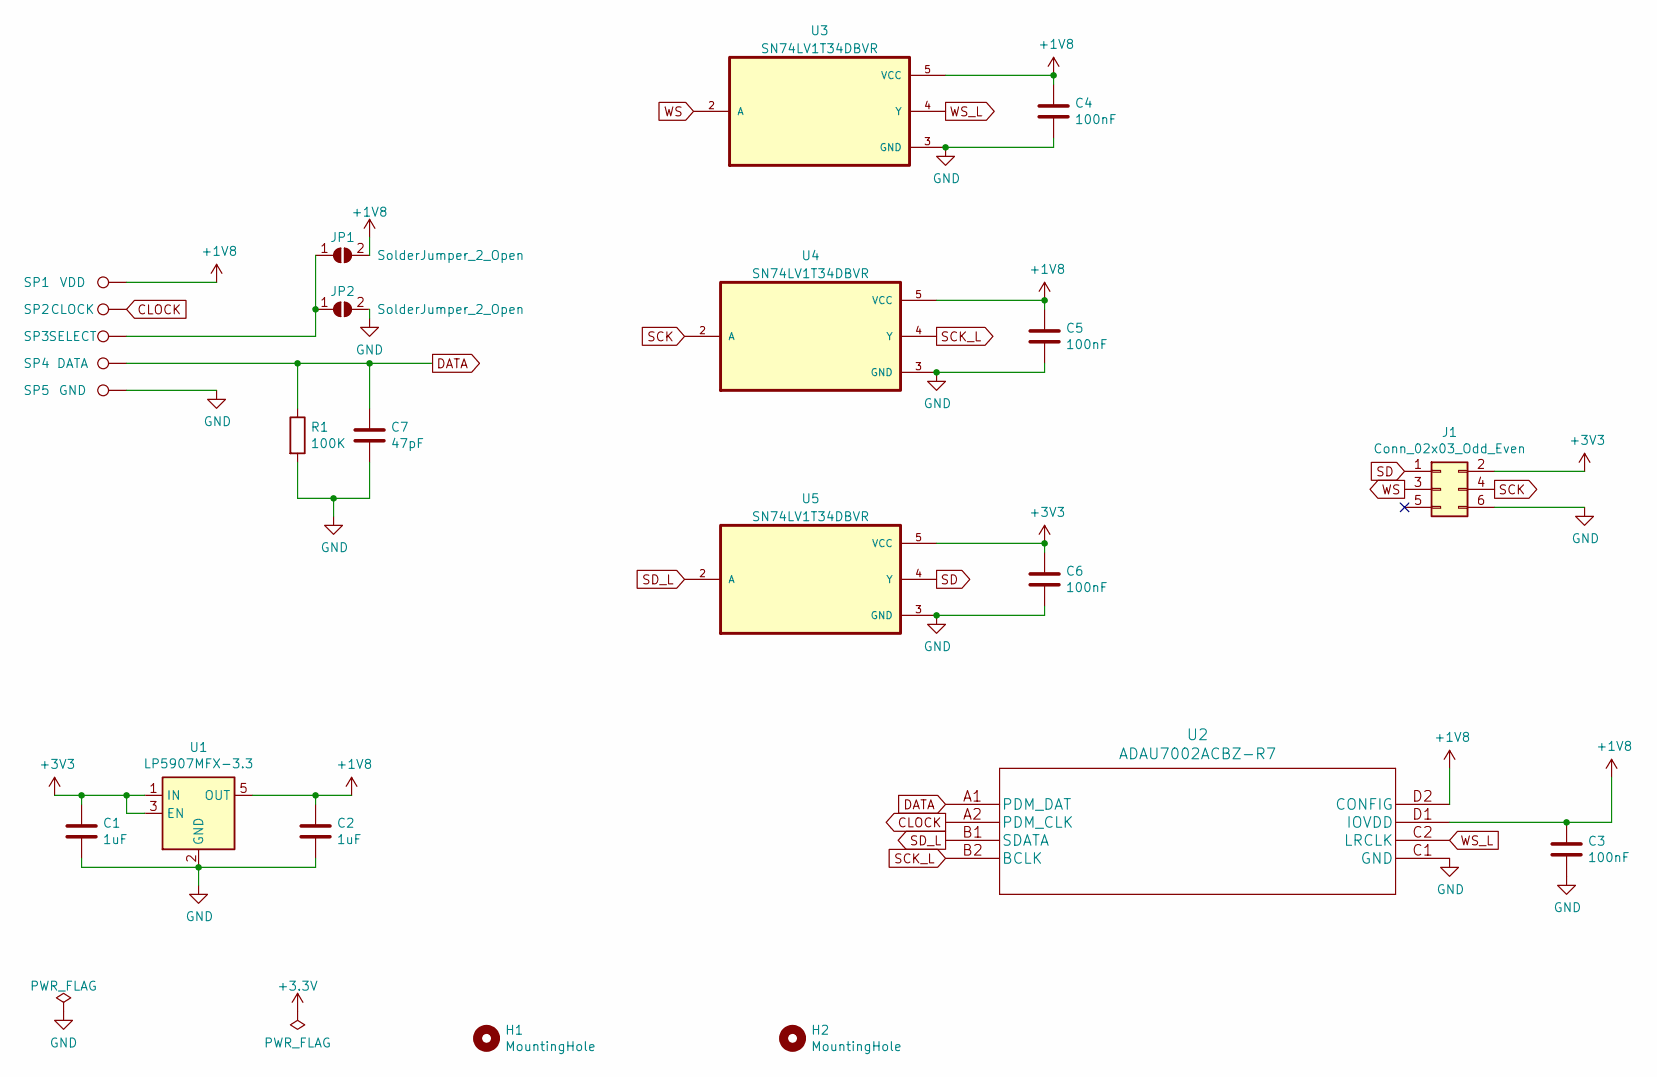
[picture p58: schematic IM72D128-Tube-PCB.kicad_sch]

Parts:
C1, C2: 1uF; C_0603_1608Metric
C3, C4, C5, C6: 100nF; C_0603_1608Metric
C7: 47pF; C_0603_1608Metric
H1, H2: MountingHole; MountingHole_2.1mm
J1: Conn_02x03_Odd_Even; PinHeader_2x03_P2.54mm_Vertical
JP1, JP2: SolderJumper_2_Open; SolderJumper-2_P1.3mm_Open_TrianglePad1.0x1.5mm
R1: 100K; R_0603_1608Metric
SP1: VDD; Solder_Pad_1.0x2.0mm
SP2: CLOCK; Solder_Pad_1.0x2.0mm
SP3: SELECT; Solder_Pad_1.0x2.0mm
SP4: DATA; Solder_Pad_1.0x2.0mm
SP5: GND; Solder_Pad_1.0x2.0mm
U1: LP5907MFX-3.3; SOT-23-5
U2: ADAU7002ACBZ-R7; ADAU7002
U3, U4, U5: SN74LV1T34DBVR; SOT95P280X145-5N

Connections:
+1V8: C2.1, C3.1, C4.1, C5.1, JP1.2 (B), SP1.1, U1.5 (OUT), U2.D1 (IOVDD), U2.D2 (CONFIG), U3.5 (VCC), U4.5 (VCC)
+3V3: C1.1, C6.1, J1.2, U1.1 (IN), U1.3 (EN), U5.5 (VCC)
CLOCK: SP2.1, U2.A2 (PDM_CLK)
DATA: C7.1, R1.1, SP4.1, U2.A1 (PDM_DAT)
GND: C1.2, C2.2, C3.2, C4.2, C5.2, C6.2, C7.2, J1.6, JP2.2 (B), R1.2, SP5.1, U1.2 (GND), U2.C1 (GND), U3.3 (GND), U4.3 (GND), U5.3 (GND)
unnamed: JP1.1 (A), JP2.1 (A), SP3.1
SCK: J1.4, U4.2 (A)
SCK_L: U2.B2 (BCLK), U4.4 (Y)
SD: J1.1, U5.4 (Y)
SD_L: U2.B1 (SDATA), U5.2 (A)
WS: J1.3, U3.2 (A)
WS_L: U2.C2 (LRCLK), U3.4 (Y)

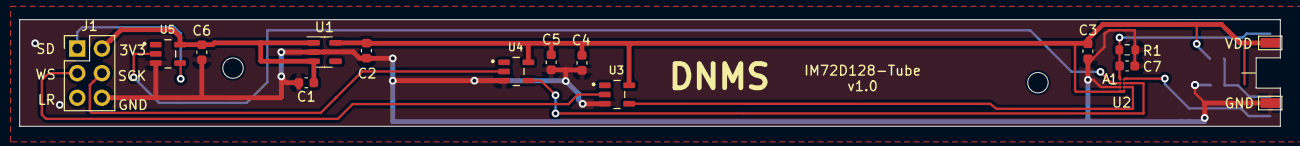
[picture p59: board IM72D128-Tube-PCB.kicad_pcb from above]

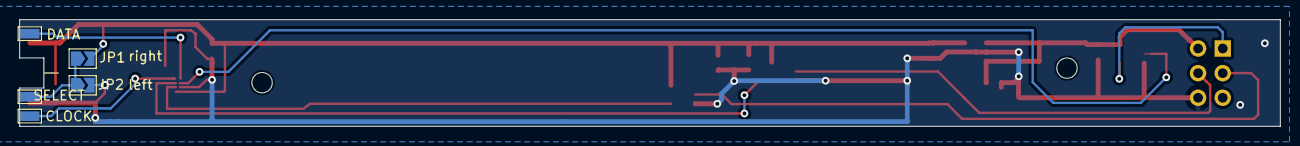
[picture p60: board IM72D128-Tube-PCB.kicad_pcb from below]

Board: 2 copper layers, 130.0 x 11.0 mm, 23 parts (5 on the bottom side), 12 nets.

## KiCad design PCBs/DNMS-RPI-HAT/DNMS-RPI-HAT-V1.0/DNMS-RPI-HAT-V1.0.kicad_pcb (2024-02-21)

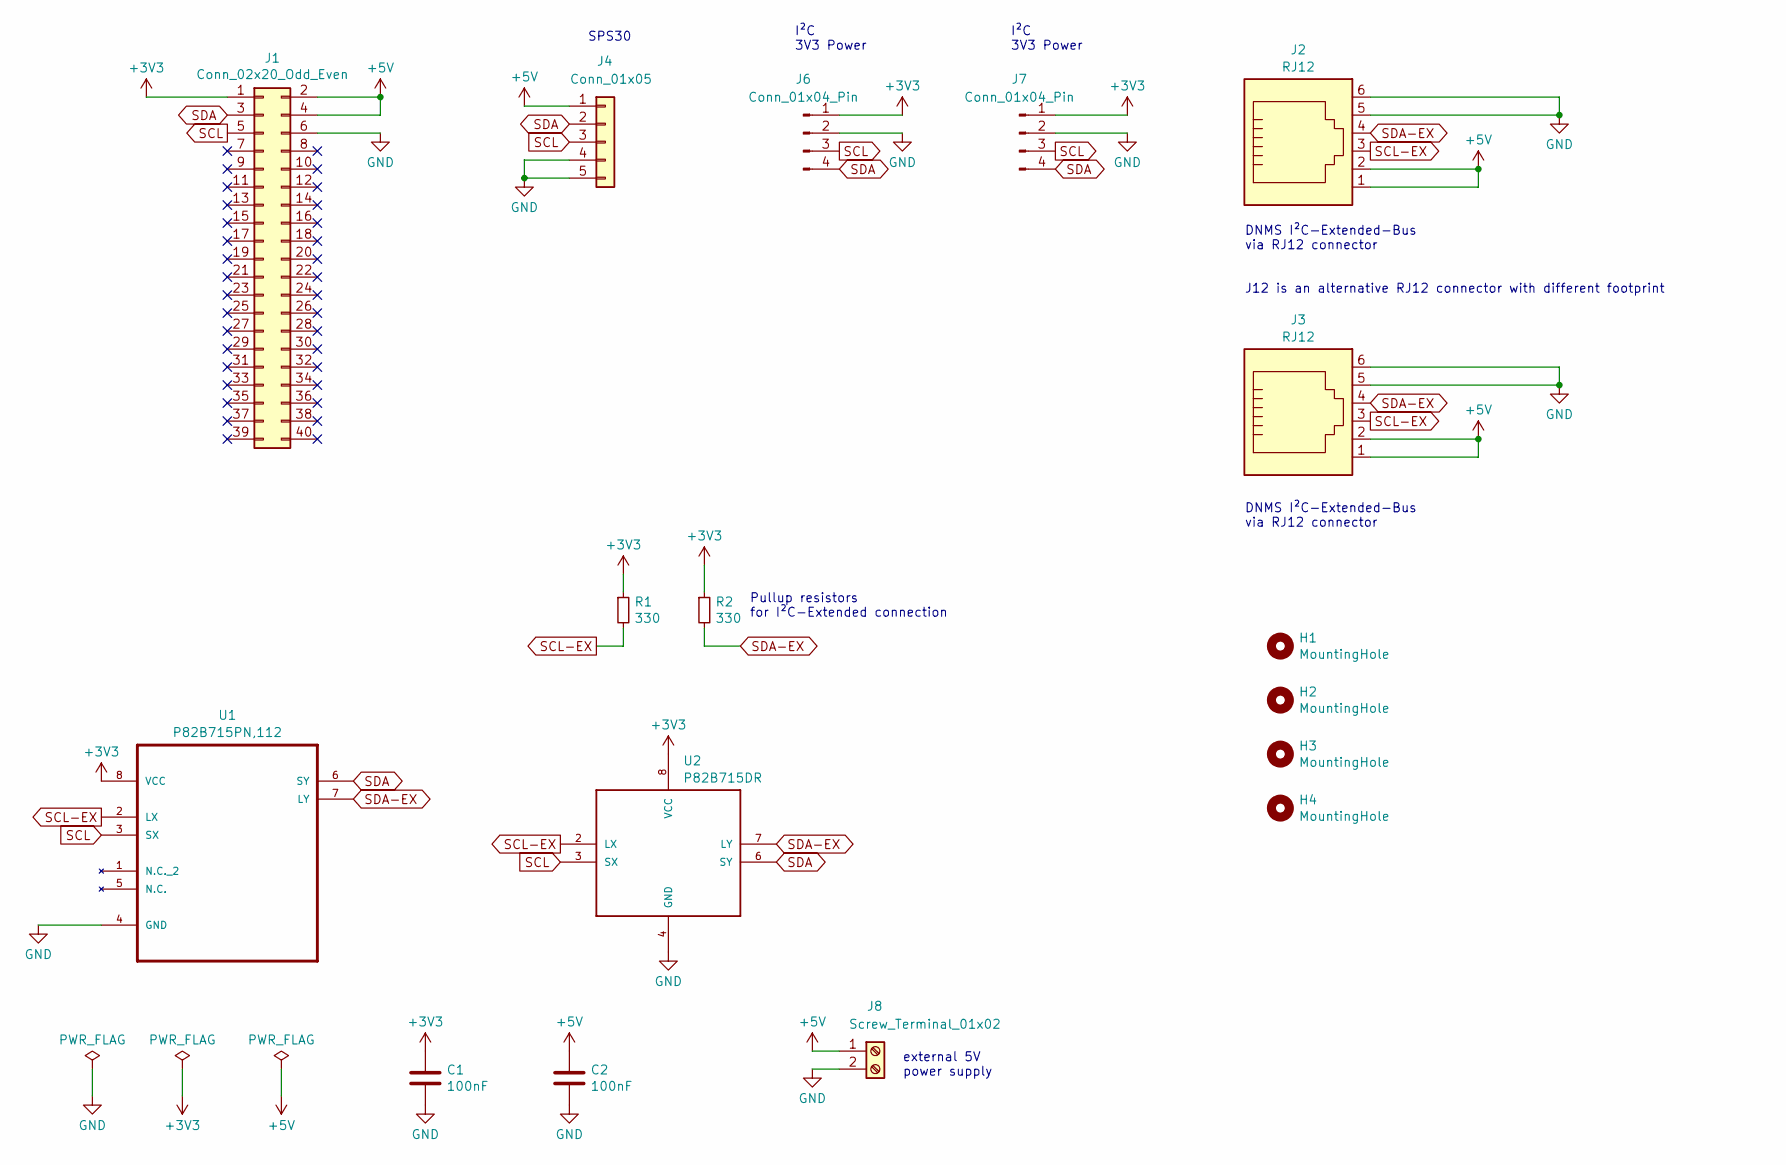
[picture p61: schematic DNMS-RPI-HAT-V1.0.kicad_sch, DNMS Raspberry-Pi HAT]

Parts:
C1, C2: 100nF; C_THT_100nF_L9.0mm_W2.0mm_P5.00mm_P7.50mm
H1, H2, H3, H4: MountingHole; MountingHole_2.7mm_M2.5_uHAT_RPi
J1: Conn_02x20_Odd_Even; PinSocket_2x20_P2.54mm_Vertical_Centered_Anchor
J2: RJ12; 54601906WPLF
J3: RJ12; E5566Q0LK22L
J4: Conn_01x05; JST_ZH_S5B-EH_1x05_P1.50mm_Horizontal
J6, J7: Conn_01x04_Pin; PinHeader_1x04_P2.54mm_Vertical
J8: Screw_Terminal_01x02; TerminalBlock_1x02_P2,54mm_P5.08mm_Horizontal
R1, R2: 330; R_Axial_DIN0207_L6.3mm_D2.5mm_P10.16mm_Horizontal
U1: P82B715PN,112; P82B715 DIP8
U2: P82B715DR; SOIC8

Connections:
+3V3: C1.1, J1.1, J6.1, J7.1, R1.1, R2.1, U1.8 (VCC), U2.8 (VCC)
+5V: C2.1, J1.2, J1.4, J2.1, J2.2, J3.1, J3.2, J4.1, J8.1
GND: C1.2, C2.2, J1.6, J2.5, J2.6, J3.5, J3.6, J4.4, J4.5, J6.2, J7.2, J8.2, U1.4 (GND), U2.4 (GND)
SCL: J1.5, J4.3, J6.3, J7.3, U1.3 (SX), U2.3 (SX)
SCL-EX: J2.3, J3.3, R1.2, U1.2 (LX), U2.2 (LX)
SDA: J1.3, J4.2, J6.4, J7.4, U1.6 (SY), U2.6 (SY)
SDA-EX: J2.4, J3.4, R2.2, U1.7 (LY), U2.7 (LY)

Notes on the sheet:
I²C 3V3 Power
DNMS I²C-Extended-Bus via RJ12 connector J12 is an alternative RJ12 connector with different footprint
DNMS I²C-Extended-Bus via RJ12 connector
external 5V power supply
Pullup resistors for I²C-Extended connection
SPS30

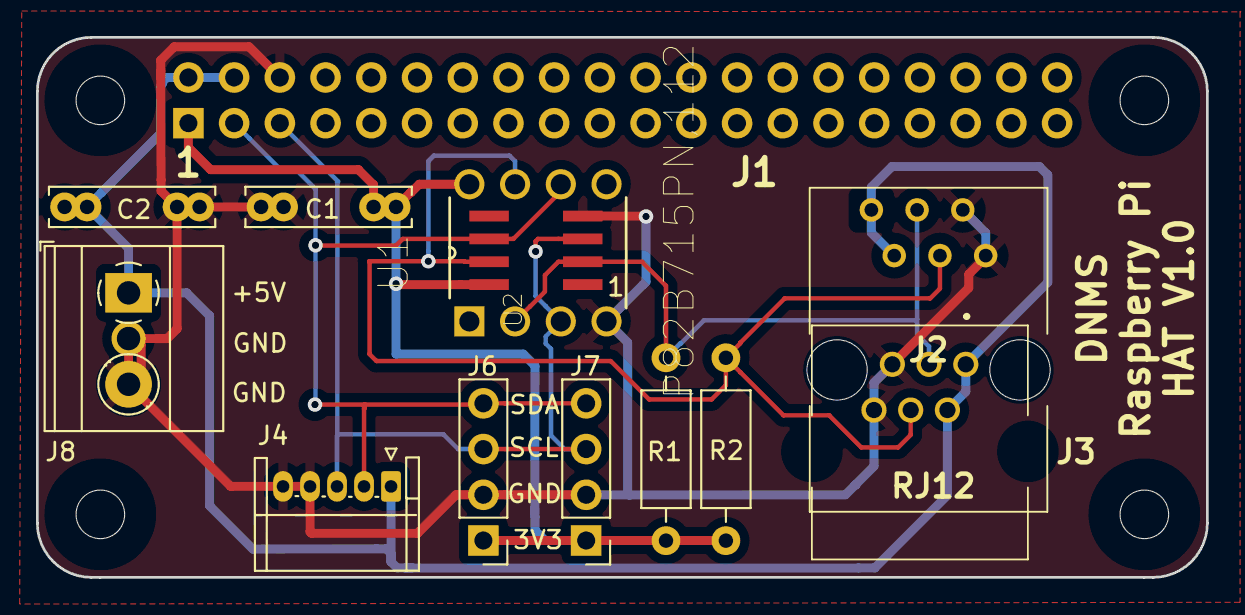
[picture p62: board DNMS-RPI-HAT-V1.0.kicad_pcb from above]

Board: 2 copper layers, 65.0 x 30.0 mm, 17 parts (1 on the bottom side), 7 nets.

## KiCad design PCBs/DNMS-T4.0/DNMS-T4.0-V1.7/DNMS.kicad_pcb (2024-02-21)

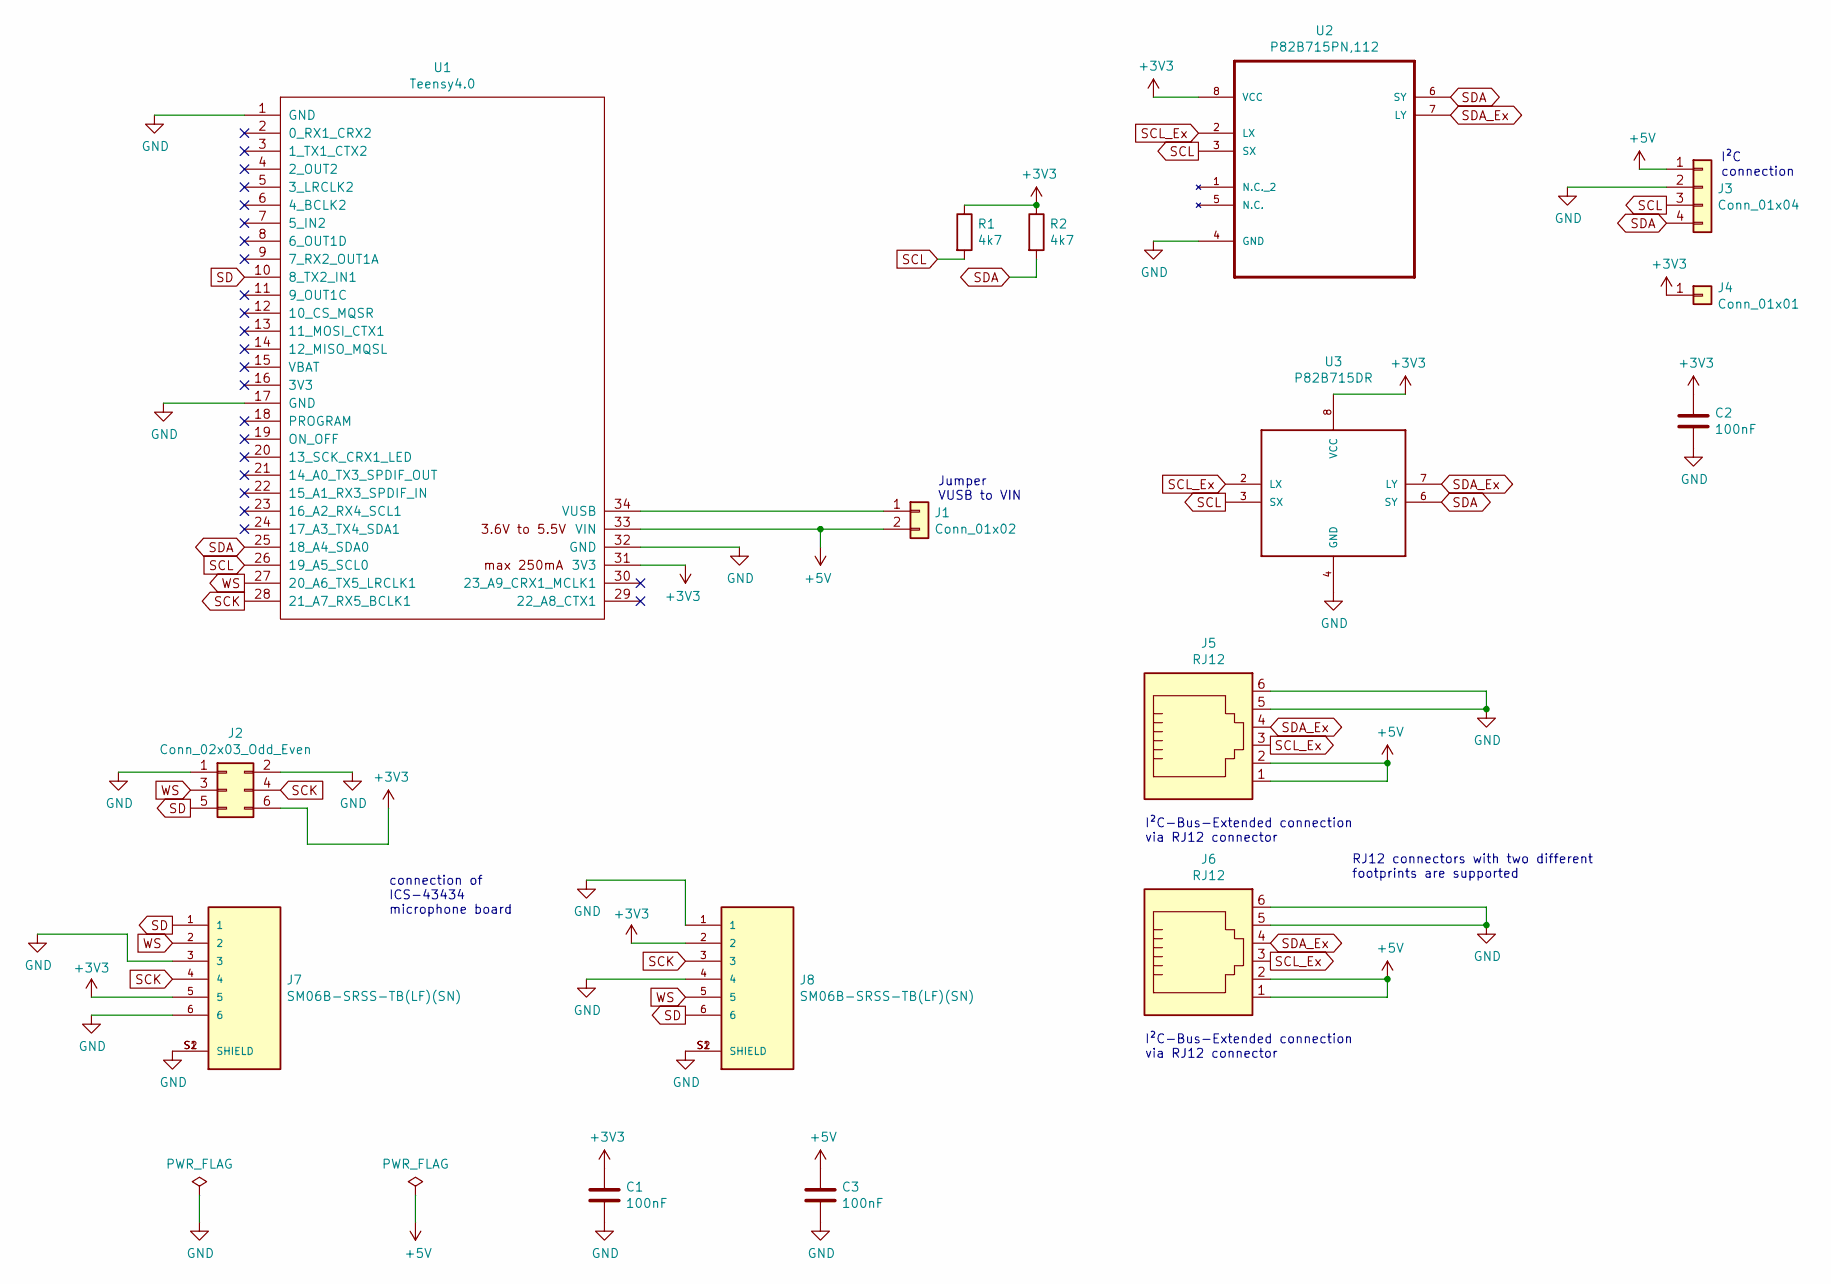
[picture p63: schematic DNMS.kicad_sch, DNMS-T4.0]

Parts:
C1, C2, C3: 100nF; C_THT_100nF_L9.0mm_W2.0mm_P5.00mm_P7.50mm
J1: Conn_01x02; PinHeader_1x02_P2.54mm_Vertical
J2: Conn_02x03_Odd_Even; PinHeader_2x03_P2.54mm_Vertical
J3: Conn_01x04; PinHeader_1x04_P2.54mm_Vertical
J4: Conn_01x01; PinHeader_1x01_P2.54mm_Vertical
J5: RJ12; 54601906WPLF
J6: RJ12; E5566Q0LK22L
J7, J8: SM06B-SRSS-TB(LF)(SN); JST_SM06B-SRSS-TB(LF)(SN)
R1, R2: 4k7; R_Axial_DIN0207_L6.3mm_D2.5mm_P10.16mm_Horizontal
U1: Teensy4.0; Teensy40
U2: P82B715PN,112; DIP254P762X420-8
U3: P82B715DR; SOIC8

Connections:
+3V3: C1.1, C2.1, J2.6, J4.1, J7.5, J8.2, R1.1, R2.1, U1.31 (3V3), U2.8 (VCC), U3.8 (VCC)
+5V: C3.1, J1.2, J3.1, J5.1, J5.2, J6.1, J6.2, U1.33 (VIN)
GND: C1.2, C2.2, C3.2, J2.1, J2.2, J3.2, J5.5, J5.6, J6.5, J6.6, J7.3, J7.6, J7.S1 (SHIELD), J7.S2 (SHIELD), J8.1, J8.4, J8.S1 (SHIELD), J8.S2 (SHIELD), U1.1 (GND), U1.17 (GND), U1.32 (GND), U2.4 (GND), U3.4 (GND)
unnamed: J1.1, U1.34 (VUSB)
SCK: J2.4, J7.4, J8.3, U1.28 (21_A7_RX5_BCLK1)
SCL: J3.3, R1.2, U1.26 (19_A5_SCL0), U2.3 (SX), U3.3 (SX)
SCL_Ex: J5.3, J6.3, U2.2 (LX), U3.2 (LX)
SD: J2.5, J7.1, J8.6, U1.10 (8_TX2_IN1)
SDA: J3.4, R2.2, U1.25 (18_A4_SDA0), U2.6 (SY), U3.6 (SY)
SDA_Ex: J5.4, J6.4, U2.7 (LY), U3.7 (LY)
WS: J2.3, J7.2, J8.5, U1.27 (20_A6_TX5_LRCLK1)

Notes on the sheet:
I²C-Bus-Extended connection via RJ12 connector
RJ12 connectors with two different footprints are supported
Jumper VUSB to VIN
connection of ICS-43434 microphone board
I²C connection

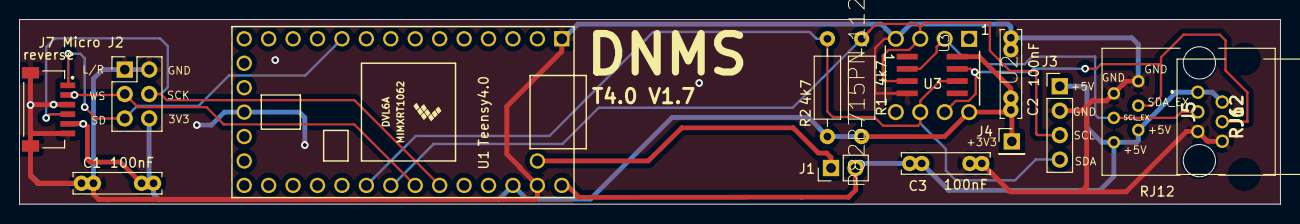
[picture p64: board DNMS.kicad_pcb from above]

Board: 2 copper layers, 131.1 x 19.2 mm, 16 parts (1 on the bottom side), 11 nets.

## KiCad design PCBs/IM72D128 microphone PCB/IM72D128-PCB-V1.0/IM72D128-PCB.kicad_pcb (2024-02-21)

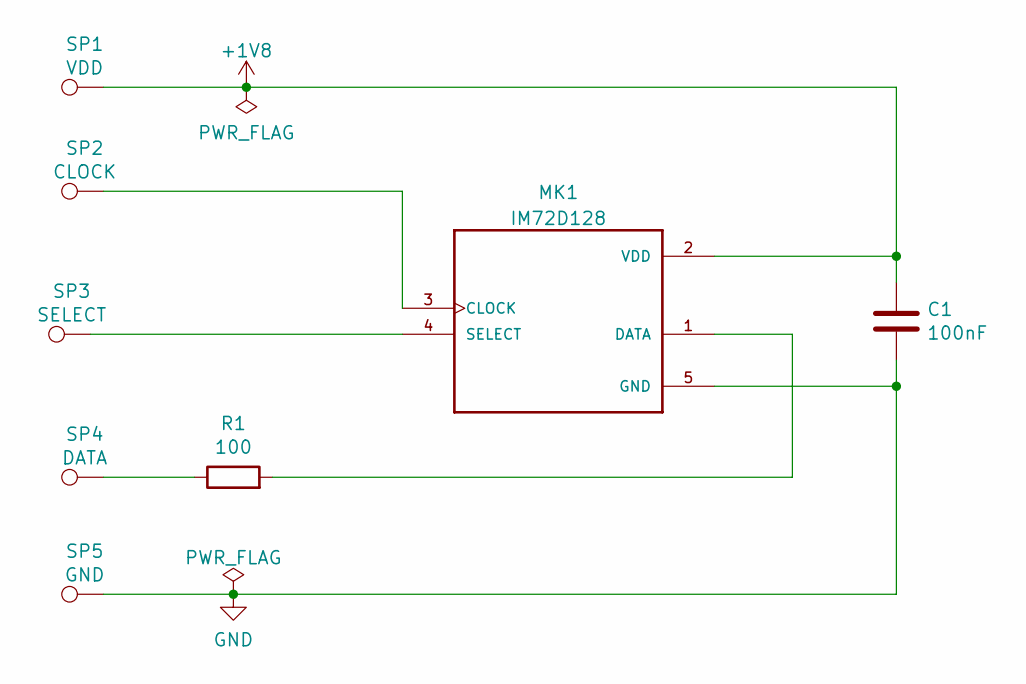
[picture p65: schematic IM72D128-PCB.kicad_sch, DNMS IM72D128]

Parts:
C1: 100nF; C_0603_1608Metric
MK1: IM72D128; MIC_IM72D128
R1: 100; R_0603_1608Metric
SP1: VDD; Solder_Pad_1.0x1.0mm
SP2: CLOCK; Solder_Pad_1.0x1.0mm
SP3: SELECT; Solder_Pad_1.0x1.0mm
SP4: DATA; Solder_Pad_1.0x1.0mm
SP5: GND; Solder_Pad_1.0x1.0mm

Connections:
+1V8: C1.1, MK1.2 (VDD), SP1.1
GND: C1.2, MK1.5 (GND), SP5.1
unnamed: MK1.3 (CLOCK), SP2.1
unnamed: MK1.1 (DATA), R1.2
unnamed: MK1.4 (SELECT), SP3.1
unnamed: R1.1, SP4.1

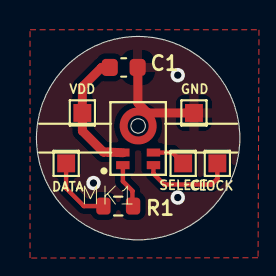
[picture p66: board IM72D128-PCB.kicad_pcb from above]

Board: 2 copper layers, 11.3 x 11.3 mm, 8 parts (0 on the bottom side), 6 nets.

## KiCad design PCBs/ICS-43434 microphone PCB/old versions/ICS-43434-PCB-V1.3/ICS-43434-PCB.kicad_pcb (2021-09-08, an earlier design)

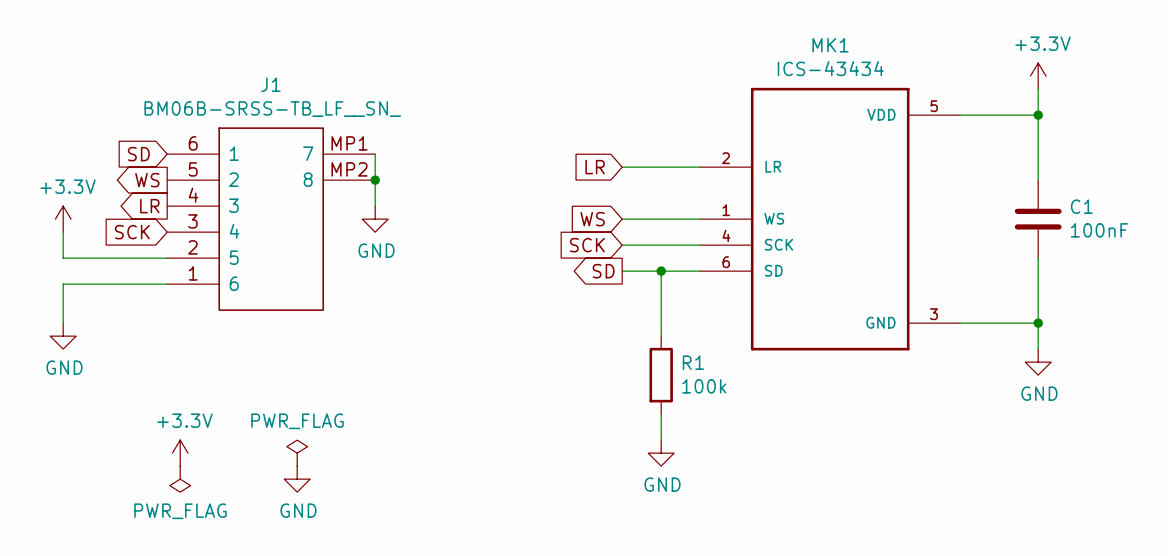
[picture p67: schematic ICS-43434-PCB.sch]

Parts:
C1: 100nF; C_0603_1608Metric
J1: BM06B-SRSS-TB_LF__SN_; BM06BSRSSTBLFSN; Manufacturer_Part_Number BM06B-SRSS-TB(LF)(SN)
MK1: ICS-43434; MIC_ICS-43434
R1: 100k; R_0603_1608Metric

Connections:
+3V3: C1.1, J1.2 (5), MK1.5 (VDD)
GND: C1.2, J1.1 (6), J1.MP1 (7), J1.MP2 (8), MK1.3 (GND), R1.2
LR: J1.4 (3), MK1.2 (LR)
SCK: J1.3 (4), MK1.4 (SCK)
SD: J1.6 (1), MK1.6 (SD), R1.1
WS: J1.5 (2), MK1.1 (WS)

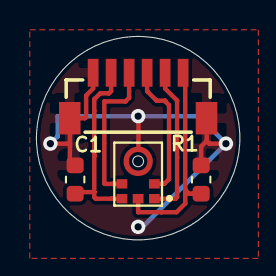
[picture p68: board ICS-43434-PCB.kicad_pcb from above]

Board: 2 copper layers, 11.3 x 11.3 mm, 4 parts (0 on the bottom side), 6 nets.

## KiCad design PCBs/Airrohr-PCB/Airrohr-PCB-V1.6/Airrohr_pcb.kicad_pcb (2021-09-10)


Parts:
C1: 100nF; C_THT_100nF_L9.0mm_W2.0mm_P5.00mm_P7.50mm
J1: Conn_01x05; JST_XH_S5B-XH-A-1_1x05_P2.50mm_Horizontal
J2: Screw_Terminal_01x02; TerminalBlock_1x02_P2,54mm_P5.08mm_Horizontal
J3: Conn_01x02_Male; PinHeader_1x02_P2.54mm_Vertical
J4, J6, J7, J8, J9, J10: Conn_01x04_Male; PinHeader_1x04_P2.54mm_Vertical
J5: Conn_01x05; JST_ZH_S5B-EH_1x05_P1.50mm_Horizontal
J11: RJ12; 54601906WPLF
J12: RJ12; E5566Q0LK22L
R1: 10k; R_Axial_DIN0207_L6.3mm_D2.5mm_P10.16mm_Horizontal
R2, R3: 4k7; R_Axial_DIN0207_L6.3mm_D2.5mm_P10.16mm_Horizontal
R4, R5: 330; R_Axial_DIN0207_L6.3mm_D2.5mm_P10.16mm_Horizontal
U1: NodeMCU V3; NodeMCU-LoLinV3
U2: NodeMCU_Amica_R2
U3: P82B715PN,112; DIP254P762X420-8
U4: P82B715DR; SOIC8

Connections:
+3V3: C1.1, J4.1, J8.1, J9.1, R1.1, R2.1, R3.1, R4.1, R5.1, U1.11 (3.3V), U1.16 (3.3V), U1.25 (3.3V), U2.11 (3V3), U2.16 (3V3), U2.25 (3V3), U3.8 (VCC), U4.8 (VCC)
+5V: J1.4, J3.2, J5.1, J6.1, J7.1, J10.1, J11.1, J11.2, J12.1, J12.2, U1.3 (RSV), U2.15 (Vin)
GND: C1.2, J1.3, J2.1, J4.4, J5.4, J5.5, J6.2, J7.2, J8.2, J9.2, J10.2, J11.5, J11.6, J12.5, J12.6, U1.10 (GND), U1.14 (GND), U1.17 (GND), U1.24 (GND), U2.10 (GND), U2.14 (GND), U2.17 (GND), U2.24 (GND), U3.4 (GND), U4.4 (GND)
unnamed: J2.2, J3.1, U1.15 (VIN)
unnamed: J4.2, R1.2, U1.21 (D7(GPIO13)), U2.21 (D7)
unnamed: U1.1 (A0(ADC0)), U2.1 (A0)
unnamed: U1.4 (SD3(GPIO10)), U2.4 (SD3)
unnamed: U1.5 (SD2(GPIO9)), U2.5 (SD2)
unnamed: U1.6 (SD1(MOSI)), U2.6 (SD1)
unnamed: U1.7 (CMD(CS)), U2.7 (CMD)
unnamed: U1.8 (SDO(MISO)), U2.8 (SD0)
unnamed: U1.9 (CLK(SCLK)), U2.9 (CLK)
unnamed: U1.12 (EN), U2.12 (EN)
unnamed: U1.13 (RST), U2.13 (RST)
unnamed: U1.18 (TX(GPIO1)), U2.18 (TX)
unnamed: U1.19 (RX(DPIO3)), U2.19 (RX)
unnamed: U1.20 (D8(GPIO15)), U2.20 (D8)
unnamed: U1.22 (D6(GPIO12)), U2.22 (D6)
unnamed: U1.23 (D5(GPIO14)), U2.23 (D5)
unnamed: U1.30 (D0(GPIO16)), U2.30 (D0)
RXD: J1.2, U1.28 (D2(GPIO4)), U2.28 (D2)
SCL: J5.3, J6.3, J7.3, J8.3, J9.3, R3.2, U1.26 (D4(GPIO2)), U2.26 (D4), U3.3 (SX), U4.3 (SX)
SCL-EX: J10.3, J11.3, J12.3, R4.2, U3.2 (LX), U4.2 (LX)
SDA: J5.2, J6.4, J7.4, J8.4, J9.4, R2.2, U1.27 (D3(GPIO0)), U2.27 (D3), U3.6 (SY), U4.6 (SY)
SDA-EX: J10.4, J11.4, J12.4, R5.2, U3.7 (LY), U4.7 (LY)
TXD: J1.1, U1.29 (D1(GPIO5)), U2.29 (D1)

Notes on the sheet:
Externer 5V Anschluss
DHT22
Pullup resistors for I²C connection
Pullup resistors for I²C-Extended connection
SPS30
I²C 3V3 power
I²C +5V
SDS011
DNMS I²C-Extended-Bus via RJ12 connector J12 is an alternative RJ12 connector with different footprint
I²C - Extended-Bus +5V
DNMS I²C-Extended-Bus via RJ12 connector


Board: 2 copper layers, 68.6 x 71.1 mm, 22 parts (0 on the bottom side), 26 nets.

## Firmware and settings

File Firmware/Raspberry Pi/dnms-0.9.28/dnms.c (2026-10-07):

/*
 *  raspi-dnms
 *  
 *  Raspi program for noise measurement with a connected DNMS sensor
 *  It works from Zero W up to Raspi 4
 * 
 *  Program sends measurement to Sensor.Community and/or to an influxDB.
 *  Besides the fixed measurement interval of Sensor.Community (150 s) a 2nd measurement interval 
 *  for the influxDB is supported. The interval time of the 2nd measurement interval can be freely configured (1 - 3600 s).
 *  Transmission of data can be configured as http or https transmission.
 *                                                                      
 *  Copyright (C) 2022, 2023, 2024, 2025  Helmut Bitter
 *                                                                      
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
 */

// if defined, than you can switch a gpio pin if a certain noise level is exceeded. The pigpio lib is includes and you have to start dnms with sudo (that depends on the pigpio lib)
// if you don't want to switch a gpio pin comment the define  gpio_switch out
#define gpio_switch false

#include <stdio.h>
#include <stdlib.h>
#include <stdint.h>
#include <stdbool.h>
#include <math.h>
#include <sys/time.h>
#include <openssl/err.h>
#include <openssl/ssl.h>
#include <openssl/bio.h>
#include <sys/socket.h>
#include <string.h>
#include <pthread.h>
#include <sys/socket.h>
#include <sys/ioctl.h>
#include <net/if.h>
#include <unistd.h>
#include <libconfig.h>
#include <mosquitto.h>
#include <sys/types.h>
#include <sys/stat.h>
#include <iwlib.h>
#include <sys/ioctl.h>
#include <net/if.h>
#include <linux/wireless.h>
#include <fcntl.h>
#include <arpa/inet.h>

#include "./dnms_rpi_i2c.h"
#include "./dnms_calib_data.h"
#include "./b64_encode.h"
#include "./data_logging.h"
#include "./webserver.h"
#include "./sensors_rpi.h"


#ifdef gpio_switch
#include <pigpio.h>
#endif


const char firmware_version[] = { "raspi-dnms-0.9.28" };  // Firmware Version for Raspberry Pi

config_t cfg;
config_setting_t *setting;


/* *************************************   start configuration values   ********************************************** */
// waiting time after program start - this depends on the raspi type, Pi Zero W should be 20 seconds, for Pi Zero 2W 10 seconds
int waiting_time_after_start;
// Priorities for threads
int prio_1st_timer;
int prio_1st_measurement;
int prio_2nd_timer;
int prio_2nd_measurement;
int prio_wlan;
int prio_print_ipc_and_log_1st;
int prio_print_ipc_and_log_2nd;
int prio_start_stop;

const char *dev_name_dnms;   // name of I²C device on Raspi
const char *interface_name;    // name of wlan or lan interface for transmission of data to Sensor.Community and/or other APIs
int enable_wlan_or_lan;             // enabble wlan or lan for transmission to Sensor.Community and/or InfluxDB
int enable_wifi_signal_strength_influxdb; // include WiFi RSSI in InfluxDB payload
int enable_wifi_signal_strength_mqtt;     // include WiFi RSSI in MQTT payload
int last_influxdb_transmission_time_to_payload; // include last InfluxDB tx duration (ms) in payload
int last_mqtt_transmission_time_to_payload;     // include last MQTT tx duration (ms) in payload
int long_id;								  // long or short ID


/* ********* Configuration of connected microphone  -- ICS-43434  or IM72D128  *********  */
int dnms_microphone;  // which microphone is connected?

/* ********* LED blink period (ms) per microphone type — transmitted to Teensy at startup *********  */
int dnms_blink_period_1 =  100;   /* ICS-43434 */
int dnms_blink_period_2 =  500;   /* IM72D128 */
int dnms_blink_period_3 =  500;   /* IM72D128 with DLR case */
int dnms_blink_period_4 =  100;   /* ICS-43434 no correction */
int dnms_blink_period_5 =  500;   /* IM72D128 no correction */
int dnms_blink_period_6 =  200;   /* micro_3 */
int dnms_blink_period_7 = 1000;   /* micro_4 */

/* ********* Microphone sensitivity constant (dB) per microphone type — transmitted to Teensy at startup *********  */
double dnms_micro_const_1 = 123.0102999565;   /* ICS-43434 */
double dnms_micro_const_2 = 133.0102999565;   /* IM72D128 */
double dnms_micro_const_3 = 133.0102999565;   /* IM72D128 with DLR case */
double dnms_micro_const_4 = 123.0102999565;   /* ICS-43434 no correction */
double dnms_micro_const_5 = 133.0102999565;   /* IM72D128 no correction */
double dnms_micro_const_6 =   0.0;            /* micro_3 — fill in actual value */
double dnms_micro_const_7 =   0.0;            /* micro_4 — fill in actual value */

/* ********* Correction value in dB for microphone for time domain dB(A) an dB(Z) values  -- for ICS-43434  or IM72D128  *********  */
double dnms_correction;

/* ********* Configuration of intervals for 1st and 2nd measurements ********* */
int enable_1st_interval;                   // enable or disable 1st measurement
int measurement_1st_interval_ms;           // 1st measurement interval, in ms
int enable_2nd_interval;                   // enable or disable 2nd measurement
int measurement_2nd_interval_ms;           // 2nd measurement interval, in ms
int threshold_2nd_interval_laeq_transmit;  // threshold for transmission of 2nd interval measurements to influxdb, transmission to influxdb is started if LAeq is equal or higher than threshold
int number_transmissions_after_exceeding;  // number of transmissions of 2nd interval measurement after exceeding threshold
int switch_output_pin;                     // switch output pin, if threshold of 2nd is exceeded, true or false
int gpio_output_pin;                       // pin that is switched on/off based on Broadcom GPIO numbering
int start_on_full_minute;                  // start measurements on the full minute (seconds = 00)
int start_on_full_hour;                    // start measurements on the full hour (minutes = 00 and seconds = 00)

/* *********  Configuration options what data is tranferred to InfluxDB/MQTT Broker *********  */
int data_transmit_laeq_1st_to_influxdb;           // 1st measurement interval LAeq data to influxDB, true or false
int data_transmit_lzeq_1st_to_influxdb;           // 1st measurement interval LZeq data to influxDB, true or false
int data_transmit_lceq_1st_to_influxdb;		 // 1st measurement interval LCeq data to influxDB, true or false
int data_transmit_laeq_1st_spectrum_to_influxdb;  // 1st measurement interval spectrum LAeq data to influxDB, true or false
int data_transmit_lzeq_1st_spectrum_to_influxdb;  //  1st measurement interval spectrum LZeq data to influxDB, true or false
int data_transmit_lceq_1st_spectrum_to_influxdb;  //  1st measurement interval spectrum LCeq data to influxDB, true or false
int data_transmit_laeq_2nd_to_influxdb;           // 2nd measurement interval LAeq data to influxDB, true or false
int data_transmit_lzeq_2nd_to_influxdb;           // 2nd measurement interval LZeq data to influxDB, true or false
int data_transmit_lceq_2nd_to_influxdb;           // 2nd measurement interval LCeq data to influxDB, true or false
int data_transmit_laeq_2nd_spectrum_to_influxdb;  // 2nd measurement interval LAeq spectrum data to influxDB, true or false
int data_transmit_lzeq_2nd_spectrum_to_influxdb;  // 2nd measurement interval LZeq spectrum data to influxDB, true or false
int data_transmit_lceq_2nd_spectrum_to_influxdb;  // 2nd measurement interval LCeq spectrum data to influxDB, true or false
int data_transmit_laeq_1st_to_mqtt              = 1;
int data_transmit_lzeq_1st_to_mqtt              = 1;
int data_transmit_lceq_1st_to_mqtt              = 0;
int data_transmit_laeq_1st_spectrum_to_mqtt     = 1;
int data_transmit_lzeq_1st_spectrum_to_mqtt     = 1;
int data_transmit_lceq_1st_spectrum_to_mqtt     = 0;
int data_transmit_laeq_2nd_to_mqtt              = 1;
int data_transmit_lzeq_2nd_to_mqtt              = 1;
int data_transmit_lceq_2nd_to_mqtt              = 0;
int data_transmit_laeq_2nd_spectrum_to_mqtt     = 1;
int data_transmit_lzeq_2nd_spectrum_to_mqtt     = 1;
int data_transmit_lceq_2nd_spectrum_to_mqtt     = 0;
int timestamp_to_influxdb;                        // send timestamp to InfluxDB, true or fase
int influxdb_transmit_http;                       // data transmission to influxDB as http, true or false (false means no http transmission)
int influxdb_transmit_https;                      // data transmission to InfluxDB as https, true or false (false means no https transmission)
const char *influxdb_server;                      // InfluxDB server address
const char *influxdb_port;                        // InfluxDB server port
const char *influxdb_pfad;                        // InfluxDB database path and name
const char *influxdb_user;                        // InfluxDB user name
const char *influxdb_passwort;                    // InfluxDB passwort for user
const char *influxdb_messung;                     // InfluxDB measurement name

/* *********  Configuration options for transmission to MQTT Broker  *********  */
int mqtt_transmit;             // data transmission to MQTT Broker, InfluxDB Line Protocol is used, true or false (false means no http transmission)
const char *mqtt_messung = "DNMS"; // MQTT measurement name (separate from InfluxDB measurement name)
const char *mqtt_user;         // MQTT user name
const char *mqtt_passwort;     // MQTT user passwort
const char *mqtt_broker;       // URL of MQRR Broker
int mqtt_port;                 // Port for MQTT Broker connection
int mqtt_keepalive;            // MQTT keepalive time
int mqtt_qos;                  // MQTT QoS
const char *mqtt_main_topic;   // MQTT Main Topic
int mqtt_use_tls      = 0;     // use TLS for MQTT connection
const char *mqtt_tls_cafile = NULL; // path to CA certificate file (or "" for system default)
int mqtt_tls_insecure = 0;     // skip hostname verification
int mqtt_use_id_as_sub_topic;  // use the Raspberry ID as MQTT Sub Topic


/* ********* Configuration options for transmission to Sensor.Community *********  */
int data_transmit_laeq_to_sc;      // transmission of LAeq 1st interval to Sensor.Community, true or false
const char *host_sc;               // Host Sensor.Community
const char *port_sc;               // Port Sensor.Community (legacy, no longer used)
const char *url_sc;                // URL to data store of Sensor.Community
const char *DNMS_API_PIN;          // API PIN für DNMS at Sensor.Community
int sc_transmit_https;             // use https (true) or http (false) for transmission to Sensor.Community
int data_transmit_laeq_to_madavi;  // transmission of LAeq 1st interval to Madavi

/* ********* Custom API — HTTP POST of JSON at each 1st-interval measurement ********* */
int  custom_api_enable        = 0;
char custom_api_server[128]   = "";
char custom_api_port[8]       = "80";
char custom_api_path[128]     = "/data";
char custom_api_hostname[140] = "";  /* server:port — built at send time */
int  custom_api_send_1st      = 1;
int  custom_api_send_2nd      = 0;
int  custom_api_spectrum_1st  = 1;
int  custom_api_spectrum_2nd  = 1;
int  custom_api_https         = 0;

/* ********* Configuration options for IPC - Inter Process Communication  using a named pipe ********* */
int data_transmit_via_pipe;
const char *name_of_pipe;


/*  ********* start/stop measurement from named pipe message  ********* */
const char *start_stop_name_of_pipe;  // name of named pipe for start/stop
int start_stop_extern;                // enable or disable external start/stop functionality (true =enable, false = disable)


/* ********* output of mesurement  values on terminal *********  */
int data_on_terminal;


/* ********* which mesurement values are outputed on terminal, named pipe or data logging *********  */
int data_laeq_1st_output_on_terminal;             // output of LAeq 1st interval measurements values on terminal, true or false
int data_la_spec_1st_output_on_terminal;          // output of LA spectrum 1st interval measurements values on terminal, true or false
int data_lzeq_1st_output_on_terminal;             // output of LZeq 1st interval measurements values on terminal, true or false
int data_lz_spec_1st_output_on_terminal;          // output of LZ spectrum 1st interval measurements values on terminal, true or false
int data_lceq_1st_output_on_terminal;             // output of LCeq 1st interval measurements values on terminal, true or false
int data_lc_spec_1st_output_on_terminal;          // output of LC spectrum 1st interval measurements values on terminal, true or false
int data_laeq_2nd_output_on_terminal;             // output of LAeq 2nd interval measurements values on terminal, true or false
int data_la_spec_2nd_output_on_terminal;          // output of LA spectrum 2nd interval measurements values on terminal, true or false
int data_lzeq_2nd_output_on_terminal;             // output of LZeq 2nd interval measurements values on terminal, true or false
int data_lz_spec_2nd_output_on_terminal;          // output of LZ spectrum 2nd interval measurements values on terminal, true or false
int data_lceq_2nd_output_on_terminal;             // output of LCeq 2nd interval measurements values on terminal, true or false
int data_lc_spec_2nd_output_on_terminal;          // output of LC spectrum 2nd interval measurements values on terminal, true or false

int last_influxdb_transmission_time_to_terminal;  // output to terminal of last transmission time to InfluxDB, true or false
int threshold_output_influxdb_ltt_to_terminal;    // threshold to output the last transmission time to InfluxDB to terminal if transmission time is higher than threshold, in ms
int last_mqtt_transmission_time_to_terminal;      // output to terminal of last transmission time to MQTT Broker, true or false
int threshold_output_mqtt_ltt_to_terminal;        // threshold to output the last transmission time to MQTT Broker to terminal if transmission time is higher than threshold, in ms
int last_sc_transmission_time_to_terminal;        // output to terminal of last transmission time to Sensor.Community, true or false
int threshold_output_sc_ltt_to_terminal;          // threshold to output last transmission time to influxdb to terminal if transmission time is higher than threshold, in ms
int output_thread_info;                           // output of thread information at program start


/* ********* data logging functionality ********* */
int data_logging;                    // enable/diasable data logging functionality
const char *data_logging_directory;  // directory for data logging (full path)

/* ********* environment sensors ********* */
int         enable_sds011      = 0;
const char *sds011_uart_port   = "/dev/ttyUSB0";
int         enable_sps30       = 0;
int         enable_sht3x       = 0;
int         sht3x_i2c_addr     = 0x44;     /* 0x44 (default) or 0x45 */
int         enable_sen5x       = 0;
int         enable_bme280      = 0;
int         bme280_i2c_addr    = 0x76;     /* 0x76 (default) or 0x77 */
double      temp_correction_sht3x  = 0.0;  /* °C offset added to SHT3x temperature */
double      temp_correction_sen5x  = 0.0;  /* °C offset added to SEN5x temperature */
double      temp_correction_bme280 = 0.0;  /* °C offset added to BME280 temperature */
int         enable_scd30       = 0;
double      temp_correction_scd30 = 0.0;
int         enable_scd4x       = 0;
double      temp_correction_scd4x = 0.0;

/* ********* webserver ********* */
int enable_webserver = 1;   // enable/disable the embedded webserver
int webserver_port   = 8080; // TCP port the webserver listens on

/* ********* measurement counters (reset at midnight) ********* */
uint32_t counter_measurements_1st = 0;
uint32_t counter_measurements_2nd = 0;

uint32_t dnms_error_count      = 0;
uint32_t influxdb_error_count  = 0;
uint32_t sc_error_count        = 0;
uint32_t madavi_error_count    = 0;
uint32_t mqtt_error_count      = 0;
uint32_t buffer_overflow_count = 0;
time_t measurement_start_time = 0;
time_t process_start_time = 0;
struct timespec process_start_mono = {0, 0};
struct timespec measurement_start_mono = {0, 0};
int date_format_iso = 1;
const char *fmt_dt  = NULL;
const char *fmt_d   = NULL;
const char *fmt_dl  = NULL;

/* *************************************   end configuration values   ******************************************************* */


#define msg_size 3072
#define timestamp_size 32
#define log_size 256
#define number_of_mac_loops 20

#define buffer_fail -1
#define buffer_success 0
#define buffer_size_sc 16
#define buffer_size_influx 512
#define dest_influxdb 2
#define dest_sc 1
#define dest_madavi 3
#define dest_mqtt 4

volatile bool transmission_enabled = true;  // transmission takes place only if flag "transmission_enabled" is set to true
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
int main(void) {
  int ret;
  int i;

  setvbuf(stdout, NULL, _IONBF, 0);  /* unbuffered: output visible even on crash */

  process_start_time = time(NULL);
  clock_gettime(CLOCK_MONOTONIC, &process_start_mono);

  if (!(get_config() == EXIT_SUCCESS)) {
    /* Output Error and stop */
    report_and_exit("error reading configuration file: dnms.conf");
  }
  fmt_dt = date_format_iso ? "%Y-%m-%d %H:%M:%S" : "%d.%m.%Y %H:%M:%S";
  fmt_d  = date_format_iso ? "%Y-%m-%d"           : "%d.%m.%Y";
  fmt_dl = date_format_iso ? "%Y-%m-%d,"     : "%d.%m.%Y,";
  printf("\n******************************************************************************************\n");
  printf("Program for Raspberry Pi to transmit noise data from a connected DNMS sensor\n ");
  printf("to Sensor.Community and/or to an influxDB database via HTTP or MQTT\n\n");

  printf("Wait %d seconds for everything to be ready!\n\n", waiting_time_after_start);
  sleep(waiting_time_after_start);  // wait some time, that erverything is settled in OS

  printf("Firmware version Raspberry Pi: %s\n\n", firmware_version);

  /* read mac address from system */
  for (i = 0; i < number_of_mac_loops; i++) {
    if (get_mac((char *)interface_name, (char *)mac_adr) == 0) {
      break;
    } else {
      sleep(1);  // wait some time
      if (i == (number_of_mac_loops - 1)) {
        printf("no Mac address found for given device name!\n");
        exit(0);
      }
    }
  }

  printf("MAC of selected Ethernet device %s is: %.2x:%.2x:%.2x:%.2x:%.2x:%.2x\n", interface_name, mac_adr[0], mac_adr[1], mac_adr[2], mac_adr[3], mac_adr[4], mac_adr[5]);

  /* get and print IP address */
  char ip_address[INET_ADDRSTRLEN] = {0};
  if (get_ip((char *)interface_name, ip_address) == 0) {
    printf("IP address of %s: %s\n", interface_name, ip_address);
  } else {
    printf("No IP address found for %s\n", interface_name);
  }

  bzero((char *)&mac_strg, sizeof(mac_strg));
  for (i = 0; i < 6; i++) {
    sprintf(value_2_string, "%.2x", mac_adr[i]);
    strcat(mac_strg, value_2_string);
  }
  mac_strg[12] = '\0';
 
  /* long or short ID ?  */ 
  if(long_id) {  
	  /* long ID is generated from all six bytes of MAC as integer */
	  printf("long raspi_id is configured\n");
	  zw = (mac_adr[0] << 16) + (mac_adr[1] << 8);
	  raspi_id = (zw) << 24;
	  zw = (mac_adr[2] << 24) + (mac_adr[3] << 16) + (mac_adr[4] << 8) + mac_adr[5];
	  raspi_id = raspi_id + zw;
  } else {
	  raspi_id = (mac_adr[3] << 16) + (mac_adr[4] << 8) + mac_adr[5];
  }
    sprintbig(raspi_id_strg, raspi_id);
    /* Prepare message header for influxDB transmission */
    prep_msg_header_influxdb();

  /* Prepare message header and fixed part of data for Sensor.community transmission */
  prep_msg_header_sc();
  prep_data_sc();

  /* check if to start 1st measurement interval */
  /* it will be set active if transmission to Sensor.Community is set or 
		 * Transmission of 1st measurement to influxdb is set */
  if ((data_transmit_laeq_to_sc || data_transmit_laeq_1st_to_influxdb || data_transmit_lzeq_1st_to_influxdb || data_transmit_laeq_1st_spectrum_to_influxdb
       || data_transmit_lzeq_1st_spectrum_to_influxdb || data_laeq_1st_output_on_terminal || data_la_spec_1st_output_on_terminal || data_lzeq_1st_output_on_terminal || data_lz_spec_1st_output_on_terminal || data_transmit_lceq_1st_to_influxdb || data_transmit_lceq_1st_spectrum_to_influxdb || data_lceq_1st_output_on_terminal || data_lc_spec_1st_output_on_terminal
       || data_transmit_laeq_1st_to_mqtt || data_transmit_lzeq_1st_to_mqtt || data_transmit_lceq_1st_to_mqtt || data_transmit_laeq_1st_spectrum_to_mqtt || data_transmit_lzeq_1st_spectrum_to_mqtt || data_transmit_lceq_1st_spectrum_to_mqtt) && enable_1st_interval) {
    interval_1st_active = true;
  }

  /* check if to start 2nd measurement interval */
  if ((data_transmit_laeq_2nd_to_influxdb || data_transmit_lzeq_2nd_to_influxdb || data_transmit_laeq_2nd_spectrum_to_influxdb
       || data_transmit_lzeq_2nd_spectrum_to_influxdb || data_laeq_2nd_output_on_terminal || data_la_spec_2nd_output_on_terminal
       || data_lzeq_2nd_output_on_terminal || data_lz_spec_2nd_output_on_terminal || data_transmit_lceq_2nd_to_influxdb || data_transmit_lceq_2nd_spectrum_to_influxdb || data_lceq_2nd_output_on_terminal || data_lc_spec_2nd_output_on_terminal
       || data_transmit_laeq_2nd_to_mqtt || data_transmit_lzeq_2nd_to_mqtt || data_transmit_lceq_2nd_to_mqtt || data_transmit_laeq_2nd_spectrum_to_mqtt || data_transmit_lzeq_2nd_spectrum_to_mqtt || data_transmit_lceq_2nd_spectrum_to_mqtt) && enable_2nd_interval) {
    interval_2nd_active = true;
  }

   /* shall WiFi signal strength be transmitted to SC/InfluxDB/MQTT ?? */
   if (enable_wifi_signal_strength_influxdb || enable_wifi_signal_strength_mqtt || data_transmit_laeq_to_madavi) {
   		printf("Transmission of WiFi signal strength is configured.\n");
		if (open_socket_to_get_signal_strength() < 0) {
			perror("Error open socket to get WiFi signal");
		}
		for (i = 0; i  < 20; i++) {
			usleep(50000);
			wifi_signal_strength=get_signal_strength();
			if (wifi_signal_strength == -299) {
				perror("Error open socket to get WiFi signal");	
			}
			if (wifi_signal_strength > -80) {
				printf("WiFi signal stgrength: %d\n\n", wifi_signal_strength);
				break;
			}
		}
   }

  /*  setup DNMS   */
  sleep(1);
  open_dnms();

  sleep(1);
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

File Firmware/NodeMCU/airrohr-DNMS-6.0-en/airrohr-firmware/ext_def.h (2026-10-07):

// Language config
#define CURRENT_LANG INTL_LANG

// Wifi config
//const char WLANSSID[] PROGMEM = "Freifunk-disabled";
const char WLANSSID[] PROGMEM = "Freifunk";
const char WLANPWD[] PROGMEM = "";
#define WITH_WLANPWD false

// BasicAuth config
const char WWW_USERNAME[] PROGMEM = "admin";
const char WWW_PASSWORD[] PROGMEM = "";
#define WWW_BASICAUTH_ENABLED 0

#define START_ON_FULL_MINUTE false
#define START_ON_FULL_HOUR false
#define SENSOR_CYCLIC_RESTART false

// Sensor Wifi config (config mode)
#define FS_SSID ""
#define FS_PWD "airrohrcfg"

// Where to send the data?
#define SEND2SENSORCOMMUNITY 0
#define SSL_SENSORCOMMUNITY 0
#define SEND2MADAVI 0
#define SSL_MADAVI 0
#define SEND2SENSEMAP 0
#define SEND2FSAPP 0
#define SSL_FSAPP 0
#define SEND2AIRCMS 0
#define SEND2MQTT 0
#define SEND2INFLUX 0
#define SEND2LORA 0
#define SEND2CSV 0
#define SEND2CUSTOM 0
#define SEND2MQTT 0

// OpenSenseMap
#define SENSEBOXID ""

enum LoggerEntry {
    LoggerSensorCommunity,
    LoggerMadavi,
    LoggerSensemap,
    LoggerFSapp,
    Loggeraircms,
    LoggerInflux,
    LoggerCustom,
    LoggerCount,
    LoggerMQTT
};

struct LoggerConfig {
    uint16_t destport;
    uint16_t errors;
#if defined(ESP8266)
    BearSSL::Session* session;
#else
    void* session;
#endif
};

// IMPORTANT: NO MORE CHANGES TO VARIABLE NAMES NEEDED FOR EXTERNAL APIS
static const char HOST_MADAVI[] PROGMEM = "api-rrd.madavi.de";
static const char URL_MADAVI[] PROGMEM = "/data.php";
#define PORT_MADAVI 80

static const char HOST_SENSORCOMMUNITY[] PROGMEM = "api.sensor.community";
static const char URL_SENSORCOMMUNITY[] PROGMEM = "/v1/push-sensor-data/";
#define PORT_SENSORCOMMUNITY 80

static const char HOST_SENSEMAP[] PROGMEM = "ingress.opensensemap.org";
static const char URL_SENSEMAP[] PROGMEM = "/boxes/{v}/data?luftdaten=1";
#define PORT_SENSEMAP 443

static const char HOST_FSAPP[] PROGMEM = "server.chillibits.com";
static const char URL_FSAPP[] PROGMEM = "/data.php";
#define PORT_FSAPP 80

static const char HOST_AIRCMS[] PROGMEM = "doiot.ru";
static const char URL_AIRCMS[] PROGMEM = "/php/sensors.php?h=";
// As of 2019/09 uses invalid certificates on ssl/port 443 and does not support Maximum Fragment Length Negotiation (MFLN)
// So we can not use SSL
#define PORT_AIRCMS 80

static const char FW_DOWNLOAD_HOST[] PROGMEM = "firmware.sensor.community";
#define FW_DOWNLOAD_PORT 443

static const char FW_2ND_LOADER_URL[] PROGMEM = OTA_BASENAME "/loader-002.bin";

static const char NTP_SERVER_1[] PROGMEM = "0.pool.ntp.org";
static const char NTP_SERVER_2[] PROGMEM = "1.pool.ntp.org";

// define own API
static const char HOST_CUSTOM[] PROGMEM = "192.168.234.1";
static const char URL_CUSTOM[] PROGMEM = "/data.php";
#define PORT_CUSTOM 80
#define USER_CUSTOM ""
#define PWD_CUSTOM ""
#define SSL_CUSTOM 0

// define own InfluxDB
static const char HOST_INFLUX[] PROGMEM = "influx.server";
static const char URL_INFLUX[] PROGMEM = "/write?db=my InfluxDB";
#define PORT_INFLUX 8086
#define USER_INFLUX ""
#define PWD_INFLUX ""
static const char MEASUREMENT_NAME_INFLUX[] PROGMEM = "dnms";
#define SSL_INFLUX 0

// define values for MQTT Broker
static const char HOST_MQTT[] PROGMEM = "mqtt.broker";
static const char MEASUREMENT_NAME_MQTT[] PROGMEM = "dnms";
#define PORT_MQTT 1883
#define USER_MQTT ""
#define PWD_MQTT ""
#define TLS_MQTT 0
#define ID_AS_MQTT_SUB_TOPIC 1
#define MQTT_KEEP_ALIVE 60
// 3 weightings × (3 scalars + 31 spectrum bands) = 102 fields × ~30 chars + header ≈ 3120 bytes (2nd interval)
#define MQTT_BUFFER_SIZE 4096

//  === pin assignments for NodeMCU V2 board ===================================
#if defined(ESP8266)
// define pin for one wire sensors
#define ONEWIRE_PIN D7

// define serial interface pins for particle sensors
// Serial confusion: These definitions are based on SoftSerial
// TX (transmitting) pin on one side goes to RX (receiving) pin on other side
// SoftSerial RX PIN is D1 and goes to SDS TX
// SoftSerial TX PIN is D2 and goes to SDS RX
#define PM_SERIAL_RX D1
#define PM_SERIAL_TX D2

// define pins for I2C
#define I2C_PIN_SCL D4
#define I2C_PIN_SDA D3

// define serial interface pins for GPS modules
#define GPS_SERIAL_RX D5
#define GPS_SERIAL_TX D6

// define serial interface pins for Next PM Sensor
#define NPM_SERIAL_RX D1
#define NPM_SERIAL_TX D2

// define serial interface pins for IPS7100 Sensor
#define IPS_SERIAL_RX D1
#define IPS_SERIAL_TX D2

// PPD42NS, the cheaper version of the particle sensor
#define PPD_PIN_PM1 GPS_SERIAL_TX
#define PPD_PIN_PM2 GPS_SERIAL_RX
#endif


//  === pin assignments for Arduino SAMD Zero board ===================================
#if defined(ARDUINO_SAMD_ZERO)
#define ONEWIRE_PIN D7
#define PPD_PIN_PM1 GPS_SERIAL_TX
#define PPD_PIN_PM2 GPS_SERIAL_RX
#if defined(SERIAL_PORT_USBVIRTUAL)
#define RFM69_CS 8
#define RFM69_RST 4
#define RFM69_INT 3
#endif
#endif
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

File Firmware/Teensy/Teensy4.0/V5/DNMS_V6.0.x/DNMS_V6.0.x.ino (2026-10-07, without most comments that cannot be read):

/************************************************************************
* DNMS - Digital Noise Measurement Sensor
*
* Board : Teensy 4.0 (ARM Cortex-M7 @ 600 MHz)
* Input : I2S from ICS-43434 or IM72D128 microphone
* Output : I2C slave to external controller (NodeMCU or Raspberry Pi Zero 2W and above)
*
* Copyright (C) 2021-2026 Helmut Bitter
* Copyright (C) 2021-2026 Burkhard Volkemer (FFT parts)
* GNU GPL v3 or later
************************************************************************/
/* 
Memory Usage on Teensy 4.0:
  FLASH: code:74288, data:67528, headers:8708   free for files:1881092
   RAM1: variables:238752, code:72104, padding:26200   free for local variables:187232
   RAM2: variables:16064  free for malloc/new:508224
*/

#include <Arduino.h>
#include <math.h>
#include <Audio.h>
#include <dnms_audio_lib.h>
#include <i2c_driver.h>
#include <i2c_driver_wire.h>

#include "DNMS_def.h"
#include "FIR_decimation_filter.h"
#include "Micro_calib_data.h"   // replaces the four large per-bin correction headers
#include "A_weighting.h"
#include "C_weighting.h"

// ── firmware versionstring ─────────────────────────────────────────────────────
static const char SOFTWARE_VERSION[] = "DNMS Version 6.0.x ";

// ── Timing ────────────────────────────────────────────────────────────
static const uint32_t BLINK_PERIOD_ICS43434 = 100u;
static const uint32_t BLINK_PERIOD_IM72D128 = 500u;
static const uint32_t BLINK_PERIOD_MICRO3   = 200u;
static const uint32_t BLINK_PERIOD_MICRO4   = 1000u;

// ── FFT-Configuration ─────────────────────────────────────────────────
static const uint8_t NUMBER_OF_FFTS = 1u;
static const uint8_t FFT_CALCULATIONS_IN_START_PHASE = 44u;
static const uint8_t BLK_LEN = 128u;
static const uint8_t DECI_FACTOR = 32u;
static const double WINDOW_HANNING = 0.3750;

// ── I2C-Configuration ─────────────────────────────────────────────────
static const uint8_t DNMS_I2C_ADDRESS = 0x55u;
static const uint8_t DNMS_WORD_SIZE = 2u;
static const uint8_t CRC8_POLYNOMIAL = 0x31u;
static const uint8_t CRC8_INIT_VAL = 0xFFu;
static const uint8_t I2C_BUF_SIZE = 64u;

// ── Microphone-constants ──────────────────────────────────────
static const double MICRO_CONST_ICS43434 = 123.0102999565;
static const double MICRO_CONST_IM72D128 = 133.0102999565;

// ── Debug-Pins ────────────────────────────────────────────────────────
#define DNMS_DEBUG

static const uint8_t PIN_FFT4096 = 1u;
static const uint8_t PIN_FFT1024 = 3u;
static const uint8_t PIN_I2C_1ST = 5u;
static const uint8_t PIN_I2C_2ND = 7u;

#ifdef DNMS_DEBUG
#define DBG_HIGH(p) digitalWrite((p), HIGH)
#define DBG_LOW(p) digitalWrite((p), LOW)
#else
#define DBG_HIGH(p) ((void)0)
#define DBG_LOW(p) ((void)0)
#endif

// Frequency used for bin 0 (DC) in the calibration interpolation.
// DC has no physical frequency, so we use the first calibration point's
// frequency to avoid log(0) and to apply a sensible low-frequency value.
static constexpr float pts_guard = 1.0f;  // 1 Hz placeholder for bin 0

// ── Mathematische Hilfskonstanten ─────────────────────────────────────
static const double LN10_DIV_10 = 0.23025850929940456840;
static const double TEN_OVER_LN10 = 4.342944819032518;

static inline double delog(double x) {
  return exp(x * LN10_DIV_10);
}
static inline double ten_log10(double x) {
  return TEN_OVER_LN10 * log(x);
}
static inline uint16_t swap16(uint16_t s) {
  return static_cast<uint16_t>((s << 8u) | (s >> 8u));
}

// ── Band-Größen als enum – verhindert Doppeldefinition ────────────────
// FIX: Ursprünglich war BAND4096_COUNT und BAND1024_COUNT zweimal als
// static const uint8_t definiert (einmal ganz oben für die Struct,
// einmal weiter unten), was einen "redefinition"-Fehler ergab.
// Lösung: Ein einziger anonymer enum ersetzt beide Vorkommen.
enum : uint8_t {
  BAND4096_COUNT = 32u,
  BAND1024_COUNT = 18u
};

// ─────────────────────────────────────────────────────────────────────
// LeqInterval
// Enthält alle Akkumulatoren und Snapshot-Werte für eine Messperiode.
// FIX: Struct nur EINMAL definiert (vorher war sie doppelt vorhanden).
// Enum-Konstanten oben machen die Inline-Initialisierung möglich.
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

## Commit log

2019-10-24 PCBs eingefügt
    [Airrohr_pcb Teileliste.ods, Airrohr_pcb Teileliste.xlsx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]
2019-12-09 Änderung der Formatierung
2019-12-10 new PCBs
    [Airrohr_pcb Teileliste.ods, Airrohr_pcb Teileliste.xlsx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]
2019-12-10 ersetzt durch V1.1.0 und V1.1.1
2019-12-10 Ergänzung der Beschreibung
2020-03-05 Ergänzung Teensy 4.0
2020-05-03 1. Version Firmware für Teensy 4.0 eingefügt
2020-05-08 Austausch DNMS-T3.6-V1.2-Gerber.zip
2020-08-26 Neue PCBs
    [Airrohr_pcb Teileliste.ods, Airrohr_pcb Teileliste.xlsx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]
2020-08-28 Änderungen im Bestückungsdruck/change of silkscreen
    [Airrohr_pcb-B_Cu.gbr, Airrohr_pcb-B_Mask.gbr, Airrohr_pcb-B_Paste.gbr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]
2020-09-04 spelling changes
    [DNMS.sch]
2020-09-20 Text changes
    [Airrohr_pcb-B_Cu.gbr, Airrohr_pcb-B_Mask.gbr, Airrohr_pcb-B_Paste.gbr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]
2020-10-04 Neues Manual (V2.0) und Stücklisten eingefügt
    [Airrohr-PCB-V1.4-BOM.xlsx, DNMS-T4.0+NodeMCU-V1.4-BOM.xlsx, DNMS-T4.0-V1.4-BOM.xlsx]
2021-01-29 Textänderung
    [Airrohr_pcb-B_Cu.gbr, Airrohr_pcb-B_Mask.gbr, Airrohr_pcb-B_Paste.gbr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]
2021-01-31 New DNMS-T4.0+NodeMCU-V1.5
    [B5B-ZR.STEP, DNMS Teileliste.ods, DNMS Teileliste.xlsx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]
2021-01-31 Änderung von Namen
    [DNMS Teileliste.ods, DNMS Teileliste.xlsx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]
2021-09-08 Beta firmware 2.1.4 and 2.1.5 to fix I²C communication problem
    [DNMS_V2.1.5.ino]
2021-09-08 ICS-43434 microphone PCB - small round board
    [Airrohr-PCB-V1.4-BOM.xlsx, Airrohr-PCB-V1.5-BOM.xlsx, Airrohr_pcb Teileliste.ods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]
2021-09-10 Airrohr-ESP32_V1.1 added
    [Airrohr-ESP32-PCB-V1.1-BOM.xlsx, Airrohr-PCB-V1.5-BOM.xlsx, Airrohr-PCB-V1.6-BOM.xlsx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]
2021-09-10 DNMS-RPI-HAT added
    [DNMS-RPI-HAT-V1.0-BOM.xlsx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]
2023-01-24 New versions
    [10sets-ICS-43434-PCB-V1.4-BOM.xls, BM06B-SRSS-TB_LF__SN_.stl, BM06B-SRSS-TB_LF__SN_.stp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]
2023-07-20 New SW vversions, new microphone supported
    [ADAU7002ACBZ-R7.stp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]
2023-08-20 New Test Programms
    [Airrohr-ESP32-PCB-V1.1-BOM.xlsx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]
2024-02-21 new firmware
    [DNMS-B_Cu.gbr, DNMS-B_Mask.gbr, DNMS-B_Paste.gbr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]
2024-03-20 Change in install file and README.md for Raspberry Pi
2024-04-15 New bug fix firmware NRZ-2020-134-DNMS-5.6 for NodeMCU
    [defines.h, dnms_i2c.cpp, ext_def.h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]
2024-06-01 New firmware for Teensy4.0, NodeMCU and new Raspberry Pi version
2024-06-29 corretion of Raspberry Pi firmware
2024-07-07 New Raspberry Pi version (0.9.18)
2024-07-28 New firmware Teensy4.0 and NodeMCU
2024-09-07 update Raspberry firmware
2024-09-16 Raspberry Pi dnms-0.9.21 new version
2025-05-25 New test programs for Teensy4.0 and microphones
2026-05-17 New Teensy4.0 firmware
2026-05-18 New Teensy 4.0 firmware
2026-05-18 New Raspberry Pi firmware
2026-05-18 New Teensy 4.0 DNMS-T4.0-V1.8S Board
    [BOM-1-DNMS-T4.0-V1.8S.xlsx, BOM-2-DNMS-T4.0-V1.8S.xlsx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]

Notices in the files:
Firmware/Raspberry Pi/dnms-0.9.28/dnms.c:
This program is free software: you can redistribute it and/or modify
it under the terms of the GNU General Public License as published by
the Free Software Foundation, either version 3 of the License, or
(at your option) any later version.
